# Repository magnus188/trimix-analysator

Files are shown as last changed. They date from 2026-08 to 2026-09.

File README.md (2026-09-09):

# Trimix Analyzer ESP32 Firmware

ESP32-P4/LVGL firmware for the Trimix Analyzer on the native-portrait Guition JC4880P443C_I_W (JC-ESP32P4-M3). It includes Wi-Fi, revision-specific HTTPS OTA, persistent settings/calibration, hardware sensor and power drivers, and a separate deterministic simulator. Physical firmware reports unavailable hardware instead of substituting simulated gas or battery readings.

**Prototype order status: HOLD.** Follow the [whole-system review](hardware/system-review/README.md) for current evidence and unresolved interfaces. No physical charging, thermal, sealing or reference-gas qualification has been completed. The accuracy targets of ±0.2 percentage points O2 and ±0.5 points He remain unproven. Charging is deliberately inhibited and J104 stays open until the cell, protection and temperature-sensing requirements are qualified.

## Project layout

The repository root is the main software workspace: firmware lives in `main/`,
with host tests in `tests/`, simulator support in `simulator/` and development
tools in `scripts/`. Mechanical and electronics files are grouped under the
[hardware overview](hardware/README.md): Fusion CAD is in `hardware/cad/`,
KiCad PCB projects are in `hardware/pcb/`, and Bambu Studio projects are in
`hardware/cad/rev04/3d-print/printing/bambu-studio/`.

## Quick Start with ESP-IDF

### Prerequisites
- [ESP-IDF v5.5.4](https://github.com/espressif/esp-idf/releases/tag/v5.5.4); `make setup-idf` installs the pinned environment
- Python 3.13
- Guition JC4880P443C_I_W: ESP32-P4 rev v1.3, 16 MB flash, 32 MB PSRAM, and ESP32-C6 coprocessor
- `g++`, CMake, pkg-config, and SDL2 development headers for full host validation

### Build and Upload
```bash
# See all common development commands
make help

# Run host-side validation
make test

# Install/check the exact ESP-IDF toolchain
make setup-idf
make doctor

# Identify whether the attached P4 is pre-v3 or v3+
make board-info PORT=/dev/cu.usbserial-110

# Build and flash; the port is required so the revision can be verified safely
make push PORT=/dev/cu.usbserial-110

# Build, flash, and monitor serial output
make push-monitor PORT=/dev/cu.usbserial-110

# Build and run the LVGL/SDL desktop simulator
make sim ZOOM=0.75
```

The first ESP32-P4 installation must be flashed over USB. An ESP32-S3 cannot
install this firmware through OTA because the chips and images are incompatible.

Run `make devices` to find likely serial ports. Firmware commands always source the pinned ESP-IDF v5.5.4 installation under `~/esp/v5.5.4/esp-idf`; an unrelated `idf.py` in `PATH` is never used. Override the installation location with `ESP_IDF_DIR=/path/to/esp-idf`.

The equivalent raw ESP-IDF commands remain available:

```bash
idf.py -B build/esp32p4-pre3 -D SDKCONFIG_DEFAULTS="sdkconfig.defaults;sdkconfig.defaults.esp32p4;sdkconfig.defaults.esp32p4.pre3" set-target esp32p4
idf.py -B build/esp32p4-pre3 build
idf.py -B build/esp32p4-pre3 -p /dev/cu.usbserial-110 flash monitor
```

## Browser Demo

The production LVGL interface can also run in a browser through WebAssembly. The browser build uses the same screens, calculator logic, and deterministic simulator services as the native SDL simulator; hardware sensors, WiFi, battery state, NVS, and OTA installation remain simulated.

### Build locally

Activate an [Emscripten SDK](https://emscripten.org/docs/getting_started/downloads.html), then run:

```bash
bash scripts/build_web_demo.sh
python3 -m http.server 8080 --directory web/build
```

Open `http://localhost:8080`. The generated site must be served over HTTP rather than opened directly from disk so the browser can load its WebAssembly module.

### Automatic GitHub Pages deployment

`.github/workflows/pages.yml` builds and deploys the demo after every push to `main`, and can also be run manually. Before the first deployment, select **GitHub Actions** under **Repository settings → Pages → Build and deployment → Source**. The project site will then be available at `https://magnus188.github.io/trimix-analysator/`.

### ESP-IDF Project Structure
```
├── CMakeLists.txt           # Main CMake configuration
├── sdkconfig.defaults       # ESP-IDF configuration defaults
├── main/                    # Main component source files
│   ├── main.cpp            # Application entry point and service startup
│   ├── services/           # WiFi, OTA, settings, battery, backlight
│   ├── sensors/            # Sensor abstraction and mock readings
│   ├── ui/                 # LVGL port, screens, styles, components
│   ├── idf_component.yml  # Component dependencies
│   └── CMakeLists.txt     # Component CMake file
├── tests/                  # Host-side C++ tests
├── scripts/                # Test and firmware size scripts
└── README.md               # This file
```

## Hardware Requirements

Use the [current electrical design](hardware/ANALYZER_DESIGN.md), [part qualification ledger](hardware/system-review/electrical/part-qualification.csv) and [main-board delivery index](hardware/system-review/electrical/main-final/README.md). These are prototype review files, not purchasing approval. Earlier enclosure/PCB snapshots preserve historical component choices.

### Controller and Display
- **ESP32-P4NRW32** application processor with 32 MB in-package PSRAM. Original pre-v3 boards are configured for their detected 16 MB flash; the v3 profile retains the 32 MB layout used by newer hardware.
- Onboard **ESP32-C6** WiFi 6/BLE coprocessor connected over SDIO.
- Native **480x800 MIPI-DSI IPS display** with ST7701 controller and GT911 capacitive touch.

### Power, Charging, and Battery
- **GCT USB4720-03-A** on a separate thin USB board, with TUSB320LAI CC detection and PI3USB9201 BC1.2 detection on the main board. USB-A-to-C and C-to-C behaviour remains subject to the documented source-current and startup tests.
- **BQ25895RTWR** 1S power-path charger, with TPS259470 overvoltage protection and TPS22950-Q1 input limiting. No USB-PD or high-voltage negotiation is provided; charging remains inhibited during commissioning.
- **Protected FMA FPML1S2P050C holder**, using its protected output. Holder/protection ratings, cell identity and NTC mounting require qualification.
- **TPS63020** configured for 5 V, with LM66100 host reverse isolation. Guition JP1 power entry remains a separate unresolved interface; do not power it through an unqualified harness.
- **TPS7A2030** regulated 3.0 V supply for the MD62.
- **LTC2954** hardware push-button shutdown plus firmware-managed normal shutdown.
- **MAX17048** 1S I2C fuel gauge.
- **2x 18650 cells in 1S2P**, owner-stated 3400 mAh each; no validated cell charge limits are inferred from capacity.
- **Normally-open momentary power button**; its final mechanical part and sealing remain unqualified.

### Sensors and Analog Front End
- Two **ADS122C04IPWR** 24-bit ADCs in TSSOP-16: U401 oxygen at 0x40 and U502 helium at 0x41. Initial profiles use 20 samples/s and the internal 2.048 V reference.
- Actual **BME280** breakout for humidity, temperature and pressure. A BMP280 cannot provide humidity.
- Retained **MD62 thermal-conductivity sensor** on regulated 3.0 V, with fixed matched bridge reference. Its helium response and compensation must be characterized with reference mixtures.
- **AO2 or R17JJ-CCR**, one installed oxygen sensor at a time. J401 and J402 have separate differential inputs; touchscreen selection and calibration identities persist independently.
- **ZE07-CO experimental module**, measuring CO rather than CO2. It is not a breathing-gas safety certification device. Its manufacturer excludes applications involving human safety; see the [CO review and manual](hardware/system-review/electrical/co-module-use-review.md). No undocumented recalibration commands are enabled. Fresh, valid chamber conditions and module warm-up are required before its reading is displayed.

### Wiring Notes
```
Signal/Rail       | Current hardware expectation
------------------|------------------------------------------------
External I2C      | GPIO28 SDA / GPIO29 SCL; managed 100 kHz sensor/power bus
Analog gas inputs | AO2/JJ differential paths and MD62 bridge into ADS122C04
HOST_3V3          | Supplied by Guition; external load margin remains unqualified
3.0 V rail        | MD62 through TPS7A2030; measure voltage at actual sensor leads
USB-C VBUS        | Protected/limited 5 V path to BQ25895
Display I2C       | GPIO7 SDA / GPIO8 SCL; separate touch/audio board bus
Onboard SD        | Slot 0: CLK43 CMD44 D0-3=39-42; LDO4 card supply
C6 SDIO           | Slot 1: CLK18 CMD19 D0-3=14-17; shared-controller arbitration
```

The [electrical/firmware/harness contract](hardware/system-review/electrical/interface-contract.md) defines logical contact mapping. The [owner photo and mechanical registration](hardware/system-review/integration-photo/README.md) place the Guition header and both USB sockets at the top and SD access on the left. Mated connector heights, cable routes and service access need their own clearance evidence. Display pins, timings and the ST7701S initialization table live in `main/board/`.

## Software Architecture

### Key Components

#### 1. Main Application (`main/main.cpp`)
- Persistent service startup
- Native display and screen initialization under the LVGL adapter lock
- Background service startup after the UI is ready

#### 2. LVGL Port (`main/ui/lvgl/lvgl_port.cpp`)
- Guition MIPI-DSI/ST7701S manual startup sequence
- Native GT911 touch registration
- Triple-buffered tear avoidance and LVGL adapter locking

#### 3. Sensor Interface (`main/sensors/sensor_interface.cpp/h`)
- Abstracted sensor reading functions
- Separate physical acquisition and deterministic simulator backends
- Persistent sensor selection and versioned calibration; stale, clipped and faulty samples are rejected

#### 4. Screen Management (`main/ui/screens/screen_manager.cpp/h`)
- LVGL-based UI screens
- Navigation between screens
- Settings, WiFi, update, and dive planner screens

#### 5. Services (`main/services/`)
- WiFi scanning/connection and saved credentials
- OTA update checks and firmware installation
- Settings, battery status, and backlight control
- Analysis history, persistent cylinder profiles, and export-ready gas label payloads

#### 6. Board Support
- In-tree Guition JC4880P443 display, backlight, and touch layer
- Separate pre-v3 and v3+ ESP32-P4 build profiles
- Native backlight, display, touch, and onboard ESP32-C6 integration

## Display Configuration

### ESP32-P4 Display
- **Panel**: 480x800 native portrait
- **Framework**: LVGL
- **Touch**: Capacitive (GT911)

### Screens

1. **Home Screen**
   - Main menu with navigation buttons
   - System status display
   - Version information

2. **Analyse Screen**
   - Gas analysis panel with physical and separately identified simulator sources
   - O2, He, experimental CO, environmental readings, stability, trend chart, planned depth, MOD, density, gas-use mode and averaged capture controls
   - Captures require stable samples and save an averaged analysis result to history
   - Stable averaged readings can update the selected cylinder profile and prepare an export-ready label payload

3. **Dive Planner Screen**
   - Gas planning calculator views
   - Partial-pressure top-up calculator for O2, helium, and air additions
   - Production calculator logic covered by host tests

4. **History Screen**
   - Captured analysis records with gas-use mode, mix fractions, CO, planned depth, MOD, density and advisory state; legacy CO2 fields remain distinct and are not relabelled as CO

5. **Cylinder Profiles Screen**
   - Persistent cylinder slots with selected cylinder, recheck state, stored mix, gas-use mode, planned depth, and label preview
   - Label text and CSV payloads are generated in firmware so later WiFi, QR, BLE, or phone handoff export can reuse the same data model

6. **Settings Screen**
   - Device settings navigation
   - Cylinder profiles, WiFi, software update, safety settings, calibration, and device information entrypoints

7. **WiFi Screen**
   - Network scanning, connection, password modal, and disconnect controls

8. **Software Update Screen**
   - GitHub release check and OTA install flow

9. **Calibrate Sensors Screen**
   - Guided known-gas oxygen and helium calibration with stability/fault checks and separate AO2/JJ/He records; failed saves retain the previous calibration

10. **Safety Settings Screen**
   - User-configured PPO2, density, and CO2 advisory limits used by Analyse

11. **Device Screen**
   - Device information and configuration controls

## Building and Flashing

### Prerequisites
- **ESP-IDF v5.5.4** installed with `make setup-idf`
- **ESP32-P4** toolchain and Python 3.13
- **Host validation tools**: `g++`, CMake, pkg-config, SDL2 development headers
- USB-C cable for programming

### Build Steps
```bash
# Inspect the attached chip and select the safe image family
make board-info PORT=/dev/cu.usbserial-110

# Run host tests
./scripts/run_tests.sh

# Build both incompatible P4 revision profiles
make build-all

# Validate firmware size against partitions.csv
make size-check P4_REV=pre3
make size-check P4_REV=v3

# Flash to device
make push PORT=/dev/cu.usbserial-110

# Monitor output
make monitor PORT=/dev/cu.usbserial-110
```

### Dependencies
The project uses ESP-IDF component manager for dependencies (defined in `main/idf_component.yml`):
- `lvgl/lvgl` 9.4.0 - Graphics library
- `espressif/esp_lcd_touch_gt911` 1.2.x - capacitive touch controller
- `espressif/esp_lvgl_adapter` 0.1.4 - task, input, and tear-safe display integration
- `espressif/esp_wifi_remote` 1.6.0 and `espressif/esp_hosted` 2.12.9 - onboard C6 networking

Dependencies are automatically downloaded during the build process.

## Sensor Hardware and Calibration Status

Physical firmware implements ADS122C04 acquisition, environmental and power monitoring, sensor selection and calibration persistence. Host tests exercise faults and state transitions; they do not establish actual sensor performance, wiring or charging behaviour. The simulator remains explicitly identified and does not substitute readings in physical firmware.

AO2, JJ-CCR and helium have separate records. Replacing a sensor requires calibration. Helium corrections must come from measured reference mixtures and held-out validation, including environmental and oxygen cross-effects. Historical/simulated CO2 fields remain distinct; this build has no installed CO2 measurement module. See the [software review](hardware/system-review/software/README.md).

## Performance Characteristics

### Display Pipeline
- **Panel**: native 480x800 RGB565 over two-lane MIPI-DSI
- **Tear avoidance**: three full panel framebuffers with partial LVGL rendering
- **LVGL refresh period**: 15 ms
- **Rotation**: none; pixels and touch coordinates stay in native portrait orientation

### Power Consumption
Whole-device active, idle, charging and hardware-off consumption remains unmeasured. Qualify backlight, radio, SD writes, heaters, converters and cable losses together; a display-only typical value is not a system budget. See the [bench equipment and test plan](hardware/system-review/lab-equipment.md).

## Differences from Original

### Enhanced Features
1. **480x800 portrait touch display**
2. **Capacitive touch**
3. **Tear-safe MIPI-DSI output** with no full-frame software rotation
4. **Software-defined sensor selection and calibration**
5. **Versioned OTA and persistent storage**; boot-time and power comparisons remain unmeasured

### Current Limitations
1. Physical fit, source protection, cell charging, thermal behaviour and gas accuracy remain unqualified; PCB order readiness is on hold.
2. Simulator streams support repeatable UI/logic tests; they are not physical measurement evidence.
3. Settings, calibration and recent history remain in NVS. [Optional onboard SD logging](hardware/system-review/software/sd-card/README.md) automatically records analysis/calibration sessions, raw samples and events. Device Settings provides status, safe eject and retry. Digital tests pass; actual card operation, power loss and simultaneous Wi-Fi use remain untested. Absent or faulty media leaves local analysis available.

## Development Notes

### Code Organization
- Sensor interface abstraction allows host tests and later hardware drivers.
- Modular screen design keeps LVGL screens separated by workflow.
- Services isolate WiFi, OTA, settings, battery, and backlight behavior.
- Board-level display and touch details are implemented in `main/board/guition_jc4880p443.c`.

### Testing Strategy
- `./scripts/run_tests.sh` runs static safety checks, production gas calculator tests, version consistency tests, and the host LVGL simulator smoke test when SDL2 is available.
- `./scripts/check_firmware_size.sh` validates the built app binary against the configured factory/OTA app partition.
- Hardware acceptance covers touch corners and drag axes, 100 navigation operations, a one-hour active UI/WiFi soak, an eight-hour idle soak, and two consecutive OTA upgrades.

## Troubleshooting

### Common Issues

1. **Display not working**
   - Verify the qualified 5 V power entry and source-current budget; follow the staged first-power procedure
   - Verify display cable connections
   - Confirm the PCB/module markings read `Guition JC4880P443` / `JC-ESP32P4-M3`
   - Confirm `make board-info` and the selected build profile agree

2. **Touch not responding**
   - Check the GT911 I2C bus on GPIO7 SDA / GPIO8 SCL
   - Confirm the board is physically mounted in native portrait orientation
   - Ensure proper grounding

3. **Sensors not reading**
   - Check I2C bus connections
   - Check device identities and bus errors in firmware diagnostics; use the documented I2C pin/address map
   - Check power supply to sensors

4. **Build errors**
   - Run `make doctor` and confirm ESP-IDF v5.5.4 with Python 3.13
   - Run `make clean`, then rebuild the correct P4 revision profile
   - Check that Git dependencies and `dependencies.lock` are available

### Debug Commands
```bash
# Read firmware diagnostics; no generic I2C-scan console is assumed
idf.py monitor

# Memory usage
idf.py size

# Real-time monitoring
idf.py monitor --decode-crashes
```

## Contributing

When adding new features:
1. Follow ESP-IDF coding standards
2. Keep display/touch changes inside the board-port boundary; do not add manual rotation
3. Add screen navigation in `main/ui/screens/screen_manager.cpp`
4. Test with both real and mock sensors
5. Update documentation

## License

Same as original Trimix Analyzer project.

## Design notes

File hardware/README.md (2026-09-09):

# Trimix hardware

The repository root is the ESP32 software project. Hardware work is grouped by
discipline here so the editable files, previews and print packages are easy to
find.

## Start here

| Area | Main entry point | Contents |
| --- | --- | --- |
| CAD | [cad/](cad/) | Fusion enclosure models, STEP exports, revision notes and image previews |
| 3D printing | [cad/rev04/3d-print/](cad/rev04/3d-print/) | A3 print release, STL files, checks and Bambu Studio projects |
| Bambu Studio | [cad/rev04/3d-print/printing/bambu-studio/](cad/rev04/3d-print/printing/bambu-studio/) | Ready-to-review PLA and PETG `.3mf` projects, grouped by part |
| PCB | [pcb/](pcb/) | Active KiCad projects, PCB integration assets, previews and verification |
| Main PCB | [pcb/analyzer/Trimix_Analyzer.kicad_pro](pcb/analyzer/Trimix_Analyzer.kicad_pro) | Current integrated analyzer schematic and board |
| USB PCB | [pcb/usb-input/Trimix_USB_Input.kicad_pro](pcb/usb-input/Trimix_USB_Input.kicad_pro) | USB input daughterboard |
| System review | [system-review/](system-review/) | Cross-discipline electrical, mechanical and firmware review evidence |

The preserved P1 power design is in
[`pcb/power/Trimix_Power.kicad_pro`](pcb/power/Trimix_Power.kicad_pro). The
obsolete EasyEDA-derived KiCad workspace is intentionally separated under
[`pcb/archive/deprecated-kicad-import/`](pcb/archive/deprecated-kicad-import/)
and should not be used as the current design.

## Supporting material

- [Analyzer design notes](ANALYZER_DESIGN.md)
- [Power design notes](POWER_DESIGN.md)
- [USB charging notes](USB_CHARGING.md)
- [Software calibration notes](SOFTWARE_CALIBRATION.md)
- [KiCad MCP setup](MCP_SETUP.md)

Generated verification records remain beside the work they describe. Preview
folders contain human-viewable images; source models and engineering evidence
stay in their project folders so they are not confused with presentation
exports.

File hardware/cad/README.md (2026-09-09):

# Trimix enclosure CAD

The latest enclosure source is [Revision 04](rev04/), with viewport images in
[`rev04/previews/`](rev04/previews/). The A3 printing package is kept with that
revision under [`rev04/3d-print/`](rev04/3d-print/). Open the prepared PLA or
PETG Bambu Studio projects from
[`rev04/3d-print/printing/bambu-studio/`](rev04/3d-print/printing/bambu-studio/).

The files in this directory below the overview are the earlier Revision 02
concept and remain available for design history.

## Revision 02 notes

**Status: Editable concept built in Fusion.** The official MCP connection was used with Fusion 2705.1.11. The current model has **19 component occurrences** (20 components including the root), **50 solid bodies** and **490 timeline items**. Its [Fusion model audit](verification/model-audit.json) reports healthy features, fully constrained sketches and **zero volumetric interferences** among the modelled component occurrences. Sampled removal checks pass with the sequence below. Physical fit, practical service access, gas sealing and flow performance remain to be validated.

The new Fusion design is saved as **`Trimix_Enclosure_A1 v2`**, in the **Trimix analyzer** Fusion folder. Cloud processing is complete and there are no unsaved changes, as recorded in [cloud-save.json](verification/cloud-save.json). The original `Casing v1` document remains unchanged. The model has millimetre user parameters and named components.

## Files

- [Native Fusion design](Trimix_Enclosure_A1.f3d): editable sketches, features, parameters and component assembly; archive integrity checked.
- [STEP assembly](Trimix_Enclosure_A1.step): neutral geometry with 50 exported solids; no parametric history.
- [Review drawings](Trimix_Enclosure_A1_Review.pdf): two A3 sheets containing actual Fusion front, rear, left, right, section and rear-open views. Both pages visually inspected; not to scale or manufacturing drawings.
- [Measurement checklist](MEASUREMENTS.md): published references and the measurements required for final mounts and seals.
- [View images](previews/): individual Fusion viewport exports. The rear-open view hides the outer cover and internal chamber lid; the centre section is at X = 0.

## Agreed arrangement

- The housing uses a provisional **180 mm height × 95 mm width × 60 mm depth**, with **3 mm walls**. Current side projections increase the complete model's bounding width to **107 mm**. Final dimensions depend on measured components and assembly clearance.
- Model coordinate convention: **X increases toward the viewer's left, Y points up, Z points rearward** when looking at the front. USB is on **+X** and the power button on **−X**. The front is **Z = 0**. The rear cover's nominal 3 mm allocation includes a **0.25 mm seating gap**; its current solid occupies **Z = 57.25–60 mm**, giving **2.75 mm** actual thickness.
- The front contains only the **4.3-inch portrait touchscreen** and its bezel. Use the agreed **69.41 × 117.01 mm** display envelope while confirming the hardware variant.
- The left side carries USB-C and the upper gas inlet. The right side carries the power button and upper gas exhaust. There is no external O₂ socket.
- One rear cover provides access to the battery, electronics and sensor assembly. **Six M3 screw and heat-set insert envelopes** are modelled; final boss bores, hardware selection and engagement lengths follow the chosen insert drawing and fit coupons.
- The upper sampling chamber is an independently enclosed, removable assembly, separated from the battery and electronics. Provide sealed wire feedthroughs and rear-accessible fasteners; final sealing details await component and material measurements.
- The model includes envelopes for the protected FMA two-cell holder and retained battery plug, an electronics carrier, cable-routing space and a supported, replaceable USB daughterboard mounting insert. The button centre is at **Y = 102 mm** to clear the adjacent boss; the USB daughterboard has a connector clearance slot.

## Assembly and service intent

The [service audit](verification/service-audit.json) checks temporary copies at discrete positions; it does not claim a continuous swept-volume or physical fit test. The tested sequence is:

1. Switch off and unplug USB. Remove the six rear screws and single cover, disconnect the RCY/BEC battery plug, release holder retention and withdraw the protected pack rearward.
2. For carrier/display service, disconnect side wiring and release the USB insert and button retainers. Move the USB assembly **3.1 mm inward**, then withdraw it through the rear. The panel button is removed **outward through the right side** after its internal nut and wiring are released; actual terminals must fit the measured hole.
3. Release the carrier screws and harnesses, then withdraw carrier and future PCB rearward. Remove the carrier before withdrawing the display. Keeping the button and USB assemblies installed obstructs these straight rearward paths in the present concept.
4. For chamber service, remove both external gas stubs, disconnect the sensor harness on the electronics side of the feedthrough and release the cartridge screws. The closed chamber, internal lid, seal and sensors then withdraw rearward together. Retained gas stubs obstruct that path.

All final paths were clear at the sampled positions after these prerequisites. A nominal **Ø4 × 50 mm** straight screwdriver shaft cleared the rear cover, carrier, cartridge and internal-lid screw access positions. The actual driver handle, connectors, retainers and cable bends still require physical checks. Wiring volumes reserve space; they do not model flexible harness behaviour.

The sampling path is a vented flow-through arrangement, entering at the upper left and exhausting at the upper right. The ZE07-CO clearance envelope starts at Z = 16 mm, leaving 1.5 mm beyond the top of the nominal 5 mm exhaust bore. A segmented air centreline around the AO2 neck was clear at points spaced no more than 1 mm apart. This does **not** prove a continuous 5 mm flow area, adequate mixing, response time or gas-tight seals. Keep a continuous open gas passage around the sensors and separate sample gas from the electrical compartment. Pressure-retaining tank or BCD adapters are outside this revision.

The external USB-C board supplies charging. Guition's own USB connector remains an internal service connection, accessed with the main power disconnected. The enclosure reserves a **64 × 108 mm** target for the future main PCB. The actual KiCad PCB has not been resized; its oversized placement preview is not the enclosure reference.

## Review before printing

The current solid model passes Fusion's geometry checks, including a static interference analysis with coincident faces excluded. The [parameter test](verification/parameter-regeneration.json) changed CaseWidth from 95 to 97 mm, confirmed healthy regeneration and restored 95 mm. These checks do not establish clearance for unmeasured real parts. Complete the [measurement checklist](MEASUREMENTS.md), then confirm practical rear removal, screwdriver reach, battery disconnection, cable bends and sample flow using the actual hardware.

The first planned print is a **PLA fit prototype for the Bambu H2D**, following review in Fusion. Final material, gas seals, thermal behaviour and weather sealing remain to be qualified. The connector's IP67 rating does not establish a rating for the complete enclosure.

## Editing and repeatable checks

Open the native file in Fusion and use **Modify → Change Parameters** for the provisional case dimensions, wall, display and port positions. Recheck component clearance after every dimensional change; changing the enclosure size does not automatically repack fixed internal envelopes. Named sketch and extrusion features remain available in the timeline. The retained `A-A centre section / X=0 / review only` analysis can be enabled in the browser.

The scripts use Autodesk's official local MCP endpoint at `http://127.0.0.1:27182/mcp`. `fusion_mcp.py` sends an explicitly chosen script into Fusion; it does not replace Fusion's geometry kernel. `fusion_audit.py`, `check_parameters.py` and `service_audit.py` record their results under `verification/`. The parameter check temporarily changes and restores width; the service check uses transient copies only.

`build_enclosure.py` is a staged construction record, not an automatic rebuild-on-open add-in. For a deliberately new design, its stages are `create_design`, `build_shell`, `build_chamber`, `build_hardware`, `refine_fit`, `finish_mechanics`, then `style_model`. Do not replay creation stages into the delivered document. The guarded `correct_front_reference` function records a one-time correction of the earlier build; current construction code already uses the corrected orientation.

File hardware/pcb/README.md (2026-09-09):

# Trimix PCB projects

Open the current designs from this directory:

- [Main analyzer project](analyzer/Trimix_Analyzer.kicad_pro)
- [USB input daughterboard](usb-input/Trimix_USB_Input.kicad_pro)
- [Preserved P1 power project](power/Trimix_Power.kicad_pro)

`integration/` contains the A3 placement, enclosure-fit exports, component
reference maps and their verification records. Project-specific preview source
files are under `analyzer/previews/` and `power/previews/`; rendered schematic
images and PDFs are under `verification/`.

The old EasyEDA migration is not an active design. It is retained only for
traceability in [archive/deprecated-kicad-import/](archive/deprecated-kicad-import/).

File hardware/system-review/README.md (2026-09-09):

# Trimix whole-system review

**Prototype order status: HOLD.** The main PCB is fully routed and its frozen native DRC reports zero violations, unconnected items and schematic-parity issues. This package records the corrections and reproducible digital evidence; it is not a fabrication release. Factory processes, power-entry and protection evidence, and actual component interfaces must close before ordering. Physical charging, temperature, sealing, module-fit and reference-gas tests have not been performed.

The approved A3 exterior and the original PCBFit baseline are preserved. Mechanical review copies are **Trimix_Enclosure_A3_SystemReview** and the newer **Trimix_Enclosure_A3_ConnectorReview**. Purchasing, showcase work and production printing remain paused.

**2026-09-08 integration update:** the owner supplied a rear photograph with device-up confirmed and measured **13.4 mm from front glass to bare header tips**. The photo locates the Guition header and both USB ports at the top and the onboard SD socket at the left. The [photo registration](integration-photo/README.md) and [saved/reopened ConnectorReview v3](mechanical/connector-review/README.md) supersede the old illustrative connector locations. Complete mate allocations expose interference with the housing, carrier and holder; several straight cable plugs also leave inadequate wire-bend space. Local correction candidates are unadopted, and card service remains unqualified. Earlier v11 clearances do not prove fit of these interfaces. [Optional SD logging](software/sd-card/README.md) is implemented and digitally verified, using the onboard socket. The [bench-equipment record](lab-equipment.md) includes the confirmed multimeter, scope, DC PSU, DL24/P, DLA and FNB58.

The current main board is the reviewed `0962ad86` revision. Its charger bootstrap/REGN and CO-converter feedback/output-capacitor paths were shortened, while all 29 previously checked power/monitor paths were preserved. The [scoped power-layout review](electrical/routing-candidate/sensitive-layout-refinement/root-final-review/README.md) and independent manufacturing checks pass. The former routed revision remains archived. Regulator stability, noise, startup and thermal performance still require physical evidence.

The preserved **SystemReview v11 baseline** is saved and its native archive reopens with the same geometry, parameters and assembly associations. It retains the approved 85 × 180 × 43 mm exterior and exact CNC Kitchen insert models. Two carrier through-openings clear the revised rear components with complete local 2 mm material borders. Its selected component, connector, service, gas and fastener allocations pass at 85 and 87 mm widths, with the intended 85 mm design restored. Both oxygen reference configurations pass their bounded checks. See the [v11 checkpoint](mechanical/final-local-checkpoint/final-handoff.json). The later ConnectorReview findings above take precedence for actual Guition mating and cable-space decisions.

Both P4 firmware builds pass, alongside **53 normal and 53 sanitized host tests**, 98 repository checks and 22 static-analysis units. The [current source-bound software receipt](software/sd-card/evidence/receipt.json) includes SD fault/race tests, shared card/C6 controller lifecycle checks and real LVGL navigation regressions. The current schematic/firmware contract passes 70 assertions. CO requires fresh chamber temperature/humidity within its documented range; invalid conditions clear its displayed value while oxygen and helium stay independent. The [CO verification](software/co-environment/README.md) records scoped tests and [manufacturer use restrictions](electrical/co-module-use-review.md). The CO module remains experimental and cannot certify breathing-gas safety.

Analysis and calibration record results, raw samples and events automatically. The result log identifies both applied O2 and He calibration revisions; concurrent saves cannot mislabel those converted values. Card faults remain separate from NVS settings/calibration. SD safe eject, failed unmounts, session transitions and shutdown preparation have digital coverage. Real card operation, simultaneous radio traffic, memory headroom, write-current peaks and abrupt-power-loss behavior remain physical checks.

The preserved v11 STEP is a reference export with a documented limitation (CAD09): body count, bounds and selected surface/section checks pass, but strict volume comparison and one underlying-plane correspondence do not establish full per-body equivalence. It also predates the photo-correct Guition details. Native Fusion checkpoints carry their own revision and source scope; the old STEP is not the new connector model.

Eight preserved v11 PLA/PETG diagnostic projects for four printed parts pass 50 slice checks. These are fit-study files, with support removal, printed dimensions, retention, sealing and temperature tests still pending. They do not qualify the later proposed carrier or harness changes. [The acceptance ledger](acceptance.csv) separates completed digital work from the **13 remaining order-blocking gates**; those gates are related and are not 13 demonstrated hardware failures.

## Read the package

| Area | Starting document / evidence |
|---|---|
| Check-by-check acceptance and unresolved gates | [Acceptance ledger](acceptance.csv) — scoped statuses and the remaining order gates |
| Electrical interface, pin audits and calculations | [Electrical review](electrical/README.md), [logical interface](electrical/interface-contract.md) |
| Exact purchasing and assembly populations | [Part qualification ledger](electrical/part-qualification.csv) — unresolved entries are not purchasing approval |
| USB source rules and legacy limitations | [Current USB-IF source review](electrical/usb-default-current-review/README.md), [limiter alternatives and rejected assumptions](electrical/usb-protection-research/transient-options/README.md) |
| Screen cable and power entry | [Matched harness review](electrical/host-harness-review/README.md), [Guition power and service isolation](electrical/host-power-review/README.md) |
| Fabrication and routing | [Manufacturing constraints](electrical/manufacturing-and-routing.md), [selected stackup](electrical/stackup-review.md), fresh ERC/DRC JSON files in `electrical/` |
| Current main-board files | [Routed main delivery index](electrical/main-final/README.md) — Gerbers, drills, factory/manual BOMs, factory-only stencil, marking guide and selected-hole process map; order HOLD |
| Independent manufacturing-file review | [Final CAM review](electrical/main-final-independent/final-0962ad86/README.md) — 44 geometry/connectivity, 20 assembly-ledger, 12 preservation and 50 process checks pass; supplier process approval remains pending |
| Frozen routed main PCB | [Independent final power and ground review](electrical/routing-candidate/sensitive-layout-refinement/root-final-review/README.md) — 29 prior power/monitor paths retained, 35 local routes connected, one connected In1 reference and no lost ground contacts; physical performance remains unqualified |
| Completed controls checkpoint | [Parent review of the controls and power paths](electrical/routing-candidate/complete-controls-root-review/README.md) — preserved intermediate source before final assembly cleanup |
| Earlier routing evidence | [USB voltage-monitor and input-trace review](electrical/routing-candidate/monitor-root-review/README.md), [charger interrupt and I²C pull-ups](electrical/routing-candidate/cap-signal-reconnect/pullup-swap/README.md) — preserved intermediate checkpoints |
| Latest protection-chip escape | [CC route, retained voltage-setting circuit and ground checks](electrical/routing-candidate/set-cc-root-proposal/vippo-cc/README.md), [independent mask/drill and rule controls](electrical/vippo-process-review/native-v3-independent/README.md) — scoped proof; combined routing and factory process acceptance remain open |
| Copper-path diagnostic | [Method and limits](electrical/current-path-review/README.md), [preserved prior-board native path inventory](electrical/routing-candidate/final-cleanup/root-review/current-paths/paths.csv) — geometry sensitivities, not equivalent resistance or current ratings |
| Supplier questions prepared for later use | [Unsent process-review request](electrical/supplier-review-request.md) — no supplier contacted or order placed |
| Mechanical model and measurements | [Current enclosure review](mechanical/README.md), [final saved assembly](mechanical/final-local-checkpoint/final-handoff.json), [measurement checklist](mechanical/MEASUREMENTS.md) — provisional models stay labelled |
| Oxygen setup and calibration | [Oxygen implementation and UI evidence](software/oxygen/README.md) |
| OTA, storage and maintenance | [OTA review](software/ota/README.md), [concurrent-save evidence](software/ota/storage-maintenance-race-verification.json) |
| Onboard SD recording and shared controller | [Use, implementation and limits](software/sd-card/README.md), [final source-bound receipt](software/sd-card/evidence/receipt.json), [independent receipt binding check](integration-photo/sd-software-binding-check.json) |
| Production sensor, power and environmental acquisition | [Firmware integration](software/README.md), [input isolation and charging standby](software/power/input-isolation/README.md), [legacy attachment endurance](software/power/input-isolation/legacy-endurance-review/README.md) |
| Combined tests and firmware builds | `verification/` — source hashes must match the reported build and check |
| Before wiring and first power | [Measurement and bring-up checklist](electrical/measurement-and-bringup.md), [available instruments](lab-equipment.md), [blank test record](test-record-template.csv) |
| Step-by-step bench sequence | [Draft first-power procedure](first-power.md) — all physical stages pending |
| Illustrated logical wiring and measurements | [Six-page interface packet](interface-packet.pdf) - reference only; actual mating views still need confirmation |
| Passive tolerance/noise and power-model limits | [Analogue study](electrical/analogue-simulation/README.md), [power-model probe](electrical/power-simulation/README.md) |

## Acceptance language

Every check uses one of these outcomes:

- **Passed digitally:** the identified calculation, source inspection, simulation, host test or native CAD/EDA check passed for its stated inputs and revision.
- **Correction required:** a demonstrated failure or unfinished implementation remains.
- **Missing evidence:** a needed dimension, rating, manufacturer datum or process qualification is not established.
- **Physical testing pending:** bench, fit, thermal, gas, electrical or sealing evidence is still required.

A host test can prove that a bus error is rejected; it cannot prove the physical bus signal integrity. An interference check can prove that the supplied solids do not overlap; it cannot prove that an unmeasured plug has the correct solid model. ERC and DRC alone do not establish charging safety or gas accuracy.

## Decisions retained

Only one oxygen sensor is installed. Both differential input paths remain, with the approved J401/J402 order. Touchscreen selection persists separately from calibration; GPIO52/J301.7 is unused. A new or replacement cell requires calibration. No analogue voltage is treated as a digital sensor identity and measurement never changes inputs automatically.

The MD62 remains on a regulated 3.0 V excitation supply. ADS122C04 measurement electronics replace the two older ADCs; the gas sensors are retained. The four-layer main board and separate thin GCT USB daughterboard remain the manufacturing targets. The humidity module must actually contain a BME280; a BMP280 cannot measure humidity. The installed ZE07 module measures CO, not CO₂.

Current firmware deliberately inhibits charging and leaves the hardware charge-arm connection J104 open. Exact cell charge limits, holder/plug ratings and the temperature-sensing arrangement must be qualified before a charging profile is enabled. This commissioning restriction is explicit; charging has not been certified by the software or schematic review.

The ±0.2 percentage-point oxygen and ±0.5-point helium values are **unproven targets**. Characterization must include independent reference mixtures, the reference instrument's uncertainty, oxygen cross-effects, environment, repeated measurements and battery versus USB operation. No correction coefficients or accuracy claims are copied from another analyzer.

## Attribution and scope

The project remains inspired by [captainigloo/Trimix-analyzer](https://github.com/captainigloo/Trimix-analyzer). Existing repository attribution and licensing are retained; this review makes no repository-wide licensing change. Bosch's BME280 driver is vendored with its BSD-3-Clause notice and pinned source manifest. Host parser tests use the same cJSON source as the local ESP-IDF dependency, retaining its licence; device firmware links ESP-IDF's JSON component.

Manufacturer documents, downloaded reference models and third-party CAD are evidence with their own terms, not newly relicensed project designs. Source links and hashes accompany the respective electrical, mechanical and software checks.

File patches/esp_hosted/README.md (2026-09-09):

# Guition shared SDMMC controller

This owned patch binds ESP-Hosted **2.12.9** (upstream commit
`09d9e983c9fc9d425d106177110165a89072533a`) to the board coordinator in
`main/board/guition_sdmmc.c`, for **ESP-IDF 5.5.4 / ESP32-P4**. Upgrading either
requires review. It adds no logger, format operation, automatic card-detect,
firmware flashing or electrical modification.

The four-file unified patch and `manifest.json` are the reviewed source. The
build includes `cmake/guition_hosted_sdmmc.cmake` after `project(...)`; that runs
`scripts/apply_hosted_sdmmc_patch.py`, verifies exact original hashes and hunk
contents, writes patched copies under the build directory, and replaces exactly
those four source entries in the Hosted target. All managed dependency files and
`dependencies.lock` remain unchanged. A changed upstream file, version, patch,
postimage or source inventory fails configuration. The build copy includes a
`patch-receipt.json` binding its inputs and outputs.

## Ownership and failure behavior

- Card slot 0 and C6 SDIO slot 1 share a single recursive FreeRTOS mutex. The
  complete FAT mount/unmount operation holds it because IDF's FAT helper invokes
  `sdmmc_host_init_slot()` directly, outside the configurable host callback table.
- Card transactions and configuration callbacks, all C6 SDIO port entry points,
  and C6 setup/teardown participate in the same arbitration. Ordinary card-side
  guard waits are limited to 250 ms; per-command card and C6 timeouts are 1000 ms.
  A full mount/probe or filesystem operation has no claimed wall-clock deadline.
  Calls belong on the storage worker, not the UI or acquisition task.
- C6 interrupt waiting polls the native semaphore without blocking while holding
  the board mutex, releases it, and sleeps one tick between unsuccessful polls.
  Transport teardown acquires the board mutex before cancelling workers. C6
  lifetime initialization and teardown wait for the current guarded operation;
  cancellation cannot strand a mutex owned by an in-flight port callback.
- Each successful slot initialization is released with `sdmmc_host_deinit_slot`.
  Forceful global deinit is permitted only for a failed initialization with zero
  registered slots and no other owner. Initializing a slot twice is rejected.
  IDF 5.5.4's deinit-slot call does not check whether that particular slot ever
  completed initialization, so the coordinator checks the actual slot count.
- An incomplete slot init while the other slot remains active is quarantined
  until the last active owner exits. Card absence after successful slot init
  releases only slot 0 and LDO4 and permits an ordinary retry while C6 stays alive.
- FATFS ignores the host-deinit callback's return and frees the card anyway.
  The coordinator separately records the consumed card pointer and any remaining
  controller/LDO ownership. A cleanup error is reported, the freed card is never
  presented as mounted, and uncertain residual hardware is quarantined until
  restart. A failed LDO release retains its handle, preventing double acquisition.
  `guition_sdmmc_is_mounted()` addresses pointer lifetime; it is not a successful
  eject signal. Only a successful unmount permits the service to report eject.
- C6 card-init retry frees the prior IDF DMA buffer; failed port allocation
  releases its acquired slot. SDIO function-probe errors propagate instead of
  aborting the P4. Failed bus setup cleans up its resources and propagates through
  `setup_transport` / `esp_hosted_init`. Unrelated upstream allocation assertions
  outside this lifecycle path are not claimed to have been removed.

API: `guition_sdmmc_mount(path, &config, &card)`,
`guition_sdmmc_unmount(path, card)`, and `guition_sdmmc_is_mounted(card)`.
The caller closes every file and stops filesystem users before unmount. Mount
rejects `format_if_mount_failed=true`. Slot 0 uses four data lines, a 20 MHz
maximum, 3.3 V default IO and no DDR/UHS request. Hosted runtime slot/pins/width
must match the board binding; Hosted must not acquire the card's LDO4.

## Board source and power review

The manufacturer [model-selection page](https://www.guition.com/model-selection)
links the [JC4880P443C_I_W development archive](https://pan.jczn1688.com/directlink/1/HMI%20display/JC4880P443C_I_W.zip).
The retained `hardware/system-review/integration-photo/guition-manufacturer/JC4880P443_V1.0.pdf`
has SHA256 `c7edaaff96dba106fc53f924db0c3054b0b2b81ec9807d59787778cc6fa48c05`.
Its single schematic sheet was visually checked at the U3 pin map and J1 TF-card
block. The adjacent source receipt records verified archive shards and ZIP CRC;
it does not claim a complete archive download.

| Item | Source-supported binding |
|---|---|
| Card CLK / CMD | U3 GPIO43 / GPIO44 |
| Card DATA0 / DATA1 / DATA2 / DATA3 | U3 GPIO39 / GPIO40 / GPIO41 / GPIO42 |
| Card supply | `ESP_LDO_VO4` through R4=0R and Q1 AO3401 to `TF_VCC` / J1 VDD |
| Q1 gate | R13=10k to GND; GPIO45 link R10 marked NC, as is parallel R7 |
| External pull-ups | R2 10k array: CMD, CLK, D2, D3; R11/R12 5.1k: D0/D1, to TF_VCC |
| Card detect / write protect | No connected controller signal shown; J1 K/pin9 unconnected |
| C6 SDIO | Existing resolved firmware: slot 1, CLK18/CMD19, D0-3=14-17, four-bit; checked at runtime |

The carrier schematic represents the P4/C6 assembly as U3 and does not expose
its internal C6 SDIO connections. Thus the retained running-target configuration
and Hosted P4 defaults support the C6 binding; this sheet alone does not prove
those internal connections. The display driver already owns **LDO3** for DSI;
the card owns **LDO4**, and Hosted LDO control is forbidden in this patch.
GPIO45 is not used as a power switch because its gate link is shown unfitted.
No weak internal pull-up is substituted for the schematic's external network.

Actual-unit PCB revision, resistor population, continuity, LDO4 voltage under
load, card behavior, concurrent radio traffic, removal and power-loss behavior
still require hardware testing. This source review is not a claim that hotplug,
abrupt removal or operation during brownout preserves files.

## Primary software sources and validation

The [IDF 5.5.4 SDMMC host documentation](https://docs.espressif.com/projects/esp-idf/en/v5.5.4/esp32p4/api-reference/peripherals/sdmmc_host.html)
documents that controller initialization/configuration is not thread-safe with
transactions, per-slot deinit preserves another active slot, and global deinit
immediately removes the whole controller. The exact installed source was also
read, including `esp_driver_sdmmc/src/sdmmc_host.c` and
`fatfs/vfs/vfs_fat_sdmmc.c`.

The bundled official `examples/host_sdcard_with_hosted` establishes the two-slot
arrangement. Its IDF6 dummy-init workaround is not used here: it does not provide
this project's full lifecycle/transaction arbitration or failed-mount ownership.

Run the focused suite with:

```sh
python3 tests/test_guition_sdmmc.py
```

It compiles the actual coordinator and the exact patched interrupt-wait function
against IDF-shaped fault fixtures with real pthread mutexes. The 23 tests cover
both owner orders, absent-card retries, partial slot init, rejected duplicates,
power failures, ignored callback errors with freed cards, concurrent transfers,
bounded contention, cancellable interrupt waiting, exact patch reproducibility
and fail-closed rejection. These are host tests; real ESP-IDF target builds and
hardware validation remain separately reported by the integration owner.

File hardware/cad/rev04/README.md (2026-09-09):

# Trimix enclosure A3 - Revision 04

The separate [PrintReview build package](3d-print/) contains the later PLA
fit/PETG enclosure refinements, print projects and community assembly
documentation. This page and the files beside it describe the preserved A3 v3
baseline. Use the PrintReview package's own verification record for its revised
geometry and exports.

**Status: editable engineering concept completed and reviewed; physical manufacture remains unqualified.** A3 has a **180 H x 85 W x 43 D mm body**, with measured display and occupied battery-holder envelopes retained. The complete modeled assembly is **180 H x 97 W x 43 D mm**, including the opposed gas-fitting references. Native Fusion and STEP are saved, and the STEP geometry-import verification passed. Revision 03/A2 remains a separate preserved design.

This trades depth for a taller, wider body. Against A2's 125 H x 75 W x 56 D mm body, A3 is **23.2% thinner** but has **25.3% more body bounding-box volume** (657.9 versus 525.0 cm³). These are exterior rectangular-envelope comparisons, not material or internal free-space volumes. The measured factory display casing occupies **52.9% of the 180 x 85 mm front rectangle**; that percentage is not the illuminated screen area.

The front contains the portrait 4.3-inch screen in its existing factory casing with the factory back removed. The owner measured 116.8 H x 69.3 W x 13.7 D mm. The protected FMA 1S2P holder with two 3400 mAh cells measures 80.4 H x 42 W x 20.35 D mm. Battery and future PCB sit side by side behind the display. The sample cartridge occupies the taller upper region; the power button is on the viewer-left side, USB-C is on the bottom, and opposed gas fittings connect at the upper sides. Coordinates remain +X viewer-left, +Y up, +Z rearward.

The PCB strip at the current supplied datums is **30 x 99 mm**, X 50.4..80.4, Y 21..120, Z 20.5..22.1, before an upper button notch and lower USB-service notch. It is a mechanical allocation, not a revised KiCad layout.

[USB provenance](components/GCT_USB4720_A3_PROVENANCE.md) and [sensor provenance](components/SENSOR_PROVENANCE.md) identify the manufacturer drawing references and unmeasured allowances. The GCT connector and sensor models are editable reconstructions, not authenticated manufacturer CAD.

## Delivered files and actual checks

- [Editable native Fusion archive](Trimix_Enclosure_A3.f3d), also saved as `Trimix_Enclosure_A3` in the Trimix analyzer cloud folder.
- [STEP assembly](Trimix_Enclosure_A3.step); geometry-import verification is discussed below.
- [Three-sheet A3 review PDF](Trimix_Enclosure_A3_Review.pdf), with front/rear/side views, rear-open view, two actual sections and an exploded assembly.
- [Parts list](PARTS.csv) and [assembly selection sets](verification/parts-and-assemblies.json). Generic hardware references are not supplier order codes.

| Check | Actual result and scope | Evidence |
| --- | --- | --- |
| Native model | 102 placed solid bodies, 66 occurrences, 44 component definitions and 1,006 timeline entries. All inspected entities healthy and all sketches fully constrained; zero positive-volume overlaps above 0.00001 mm³. | [Model audit](verification/model-audit.json) |
| Printed-part connectivity | Eight explicitly selected printed components each contain one solid. | [Model audit](verification/model-audit.json) |
| Individual hardware | 14 screw and 14 insert occurrences, with 28 parameter-driven mounting joints. | [Hardware and selected sections](verification/selected-wall-fastener-checks.json) |
| Selected wall sections | 20 deliberate material segments meet their selected nominal 2 mm gate, checked at intervals of at most 0.1 mm. This is not a global wall-thickness result. | [Selected checks](verification/selected-wall-fastener-checks.json) |
| Fastener engagement and approach | All 14 nominal screw/insert pairs pass the selected geometric checks; all 14 nominal driver shafts clear with the stated assembly-removal prerequisites. | [Fastener checks](verification/selected-wall-fastener-checks.json), [driver checks](verification/service-drivers.json) |
| Service motion | All eight specified service paths clear exact BRep tests at poses no more than 1 mm apart. Cables, hands and latch operation are unmodeled. | [Final eight-path report](verification/service-paths-cover-disconnect-battery-carrier-chamber-retainers-display-usb.json) |
| Gas passage | Continuous 5 mm cylinders and corner spheres clear all placed solids; the selected channel-dimension checks pass. This is geometric clearance, not a gas-flow or sensor-response result. | [Gas clearance](verification/gas-clearance-paths.json) |
| Parameter regeneration | Independent width 87 mm, height 182 mm and depth 45 mm trials pass health/static-clearance and fixed-part dimension checks. Original geometry restored. | [Regeneration](verification/parameter-regeneration.json) |
| Views and PDF | Nine actual Fusion view images approved; all three A3 PDF pages rendered and visually inspected without layout defects. | [View QA](verification/viewQA.json), [PDF QA](verification/PDFQA.json) |
| Saved exports | Native archive and STEP saved; native display units are mm. STEP import passes with 102 solids, 66 occurrences and exact overall bounds. Matching High-accuracy mass-property calculations differ by 0.007434 mm³ (about 0.024 ppm); the original 1 ppm acceptance tolerance is unchanged. Temporary import closed and native geometry, poses and timeline preserved. | [Export record](verification/final-delivery-export.json), [STEP import](verification/step-roundtrip.json) |

The independent reduction trials explain the retained size; they do not prove a globally smallest enclosure. At width 84 mm, the current 5 mm gas route fails despite no static part overlap. At depth 42 mm, the manifold intersects its lid and the rear gas return is truncated. At height 179 mm, the manifold intersects the housing and upper display retainer. All trial expressions and occurrence poses were restored. See [size-reduction diagnostics](verification/size-reduction-trials.json).

## Verified service sequence

The single rear cover gives access to the assembly. Remove its four screws, then withdraw it rearward (+Z) and unplug the battery mate rearward. The following paths were checked separately:

| Assembly | Prerequisites and tested motion |
| --- | --- |
| Protected battery pack | Cover off and battery unplugged; withdraw holder, cells and attached plug rearward. PCB and chamber stay installed. |
| PCB and carrier | Cover off, battery unplugged and wiring freed; remove the two shared screws and withdraw rearward. Battery stays installed. |
| Closed sample cartridge | Cover off, battery unplugged, chamber harness freed and both external gas fittings removed; withdraw rearward. Keep the lid, four lid screws and sensors attached. Housing rails and rear-cover capture replace separate chamber-mount screws. |
| Display retainers and display | Cover off and battery unplugged; remove two retainer screws and withdraw retainers rearward. Disconnect the display and remove the complete factory-cased module forward (-Z). Actual frame capture/contact remains unqualified. |
| USB cartridge | Cover/key off, battery removed and USB loom disconnected; translate inward +Y by 2.5 mm, then rearward +Z. Its two screws and inserts remain attached, while PCB and carrier stay installed. |

The four chamber-lid screws and two USB-cartridge screws have nominal driver access with their cartridges removed to the bench. Flexible wiring, latch release, hand clearance, real driver handles and safe grip still require physical confirmation. Exploded poses illustrate component ownership and are not removal trajectories.

## Offline PCB evidence

[pcb-strip-assessment.json](verification/pcb-strip-assessment.json) and [per-footprint clearances](verification/pcb-footprint-clearances.csv) read the existing KiCad preview without changing it. All 119 footprints have front courtyards; 115 are FIT. FIT courtyard area totals 1,469.64 mm², or 49.5% of the 30 x 99 mm gross strip. Conservative bounding rectangles total 1,573.98 mm².

An artificial same-side rectangle packing trial placed all 119 footprints, including DNP pads, with a 1 mm outer-edge allowance and an extra 0.5 mm gap between courtyard bounding rectangles. It also fit the current 21.4 x 17 mm upper notch, 5.8 x 4.2 mm lower USB notch, and two radius 3.6 mm mount reservations represented by conservative 7.2 mm squares. Each result includes explicit coordinates plus an independent overlap/boundary check. The 31 x 100 and 34 x 100 comparison trials are also recorded.

This is **conditional packaging evidence only**. The preview has no copper tracks or zones and no encoded mechanical keepouts. Ten footprints are placeholders: D101, J101, J102, J103, J301, J402, J801, J802, L101, SW101. J301's 34.12 x 6.18 mm courtyard rectangle must run along the strip rather than across its 30 mm width. Actual connector mating, wire bends, button/USB intrusion, switching-loop layout, thermal copper and routing/DRC remain open. DNP components still require their PCB pads unless the electrical design is deliberately changed.

## Native verification tools

Root-controlled Fusion execution uses these explicit entry points; importing them does not execute a check:

- [audit_a3.py](scripts/audit_a3.py): `audit()` defaults to 14 expected screws. It recomputes, checks feature/sketch health, records actual body instances/poses/bounds and hardware, and analyzes transient positive-volume interference. Hidden bodies and repeated definitions are included. No persistent geometry is created or moved.
- [verification_a3.py](scripts/verification_a3.py): `audit_paths()` checks eight candidate service routes using exact transformed BRep copies at intervals no greater than 1 mm; `audit_drivers()` checks actual fastener axes with nominal M2/M3 shafts. `regeneration_test()` explicitly varies dimensions independently by +2 mm and restores all original expressions in `finally`.
- [gas_checks_a3.py](scripts/gas_checks_a3.py): `audit()` checks continuous 5 mm cylinders and corner spheres against every placed solid, including fitting walls, alongside named source-expression channel checks. `size_reduction_trials()` independently diagnoses 84 mm width, 42 mm depth and 179 mm height, with native health, static intersections, gas clearance and fixed-part dimensions, then restores parameters and occurrence poses. These trials do not select a final size or qualify physical gas performance.
- [review_a3.py](scripts/review_a3.py): `style()`, `export_views()` and `exploded()` create actual Fusion view exports. AA cuts the battery/display stack; BB cuts the top manifold at GasY. Visibility, camera, temporary analyses and exploded poses are restored; pose recovery metadata is retained.
- [make_review_pdf.py](scripts/make_review_pdf.py): requires eight real view PNGs and reads only Revision 04 evidence. Creates three A3 landscape review sheets. Missing views are fatal. Final rendering and visual inspection are required before delivery.

The original candidate intent remains in [service-plan.json](verification/service-plan.json); the completed eight-path report linked above is authoritative. Earlier failed bridge-call files and intermediate checks are diagnostic history. A checkpoint or file emitted during a failed/rolled-back Fusion stage does not establish model completion.

## Boundaries before physical manufacture

The 14 independently positioned screws are four rear-cover, two carrier/PCB, two display-retainer, two USB board/adapter, and four independent chamber-lid screws. The closed chamber uses housing rails and rear-cover capture; it has no separate housing mounting screws. Its four lid screws remain with it during withdrawal. The USB cartridge retains its own board/adapter hardware during service.

The actual factory display capture lip/contact/preload, hardware choices, connector latches, flexible wiring, gas seals, representative sample renewal, pressure control, thermal response and final material remain unqualified. Selected wall-section checks must name their locations and assumptions; they are not a global minimum-thickness certificate. The AO2 M16 x 1 connection requires a measured seal that is gas-tight with hand tightening. Keep the atmospheric sampling requirement separate from the sensor's maximum pressure limits.

Native Fusion, STEP and review sheets are concept deliverables; print-ready release requires physical measurements and prototype testing. See [MEASUREMENTS.md](MEASUREMENTS.md).

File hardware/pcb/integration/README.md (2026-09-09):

# A3 PCB integration — work in progress

The USB daughterboard is routed and passes the saved-board KiCad checks. The main board is a **mechanical placement candidate, still unrouted**. The enclosure showcase, animation and presentation work are paused while PCB design and insertion take priority. These files are engineering drafts, not a fabrication release.

| Item | Current state |
|---|---|
| Main board | Four copper layers, 1.60 mm nominal thickness; 119 original electrical footprints, 12 test pads and two mounting holes. Components on F.Cu face the enclosure rear. No tracks or copper planes yet. |
| USB daughterboard | Two copper layers, 0.60 mm nominal thickness, 16 × 15.72 mm overall outline; four footprints, 15 track segments, four routing vias and two ground fills. |
| Test pads | Twelve bare Ø1 mm pads added to the main schematic; original pin/net assignments preserved and the test-point ERC report contains zero violations. |
| Manufacturing and physical fit | Pending actual parts, mating connectors, cables, solder protrusion, fabrication stack and prototype checks. |

The authoritative editable sources are [the main KiCad project](../analyzer/Trimix_Analyzer.kicad_pro) and [the USB KiCad project](../usb-input/Trimix_USB_Input.kicad_pro). The separate [USB board](../usb-input/Trimix_USB_Input.kicad_pcb) uses a GCT USB4720-03-A receptacle, independent 5.1 kΩ CC resistors and a two-wire power output. USB data pins are unused; this board does not negotiate USB Power Delivery.

## Software calibration electronics

U401 and U502 now use ADS122C04IPWR TSSOP-16 converters at 0x40 and 0x41. The fixed matched RN501 array removes the trimmer while retaining all three gas sensors and the approved connectors. Eleven nearby passives were rearranged to fit the larger ADCs and their local decoupling. The board outline, mounting holes, four layers and enclosure are unchanged. Read [the calibration guide](../../SOFTWARE_CALIBRATION.md) for touchscreen use and the still-pending gas characterization. Fusion PCBFit v6 has the current native PCB import. Showcase and print preparation remain paused.

## Board markings and component key

All **135 PCB references** now have visible silkscreen labels at 1.0 mm text height and 0.15 mm stroke. The main board has 31 references on the front and 100 on the reverse; the USB board has three on the front and one on the reverse. Back labels read normally when viewed from the back. Mounting-hole labels sit outside a conservative Ø5 mm screw-head reserve. Keep these clearances when routing or moving parts.

The [component key](reference/COMPONENT_REFERENCE.md) explains each marking, its value/type, circuit section, printed side and assembly status; the matching [CSV](reference/COMPONENT_REFERENCE.csv) includes exact source values and footprint assignments. For example, **R101 = resistor, 5.23 kΩ, 1%**. DNP means to leave the position empty. The [front assembly map](reference/main-assembly.svg) identifies all 131 main-board references from the component side; its digital labels are separate from manufacturing silkscreen. Actual silk plots: main [front](reference/main-front.svg) / [back](reference/main-back.svg), USB [front](reference/usb-front.svg) / [back](reference/usb-back.svg).

The [original marking-only verification](verification/markings/final-verification.json) is historical and predates the connector swap. The [software-calibration verification](verification/software-calibration/final-verification.json) binds the current ADC upgrade, board, maps, native Fusion model and STEP exports. U401/U502 are ADS122C04IPWR; RN501 replaces RV501/R502/R503. Other electrical connections and connector placements are preserved. STEP/Fusion contains the updated placements and carrier, but does not display silkscreen. Main DRC remains at 39 fabrication findings / 295 unconnected items / zero parity issues; USB is unchanged at zero / zero / zero. Main routing remains unfinished.

## Coax above AO2 — current placement

J402 is now above J401, matching the requested connector order. Their physical centres are respectively **(4.45, 16.60)** and **(4.90, 27.00) mm** in local KiCad coordinates; J401 pin 1 is at (4.90, 24.46). The narrow upper PCB section was widened from 8.60 to **8.90 mm**, retaining at least 0.50 mm copper-to-edge clearance. Four nearby passives were repositioned. The [independent board audit](verification/connector-swap/final-independent-audit.md) checks the exact six allowed placements, outline changes, all 365 pin/net assignments and all 133 values.

The enclosure exterior and both screw datums are preserved. The carrier has a [2 mm dropped floor and end walls](verification/connector-swap/carrier-applied.json) beneath the new coax opening. This maintains one connected carrier without obstructing the button or changing the removal prerequisites. Actual mated elbow and J401 plug geometry remains an open fit check; putting J402 above J401 is not itself a cable-clearance approval.

## Placement and enclosure evidence

The [current independent placement audit](verification/software-calibration/pcb-scope-audit.json) records zero native courtyard collisions, zero courtyards outside the outline, and zero copper-edge clearances below 0.50 mm. The [initial placement receipt](verification/main-final-verification.json) remains historical. Schematic parity and the latest full ERC are zero. Main DRC remains open: **295 unconnected items and 39 fabrication-rule findings**—15 package-pad gaps of 0.15 mm against the current 0.20 mm rule, and 24 thermal drills of 0.20 mm against the current 0.30 mm minimum. Rules have not been relaxed. The [main placement STEP](exports/Trimix_Analyzer_A3_Placement.step) is a mechanical preview, with provisional purchased-part models.

The USB footprint lands and 0.60 ± 0.10 mm board requirement follow the [GCT Rev B drawing](https://gct.co/files/drawings/usb4720.pdf). The implemented Edge.Cuts and registration are recorded in [usb-layout.json](verification/usb-layout.json). Its front clearance chamfer remains provisional. The initial layout receipt deliberately retains its earlier board hash and “pending DRC” status; [usb-final-verification.json](verification/usb-final-verification.json) binds the pre-marking board, sources and STEP hashes and records the later independent check: **zero DRC violations, zero unconnected items and zero schematic parity issues**, under the project’s recorded check configuration. The marking receipt above binds the current annotation revision.

The [USB STEP](exports/Trimix_USB_Input.step) includes the board, copper and resistor models. It has no exact connector or cable body. The current Fusion comparison reports no intersections with printed parts, housing or fasteners in its candidate set; 26 intersections remain against the earlier simplified connector shell/rear insulator. **Fit to the actual connector is unresolved.** This is not an overall Fusion fit pass.

The main outline and two Ø2.30 mm mounting holes come from the A3 carrier datums, including the button and USB-service notches. [Mechanical interface notes](verification/MECHANICAL_INTERFACE.md) provide the original coordinate transform and height limits. The earlier [11 lead-clearance windows](verification/carrier-relief-applied.json) and local 0.60 mm rim extension to X81.20 mm have been revised around J401/J402 as described above. The updated carrier remains one solid and its [current native static comparison](verification/software-calibration/carrier-static.json) reports zero intersections and zero calculation errors. The [current full main-board comparison](verification/software-calibration/pcb-static.json) also reports zero intersections and calculation errors. The earlier enclosure print-release meshes and slicer projects have not been regenerated for this changed carrier. Actual solder protrusion and stiffness remain separate checks; the earlier full main-board interference report predates this relief.

The [current native service check](verification/software-calibration/service-check.json) verifies a continuous 28 mm rearward extraction of the board and carrier, plus access for both Ø5 × 50 mm driver shafts. This requires the rear cover off, battery disconnected, all PCB harnesses detached and both carrier screws removed; the battery holder stays installed. The check covers rigid modeled parts, not real wire bends, solder, hands or fit tolerances. [Current revision checks](verification/software-calibration/final-verification.json) collect the evidence and remaining gates. [Earlier integration checks](verification/final-checks.json) retain their historical hashes and geometry. The [native Fusion archive](exports/Trimix_Enclosure_A3_PCBFit.f3d) and [STEP assembly](exports/Trimix_Enclosure_A3_PCBFit.step) are saved; their hashes and archive integrity were checked. The [delivery receipt](verification/fusion-delivery.json) records a successful native reopen with 834 solids and zero total-volume difference, plus review of the [actual rear assembly view](exports/PCB-in-enclosure-rear.png). These checks preserve the modeled-geometry limits above.

The [test-point receipt](verification/testpoints-verification.json) maps TP1001–TP1012 to ground, input/battery/system/host rails, enable, I²C and sensor measurement nodes. Probe access must be preserved during routing. The [footprint review](verification/footprint-review.md) and [TI DSJ receipt](verification/u201-ti-dsj-footprint.json) separate manufacturer dimensions from remaining package, stencil and assembly decisions.

Before fabrication, complete main routing and its power-loop, thermal and analogue review; confirm purchased inductors and mating connectors; reconcile trustworthy connector geometry; and check actual wires, solder tails, strain relief, service access and source/cable behavior on a prototype. Zero DRC does not establish charging performance or physical fit.

The JJ-CCR cable has a **90-degree plug at J402**. Preserve room to connect and remove the AO2 harness at J401 with that plug installed. Their native cached footprint courtyards are now 1.75 mm apart, and the existing scaled SMA display model does not represent the real SMB connector or either mated cable. This interface remains an open fit check: obtain the exact board connector and elbow dimensions, then model their installed volumes and insertion/removal paths before locking the placement. Rotating the symmetric vertical J402 footprint alone does not establish a safe cable exit direction. See the [J402 cable review](verification/j402-cable-review.md).

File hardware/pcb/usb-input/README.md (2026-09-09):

# USB input daughterboard — A3 USB6 + ESD

Open `Trimix_USB_Input.kicad_pro`. The board is electrically routed and its
schematic matches the PCB, but **it is not ready to order**. The unchanged
GCT recommended lands conflict with the general fabrication constraints:
0.10/0.15 mm copper-to-edge gaps and two 0.15 mm PTH annular rings.
No copper-edge exception hides these findings.

- J901: GCT USB4720-03-A; fixed mid-mount pose and original Rev B lands/cutout.
- U901: TPD4E05U06DQAR, four signal ESD clamps. Real PCB copper bridges
  1–10, 2–9, 4–7 and 5–6; the chip's NC lands contain no internal connection.
- D901: TPD1E10B06DYAR, VBUS ESD suppression. It is not a 5.5 V voltage clamp.
- J902: six soldered wires to main PCB J101, using identical pin numbers:
  **1 VBUS, 2 GND, 3 CC1, 4 CC2, 5 D+, 6 D−**.

R901/R902 are removed. The main-board TUSB320LAI provides the independent
CC pull-downs; a disconnected six-wire harness cannot provide attachment.
Data wiring is for BC1.2 source detection, not a high-speed USB data port.

The two-layer board is nominally 16 × 15.72 × 0.60 mm, with finished thickness
0.60 ±0.10 mm. Manufacturing needs a supplier/assembler-approved solution
for the original connector's land/cutout and tolerance requirements, and the
fine USON pads. Do not shrink purchased parts, erase the findings, or silently
relax the fabrication rules. Reflow assembly, connector support, harness fit,
source changes, hot plug, temperature and assembled-port ESD remain physical
checks. Sealing is not established by the connector's component rating.

See `../../system-review/electrical/usb-final/README.md` for sources, exact
routing/height contracts, integration instructions and diagnostic exports.
The local STEP models for U901/D901 are unchanged KiCad nominal package
illustrations, not exact manufacturer CAD; maximum purchased envelopes are
recorded separately. Existing model licenses and exceptions are retained.

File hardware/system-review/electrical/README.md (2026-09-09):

# Electrical review — prototype engineering record

The complete routed main board passes native KiCad with **zero violations, zero unconnected items and zero schematic mismatches**. The reviewed source has been promoted into the canonical project, preserving the previous draft. Its [final delivery index](main-final/README.md) and [frozen review bundle](routing-candidate/sensitive-layout-refinement/frozen-local-bundle/review/geometry-handoff-manifest.json) bind board SHA256 `0962ad86f9834ce71b6439d0f95db603753801153490e78f387a88521e582788`. Independent final CAM and source-bound enclosure disposition are recorded with the promotion receipt. **It is not ready to order.**

`hardware/pcb/analyzer/` is the promoted routed project. Root-level netlist, qualification, pinmap, height and native reports now match it. `main-final/` contains the final CAM, assembly lists, factory paste subset and selected-hole manufacturing plan. `hardware/pcb/usb-input/` is the separately frozen daughterboard and was not changed by promotion. Immutable baselines and rejected trials are retained.

## Corrections implemented

- U401/U502 remain ADS122C04IPWR; AO2, JJ-CCR and MD62 sensors are unchanged. Helium is physically **HE_REF minus HE_SENSE**. R506/R507 are680ohm0.1%; He acquisition profile2/O2profile1.
- U501/U702 now TPS7A2030PDBVR with correct pin4NC. C503/C706 are DNP. Selected effective capacitance exceeds the documented0.47uF output requirement under the stated engineering deratings.
- U302 LM66100 supplies HOST_5V and blocks reverse current toward our VOUT_5V converter. This does not establish every Guition USB/battery backfeed path.
- BQ D+/D- remain NC, preventing its autonomous HVDCP/MAXC voltage negotiation. TUSB320LAI detects USB-C advertisements; PI3USB9201 detects legacy BC1.2. Daughterboard harness is six conductors. The old discrete Rd R901/R902 have been removed because the sink controller supplies dead-battery Rd. The USB board has dedicated four-line signal ESD and VBUS ESD parts; their clamping does not establish survival of every downstream surge.
- The unsupported4.02k BQ ILIM extrapolation was rejected: BQ specifies no ILIM operation below500mA. U114 is the exact **TPS22950CQDDCRQ1** leaded Q1 variant, with sourced19.1k0.1% default resistor and qualified parallel1k branch. Its manufacturer34/50/66mA table applies at19.2k; the19.1k substitution has only a typical-formula estimate, with current corners and transient overshoot still unmeasured. BQ R103300ohm is a supported-range backup.
- U112 authorization latch plus two series FETs require a fresh host edge after VBUS/CC/fault reset. U113 senses the protected input independently of firmware. Q112 exposes actual latch reset through shared GPIO49/CHG_INT_N. GPIO52 stays unused.
- U115 TPS259470ARPWR adds sustained-input OVLO with fixed precision resistors. Its AUXOFF, not FLT, clears permission. Physical fast-surge/ESD/inrush qualification remains open; the6V-absolute downstream limiter is not proven to survive every pulse.
- Critical capacitor packages/banks and inductors were replaced with exact sourced parts and maximum-height envelopes. Optional SW101 was replaced by local QON service pad TP1014, referenced to TP1001 GND; the external power button is unchanged. J402 is the specified Amphenol142138 SMB jack with a manufacturer-drawing reconstruction; original connector poses remain fixed.

## Evidence and limits

The final source-validation audit has 217 passing pin-function/net assertions and bounded calculations. `main-drc.json` and the frozen bundle's `review/drc.json` identify the complete routing check. The revised-part audit adds 205 identity/conservation checks and rejects four metadata faults. The routing audit passes 13 checks, all 300 routed-via interfaces have explicit dispositions, and the final native graph has 195 physical pad-connectivity partitions. Independent CAM passed 126 checks (44 export/connectivity, 20 assembly-ledger, 12 refinement-preservation and 50 process checks), retaining one external supplier-qualification hold. Native and CAM checks do not establish physical qualification. The STEP and 153-row component-height table must be read together; generic or absent visual models are not purchased-part maximum envelopes.

The current raw ERC report contains one reviewed U302 ST-to-ground error. TI explicitly permits grounding the unused LM66100 status output. The [exact exception guard](erc-reviewed-exceptions/README.md) checks the specific pins, complete schematic wiring, native netlist, library identities and captured report without changing pin types or suppressing the error class. Its result means one reviewed raw error and no unexpected violations, not a clean raw report or a fabrication release. Refresh this guard alongside the final native ERC export.

Earlier placement snapshots are historical. The final bundle includes the inward keyed J301, rotated output-capacitor bank and CO inductor, true 0402 components, compact backside OVP cluster, local service pads and corrected C708 ground dogbone. The promotion manifest binds the final source-matched CAD disposition. In1 remains reserved for continuous ground; local In2 signal routing and anchored ground partitions have separate review evidence. The published JLC04161H-3313 stackup is bound in the native board; the actual fabrication quote remains pending.

The root `hardware/system-review/` report reconciles firmware and CAD checks. Analogue sweeps, capacitor curves, USB protection research, and failed/successful simulation receipts are separate evidence, not physical measurements. The TPS22950 PSpice experiment failed its light-load sanity check; it is **not** a device-performance pass.

## Before ordering

Confirm the fabricator stackup and factory assembly process for exact lands, three signal VIPPO sites and thermal vias; validate actual mechanical mates and harness envelopes; establish cell identity/current/temperature limits and real pack NTC; qualify unresolved protection/current/transient assumptions. Stock, price and assembly quotations are not confirmed. No physical test is marked performed. The bundle includes 169-reference assembly and marking maps, with exact purchasing, factory, manual, DNP and PCB-feature lists. The full-board paste export is diagnostic; the factory subset stencil still needs assembler approval.

The optional internal charger LED D101/R106 was removed to make room for C108, a supplementary 4.7 µF local SYS bypass. Both qualified C104/C105 bulk capacitors remain. TP1013 exposes charger STAT on the rear copper; remove the board for probing. TP1014 retains manual QON wake/reset access close to U101. The local service pads use the assembly reference drawing where dense silk would be unreadable. Probe fit and physical fault recovery remain pending. See `charger-bypass-change.json` and `qon-service-change.json`.

C101 now uses an actual KEMET C0603C105K4RACTU 1 µF, 16 V, X7R 0603 part. This retains the nominal 1 µF BQ input-bypass function while allowing a short front-copper connection beside U101. C102 remains the selected 22 µF 1210 PMID bulk capacitor. The local source change is recorded in `local-input-cap-change.json`; `routing-candidate/local-cap-loop-witnesses.json` records explicit copper paths, without claiming measured ripple, inductance or thermal performance. `standard-part-selections.json` is refreshed from the exported schematic by `refresh_selection_snapshot.py`, so removed LED/switch parts and the superseded Harwin host header do not remain in the active selection snapshot.

The final local refinement places real factory 0402 C103 (TDK C1005X7R1H473K050BE, 47 nF/50 V) close to BTST/SW, and factory 0805 C107 (TDK C2012X5R1A476M125AC, 47 µF/10 V) close to REGN. CO feedback and output-capacitor paths are shorter, with a direct front-copper output-capacitor return. The CO switch route and upper feedback leg grew modestly; the [source-bound comparison](routing-candidate/sensitive-layout-refinement/frozen-local-bundle/README.md) states these tradeoffs. Only the explicitly checked bootstrap branch uses rear switch-net copper; the BQ load-current SW path stays on F.Cu. R504 is a manual rear component, installed before the carrier. Factory/manual counts are 27/118; 141 printed references and 28 assembly-only locators cover all 169 features. Capacitor effective values are curve-based estimates, and startup, ripple, noise and thermal behavior remain unmeasured.

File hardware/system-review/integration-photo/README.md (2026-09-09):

# Guition photo registration and wiring review

The owner supplied [IMG_0571.png](IMG_0571.png) on 2026-09-08 and explicitly confirmed that **up in the image is the top of the assembled device**. This is a rear view. The image is archived byte-for-byte, with SHA-256 `867f6220b1a6c27a98dfface8bef685d9fbe23a2dc351ea9fc20ac13ca1dda81`. Its stored raster is 4032 × 3024 with EXIF orientation 6; the correctly oriented view is 3024 × 4032. Apply EXIF orientation before interpreting pixel positions.

The photograph establishes:

- The two-row expansion header runs horizontally near the top. The visible near-row end labels are 1 at the left and 25 at the right. Verify the actual mating-side contact map by continuity before wiring.
- Two USB-C receptacles are immediately below that header.
- The onboard card socket is on the left edge, above the large ESP32 module. Its access is sideways in the PCB plane, rather than directly rearward.
- The main display flex is near the bottom. Keep its fold and exposed contacts out of retention and cable-clamping zones.

The owner will fit a fresh card. No extra SD socket is required on the main PCB. Rear-cover access is preferred; the actual ejection stroke and hand clearance still need checking. If the side wall blocks withdrawal, use the approved display-release sequence before considering an extender or a new exterior opening. No card has been mounted, formatted or written by this review.

## Position estimates, not manufacturing measurements

[registration.json](registration.json) registers the four mounting-ear hole centres using the **60 × 108 mm** grid in Guition's [manufacturer drawing](guition-manufacturer/JC4880P443C_I_W_Y.pdf), centred on the owner's **69.3 × 116.8 mm** retained casing dimensions. The manufacturer's outer dimensions are 69.41 × 117.01 mm; the hole grid is retained without scaling. Local X points right and local Y points up. The current display datum adds X=7.85 and Y=5.2 mm in Fusion; Z increases rearward.

The independent first-to-last header cross-check maps to **30.572 mm**, versus twelve 2.54 mm intervals = **30.48 mm**, a **0.30% disagreement**. This improves the earlier casing-edge estimate, which disagreed by 5.6% and is retained in [the superseded initial record](registration-initial-edge-estimate.json). Raised header/USB surfaces are not in the mounting-hole plane, and hole-centre picking is approximate. Use actual 2.54 mm pitch, provisional centres with ±2 mm starting XY allowances, and separate height/plug allowances. The ±2 mm value is an engineering allowance, not a calibrated uncertainty bound. Do not scale purchased parts to make the photograph fit.

The owner subsequently measured **13.4 mm from the front glass surface to the tall header tips**. This anchors the bare header's rearward extent. It does not establish the plugged-in socket height, PCB Z or exposed post length individually; use the actual front-glass plane as the datum. USB mouth Z, plug seating, card mechanism, ejection travel and cable bend radii remain reference interfaces. A generic microSD body is 11 × 15 × 1 mm according to the [Kingston dimensional specification](https://www.kingston.com/datasheets/sdcit2_en.pdf); this establishes a card-format reference, not the socket geometry or a selected purchased card.

The [candidate IDSD socket review](../electrical/host-harness-review/README.md) gives a 9.144–9.525 mm body height and permitted insertion of 5.588–6.223 mm. Conditional on the Guition posts and seating being compatible, the socket cap therefore reaches **16.321–17.337 mm from the glass** (`13.4 + socket height − insertion`). The CAD check starts with a **17.8 mm engineering allowance**, before separate cable bend and withdrawal space. This does not establish an exact remote termination or a guaranteed maximum. The pin-7-blocked main-board connector must not be copied onto the Guition end, where pin 7 is physically present. The proposed single-ended cable still needs a qualified remote termination.

## Complete cable routes to check

The preserved v11 CAD has local connector and feedthrough allowances, but no complete verified loom. Its earlier clearance results do not qualify the newly located Guition connectors.

| Harness | Required path and service provision | Outstanding evidence |
|---|---|---|
| Chamber → J501/J601/J701 | Sealed chamber pigtail, dry-side disconnects, strain relief, continuous route clear of the heater and gas passages | Actual insulation/bundle diameter, potting or gland, seal compatibility, mated plugs and bends; MD62 four physical leads to three interface nets |
| Oxygen → J401 or J402 | Selected cell's dry-body cable outside the wet chamber; maintain approved J402-above-J401 arrangement | Actual straight AO2 plug and JJ elbow sweep, cable exit and disconnect travel |
| J301 → Guition JP1 | Complete ribbon/loom around a PCB edge to the now-confirmed top header, correct pin-one orientation, service slack and retained strain relief | Connector post/mate geometry, free cable length, bend/twist envelope and qualified host power entry |
| Onboard SD | Installed card plus sideways ejection and grip corridor | Socket stroke/type and clearance with housing, battery and display retainers |

The [chamber termination record](chamber-wiring.md) resolves the MD62 four-lead/three-wire mapping from its manufacturer manual. The existing main PCB edge-to-divider gap is only about 0.2 mm and is **not a wiring passage**. A top-edge cable detour must be modeled and checked; a straight forward drop through FR4/carrier is invalid. The nominal four-inch Samtec assembly length is not its free ribbon length. The common Guition 5 V power/backfeed hold remains unchanged by this mechanical photograph.

The [current J301 pose check](current-host-pose.json) reads the unchanged routed board directly: its 180° orientation makes the standard ribbon exit inward (−X), while all 26 logical nets retain the earlier pin contract. The older electrical audit's outward-exit pose and pad coordinates are historical. [Cable termination candidates](connector-candidates.md) document the actual JST mates and the tall Harwin J501 housing; their complete installed heights and wire exits must be included before claiming fit.

## Current CAD result

The separate **Trimix_Enclosure_A3_ConnectorReview** now contains the [photo-correct native model](../mechanical/connector-review/Trimix_Enclosure_A3_ConnectorReview_Photo.f3d). The observed header, two USB ports and SD socket replace the earlier illustrative connector arrangement. The bare tips are 13.4 mm from the front-glass datum; their world Z is 13.8 mm because the glass datum is Z0.4 mm. PCB thickness/height, small component details and actual plug identities remain labelled references.

The [initial full-interface checks](../mechanical/connector-review/interface-checks.json) find intersections between the conditional Guition socket allocation and the housing, carrier and battery holder. A local carrier brace with a 0.8 mm PCB offset clears the expanded socket allowance and retains the checked screw engagement, but that isolated result does not close the housing, other plugs or ribbon routing. It is **not adopted**. The proposed round-wire route with a 0.5 mm MD62 shift also conflicts with the lid and is rejected. Straight cable-space probes alone do not verify a physical bend.

The direct SD withdrawal allocation intersects the housing and the retained factory-frame reference. Releasing the display forward is a service option to investigate, but access through the actual retained frame and the card's eject/grip mechanism remain unmeasured. No external card opening or frame cutting is specified.

The intended wet-side wiring remains a sealed eleven-conductor chamber pigtail with dry-side disconnects. The closure shape, complete finite-radius route, insulation sizes, sensor-lead joints and seal process require further design and qualification. The [smaller-connector addendum](connector-candidates-j501-addendum.md) identifies a Samtec IDSS side-exit factory cable and compatible shorter-post header, recovering about 4.7 mm of nominal stack compared with the straight Harwin pair. This is an unadopted candidate requiring exact ordering, hole tolerances, length, current and full fit checks; the purchasing BOM and routed board are unchanged. The local clearance studies are evidence for the next correction, not a complete assembled-harness pass.

This is an engineering input and correction record. Physical fit, sealing, cable handling and powered SD tests remain pending. The immediate additional screen measurement is the exposed metal post length above its black plastic base; the existing glass-to-tip value cannot determine usable socket insertion.

## Primary manufacturer files

Guition's [model list](https://www.guition.com/model-selection) links its [development archive](https://pan.jczn1688.com/directlink/1/HMI%20display/JC4880P443C_I_W.zip). The [retrieval receipt](guition-manufacturer/source-receipt.json) records two checksum-verified archive shards and CRC-verified extraction of the schematic, dimensional drawing and specification. The remaining archive was not downloaded; no vendor program was executed. These manufacturer documents retain their original attribution and terms.

The primary schematic confirms card CLK43, CMD44, data0–3 on GPIO39–42 and LDO4 power through the fitted R4/Q1 path. It does not establish a fitted GPIO45 power-control link or card-detect signal. Actual unit revision/population and electrical measurements remain separate checks.

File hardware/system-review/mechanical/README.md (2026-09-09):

# SystemReview mechanical checkpoints

**Latest integration checkpoint: [ConnectorReview v3](connector-review/README.md), saved and reopened using the owner's rear photograph and 13.4 mm glass-to-bare-header-tip measurement.** The [current native model](connector-review/interface-checkpoint/Trimix_Enclosure_A3_ConnectorReview_Interfaces.f3d) places the Guition expansion header, USB ports and onboard SD socket at their observed locations. It preserves the approved exterior and the routed PCB. Complete mated cables expose new conflicts; [the interface checks](connector-review/interface-checks.json) are explicitly failures requiring correction. The smaller carrier, holder and wire-route alternatives remain unadopted studies. The [independent parent check](connector-review/interface-checkpoint/root-review.json) verifies the saved inputs, native reopen receipt, dimensions and inspected views; it does not close the fit failures.

The v11 evidence below remains a preserved baseline. Its local plug allocations and sampled service paths do **not** prove fit or card access for the newly located Guition interfaces. No current complete-harness fit or manufacturing release is claimed.

## Preserved v11 baseline

**SystemReview v11** contains the matched routed **0962** main PCB, the frozen USB board, exact supplier M2/M3 insert models and the corrected carrier. The native archive has been saved and reopened with exact geometry, poses, parameters, grounding, source metadata and visibility agreement. The approved enclosure remains **85 × 180 × 43 mm**. Earlier native versions and every unrelated FlowGrid document are preserved.

This is a completed **bounded digital mechanical review**, not a PCB order, production-print, charging or gas-analysis release. The remaining physical interfaces are collected in [MEASUREMENTS.md](MEASUREMENTS.md). Canonical electrical adoption and firmware evidence are tracked separately by the project-level review.

## Current files and evidence

- [Editable native Fusion archive](final-local-checkpoint/Trimix_Enclosure_A3_SystemReview_FinalLocal.f3d), [saved/reopened summary](final-local-checkpoint/summary.json) and [native reopen receipt](final-local-checkpoint/native-reopen.json).
- [STEP assembly](final-local-checkpoint/Trimix_Enclosure_A3_SystemReview_FinalLocal.step). All 2,543 physical solids and overall bounds match after unit-aware reimport. The unchanged strict 1 ppm summed-volume check fails at **1.434 ppm / 0.4408211 mm³**, and one manifold analytic-plane lookup remains unmatched. Five-definition checks produced 53,998 bidirectional samples (maximum 0.0039418 mm) and 27 selected sections (maximum bound difference 0.0006552 mm), below the existing 0.02 mm diagnostic. This is limited geometric evidence, **not strict per-body equivalence**. The [raw checks and final disposition](final-local-checkpoint/step-disposition.json) retain both exceptions; the native archive remains authoritative.
- [Immutable input map](final-local-checkpoint/bound-inputs-map.json): 353 source/evidence bindings, including frozen PCB/USB contracts, adopted insert sources, native checks, actual inspection images and diagnostic slices. Mutable inputs are snapshotted; declared large frozen dependencies retain their exact hashes.
- [W85 complete checks](verification/final-local-checks/width-tests/W85/trial-summary.json), [W87 actual regeneration/restoration](verification/final-local-checks/width-tests/W87/trial-summary.json), [JJ alternative](verification/final-local-checks/oxygen-variants/summary.json) and [PCB-thickness driver probes](verification/final-local-checks/thickness-drivers/board-thickness-drivers.json).
- Actual Fusion views: [assembled](verification/final-local-checks/views/assembled.png), [rear access](verification/final-local-checks/views/rear-access.png), [carrier apertures](verification/final-local-checks/views/carrier-apertures.png). No parts were moved for these views.

The full native design contains **2,546 placed solids**, including three hidden JJ configuration references, with **1,211 timeline entries**. The default AO2 physical assembly contains **2,543 solids**; the main PCB accounts for 2,347. STEP is intended to contain the default physical assembly; the editable F3D retains both oxygen configuration references.

## Board, height and registration contract

The integrated board SHA-256 is `0962ad86f9834ce71b6439d0f95db603753801153490e78f387a88521e582788`; its input STEP is `81eef0182d0d3bbaaf1a433cf43dce3e70f975c9ccd6d8d94bd196aa00c99014`. The [frozen handoff](../electrical/routing-candidate/sensitive-layout-refinement/frozen-local-bundle/review/geometry-handoff-manifest.json) binds matching native PCB, netlist, DRC, STEP and height contracts. The [active import contract](verification/incoming-boards.json) also identifies the unchanged final USB source.

All **169 references** are accounted for. There are **145 purchasable populated references**, six DNPs and 18 board features. The 153-row height contract contains **147 fitted maximum/allocation envelopes** plus six DNP rows: the extra two fitted allocations are J101/J102 wire and solder space, not purchased components. The remaining 16 references are 14 bare testpads and two mounting holes. There are 16 fitted B.Cu envelopes. U110, L201 and L701 have no populated STEP visual model; their complete source-bound maximum envelopes are included in the native fit checks. The contract distinguishes manufacturer maxima, conservative footprint-derived bounds and provisional cable/solder allocations.

The imported main assembly and all its descendants remain rigid. At 85 mm enclosure width, KiCad coordinates map to **Fusion X = 50.4 + x, Y = 120 − y**. The native joint follows `PcbX = CaseWidth − PcbWidth − 4.6 mm`, while purchased board dimensions and hole spacing remain fixed. Width changes move the board, mounts, carrier cuts, fastener axes and review allocations together. The USB stays centred on its own datum.

The detailed main layer sum is **1.5642 mm**, including the 1.4942 mm dielectric substrate. Finished-board allocation remains **1.60 mm**, with a fixed back seat at Z20.5. Centre registration gives ordinary copper faces Z20.5179/Z22.0821 and the exporter component references Z20.4679/Z22.1321. These are explicit exporter datums, not measured mask or solder thickness. No purchased geometry is scaled. The tests include finished thickness **1.44, 1.60 and 1.76 mm**, front-side maxima raised 0.16 mm, and four additional nominal Ø5 × 50 mm driver probes at the thickness extremes.

**The historical R301/J301 mating-box failure is closed on this matched source.** R301 is now at PCB (11.95, 71.15), and the full approved J301 mating box, inward ribbon allowance and at least 6.1 mm axial unmate allocation clear in the final native checks. J301 is rotated 180° with its pin assignment preserved, so its standard ribbon exit points inward. The 35 × 5.5 × 12.5 mm mating allocation and cable/turn band remain engineering allowances; actual socket, ribbon, strain relief and bend radius require measurement.

## Carrier and exact inserts

The existing lower carrier opening remains at PCB x−0.4–20.525/y83.7–99.7. Two source-bound **through-openings** accommodate the final rear components:

| Opening | PCB x, mm | PCB y, mm |
|---|---:|---:|
| Shared C103/C107 | 11.955–15.795 | 77.805–81.595 |
| R504 | 16.425–20.075 | 46.925–49.075 |

[Exact transient/native comparison](verification/final-local-carrier/native-applied.json) shows one connected carrier, unchanged outer bounds, complete 2 mm material rings, unchanged mounting support and a minimum 2.105 mm web to the old lower opening. The two cuts remove 44.8022 mm³; the resulting native volume is 4048.146574862508 mm³. All other 2,542 physical solids were compared by bilateral native Boolean difference and remained unchanged. No alternate rear resistor opening was cut.

The adopted common M2 insert is **CNC Kitchen TC-M2x3.0**, EAN4262391010013, ten pieces: 3 mm length, Ø3.6 crest, supplier Ø3.2 pilot guidance and selected 2 mm material beyond the crest. Seven pilots retain blind floors; the upper PCB and lower display supports are through-open. The lower PCB pilot is deliberately classified as **partly open and relieved**: at least 4.299 mm full-diameter depth precedes a tiny peripheral remainder of the front-opening wall. It satisfies the 4 mm depth guidance without cutting the exterior. The failed stricter full-exit control is retained in [its disposition](verification/short-m2-implementation/lower-pilot-exit-disposition.json).

The four rear inserts are **CNC Kitchen VORON M3×5×4**, EAN4262391010051: exact unscaled supplier geometry, Ø4.4 × 5 mm pilots and Ø9 mm bosses, preserving a complete selected 2 mm annulus beyond the crest. The M3 × 8 reference screws and existing tip relief remain unchanged; actual selected tip clearance is at least 0.3476 mm.

The audit explicitly classifies **14 intentional heat-set pilot interfaces** and four additional generic smooth M3 shaft/modelled female-thread representation pairs. Each classification is tied to exact occurrence, source, axial and radial bounds; unrelated interference remains a failure. The supplier M2 internal bore is visual/reference geometry. Neither that bore nor the smooth M3 shafts prove usable thread engagement, class, torque or retention. Both PCB screws have 3 mm nominal axial insert overlap throughout the tested finished-thickness range; the minimum measured screw-tip clearance is 0.835794 mm at W85 and 0.738157 mm at W87. Install and qualify inserts on coupons before a full enclosure, with the display removed.

## Service, gas and USB

Final native actual-body and maximum-allocation checks show **zero unrelated intersections**. Both endpoint suites pass all **eight sampled service paths**, 14 nominal drivers, selected material sections, aligned PCB/mount axes and the continuous Ø5 gas-probe route. JJ installed and cartridge-removal reference checks pass at both widths. W87 restores every parameter, pose, physical solid and protected-document state exactly. These are finite geometry checks, not global minimum-wall, continuous swept-volume, hand-access, wire-bend or physical-strength proofs.

The display is released from the rear and removed through the front. After rear-cover removal and battery disconnection, release the upper retainer, move it **+Z6 mm, −X1.5 mm, then rearward**, remove the lower retainer and lift the display in −Z. This staged route clears at both widths; the old straight W87 route remains a recorded failure. The pack, carrier, USB and closed sampling cartridge use their documented rear-service prerequisites. Gas fittings and required electrical connections must first be disconnected.

GCT USB4720-03-A follows the [manufacturer Rev B drawing](https://gct.co/files/drawings/usb4720.pdf): port centre Z26, nominal 0.60 mm board at Z24.9–25.5, nose Y0.61 and shell stakes Y3.56/7.56. The support ledge and capture pad were corrected to those datums; purchased pads and the exterior port were not moved to accommodate a placeholder. The native model is a drawing reconstruction, not manufacturer STEP. Internal plastic, bends, gasket section and actual seating remain limitations. P09/P10 are correctly named printed bezel/retaining bridge. The six-conductor harness, its solder height, strain relief and the 5.7 mm board-to-bridge gap need real measurements. The daughterboard's GCT fabrication/tolerance hold remains open; an uncompressed gasket establishes no enclosure IP rating.

The AO2 body is unchanged and unscaled. Hidden JJ references use the owner's relative −2 mm diameter/+2 mm length measurement, with the same-thread shoulder/nose and mated cable still provisional. Gas fittings, sensor support, feedthroughs, lid/return seals, actual flow distribution, leak rate and sensing response require physical qualification. J402 remains the fixed Amphenol142138 drawing-derived reconstruction; its actual mated elbow is not yet measured.

## Diagnostic printing and historical records

The final P01 housing, P03 carrier, P06 USB frame and P07 chamber passed **eight H2D PLA/PETG diagnostic projects and 50 checks**, with four closed connected meshes, open carrier apertures and no generated support in the protected gas passages. All layer sheets were inspected; [the receipt](verification/final-local-slices/verification-receipt.json) binds 120 files. P03's native 5.50 mm height quantizes to a 5.40 mm deposited top at 0.20 mm layers. Actual printing, support removal, finish and fit are still pending. No print job or new production release was sent. PLA is dry-fit only; PETG remains an unqualified material/process target. Material-family metadata is not a mass or FEA qualification.

Earlier evidence is preserved as history, not the current source: [placement v2](placement-checkpoint-v2/), [M2 v9](short-m2-checkpoint/), [exact-insert v10](exact-inserts-checkpoint/) and [the previous README](verification/final-local-checks/README-before-final.md). These include the old R301 allocation failure, unsynchronised width-datum clash, generic insert geometry and obsolete overlap/tip figures. Use the final v11 evidence above for current dimensions and geometry.

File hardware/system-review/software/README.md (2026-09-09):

# Integrated firmware review

This review replaces physical-build placeholder acquisition with real, managed device drivers. A physical build reports unavailable readings when devices are absent or faulty. Demonstration readings remain confined to simulator builds.

## Acquisition and configuration

`main/hardware_contract.h` supplies the actual GPIO and I²C assignments used by the drivers. `scripts/verify_system_contract.py` reconciles it with the current KiCad netlist and Guition logical pin map. The connector pitch, mating view and harness geometry still need physical confirmation.

A single mutex-managed 100 kHz I²C bus on GPIO28/29 serves the MAX17048, BQ25895, both ADS122C04s, BME280, TUSB320LAI and PI3USB9201. It is separate from the display's touch-controller bus. Transactions have timeouts; repeated failures request a controller reset and remain failures. A physical short is not cleared by declaring the bus healthy.

The production acquisition state machine is also compiled into host tests. It owns measurement sequencing, per-input timestamps, settling, warm-up, selection-generation changes and heater control. Separate oxygen and helium ADC faults remain distinguishable. Invalid excitation latches heating off until restart; oxygen can continue only when its independently checked bias is valid. Stopping acquisition prevents later worker activity from re-enabling heating or CO translation.

Both ADCs use their approved **20 SPS internal conversion setting**, the internal 2.048 V reference and disabled IDACs. This is not a promise of 20 delivered samples per channel per second: sequential channel diagnostics and the conservative 100 ms settling interval reduce delivered rate. Oxygen uses gain8 with the PGA; helium gain1 with bypass. Diagnostics have separate configurations. Register readback, stale-data clearing, bounded conversion waits and clipping rejection operate on the actual driver path.

The current oxygen profile is revision1. Helium profile revision2 accounts for its reviewed analogue-path changes. Calibration is isolated by AO2/JJ-CCR/helium identity and profile revision. Intact older records remain inactive when the transfer function changes; a fresh save advances the existing record revision. The finite journal retains current/previous records, not an unlimited calibration archive. Export characterization logs and reference information for longer-term history.

The known-air screen displays both raw inputs and currently requires manual confirmation: qualified response bounds for connector advice are missing. It does not claim automatic cell identification. The runtime warm-up and electrical stability thresholds are provisional and must be characterized on the installed modules.

## Real power and environmental data

The MAX17048 driver validates its device family, word order, fractional SOC, signed rate and plausible voltage. No fabricated percentage replaces a failed read. Charger status distinguishes current faults from latched history, and configuration is read back after writes and reset evidence. OTA installation requires fresh battery/charger evidence with reserve; USB cable presence alone does not establish enough input power.

The BQ25895 commissioning profile inhibits charge/OTG and autonomous input negotiation and starts with a 100 mA software input ceiling. A separate source policy may raise that register ceiling to 1400 mA only after consistent Type-C 1.5/3 A advertisement or a fresh BC1.2 CDP/DCP result. SDP, proprietary and unknown sources keep the default ceiling; no USB enumeration is provided. These register values do not guarantee delivered current: the independent upstream limiter and BQ hardware ILIM can impose lower limits. This policy does not enable cell charging. J104 remains open pending exact cell, holder and NTC qualification.

GPIO50/J301.11 commands the hardware current-permission gate; the gauge alert is now polled instead of using that GPIO. The policy forces LOW before controller changes, acknowledges the CC event, waits 40 ms for the supervisor, rechecks the source, programs/readbacks the charger limit, then refreshes power, BC and CC evidence before a HIGH edge. A source change, stale classification, fault, failed control or maintenance request removes permission. An epoch tracks forced LOW events even when a complete maintenance request occurs between worker polls. GPIO49/J301.13 reads the shared charger IRQ and inverted latch feedback. A sustained LOW invalidates cached permission and requires a complete fresh qualification sequence; a brief charger IRQ gets a settling interval. The post-HIGH check also verifies feedback and the maintenance epoch. Command and confirmed permission remain separate. The RTOS adapter rounds up waits and adds a phase tick, so a requested 2 ms settling interval lasts approximately 10–20 ms at the configured 100 Hz. See the [targeted fault tests](power/usb-latch-feedback-review.md).

The BQ25895 ILIM pin does **not** support a guaranteed sub-500 mA limit; the earlier high-value ILIM-resistor approach was rejected during independent review. The revised electrical design uses a separate TPS22950-family low-current stage before the charger (the electrical review selects the accessible TPS22950CQDDCRQ1 package; the industrial C part is not an interchangeable substitute). Its exact implementation, startup/inrush, sustained fault response and depleted-pack recovery must be verified against the final electrical evidence and bench measurements. Default USB power cannot operate the complete screen/heater load. Future charging with the device off must be qualified separately; firmware cannot bootstrap a depleted pack merely by requesting more current. [BQ25895 datasheet](https://www.ti.com/lit/ds/symlink/bq25895.pdf), [TPS22950 datasheet](https://www.ti.com/lit/ds/symlink/tps22950.pdf).

The BME280 driver uses the official Bosch factory-trim compensator, forced T/P/H measurements and configuration readback. It rejects the common BMP280 substitution, erased/missing trim, skipped/reset samples, invalid uniform bursts, ignored configuration/trigger writes, busy conversions and failed reads. Legitimate zero humidity is not rejected merely because it is an endpoint. The sensor's calibration and physical chamber environment remain unverified.

The [qualified-profile standby implementation](power/off-charge-review/standby-implementation.md) can keep the source/charger worker active with zero backlight, stopped acquisition and heater control, after startup acceptance. Its enabled profile is currently a test fixture only; production remains charge inhibited. Profile writes, readback, final enable, maintenance, wake and failed/service-powered KILL returns have host fault tests. Standby requires adequate battery reserve and does not establish cold/depleted-pack recovery or positive net charging current.

The LTC2954 button interrupt is latched by an ISR because its pulse can be shorter than a polling cycle. GPIO33 releases the open-drain KILL output during startup and asserts it only after maintenance preparation. The hardware held-button shutdown remains independent of firmware. GPIO34 heater and GPIO51 translator enables retain hardware-off defaults. Real GPIO timing, rail sequencing and forced shutdown still require bench tests.

## Raw characterization capture

Capture the serial output with an ordinary serial monitor, then run:

```sh
python3 scripts/extract_characterization.py serial.log measurements.csv
```

The extractor opens no serial port and performs no flashing. Each `CSV1` row retains the raw channel's own timestamp, cell-selection identity, sequence/generation, ADC code, volts, gain, excitation, bias, environment, faults, warm-up and acquisition profile. `calibration_revision` means the last saved record's revision; that record may be inactive and is not proof that valid calibration was applied. Raw volts are not validated gas percentages. The32-bit millisecond timer wraps; the extractor deliberately preserves its raw values instead of inventing wall-clock time.

Record board/firmware hashes, sensor and reference-gas identities, reference uncertainty, environmental conditions, flow arrangement and charging state alongside each capture. Keep calibration mixtures separate from withheld validation mixtures. Determine the helium correction curve from those measurements.

## Reproduction and limits

```sh
cmake -S simulator -B simulator/build
cmake --build simulator/build -j6
ctest --test-dir simulator/build --output-on-failure
bash scripts/run_tests.sh
make build P4_REV=pre3
make build P4_REV=v3
python3 scripts/verify_system_contract.py
```

Build commands compile only. Host fakes inject faults into production logic; they do not exercise the ESP peripheral drivers, flash timing, network radio, actual sensor physics or thermals. Sanitizer and concurrency receipts are under the relevant subsystem directories. Firmware binaries, source manifests and integrated logs are in the parent verification package. No device was flashed or updated during this review.

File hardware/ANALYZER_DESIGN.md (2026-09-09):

# Trimix analyser — whole-system review

**Order status: HOLD.** Open `pcb/analyzer/Trimix_Analyzer.kicad_pro` for the
current main design and `pcb/usb-input/Trimix_USB_Input.kicad_pro` for the
thin USB daughterboard. The [system-review package](system-review/README.md)
contains current electrical, software and mechanical evidence. Earlier designs
are preserved, including this document's
[previous version](system-review/baseline-docs/ANALYZER_DESIGN.md).

The approved A3 exterior remains 85 × 180 × 43 mm. The separate Fusion design
is `Trimix_Enclosure_A3_SystemReview`; earlier PCBFit geometry is a preserved
baseline. A clear placement or CAD check is not a routed fabrication release.

## Installed modules and supply domains

| Assembly | Current basis |
|---|---|
| Host | Guition JC4880P443C_I_W, 4.3-inch portrait ESP32-P4 display |
| Pack | Two owner-confirmed 3400 mAh 18650 cells, 1S2P, 6800 mAh nominal; exact cell ratings remain unverified |
| Holder | Protected FMA FPML1S2P050C; retain its actual protected plug, identify mate and polarity before wiring |
| USB | GCT USB4720-03-A, 0.60 mm daughterboard, six-wire connection to main board |
| Oxygen | One installed AO₂ or R17JJ-CCR; separate J401/J402 differential input paths |
| Other sensors | MD62, actual BME280 humidity module, ZE07-CO |
| User button | Owned illuminated momentary 1NO button; hardware long-press shutdown retained |

All ground returns use protected holder P−, never raw cell negative. BQ25895,
MAX17048 and LTC2954 remain in the always-connected domain. LTC2954 controls
the TPS63020 switched 5 V supply. LM66100 provides reverse blocking on the host
5 V output, but the Guition's own USB/IP5306 power arrangement still needs
qualification before simultaneous external supplies are connected.
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

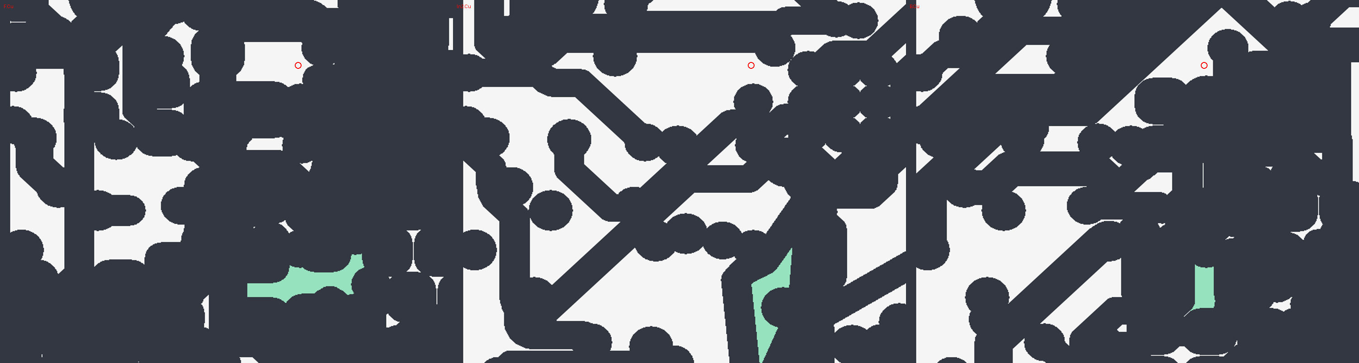
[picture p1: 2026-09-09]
hardware/system-review/electrical/routing-candidate/charger-current-repacked.png

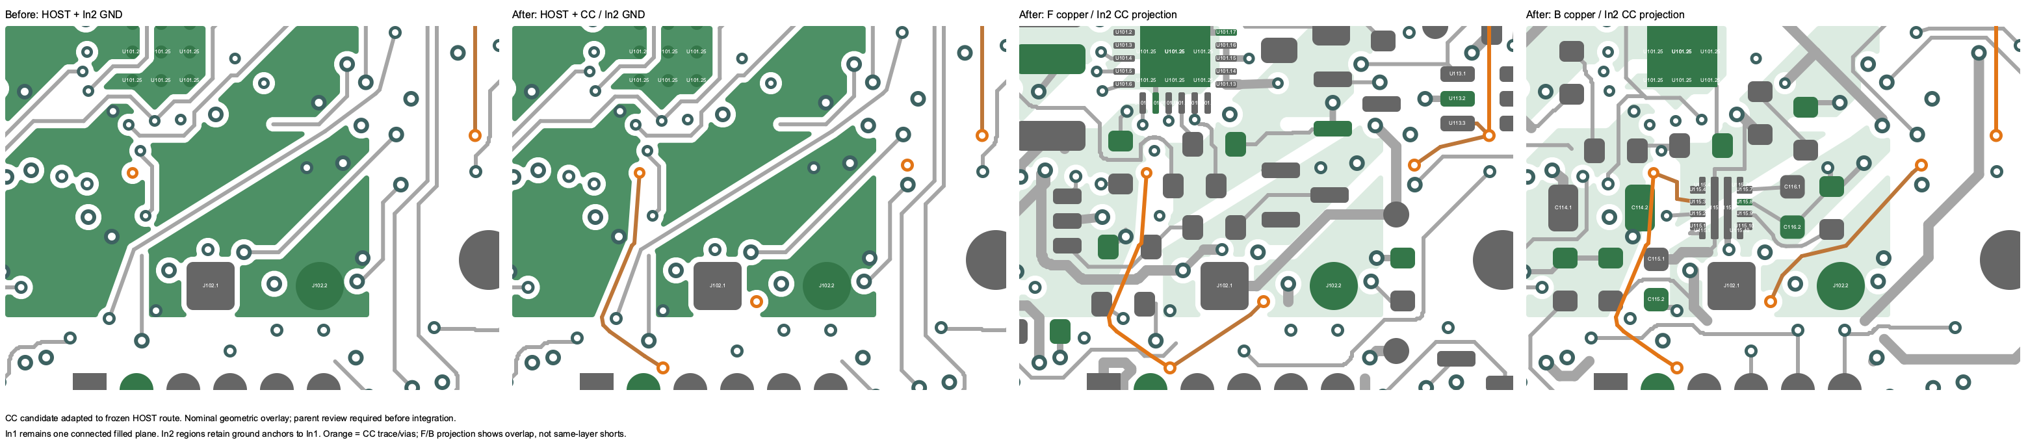
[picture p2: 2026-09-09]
hardware/system-review/electrical/routing-candidate/remote-cc-route-proposal/with-host/final-plane-views.png

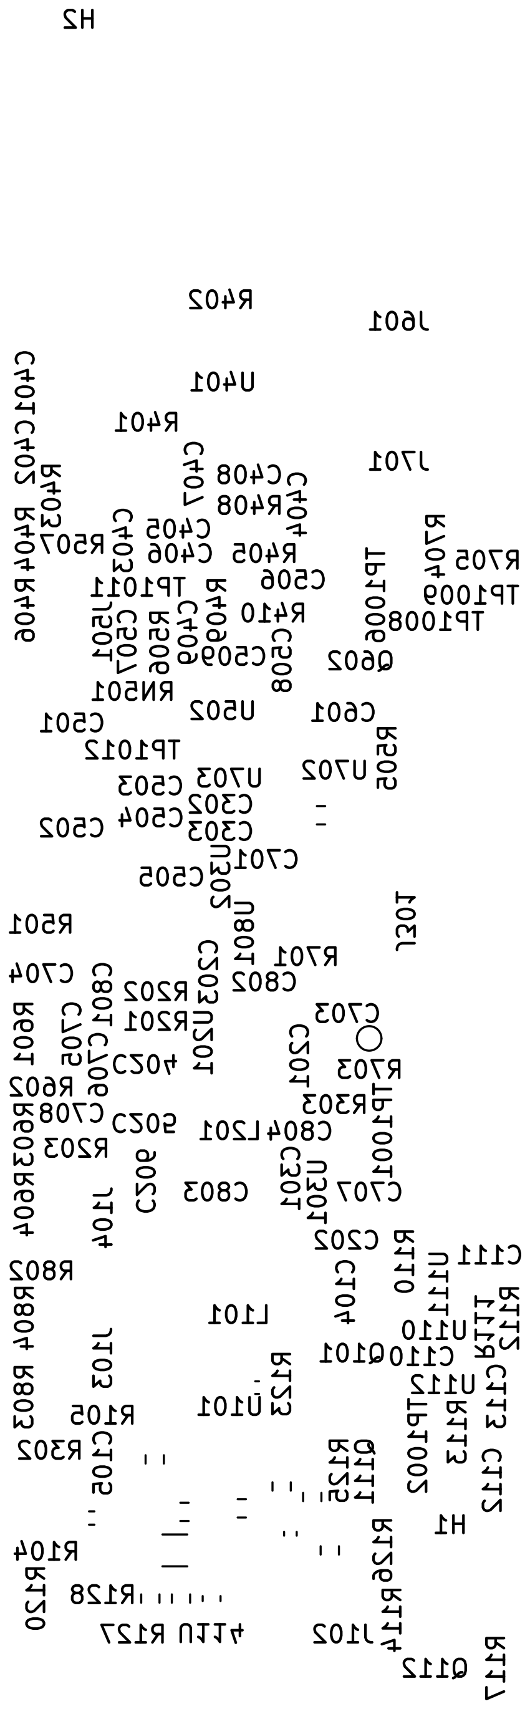
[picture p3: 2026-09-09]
hardware/system-review/electrical/main-final-independent/final-0962ad86/B-SilkS.png

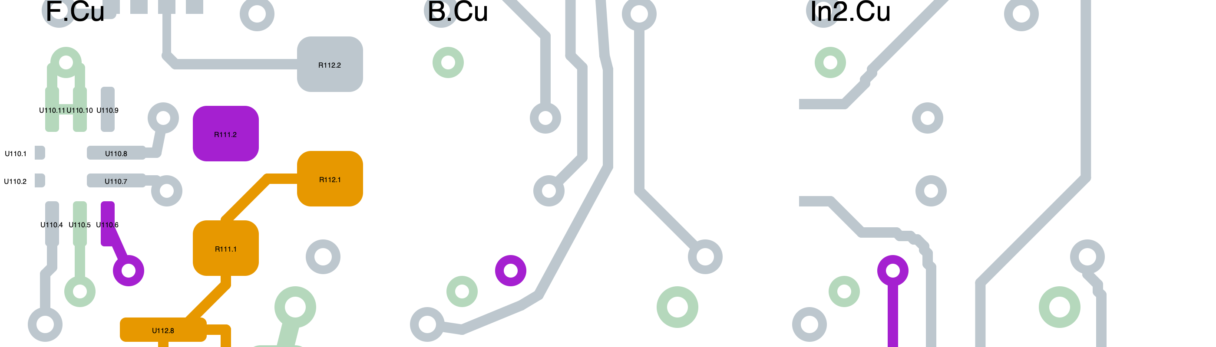
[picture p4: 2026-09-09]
hardware/system-review/electrical/routing-candidate/cc-int-proposal/local.png

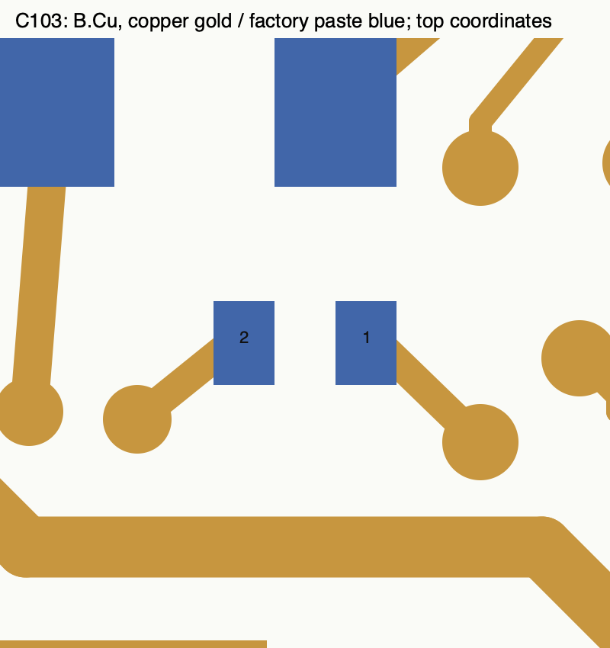
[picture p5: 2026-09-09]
hardware/system-review/electrical/main-final-independent/final-0962ad86/C103-factory-paste.png

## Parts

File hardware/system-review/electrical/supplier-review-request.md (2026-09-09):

# Unsent fabrication and assembly review request

This is a draft for a later supplier enquiry. It has **not been sent**, and it is not authorization to fabricate, assemble, substitute parts or purchase anything. Attach only the final source-matched engineering exports after routing and inspection finish.

## Proposed message

Please review these two engineering prototype boards and provide written process feedback before any order is placed. We need a fabrication/assembly solution for the critical interfaces below. Please identify any required drawing or footprint change explicitly; a generic DFM pass will not establish connector fit.

### Main PCB

- Four layers, nominal 1.6 mm, JLC04161H-3313, 1 oz outer and 0.5 oz inner copper, ENIG. Please confirm the finished stackup and thickness tolerance for this job.
- Factory assembly of the exposed-pad/fine-pitch devices and the agreed factory BOM population. The manual-assembly population and DNP rows must remain unpopulated unless separately approved.
- Confirm epoxy resin fill, planarization and copper cap on both faces for the **27 selected holes** in `main-final/fill-cap-process/required-fill-cap-holes.csv`: 9 U101 and 15 U201 package thermal bores, plus 3 signal VIPPO. Some thermal holes are encoded as plated footprint pads, so a routed-via option alone does not specify them. Soldermask plugging is not the specified substitute. Do not fill component lead holes.
- Review paste and stencil apertures for BQ25895, TPS63020, TPS259470 RPW0010A, the ADCs and the matched resistor network. RPW0010A has asymmetric power lands; do not replace them with a generic center-ground QFN footprint.
- Review the source-matched factory-only paste in `main-final/factory-stencil/cam/`, containing only the 24 factory parts. Manual/DNP apertures, including C706, are omitted. Confirm stencil thickness, cap flatness, solder volume, thermal-pad coverage/void criteria and inspection. The full-board paste in the general CAM folder is retained only for design/export comparison.
- Confirm double-sided assembly feasibility, tooling/panel requirements, inspection coverage and the exact manufacturer part numbers. TPS22950CQDDCRQ1 must not be replaced by the similarly named industrial C variant.
- Review the final inner-layer drill-to-copper clearances and confirm that all quoted fabrication tolerances are reflected in the supplied process.

### USB daughterboard — unresolved process conflicts

- Two layers, nominal **0.60 mm**, matching the GCT USB4720-03-A drawing's **0.50–0.70 mm** range. Review the small board's panel and connector-support fixture requirements.
- The current footprint preserves the GCT recommended lands and cutout. Its nominal copper-to-cutout gaps include approximately **0.10 mm and 0.15 mm**, below JLCPCB's published 0.20 mm routed-edge clearance.
- Two ground tags use **0.80 mm lands with 0.50 mm holes**, giving **0.15 mm nominal annular rings**. This is below JLCPCB's published **0.18 mm absolute minimum for two-layer, 1 oz PTH pads**.
- The connector drawing's cutout tolerance is tighter than the published routing tolerance. Please confirm a specific achievable process or provide a manufacturer/assembler-approved alternative land and cutout drawing. Merely accepting a DRC waiver is insufficient.
- Review **TPD4E05U06DQAR** 0.20 mm-wide lands, paste/bridge control and optical inspection. Its internally unconnected opposite pads are deliberately connected by external copper for TI's supported straight-through routing; those are real PCB connections.
- Review the soldered six-wire interface, plated slots and connector retention. Do not increase board thickness, relocate the connector, enlarge the notch or change its lands without a revised drawing and fit review.

Please state which items your process can meet, which require changes, what inspection you provide, and any minimum panel/order constraints. Do not begin production or make substitutions based on this enquiry.

## Source references for the enquiry

- [GCT USB4720 product](https://gct.co/connector/usb4720)
- [GCT product drawing](https://www.mouser.com/pdfDocs/USB4720-ProductDrawing.pdf)
- [JLCPCB capabilities](https://jlcpcb.com/capabilities/pcb-capabilities)
- [JLCPCB stackup table](https://jlcpcb.com/impedance)
- [TI TPD4E05U06 datasheet](https://www.ti.com/lit/ds/symlink/tpd4e05u06.pdf)

The electrical review and all physical validation requirements remain separate from supplier acceptance.

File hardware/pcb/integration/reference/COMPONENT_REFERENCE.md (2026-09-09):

# PCB component reference

Read the printed reference (for example **R101**) and find it below. The letters identify the component type; the number is its unique identifier, not its resistance or rating.

**173 PCB references:** 169 on the main board and 4 on the USB board. The main count includes twelve test pads and two mounting holes. These are the current design values, not a confirmed shopping list or fabrication release. Main routing is unfinished.

Values below expand the schematic unit notation into plain English. The [CSV](COMPONENT_REFERENCE.csv) also preserves every exact schematic value, footprint, source field, assembly note and source location. Ratings and part numbers are shown only where the source supplies them. A blank manufacturer/MPN field means none is explicitly assigned there.

**DNP** means “do not populate”: leave that component position empty. **Fit in current draft** describes the current assembly choice, not stock or package qualification. **PROVISIONAL** and **validation required** remain open gates. Test pads and mounting holes are not purchased electronic components. J104 uses a header, but its charging-arm shunt must remain off before commissioning.

**Silkscreen side** tells you where the reference is printed; it is independent of the component mounting side in the CSV. Both faces now carry components. Back labels are mirrored in KiCad so they read normally when you turn the bare board over. Dense areas use reverse labels, which may be covered after assembly. Nine references are explicitly **Assembly map only** because no readable nearby silkscreen position was available: main C106, R102, R115, R116, R119, R124, U115; USB J901 and J902. U901 and D901 use independent board-text labels. Use the assembly maps to locate unprinted references.

Companion maps: main [front silkscreen](main-front.svg), [back silkscreen](main-back.svg) and [front assembly map](main-assembly.svg), [back assembly map](main-back-assembly.svg); USB [front silkscreen](usb-front.svg) and [back silkscreen](usb-back.svg).

## Prefix legend

| Prefix | Meaning | How to read it |
|---|---|---|
| R | Resistor | Sets resistance; a zero-ohm part is an electrical link. |
| RN | Resistor network | Matched resistors in one package; their ratio provides a stable reference. |
| C | Capacitor | Stores charge; often used for filtering or supply decoupling. |
| U | Integrated circuit | A chip or, in the schematic, an explicitly identified remote module. |
| J | Connector | A cable connection, socket or jumper/header position. |
| L | Inductor | Stores energy magnetically, for example in a switching supply. |
| Q | Transistor | An electronic switching or signal-control device. |
| D | Diode | Includes light-emitting diodes (LEDs). |
| RV | Adjustable resistor | A potentiometer or trimming resistor. |
| SW | Switch | A physical contact switch. |
| TP | Test pad | Bare PCB copper for a measurement probe; no fitted component. |
| H | Mounting hole | A mechanical PCB hole; no electronic component. |

## Main board

### 01  CHARGING + BATTERY

| Marking | Silkscreen side | Component type | Value or type | Fit status | Function stated in source |
|---|---|---|---|---|---|
| [C101](../../analyzer/Charging.kicad_sch#L5144) | Back | Capacitor | 1 microfarad / 25 volts X7R / 10% | Fit in current draft | — |
| [C102](../../analyzer/Charging.kicad_sch#L4598) | Back | Capacitor | 22 microfarads / 16 volts X7R / 20% | Fit in current draft | — |
| [C103](../../analyzer/Charging.kicad_sch#L5750) | Back | Capacitor | 47 nanofarads / 50 volts X7R / 10% | Fit in current draft | — |
| [C104](../../analyzer/Charging.kicad_sch#L4384) | Back | Capacitor | 22 microfarads / 16 volts X7R / 20% | Fit in current draft | — |
| [C105](../../analyzer/Charging.kicad_sch#L7161) | Back | Capacitor | 22 microfarads / 16 volts X7R / 20% | Fit in current draft | — |
| [C106](../../analyzer/Charging.kicad_sch#L5252) | Assembly map only | Capacitor | 22 microfarads / 25 volts X5R / 20% | Fit in current draft | — |
| [C107](../../analyzer/Charging.kicad_sch#L6006) | Back | Capacitor | 22 microfarads / 25 volts X5R / 20% | Fit in current draft | — |
| [D101](../../analyzer/Charging.kicad_sch#L6446) | Back | Light-emitting diode (LED) | CHARGE (red) | Fit in current draft; PROVISIONAL footprint | — |
| [J101](../../analyzer/Charging.kicad_sch#L6808) | Front | Connector | USB HARNESS: 5V/GND/CC1/CC2/D+/D- | Fit in current draft; PROVISIONAL footprint | — |
| [J102](../../analyzer/Charging.kicad_sch#L6271) | Back | Connector | PACK PIGTAIL | Fit in current draft; PROVISIONAL footprint | PCB pigtail to RCY/BEC mate; verify red/black polarity; PCB land pending |
| [J103](../../analyzer/Charging.kicad_sch#L5634) | Back | Connector | PACK NTC: 103AT-2 | Fit in current draft; PROVISIONAL footprint | — |
| [J104](../../analyzer/Charging.kicad_sch#L7278) | Back | Jumper header | ARM: OPEN | Fit in current draft | Enables autonomous charging even when host power is off |
| [L101](../../analyzer/Charging.kicad_sch#L4715) | Back | Inductor | 1 microhenry / 74437349010 | Fit in current draft; PROVISIONAL footprint | — |
| [Q101](../../analyzer/Charging.kicad_sch#L6908) | Back | N-channel MOSFET transistor | 2N7002 | Fit in current draft | — |
| [R101](../../analyzer/Charging.kicad_sch#L7411) | Back | Resistor | 5.23 kilohms 1% | Fit in current draft | — |
| [R102](../../analyzer/Charging.kicad_sch#L5369) | Assembly map only | Resistor | 30.1 kilohms 1% | Fit in current draft | — |
| [R103](../../analyzer/Charging.kicad_sch#L4946) | Back | Resistor | 300 ohms / 1% / supported ILIM range | Fit in current draft | — |
| [R104](../../analyzer/Charging.kicad_sch#L4137) | Back | Resistor | 100 kilohms | Fit in current draft | — |
| [R105](../../analyzer/Charging.kicad_sch#L6561) | Back | Resistor | 100 kilohms | Fit in current draft | — |
| [R106](../../analyzer/Charging.kicad_sch#L4501) | Back | Resistor | 2.2 kilohms | Fit in current draft | — |
| [R107](../../analyzer/Charging.kicad_sch#L5045) | Back | Resistor | 10 kilohms | Fit in current draft | — |
| [SW101](../../analyzer/Charging.kicad_sch#L4821) | Back | Switch | BQ service wake / B3U-1000P | Fit in current draft; PROVISIONAL footprint | — |
| [U101](../../analyzer/Charging.kicad_sch#L5468) | Back | Integrated circuit | BQ25895RTWR | Fit in current draft | Single-cell battery charger controlled over I2C. |

### 02  SWITCHED 5 V

| Marking | Silkscreen side | Component type | Value or type | Fit status | Function stated in source |
|---|---|---|---|---|---|
| [C201](../../analyzer/Supply_5V.kicad_sch#L2395) | Back | Capacitor | 22 microfarads / 25 volts X5R / 20% | Fit in current draft | — |
| [C202](../../analyzer/Supply_5V.kicad_sch#L3352) | Back | Capacitor | 22 microfarads / 25 volts X5R / 20% | Fit in current draft | — |
| [C203](../../analyzer/Supply_5V.kicad_sch#L1991) | Back | Capacitor | 100 nanofarads / 50 volts X7R / 10% | Fit in current draft | — |
| [C204](../../analyzer/Supply_5V.kicad_sch#L2512) | Back | Capacitor | 22 microfarads / 16 volts X7R / 20% | Fit in current draft | — |
| [C205](../../analyzer/Supply_5V.kicad_sch#L2963) | Back | Capacitor | 22 microfarads / 16 volts X7R / 20% | Fit in current draft | — |
| [C206](../../analyzer/Supply_5V.kicad_sch#L3617) | Back | Capacitor | 22 microfarads / 16 volts X7R / 20% | Fit in current draft | — |
| [L201](../../analyzer/Supply_5V.kicad_sch#L2728) | Back | Inductor | 1.5 microhenries / XGL4030-152MEC | Fit in current draft | — |
| [R201](../../analyzer/Supply_5V.kicad_sch#L3253) | Back | Resistor | 1.62 megaohms 1% | Fit in current draft | — |
| [R202](../../analyzer/Supply_5V.kicad_sch#L3080) | Back | Resistor | 180 kilohms 1% | Fit in current draft | — |
| [R203](../../analyzer/Supply_5V.kicad_sch#L2629) | Back | Resistor | 100 kilohms | Fit in current draft | — |
| [U201](../../analyzer/Supply_5V.kicad_sch#L2825) | Back | Integrated circuit | TPS63020DSJR | Fit in current draft | Adjustable buck-boost voltage converter. |

### 03  GUITION + FUEL GAUGE

| Marking | Silkscreen side | Component type | Value or type | Fit status | Function stated in source |
|---|---|---|---|---|---|
| [C301](../../analyzer/Gauge_Interface.kicad_sch#L4468) | Back | Capacitor | 100 nanofarads / 50 volts X7R / 10% | Fit in current draft | — |
| [C302](../../analyzer/Gauge_Interface.kicad_sch#L5355) | Back | Capacitor | 4.7 microfarads / 16 volts X5R / 10% | Fit in current draft | — |
| [C303](../../analyzer/Gauge_Interface.kicad_sch#L5524) | Back | Capacitor | 4.7 microfarads / 16 volts X5R / 10% | Fit in current draft | — |
| [J301](../../analyzer/Gauge_Interface.kicad_sch#L4576) | Back | Connector | GUITION JP1 / 2x13 | Fit in current draft; PROVISIONAL footprint | Pin-for-pin cable to Guition JC4880P443C_I_W JP1 |
| [R301](../../analyzer/Gauge_Interface.kicad_sch#L4143) | Back | Resistor | 10 kilohms | Fit in current draft | — |
| [R302](../../analyzer/Gauge_Interface.kicad_sch#L3970) | Back | Resistor | 4.7 kilohms / FIT | Fit in current draft | — |
| [R303](../../analyzer/Gauge_Interface.kicad_sch#L3871) | Back | Resistor | 4.7 kilohms / FIT | Fit in current draft | — |
| [U301](../../analyzer/Gauge_Interface.kicad_sch#L4879) | Back | Integrated circuit | MAX17048G+ | Fit in current draft | Single-cell battery fuel gauge. |
| [U302](../../analyzer/Gauge_Interface.kicad_sch#L5077) | Back | Integrated circuit | LM66100DCKR | Fit in current draft | Blocks Guition USB-powered 5V rail from feeding our buck-boost output |

### 04  TWO OXYGEN INPUTS

| Marking | Silkscreen side | Component type | Value or type | Fit status | Function stated in source |
|---|---|---|---|---|---|
| [C401](../../analyzer/Oxygen.kicad_sch#L2838) | Back | Capacitor | 1 microfarad / 16 volts X7R / 10% | Fit in current draft | — |
| [C402](../../analyzer/Oxygen.kicad_sch#L4587) | Back | Capacitor | 10 nanofarads / 50 volts X7R / 10% | Fit in current draft | — |
| [C403](../../analyzer/Oxygen.kicad_sch#L2625) | Back | Capacitor | 10 nanofarads / 50 volts X7R / 10% | Fit in current draft | — |
| [C404](../../analyzer/Oxygen.kicad_sch#L4698) | Back | Capacitor | 1 microfarad / 16 volts X7R / 10% | Fit in current draft | — |
| [C405](../../analyzer/Oxygen.kicad_sch#L2949) | Back | Capacitor | 10 nanofarads / 50 volts X7R / 10% | Fit in current draft | — |
| [C406](../../analyzer/Oxygen.kicad_sch#L3783) | Back | Capacitor | 10 nanofarads / 50 volts X7R / 10% | Fit in current draft | — |
| [C407](../../analyzer/Oxygen.kicad_sch#L3570) | Back | Capacitor | 100 nanofarads / 50 volts X7R / 10% | Fit in current draft | — |
| [C408](../../analyzer/Oxygen.kicad_sch#L2514) | Back | Capacitor | 1 microfarad / 16 volts X7R / 10% | Fit in current draft | — |
| [C409](../../analyzer/Oxygen.kicad_sch#L4098) | Back | Capacitor | 1 microfarad / 16 volts X7R / 10% | Fit in current draft | — |
| [J401](../../analyzer/Oxygen.kicad_sch#L4462) | Front | Connector | AO2 / 3-pin cable | Fit in current draft; PROVISIONAL footprint | — |
| [J402](../../analyzer/Oxygen.kicad_sch#L4209) | Front | Connector | SMB male-centre / Amphenol142138 | Fit in current draft; PROVISIONAL footprint | — |
| [R401](../../analyzer/Oxygen.kicad_sch#L3681) | Back | Resistor | 100 ohms / 0.1% | Fit in current draft | — |
| [R402](../../analyzer/Oxygen.kicad_sch#L3996) | Back | Resistor | 100 ohms / 0.1% | Fit in current draft | — |
| [R403](../../analyzer/Oxygen.kicad_sch#L3264) | Back | Resistor | 1 megaohm / 1% | Fit in current draft | — |
| [R404](../../analyzer/Oxygen.kicad_sch#L3468) | Back | Resistor | 1 megaohm / 1% | Fit in current draft | — |
| [R405](../../analyzer/Oxygen.kicad_sch#L3162) | Back | Resistor | 100 ohms / 0.1% | Fit in current draft | — |
| [R406](../../analyzer/Oxygen.kicad_sch#L4360) | Back | Resistor | 100 ohms / 0.1% | Fit in current draft | — |
| [R407](../../analyzer/Oxygen.kicad_sch#L3366) | Front | Resistor | 1 megaohm / 1% | Fit in current draft | — |
| [R408](../../analyzer/Oxygen.kicad_sch#L2736) | Back | Resistor | 1 megaohm / 1% | Fit in current draft | — |
| [R409](../../analyzer/Oxygen.kicad_sch#L3060) | Back | Resistor | 10 kilohms / 0.1% | Fit in current draft | — |
| [R410](../../analyzer/Oxygen.kicad_sch#L3894) | Back | Resistor | 10 kilohms / 0.1% | Fit in current draft | — |
| [U401](../../analyzer/Oxygen.kicad_sch#L4806) | Back | Integrated circuit | ADS122C04IPWR | Fit in current draft | — |

### 05  HELIUM BRIDGE

| Marking | Silkscreen side | Component type | Value or type | Fit status | Function stated in source |
|---|---|---|---|---|---|
| [C501](../../analyzer/Helium.kicad_sch#L2961) | Back | Capacitor | 4.7 microfarads / 16 volts X5R / 10% | Fit in current draft | — |
| [C502](../../analyzer/Helium.kicad_sch#L3933) | Back | Capacitor | 4.7 microfarads / 16 volts X5R / 10% | Fit in current draft | — |
| [C503](../../analyzer/Helium.kicad_sch#L3285) | Back | Capacitor | 10 nanofarads / 50 volts X7R / 10% / DNP | DNP — do not fit | — |
| [C504](../../analyzer/Helium.kicad_sch#L3822) | Back | Capacitor | 100 nanofarads / 50 volts X7R / 10% | Fit in current draft | — |
| [C505](../../analyzer/Helium.kicad_sch#L2617) | Back | Capacitor | 1 microfarad / 16 volts X7R / 10% | Fit in current draft | — |
| [C506](../../analyzer/Helium.kicad_sch#L3396) | Back | Capacitor | 10 nanofarads / 50 volts X7R / 10% | Fit in current draft | — |
| [C507](../../analyzer/Helium.kicad_sch#L2850) | Back | Capacitor | 10 nanofarads / 50 volts X7R / 10% | Fit in current draft | — |
| [C508](../../analyzer/Helium.kicad_sch#L3609) | Back | Capacitor | 100 nanofarads / 50 volts X7R / 10% | Fit in current draft | — |
| [C509](../../analyzer/Helium.kicad_sch#L4053) | Back | Capacitor | 1 microfarad / 16 volts X7R / 10% | Fit in current draft | — |
| [J501](../../analyzer/Helium.kicad_sch#L4266) | Back | Connector | MD62 cable / <=30 cm | Fit in current draft; PROVISIONAL footprint | — |
| [R501](../../analyzer/Helium.kicad_sch#L3507) | Back | Resistor | 100 kilohms | Fit in current draft | — |
| [R504](../../analyzer/Helium.kicad_sch#L3183) | Back | Resistor | 10 kilohms / 0.1% | Fit in current draft | — |
| [R505](../../analyzer/Helium.kicad_sch#L3720) | Back | Resistor | 10 kilohms / 0.1% | Fit in current draft | — |
| [R506](../../analyzer/Helium.kicad_sch#L4164) | Back | Resistor | 680 ohms / 0.1% | Fit in current draft | — |
| [R507](../../analyzer/Helium.kicad_sch#L3081) | Back | Resistor | 680 ohms / 0.1% | Fit in current draft | — |
| [RN501](../../analyzer/Helium.kicad_sch#L4399) | Back | Resistor network | Two matched 2 kilohm resistors; 1:1 divider | Fit in current draft | Fixed 1.5 V nominal MD62 bridge reference; software stores signed zero/span |
| [U501](../../analyzer/Helium.kicad_sch#L2728) | Front | Integrated circuit | TPS7A2030PDBVR | Fit in current draft | — |
| [U502](../../analyzer/Helium.kicad_sch#L4714) | Back | Integrated circuit | ADS122C04IPWR | Fit in current draft | — |

### 06  GAS-CHAMBER CLIMATE

| Marking | Silkscreen side | Component type | Value or type | Fit status | Function stated in source |
|---|---|---|---|---|---|
| [C601](../../analyzer/Environment.kicad_sch#L2145) | Back | Capacitor | 1 microfarad / 25 volts X7R / 10% | Fit in current draft | — |
| [J601](../../analyzer/Environment.kicad_sch#L2463) | Back | Connector | BME280 harness | Fit in current draft | — |
| [Q601](../../analyzer/Environment.kicad_sch#L2358) | Front | N-channel MOSFET transistor | BSS138 | Fit in current draft | — |
| [Q602](../../analyzer/Environment.kicad_sch#L2040) | Back | N-channel MOSFET transistor | BSS138 | Fit in current draft | — |
| [R601](../../analyzer/Environment.kicad_sch#L2816) | Back | Resistor | 0 ohms / fit: 3.3 volts | Fit in current draft | — |
| [R602](../../analyzer/Environment.kicad_sch#L1938) | Back | Resistor | 0 ohms / DNP: 5 volts option | DNP — do not fit | — |
| [R603](../../analyzer/Environment.kicad_sch#L2256) | Back | Resistor | 4.7 kilohms / DNP | DNP — do not fit | — |
| [R604](../../analyzer/Environment.kicad_sch#L2580) | Back | Resistor | 4.7 kilohms / DNP | DNP — do not fit | — |

### 07  EXPERIMENTAL CO

| Marking | Silkscreen side | Component type | Value or type | Fit status | Function stated in source |
|---|---|---|---|---|---|
| [C701](../../analyzer/Carbon_Monoxide.kicad_sch#L3541) | Back | Capacitor | 22 microfarads / 25 volts X5R / 20% | Fit in current draft | — |
| [C702](../../analyzer/Carbon_Monoxide.kicad_sch#L4114) | Back | Capacitor | 22 microfarads / 16 volts X5R / 20% | Fit in current draft | — |
| [C703](../../analyzer/Carbon_Monoxide.kicad_sch#L3781) | Back | Capacitor | 22 microfarads / 16 volts X5R / 20% | Fit in current draft | — |
| [C704](../../analyzer/Carbon_Monoxide.kicad_sch#L4461) | Back | Capacitor | 1 microfarad / 25 volts X7R / 10% | Fit in current draft | — |
| [C705](../../analyzer/Carbon_Monoxide.kicad_sch#L3661) | Back | Capacitor | 1 microfarad / 25 volts X7R / 10% | Fit in current draft | — |
| [C706](../../analyzer/Carbon_Monoxide.kicad_sch#L5144) | Back | Capacitor | 10 nanofarads / 50 volts X7R / 10% / DNP | DNP — do not fit | — |
| [C707](../../analyzer/Carbon_Monoxide.kicad_sch#L4003) | Back | Capacitor | 100 nanofarads / 50 volts X7R / 10% | Fit in current draft | — |
| [C708](../../analyzer/Carbon_Monoxide.kicad_sch#L4698) | Back | Capacitor | 100 nanofarads / 50 volts X7R / 10% | Fit in current draft | — |
| [J701](../../analyzer/Carbon_Monoxide.kicad_sch#L4581) | Back | Connector | ZE07-CO harness | Fit in current draft | — |
| [L701](../../analyzer/Carbon_Monoxide.kicad_sch#L5644) | Front | Inductor | 1 microhenry / XGL4020-102MEC | Fit in current draft; validation required | — |
| [R701](../../analyzer/Carbon_Monoxide.kicad_sch#L5255) | Back | Resistor | 787 kilohms / 0.1% | Fit in current draft | — |
| [R702](../../analyzer/Carbon_Monoxide.kicad_sch#L5042) | Back | Resistor | 100 kilohms / 0.1% | Fit in current draft | — |
| [R703](../../analyzer/Carbon_Monoxide.kicad_sch#L4940) | Back | Resistor | 100 kilohms | Fit in current draft | — |
| [R704](../../analyzer/Carbon_Monoxide.kicad_sch#L3901) | Back | Resistor | 100 ohms | Fit in current draft | — |
| [R705](../../analyzer/Carbon_Monoxide.kicad_sch#L4359) | Back | Resistor | 100 ohms | Fit in current draft | — |
| [U701](../../analyzer/Carbon_Monoxide.kicad_sch#L4234) | Front | Integrated circuit | TPS61023DRLR | Fit in current draft | — |
| [U702](../../analyzer/Carbon_Monoxide.kicad_sch#L4809) | Back | Integrated circuit | TPS7A2030PDBVR | Fit in current draft | — |
| [U703](../../analyzer/Carbon_Monoxide.kicad_sch#L5357) | Back | Integrated circuit | TXU0202DCUR | Fit in current draft | — |

### 08  PUSH-BUTTON ON / OFF

| Marking | Silkscreen side | Component type | Value or type | Fit status | Function stated in source |
|---|---|---|---|---|---|
| [C801](../../analyzer/Power_Control.kicad_sch#L1728) | Back | Capacitor | 100 nanofarads / 50 volts X7R / 10% | Fit in current draft | — |
| [C802](../../analyzer/Power_Control.kicad_sch#L2070) | Back | Capacitor | 100 nanofarads / 50 volts X7R / 10% | Fit in current draft | — |
| [C803](../../analyzer/Power_Control.kicad_sch#L2423) | Back | Capacitor | 33 nanofarads / 50 volts X7R / 10% | Fit in current draft | — |
| [C804](../../analyzer/Power_Control.kicad_sch#L2312) | Back | Capacitor | 1 microfarad / 16 volts X7R / 10% | Fit in current draft | — |
| [J801](../../analyzer/Power_Control.kicad_sch#L1839) | Front | Connector | POWER BUTTON / 1NO | Fit in current draft; PROVISIONAL footprint | Panel momentary normally-open contact; no load current |
| [J802](../../analyzer/Power_Control.kicad_sch#L2181) | Front | Connector | BUTTON LED +/- | Fit in current draft; PROVISIONAL footprint | — |
| [R801](../../analyzer/Power_Control.kicad_sch#L2738) | Front | Resistor | 5.1 kilohms | Fit in current draft | — |
| [R802](../../analyzer/Power_Control.kicad_sch#L2534) | Back | Resistor | 10 kilohms | Fit in current draft | — |
| [R803](../../analyzer/Power_Control.kicad_sch#L1968) | Back | Resistor | 100 kilohms | Fit in current draft | — |
| [R804](../../analyzer/Power_Control.kicad_sch#L2636) | Back | Resistor | 1 kilohm / DNP | DNP — do not fit | — |
| [U801](../../analyzer/Power_Control.kicad_sch#L2840) | Back | Integrated circuit | LTC2954CTS8-1 | Fit in current draft | Push-button controller. |

### 10  TEST PADS + BRING-UP

| Marking | Silkscreen side | Component type | Value or type | Fit status | Function stated in source |
|---|---|---|---|---|---|
| [TP1001](../../analyzer/Testpoints.kicad_sch#L134) | Back | Test pad | GND | Bare test pad; no fitted component | — |
| [TP1002](../../analyzer/Testpoints.kicad_sch#L147) | Back | Test pad | USB_5V | Bare test pad; no fitted component | — |
| [TP1003](../../analyzer/Testpoints.kicad_sch#L160) | Front | Test pad | PACK_P | Bare test pad; no fitted component | — |
| [TP1004](../../analyzer/Testpoints.kicad_sch#L173) | Front | Test pad | VSYS | Bare test pad; no fitted component | — |
| [TP1005](../../analyzer/Testpoints.kicad_sch#L188) | Front | Test pad | VOUT_5V | Bare test pad; no fitted component | — |
| [TP1006](../../analyzer/Testpoints.kicad_sch#L201) | Back | Test pad | HOST_3V3 | Bare test pad; no fitted component | — |
| [TP1007](../../analyzer/Testpoints.kicad_sch#L214) | Back | Test pad | POWER_EN | Bare test pad; no fitted component | — |
| [TP1008](../../analyzer/Testpoints.kicad_sch#L227) | Back | Test pad | I2C_SCL | Bare test pad; no fitted component | — |
| [TP1009](../../analyzer/Testpoints.kicad_sch#L242) | Back | Test pad | I2C_SDA | Bare test pad; no fitted component | — |
| [TP1010](../../analyzer/Testpoints.kicad_sch#L255) | Front | Test pad | HE_3V0 | Bare test pad; no fitted component | — |
| [TP1011](../../analyzer/Testpoints.kicad_sch#L268) | Back | Test pad | HE_SENSE | Bare test pad; no fitted component | — |
| [TP1012](../../analyzer/Testpoints.kicad_sch#L281) | Back | Test pad | O2_VMID | Bare test pad; no fitted component | — |

### 11  USB SOURCE QUALIFICATION

| Marking | Silkscreen side | Component type | Value or type | Fit status | Function stated in source |
|---|---|---|---|---|---|
| [C110](../../analyzer/USB_Source_Control.kicad_sch#L2418) | Back | Capacitor | 100 nanofarads / 50 volts X7R / 10% | Fit in current draft | — |
| [C111](../../analyzer/USB_Source_Control.kicad_sch#L3030) | Back | Capacitor | 100 nanofarads / 50 volts X7R / 10% | Fit in current draft | — |
| [C112](../../analyzer/USB_Source_Control.kicad_sch#L4096) | Back | Capacitor | 100 nanofarads / 50 volts X7R / 10% | Fit in current draft | — |
| [C113](../../analyzer/USB_Source_Control.kicad_sch#L4622) | Back | Capacitor | 100 nanofarads / 50 volts X7R / 10% | Fit in current draft | — |
| [Q110](../../analyzer/USB_Source_Control.kicad_sch#L4933) | Back | Transistor | DMN2056U-7 | Fit in current draft | — |
| [Q111](../../analyzer/USB_Source_Control.kicad_sch#L5118) | Back | Transistor | DMN2056U-7 | Fit in current draft | — |
| [R110](../../analyzer/USB_Source_Control.kicad_sch#L2116) | Back | Resistor | 887 kilohms / 1% | Fit in current draft | — |
| [R111](../../analyzer/USB_Source_Control.kicad_sch#L2267) | Back | Resistor | 33 kilohms / 1% | Fit in current draft | — |
| [R112](../../analyzer/USB_Source_Control.kicad_sch#L3190) | Back | Resistor | 10 kilohms / 1% | Fit in current draft | — |
| [R113](../../analyzer/USB_Source_Control.kicad_sch#L3643) | Back | Resistor | 97.6 kilohms / 0.1% | Fit in current draft | — |
| [R114](../../analyzer/USB_Source_Control.kicad_sch#L3794) | Back | Resistor | 10 kilohms / 0.1% | Fit in current draft | — |
| [R115](../../analyzer/USB_Source_Control.kicad_sch#L3945) | Assembly map only | Resistor | 10 kilohms / 1% | Fit in current draft | — |
| [R116](../../analyzer/USB_Source_Control.kicad_sch#L4782) | Assembly map only | Resistor | 1 kilohm / 0.1% | Fit in current draft | — |
| [R117](../../analyzer/USB_Source_Control.kicad_sch#L5303) | Back | Resistor | 100 kilohms / 1% | Fit in current draft | — |
| [R118](../../analyzer/USB_Source_Control.kicad_sch#L5454) | Back | Resistor | 100 kilohms / 1% | Fit in current draft | — |
| [U110](../../analyzer/USB_Source_Control.kicad_sch#L1643) | Back | Integrated circuit | TUSB320LAIRWBR | Fit in current draft | — |
| [U111](../../analyzer/USB_Source_Control.kicad_sch#L2611) | Back | Integrated circuit | PI3USB9201ZTAEX | Fit in current draft | — |
| [U112](../../analyzer/USB_Source_Control.kicad_sch#L4289) | Back | Integrated circuit | SN74AUP1G74DCUR | Fit in current draft | — |
| [U113](../../analyzer/USB_Source_Control.kicad_sch#L3374) | Front | Integrated circuit | TPS3808G01DBVR | Fit in current draft | — |

### 12  USB INPUT LIMITER

| Marking | Silkscreen side | Component type | Value or type | Fit status | Function stated in source |
|---|---|---|---|---|---|
| [C114](../../analyzer/USB_Input_Limiter.kicad_sch#L1176) | Back | Capacitor | 4.7 microfarads / 25 volts X7R / 10% | Fit in current draft | — |
| [R119](../../analyzer/USB_Input_Limiter.kicad_sch#L1025) | Assembly map only | Resistor | 19.2 kilohms / 0.1% | Fit in current draft | — |
| [R120](../../analyzer/USB_Input_Limiter.kicad_sch#L1345) | Back | Resistor | 10 kilohms / 1% | Fit in current draft | — |
| [U114](../../analyzer/USB_Input_Limiter.kicad_sch#L711) | Back | Integrated circuit | TPS22950CQDDCRQ1 | Fit in current draft | — |

### 13  USB OVERVOLTAGE PROTECTION

| Marking | Silkscreen side | Component type | Value or type | Fit status | Function stated in source |
|---|---|---|---|---|---|
| [C115](../../analyzer/USB_Overvoltage.kicad_sch#L1340) | Back | Capacitor | 100 nanofarads / 50 volts X7R | Fit in current draft | — |
| [C116](../../analyzer/USB_Overvoltage.kicad_sch#L1500) | Back | Capacitor | 3.3 nanofarads / 50 volts C0G / 5% | Fit in current draft | — |
| [Q112](../../analyzer/USB_Overvoltage.kicad_sch#L2846) | Back | Transistor | DMN2056U-7 | Fit in current draft | — |
| [R121](../../analyzer/USB_Overvoltage.kicad_sch#L1843) | Back | Resistor | 34 kilohms / 0.1% / 10ppm | Fit in current draft | — |
| [R122](../../analyzer/USB_Overvoltage.kicad_sch#L2003) | Back | Resistor | 649 ohms / 0.1% / 10ppm | Fit in current draft | — |
| [R123](../../analyzer/USB_Overvoltage.kicad_sch#L2163) | Back | Resistor | 10 kilohms / 0.1% / 10ppm | Fit in current draft | — |
| [R124](../../analyzer/USB_Overvoltage.kicad_sch#L2323) | Assembly map only | Resistor | 21.5 kilohms / 0.1% / 25ppm | Fit in current draft | — |
| [R125](../../analyzer/USB_Overvoltage.kicad_sch#L2483) | Back | Resistor | 10 kilohms / 0.1% / 25ppm | Fit in current draft | — |
| [R126](../../analyzer/USB_Overvoltage.kicad_sch#L1660) | Back | Resistor | 1.65 kilohms / 0.1% | Fit in current draft | — |
| [R127](../../analyzer/USB_Overvoltage.kicad_sch#L2643) | Back | Resistor | 10 kilohms / 1% | Fit in current draft | — |
| [R128](../../analyzer/USB_Overvoltage.kicad_sch#L3049) | Back | Resistor | 100 kilohms / 1% | Fit in current draft | — |
| [U115](../../analyzer/USB_Overvoltage.kicad_sch#L944) | Assembly map only | Integrated circuit | TPS259470ARPWR | Fit in current draft | — |

### Mechanical mounting

| Marking | Silkscreen side | Component type | Value or type | Fit status | Function stated in source |
|---|---|---|---|---|---|
| [H1](../../analyzer/Trimix_Analyzer.kicad_pcb#L29073) | Back | Mounting hole | 2.30 mm non-plated hole for M2 mounting | Mounting hole; no fitted component | — |
| [H2](../../analyzer/Trimix_Analyzer.kicad_pcb#L6742) | Back | Mounting hole | 2.30 mm non-plated hole for M2 mounting | Mounting hole; no fitted component | — |

## USB board

### 09  USB-A + USB-C INPUT

| Marking | Silkscreen side | Component type | Value or type | Fit status | Function stated in source |
|---|---|---|---|---|---|
| [D901](../../usb-input/Trimix_USB_Input.kicad_sch#L2455) | Front | Diode | TPD1E10B06DYAR | Fit in current draft | — |
| [J901](../../usb-input/Trimix_USB_Input.kicad_sch#L1380) | Assembly map only | Connector | USB4720-03-A | Fit in current draft | — |
| [J902](../../usb-input/Trimix_USB_Input.kicad_sch#L2624) | Assembly map only | Connector | TO MAIN J101 \| SAME PIN NUMBERS | Fit in current draft | — |
| [U901](../../usb-input/Trimix_USB_Input.kicad_sch#L2014) | Front | Integrated circuit | TPD4E05U06DQAR | Fit in current draft | — |

## Remote modules are separate

These two schematic references are off-board modules, so they are excluded from the 173-row PCB list:

- **U601 — GYBMEP / BME280-5V**: Off-board purchased module; verify actual chip ID and pull-up rail
- **U704 — ZE07-CO / off-board**: Experimental CO measurement; manufacturer excludes human safety use

The main schematic also shows J901/J902/U901/D901 for context; those four parts are counted once, on the separate USB board.
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

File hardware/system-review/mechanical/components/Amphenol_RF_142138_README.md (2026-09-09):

# Amphenol RF 142138 — J402 mounting reference

This model replaces the previous scaled SMA visual model. It is a **drawing-derived reconstruction**, not the manufacturer's CAD or a validated model of the owner's cable. The original J402 footprint position and electrical connections are unchanged.

Use `Amphenol_RF_142138_Drawing_Reconstruction.step` in KiCad with **scale 1, rotation 0°, offset 0 mm**. The origin is the centre signal pin at the connector's PCB seating plane. The body extends in +Z and the five solder tails extend in −Z. A separate `Amphenol_RF_142138_Nominal_Upper_Envelope.step` contains the full **7 × 7 × 7.6 mm nominal space above the PCB**, for a conservative check within the drawing's base footprint. Do not populate both alternatives as physical parts.

| Feature | Nominal dimensions | Evidence |
|---|---:|---|
| Base footprint | 7.00 × 7.00 mm | Rev B drawing |
| Nose-to-tail overall length | 11.50 mm | Rev B drawing |
| Solder-tail projection | 3.90 mm below seating plane | Rev B drawing |
| Barrel length above front base face | 5.80 mm | Rev B drawing |
| Base thickness | 1.80 mm | Derived: 11.50 − 3.90 − 5.80 |
| Above-PCB height | 7.60 mm | Derived: 11.50 − 3.90 |
| Four shell legs | 1.02 mm square, centres at (±2.54, ±2.54) mm | Rev B drawing |
| Centre solder tail | Ø0.96 mm | Rev B drawing |
| Recommended board holes | Ø1.20 centre; four Ø1.70 on a 5.08 mm square | Rev B drawing |

The product drawing does not dimension the complete barrel profile, snap groove, mating-pin projection, underside recess or internal insulator. The simplified visual barrel uses a generic SMB interface diameter reference; this is **not evidence that the complete RF142138 barrel has that diameter or axial profile**. Internal bore, pin and PTFE extents are explicitly marked reference parameters. The undimensioned underside recess and lead chamfers are omitted. Neither the reconstruction nor nominal envelope includes a mated plug, elbow, cable bend, solder fillet or tolerance margin.

The drawing's general metric tolerances are ±0.20 mm for 0.5–8 mm dimensions and ±0.40 mm for 8–30 mm dimensions. The derived 7.60 and 1.80 mm values are nominal differences, not independent tolerance specifications. Measure the received connector and cable before accepting a tight fit.

**Electrical isolation matters:** the J402 metal shell is connected to `O2_B_RAW_N`; it is not assigned to chassis or ground. The actual cable's SMB identity, mating force, occupied elbow volume and lead polarity remain to be checked.

The drawing specifies gold-finished brass shell/contact and natural PTFE. CAD colours represent those descriptions. The reconstruction's internal volume and default material properties must not be used for mass, plating, structural or thermal calculations.

Source: [Amphenol RF 142138 product page](https://www.amphenolrf.com/en-us/part/142138/883/), manufacturer Rev B drawing dated 21 November 2011, obtained unchanged through the [TestEquity drawing mirror](https://assets.testequity.com/te1/Documents/pdf/amphenol/amphenol_142138-connector_customer-drawing.pdf). The [official STEP download](https://www.amphenolrf.com/en-us/assets/file/4066922863/) was publicly listed but returned HTTP 403. Generic mating references are from the [Amphenol SMB interface sheet](https://www.amphenolrf.com/en-us/assets/file/4067456646/); they do not replace the undimensioned product profile.

The adjacent JSON contains hashes, exact CAD parameters, native bounds and unit-aware STEP reimport results. The editable F3D also retains a hidden nominal upper-envelope component. All modelling occurs in an isolated temporary Fusion document; the enclosure and unrelated open documents are preserved.

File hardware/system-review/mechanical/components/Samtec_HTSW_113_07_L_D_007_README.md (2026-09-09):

# Samtec HTSW keyed header reference

`Samtec_HTSW_113_07_L_D_007_Drawing_Reconstruction.step` is a **nominal drawing-derived model**, not manufacturer-authored CAD. It represents the proposed factory-omitted contact 7 variant of HTSW-113-07-L-D. Exact configured-part orderability remains a purchasing gate; this model does not approve manually removing a contact.

Use **scale 1**, **offset (0, 0, 0)** and **model rotation (0°, 0°, 0°)** in the KiCad footprint. Footprint rotation then moves the whole model and its numbered contacts together.

| Datum or dimension | Model definition, mm |
|---|---|
| Pin 1 centre | X0, Y0 |
| Even row | X2.54 |
| Successive contact pairs | Y decreases by 2.54 |
| PCB seating face | Z0 |
| Insulator bounds | X−1.2446…3.7846; Y−31.75…1.27; Z0…2.54 |
| Square contacts | 0.64 × 0.64 |
| Contact bounds along Z | −2.54…8.382 |
| Omitted contact | 7, at X0/Y−7.62 |
| Solid count | 26: one insulator and 25 contacts |

The body, tail and stand-off include nominal/reference dimensions. Mold details, tip chamfers, plating thickness and complete dimensional tolerances are omitted. Contact-shaped openings in the insulator prevent overlapping internal solids; they are visual interfaces rather than manufacturing tooling geometry. The actual socket, cable, key and cable bend are separate interfaces.

A unit-aware Fusion STEP reimport preserves all 26 solids, total bounds and total volume to numerical precision. The [verification receipt](../verification/htsw-keyed-model.json) records all numbered contact centres, source hashes and preservation of the original Fusion documents. The STEP SHA-256 is `708f3b6e37f9967bfc62d485ede709656be0cf84bfa94b4b9ee2bf02c35c88cc`.

The source is the locally archived Samtec HTSW series drawing, SHA-256 `1b67562fde61dc2488bd76240e48c70399c0cffd9a1a62866d89535f186e49b4`, with the [host harness contract](../../electrical/host-harness-review/contract.json) retaining the nominal/max/reference distinctions and proposed mating cable. The CAD authoring script is [htsw_header_model.py](../scripts/htsw_header_model.py).

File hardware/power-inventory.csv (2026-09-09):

item | quantity_or_order_variant | evidence | status_for_design | url
FMA FPML1S2P050C protected 1S2P holder | 1 | Completed order 2025-07-17; user approved protected leads | Use; seller 5 A discharge claim and thresholds need verification | https://www.aliexpress.com/item/1005008645295074.html
USB-C panel jack | 5pcs black2 2P Female Insert | Completed order 2025-07-17 | Not selected in A2.2; superseded by documented GCT USB daughterboard; old socket CC internals unverified | https://www.aliexpress.com/item/1005007613975409.html
MAX17048G bare TDFN8 | 5PCS lot x1 | Completed order 2026-02-20 | Use U301; confirm physical marking | https://www.aliexpress.com/item/1005009796395441.html
TPS63020DSJR or DSJT bare VSON14 | 5PCS lot x1 | Completed order 2026-02-20 | Use U201 adjustable IC | https://www.aliexpress.com/item/1005008807916943.html
TPS63020 module | 3.3V x2 | Completed order 2026-02-20 | Not substituted for the custom 5 V circuit | https://www.aliexpress.com/item/1005007967030664.html
BQ25895RTWR | Owner requested; quantity unknown | Exact-name AliExpress order search returned no result | Use U101; stock not independently confirmed
Integrated power inductor | 10PCS 0650 7x7x5mm 1UH | Completed order 2026-02-20 | Owned generic part remains unqualified; current L101 selects Wurth 74437349010 from the system-review BOM | https://www.aliexpress.com/item/1005001648530241.html
SMD resistor assortment | 0603-720pcs 36 values | Completed order 2026-02-20 | Check exact values and tolerances against BOM | https://www.aliexpress.com/item/1005010426363196.html
Through-hole resistor assortment | 300PCS with box 1/4W 30 values | Completed order 2025-06-17 | Bench prototyping; not the assigned 0603 footprints | https://www.aliexpress.com/item/1005009197685412.html
Ceramic through-hole capacitor | 100nF 50V 100pcs | Completed order 2025-06-17 | Not a substitute for power IC SMD bypassing | https://www.aliexpress.com/item/1005007175123984.html
Electrolytic assortment | 120 pcs 10 values | Completed order 2025-06-17 | Does not establish suitable power-stage ceramic capacitors | https://www.aliexpress.com/item/1005005626707702.html
18650 cells | 2 x 3400 mAh; 6800 mAh nominal 1S2P | Owner explicitly confirmed 3400 mAh per cell on 2026-09-05; overrides 2200 mAh listing image and earlier 3700 mAh estimate | Confirm matching physical cells chemistry and charge rating before charge | https://www.aliexpress.com/item/1005006117273720.html
1S 4A double-MOS PCM board | 1 lot | Completed order 2025-07-17 | Not used; protected FMA holder selected | https://www.aliexpress.com/item/1005005780163351.html
TP4056 Type-C modules | 10PCS | Completed order 2025-06-17 | Not used; BQ25895 selected | https://www.aliexpress.com/item/1005008337271054.html
Semitec 103AT-2 characteristic 10k NTC | 1 external pack sensor required | No order matched NTC search | Must source or confirm; J103 is its PCB connection
Coilcraft XFL4020-152ME 1.5uH | 1 required | TI datasheet recommended component; no stock evidence | Historical candidate superseded by L201 XGL4030-152MEC; use final system-review BOM
Power-stage X5R or X7R ceramic capacitors | See PCB BOM | Orders found did not establish suitable SMD parts | Select exact MPNs and DC-bias curves
2N7002 and LED and switches and PCB connectors | See PCB BOM | Not independently confirmed | Stock or sourcing and connector mechanical choices pending
ATORCH cell fixture; LiitoKala Lii-500S | Orders from 2026-08-30 | Shown awaiting delivery | Arrival of these two items not confirmed; DL24/P separately confirmed in current lab record
GCT USB4720-03-A | 1 required | User authorized replacement on 2026-09-06; manufacturer drawing reviewed | Selected; dedicated 0.60 mm six-wire USB PCB; TUSB320LAI supplies CC terminations on main PCB; stock and manufacturing/mechanical qualification pending | https://gct.co/connector/usb4720
DL24/P electronic load | Exact model/version to record | Owner confirms available 2026-09-08 | Available for qualified discharge/load tests; see system-review/lab-equipment.md; no test results yet

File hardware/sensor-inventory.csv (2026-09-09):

item | quantity_or_variant | evidence | design_use | qualification_or_sourcing | url
AO2 oxygen cell | 1 | Order 2025-06-17 and owner confirms three-pin cable | Oxygen channel A | Cable polarity and board-side mating connector must be verified | https://www.aliexpress.com/item/1005009147959378.html
R17JJ-CCR oxygen cell | 1 | Owner confirmed model and standalone analyser connection | Oxygen channel B | Verify cell polarity and insulated SMB mating fit
SMB male PCB connector | 10 pcs | Order 2026-02-20 | Separate oxygen coax input | Exact mounting pattern and shell isolation pending | https://www.aliexpress.com/item/1005007851936695.html
MD62 thermal conductivity sensor | 1 | Order 2025-06-17 | Experimental helium bridge | Match actual black detector mark to manual; do not use old imported pin numbering | https://www.aliexpress.com/item/32725880118.html
GYBMEP BME280-5V module | 1 | Order 2025-06-17 and supplied four-pin product image | Wired chamber humidity temperature pressure | Verify ID0x60 and regulator/pull-up topology; VIN GND SCL SDA | https://www.aliexpress.com/item/1005007524214715.html
ZE07-CO module | Order quantity1; listing bundle size not confirmed | Order 2025-06-30 and owner approved use | Experimental carbon-monoxide channel | Not CO2; manufacturer excludes human-safety use; validate humidity and supply | https://www.aliexpress.com/item/1005005816661786.html
12 mm illuminated momentary button | Green LED 3-6V 1NO self-reset | Order 2025-06-17 | Panel power button | Confirm separate contact and LED pins and LED current limiting | https://www.aliexpress.com/item/1005007168217107.html
ADS1115 breakout | 1 | Order 2025-06-17 | Bench prototyping | Owned breakout retained for bench use; final U401/U502 use ADS122C04IPWR, not this module | https://www.aliexpress.com/item/1005005973975124.html
ADS1115IDGS bare IC | Not required by current review | A2 design selection | Superseded A2 selection | U401/U502 upgraded to ADS122C04IPWR; retain this row as historical inventory context | https://www.ti.com/product/ADS1115
LTC2954CTS8-1 | 1 required | Old BOM candidate and A2 design selection | Push-button power controller | Stock not confirmed; exact suffix and TSOT-23 footprint to verify | https://www.analog.com/en/products/ltc2954.html
SPX3819M5-L-3-0 | Not required by current review | A2 design selection | Superseded A2 regulator candidate | Current U501/U702 select TPS7A2030PDBVR; use the system-review BOM | https://www.maxlinear.com/product/power-management/linear-regulators-ldos/ldos-and-regulators/ldos/spx3819
TXU0202DCUR | 1 required | A2 design selection | CO UART voltage translation | Stock not confirmed | https://www.ti.com/product/TXU0202
TPS61023DRLR | 1 required | A2 design selection | Dedicated CO supply with voltage margin | Stock not confirmed; qualify inductor and capacitors | https://www.ti.com/product/TPS61023
Precision bridge and CO feedback resistors | See A2 BOM | A2 design requirements | MD62 reference and CO voltage setting | Assortment kits do not prove 0.1 percent or low temperature coefficient availability
ADS122C04IPWR | 2 required; TSSOP-16 | User-approved measurement-electronics upgrade | U401 oxygen ADC and U502 helium ADC; original gas sensors retained | Stock not confirmed; factory/manual assembly population is in the current system-review BOM | https://www.ti.com/product/ADS122C04
TPS7A2030PDBVR | 2 required | System-review regulator selection | U501 MD62 excitation and U702 CO UART logic supply | Stock not confirmed; do not substitute historical SPX3819 footprint/pin mapping | https://www.ti.com/product/TPS7A20

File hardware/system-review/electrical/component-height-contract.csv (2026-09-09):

reference | side | MPN | DNP | PCB_x_mm | PCB_y_mm | rotation_deg | x_min_mm | y_min_mm | x_max_mm | y_max_mm | max_body_height_mm | assembly_allowance_mm | clearance_height_above_FCu_mm | Fusion_z_bottom_mm | Fusion_z_top_mm | Fusion_x_min_mm | Fusion_x_max_mm | Fusion_y_min_mm | Fusion_y_max_mm | basis | XY_basis | source | model_status
C101 | F.Cu | C0603C105K4RACTU | False | 8.3 | 82.3 | 180.0 | 7.3 | 81.69999999999999 | 9.3 | 82.9 | 0.9 | 0.15 | 1.05 | 22.1 | 23.15 | 57.699999999999996 | 59.7 | 37.099999999999994 | 38.30000000000001 | manufacturer package/part dimension; conservative package maxima where listed; extra0.15mm per-side XY allowance around F.Fab | manufacturer max where explicitly listed; otherwise current F.Fab bounding envelope | https://search.kemet.com/component-documentation/download/specsheet/C0603C105K4RACTU | check this envelope independently of generic STEP model; no scaling of purchased CAD
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

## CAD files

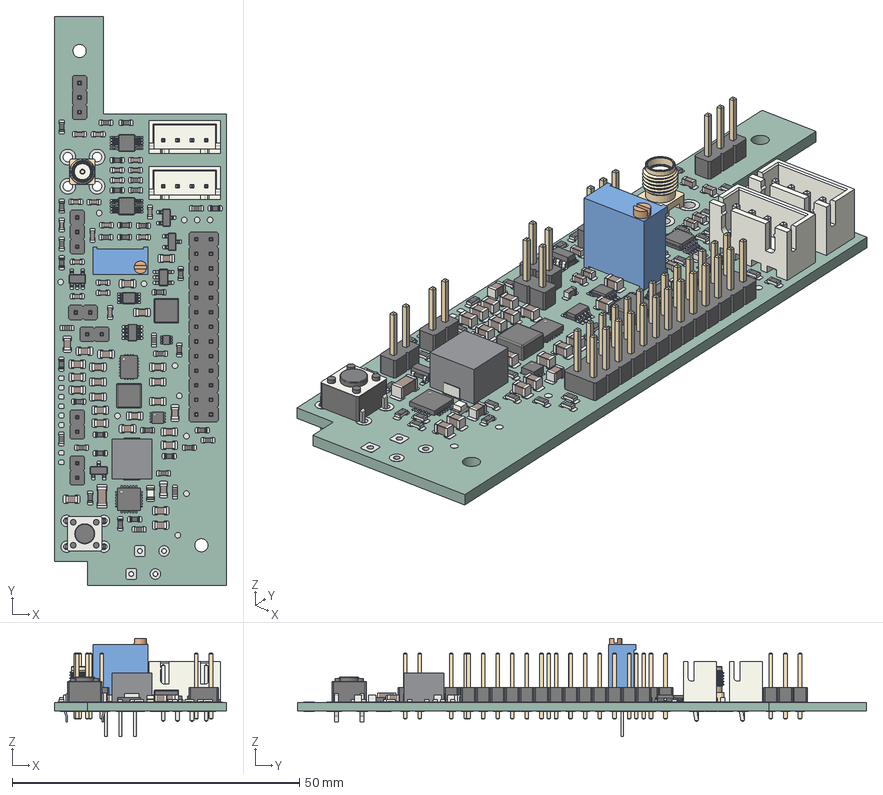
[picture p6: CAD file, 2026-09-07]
hardware/pcb/integration/verification/main-final-placement.step
30.0 x 99.0 x 17.1 mm
C_0603_1608Metric x 18
C_0805_2012Metric x 26
R_0603_1608Metric x 39
PinHeader_1x03_P254mm_Vertical x 2
JST_B4B_XH_A x 2
SW_PUSH_6mm
SOT-23 x 3
SOT-23-5 x 2
L_Wuerth_HCM-7050
LED_0805_2012Metric
PinHeader_1x02_P254mm_Vertical x 4
SMA_Amphenol_132134-10_Vertical
SOT_563
L_Coilcraft_XAL4020-XXX x 2
VSSOP-8_2.3x2mm_P0.5mm
TSOT-23-8
Potentiometer_Bourns_3296W_Vertical
C_1206_3216Metric
PinHeader_2x13_P254mm_Vertical
DFN_8_1EP_2x2mm_P05mm_EP07x13mm
DFN-14-1EP_3x4mm_Pitch0.5mm
TSSOP-10_3x3mm_P0.5mm x 2
Texas_RTW_WQFN-24-1EP_4x4mm_P0.5mm_EP2.7x2.7mm
Trimix_Analyzer_pad
Trimix_Analyzer_PCB

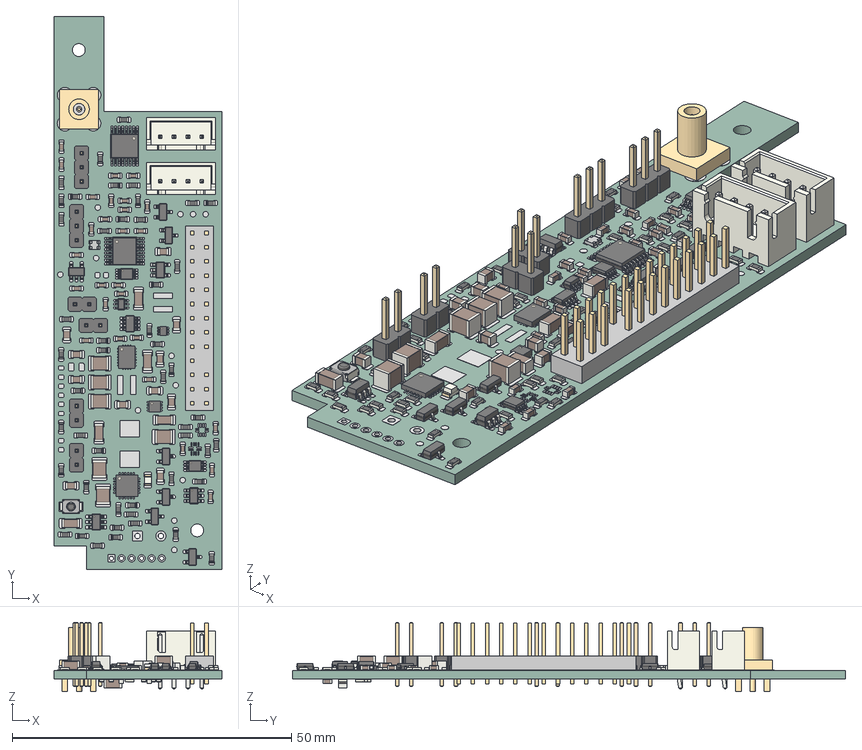
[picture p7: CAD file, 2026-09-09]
hardware/system-review/electrical/placement-checkpoint-v2/Trimix_Main_PCB_Placement_Checkpoint.step
30.0 x 99.0 x 12.4 mm
C_0603_1608Metric x 29
C_1206_3216Metric x 6
R_0603_1608Metric x 56
C_1210_3225Metric x 6
C_0805_2012Metric x 11
SOT-23 x 6
PinHeader_1x03_P254mm_Vertical x 2
JST_B4B_XH_A x 2
SW_SPST_B3U-1000P
SOT-23-5 x 2
LED_0805_2012Metric
PinHeader_1x02_P254mm_Vertical x 4
Amphenol RF 142138 - drawing reconstruction; mating details reference
(Unsaved)
SOT_563
SOT-23-6 x 2
VSSOP-8_2.3x2mm_P0.5mm x 2
TSOT-23-8
Samtec HTSW-113-07-L-D-007 nominal drawing reconstruction
DFN_8_1EP_2x2mm_P05mm_EP07x13mm
DFN-14-1EP_3x4mm_Pitch0.5mm
TSSOP-16_4.4x5mm_P0.65mm x 2
Texas_RTW_WQFN-24-1EP_4x4mm_P0.5mm_EP2.7x2.7mm
SOT-363_SC-70-6
Trimix_Analyzer_Placement_Checkpoint_pad
Trimix_Analyzer_Placement_Checkpoint_PCB

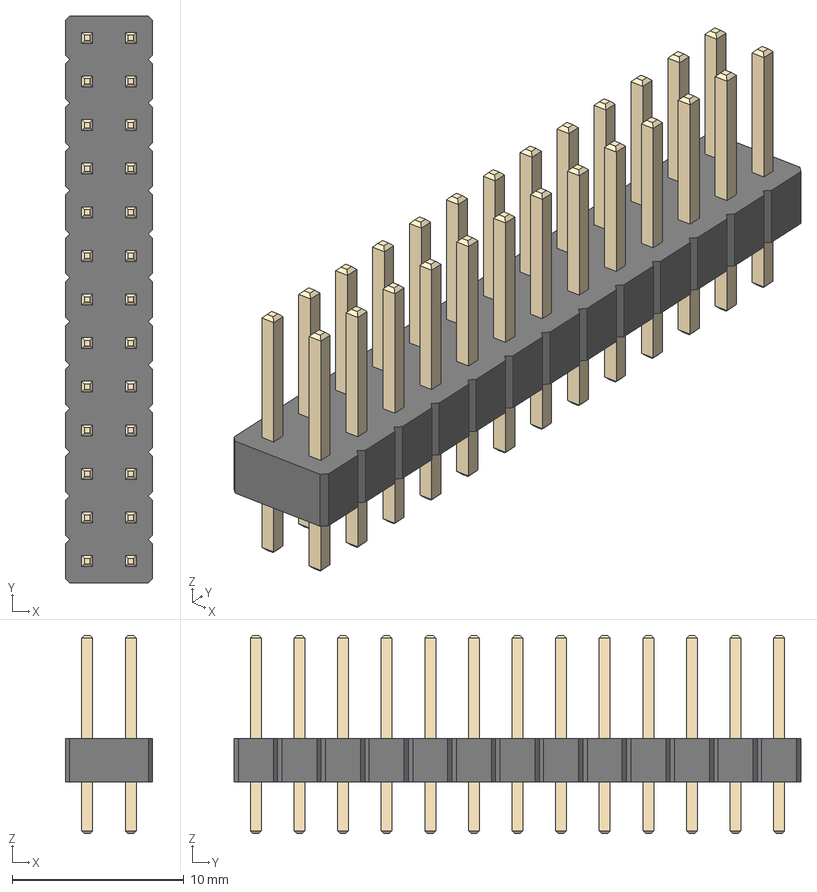
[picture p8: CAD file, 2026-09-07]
hardware/pcb/integration/verification/main-component-frame.step
5.08 x 33.0 x 11.5 mm

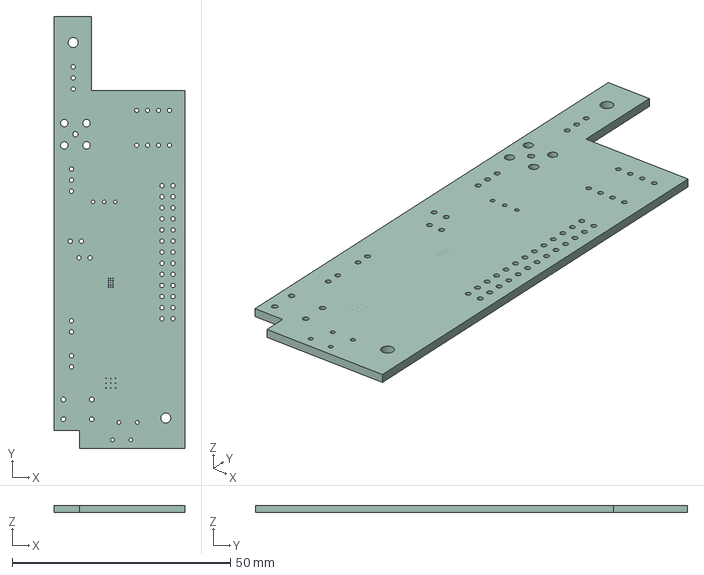
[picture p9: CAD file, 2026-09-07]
hardware/pcb/integration/verification/main-board-only-frame.step
30.0 x 99.0 x 1.51 mm

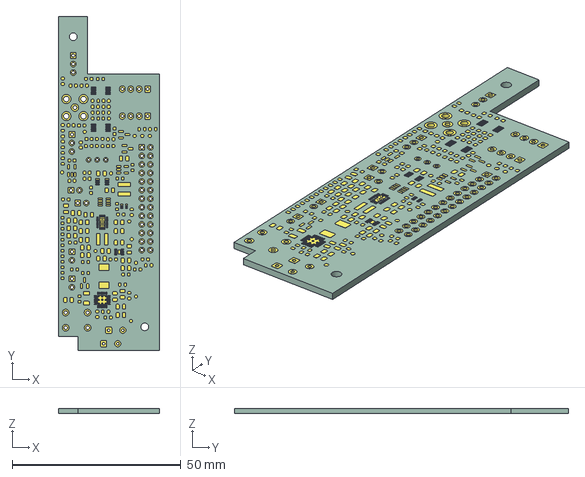
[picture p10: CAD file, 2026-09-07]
hardware/pcb/integration/verification/main-copper-frame.step
30.0 x 99.0 x 1.58 mm
Trimix_Analyzer_pad
Trimix_Analyzer_PCB

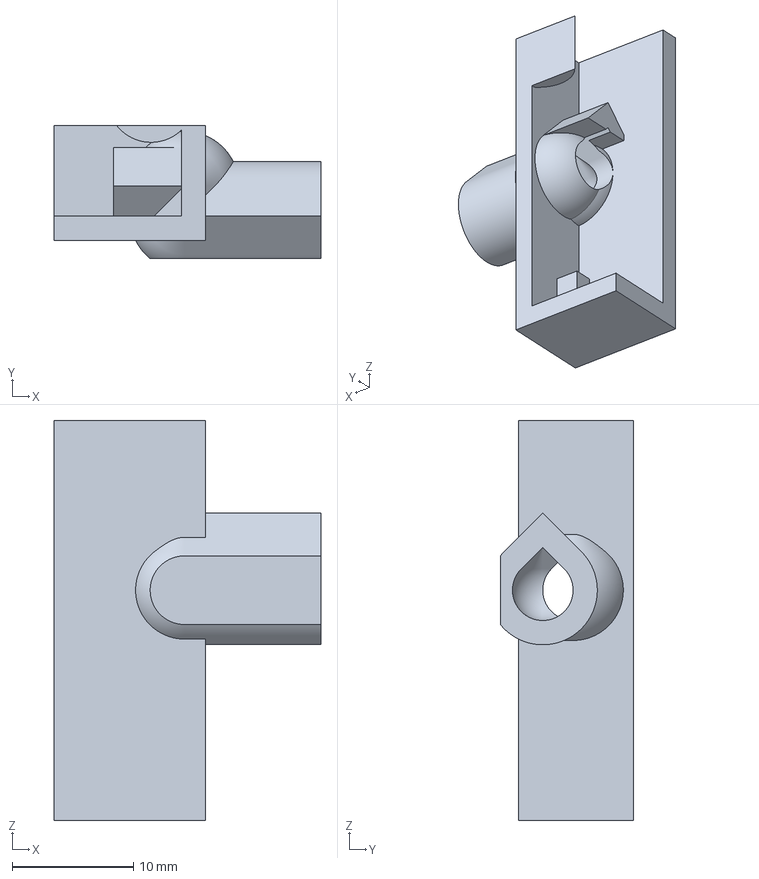
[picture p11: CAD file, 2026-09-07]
hardware/cad/rev04/3d-print/printing/bambu-studio/petg/C01_gas_inlet/C01_gas_inlet_petg.3mf
22.0 x 11.0 x 33.0 mm

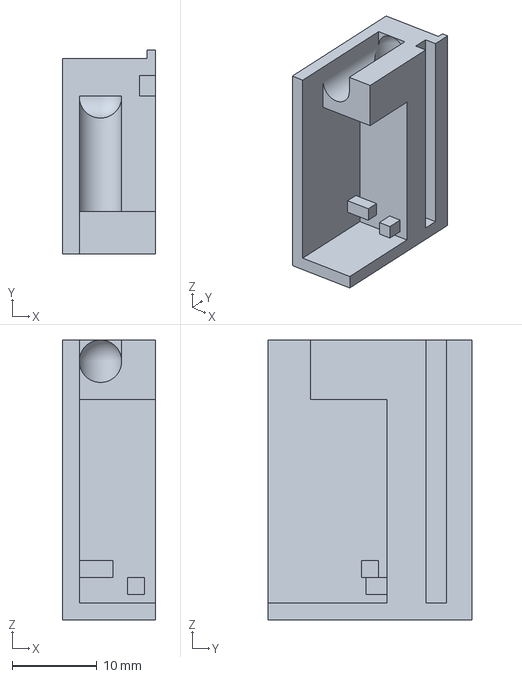
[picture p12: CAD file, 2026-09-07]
hardware/cad/rev04/3d-print/printing/bambu-studio/petg/C02_gas_return/C02_gas_return_petg.3mf
11.0 x 24.0 x 33.0 mm

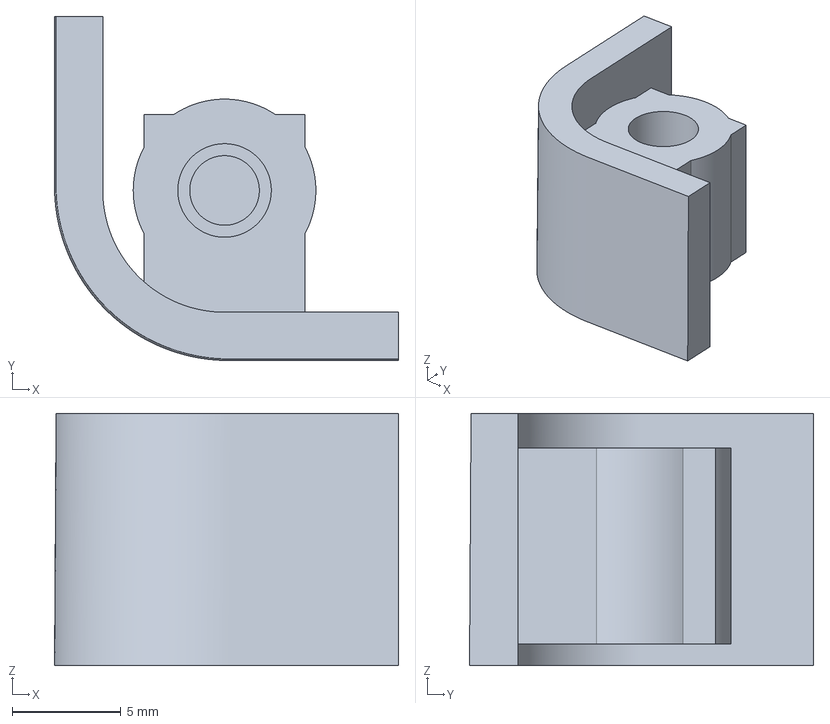
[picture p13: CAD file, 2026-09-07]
hardware/cad/rev04/3d-print/printing/bambu-studio/petg/C03_m3_boss/C03_m3_boss_petg.3mf
15.8 x 15.8 x 11.6 mm

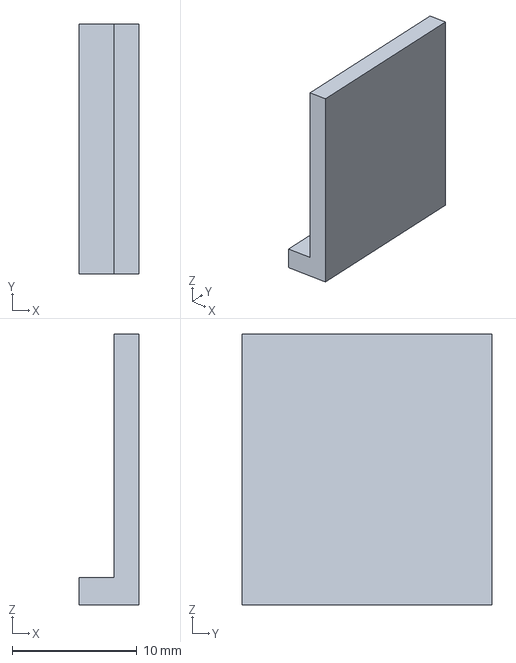
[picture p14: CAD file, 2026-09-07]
hardware/cad/rev04/3d-print/printing/bambu-studio/petg/C04_holder_rail/C04_holder_rail_petg.3mf
4.80 x 20.0 x 21.7 mm

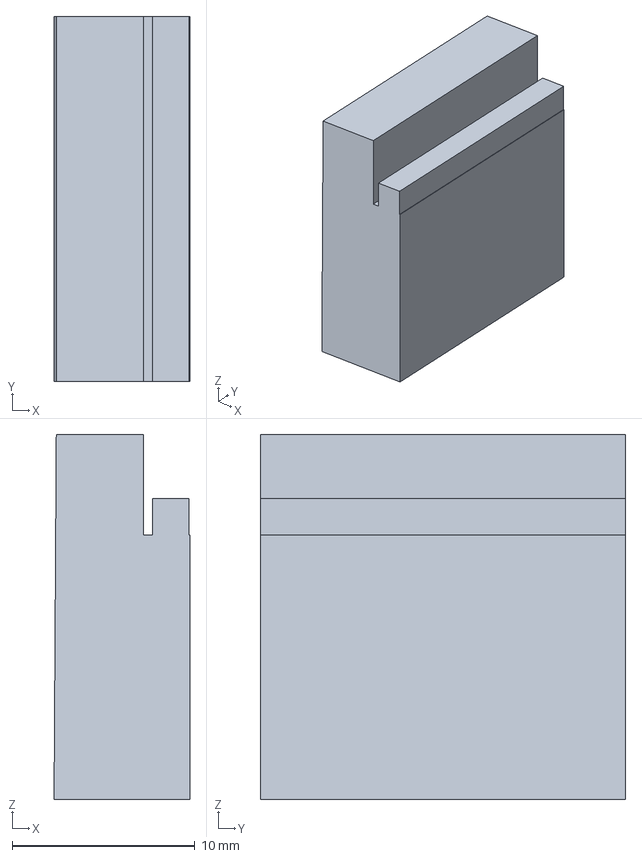
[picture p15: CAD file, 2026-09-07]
hardware/cad/rev04/3d-print/printing/bambu-studio/petg/C05_display_lip/C05_display_lip_petg.3mf
7.45 x 20.0 x 20.0 mm

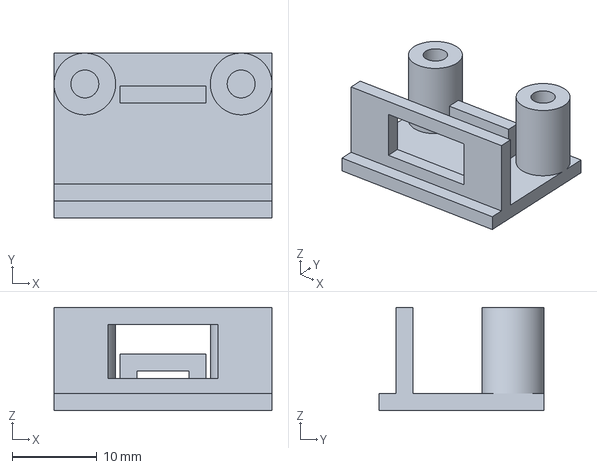
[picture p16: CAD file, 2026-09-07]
hardware/cad/rev04/3d-print/printing/bambu-studio/petg/C06_usb_m2_frame/C06_usb_m2_frame_petg.3mf
25.8 x 19.5 x 12.2 mm

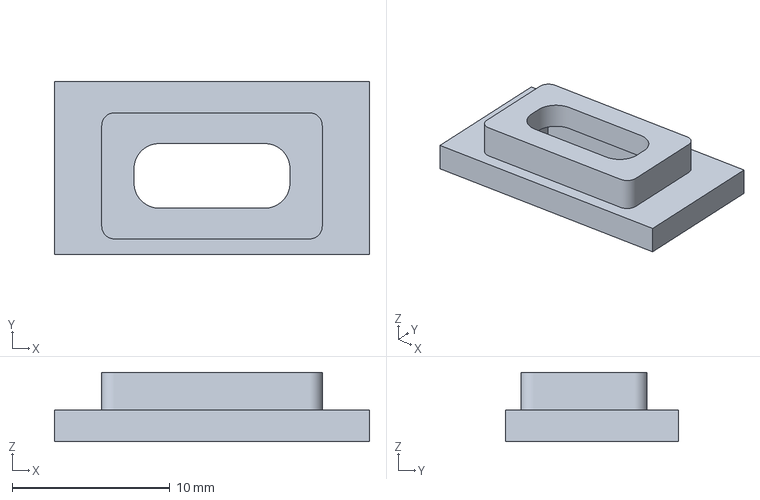
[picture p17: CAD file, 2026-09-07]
hardware/cad/rev04/3d-print/printing/bambu-studio/petg/C07_usb_bezel/C07_usb_bezel_petg.3mf
20.0 x 11.0 x 4.40 mm

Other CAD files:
hardware/system-review/electrical/routing-candidate/final-cleanup/before-final-promotion/electrical-exports/Trimix_Main_PCB_Reviewed_Placement.step
hardware/system-review/mechanical/inputs/frozen-placement-20260907/Trimix_Main_PCB_Reviewed_Placement.step
hardware/system-review/mechanical/inputs/main-placement-first-pass/Trimix_Main_PCB_Reviewed_Placement.step
hardware/cad/Trimix_Enclosure_A1.f3d
hardware/cad/Trimix_Enclosure_A1.step
hardware/cad/rev03/Trimix_Enclosure_A2.f3d
hardware/cad/rev03/Trimix_Enclosure_A2.step
hardware/cad/rev04/3d-print/Trimix_Enclosure_A3_PrintReview.f3d
hardware/cad/rev04/3d-print/Trimix_Enclosure_A3_PrintReview.step
hardware/cad/rev04/3d-print/printing/bambu-studio/petg/C08_ao2_thread/C08_ao2_thread_petg.3mf
hardware/cad/rev04/3d-print/printing/bambu-studio/petg/TMX-A3-P01/TMX-A3-P01_petg.3mf
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

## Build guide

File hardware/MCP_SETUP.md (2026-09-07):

# KiCad MCP connection

Installed on this Mac on 2026-09-05 from
[mixelpixx/KiCAD-MCP-Server](https://github.com/mixelpixx/KiCAD-MCP-Server),
commit `aa53d52c2e37a13cb3574a6e0acf2c728b4d6bfb` (server version 2.7.0).

The installation is at `~/.codex/mcp-servers/kicad`. The `kicad` STDIO server
is enabled in `~/.codex/config.toml`. It uses the installed Node 25.5.0 and
an isolated environment built with KiCad 10.0.6's bundled Python 3.9. It
does not require an API key. Existing Codex settings were preserved; a
private config backup is stored inside the installation directory.

Compatible Node dependency updates were applied, the server was built, and
development dependencies were pruned. The resulting runtime audit reported
zero known vulnerabilities at installation. The source lockfile records
those changes; `requirements-codex.lock.txt` records additional Python
package versions. No KiCad application files were modified.

## Enable in the desktop session

In Codex, open **Settings → MCP servers** and restart the **kicad** server.
If it does not appear yet, reopen Codex to load the updated configuration.
The current conversation's tool inventory may need to refresh after restart.
Computer-use tools cannot operate Codex's own settings window.

## How schematic editing works

This server edits `.kicad_sch` files. The tested backend reports `swig`,
with live GUI synchronization disabled. Save any work in the KiCad editor
before asking for external edits, and reopen the schematic afterward to
see changes. This setup has not established live PCB IPC synchronization.

## Verified operations

- MCP initialization and discovery: server 2.7.0, 229 tools.
- Read the imported schematic: 29 physical components plus 22 power symbols
  and one drawing-frame symbol.
- Add and remove a temporary property on a disposable copy: final file
  byte-for-byte identical to the original; KiCad netlist export passed.
- Edit passive pin types in the project library and refresh the schematic
  cache through MCP. KiCad ERC and netlist export passed, with the remaining
  circuit findings documented in `README.md`.

For sessions whose native MCP inventory has not refreshed yet, the local
installation includes `mcp-local-client.mjs`, a small STDIO SDK client used
for these checks. It accepts newline-delimited tool calls on standard input.
Its logs and discovery inventory are written under `/tmp`.

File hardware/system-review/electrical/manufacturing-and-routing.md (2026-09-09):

# Manufacturing and routing contract — NOT RELEASED

Target process: JLCPCB four-layer1.6mm main PCB, nominal1oz outer copper, ENIG; separate two-layer0.60mm GCT daughterboard. The native main board binds the published JLC04161H-3313 stackup:35µm outer copper,15.2µm inner copper,0.0994mm prepreg each side and1.265mm core. Published layer thicknesses sum to1.5642mm; nominal finished board thickness remains1.6mm, with the supplier's finished-thickness tolerance kept separate. See [stackup source and native binding](stackup-review.md). Vendor confirmation in the actual quote, board tolerances, panel/support carrier and assembly process remain pending. No fabrication files should be purchased from this draft.

Layer intent: F.Cu components/short sensitive traces and power loops; In1.Cu continuous ground return; In2.Cu allocated power/distribution and carefully reviewed remaining signals, with individually anchored ground regions beneath the backside OVP cluster, tied by vias to continuous In1; B.Cu additional routing and any explicitly CAD-qualified low-profile parts. Do not split analogue return paths or let switch-node copper pass beneath high-impedance sensor signals. Power, heater and digital return currents must return through broad ground to the source without sharing long sensor-return traces.

Keep AO2/JJ-CCR raw differential inputs short, shielded by continuous ground and away from switching nodes. Preserve SMB shell as differential negative. Keep each ADC input filter local and symmetric. Review ADC reference/supply decoupling and I2C settling against the actual harness. No arbitrary global autorouter output qualifies noise or thermal performance.

Power placement/routing requirements: BQ PMID cap/ground, SW/inductor/VSYS cap, BAT cap andREGN/BTST must form short loops. TPS63020 input/output banks and both inductor pins require broad paths with short pad necks. Follow L101's central trace/via keepout; copper pour is allowed only as its manufacturer drawing states. TPS61023 switch path must be compact. Input source-limiter and OVP divider/slew capacitor must stay local. A placement that fits courtyards but scatters these passives into the analogue area is rejected.

Main default routed copper clearance remains0.20mm and board-edge clearance0.50mm. Only same-package manufacturer pad-to-pad gaps at U701/U703/U801/U111/U112 have explicit0.15mm exceptions. Those do not authorize arbitrary traces at smaller clearance. Fine package escape and thermal pad processes must be reviewed individually. U101/U201 thermal0.20mm drill features need factory fill/cap acceptance if retained; do not use open vias in paste and assume hand soldering is safe. JLC published capability is evidence of a process option, not a production quote.

Ordinary signals use 0.15 mm traces and 0.50/0.25 mm through vias. Explicit short U111 pin escapes use 0.125 mm traces, and the listed dense U101/U110/U115 escape points use 0.45/0.20 mm through vias. Both routed via sizes retain 0.125 mm nominal annulus; power distribution uses separately reviewed larger vias. The native rules retain 0.20 mm electrical clearance. `audit_routing_geometry.py` checks every sub-0.15 mm track against the U111 rectangle and every sub-0.25 mm routed drill against the explicit coordinate list, preventing the net-scoped KiCad exceptions from silently becoming broad permissions. All thermal drilling and fabrication acceptance remain separate.

Exact RPW0010A U115 land is asymmetric, with two central IN/OUT lands and no center-ground pad. Its stencil/paste and same-number compound lands require CAM/assembly inspection. U114 uses exact leaded DDC6 Q1 lands; the older WCSP part and industrial C substitutes are superseded. Do not replace its part with a similarly named500mA-minimum switch.

Use native DRC, schematic parity, net counts, copper connectivity, visual layer checks and current/thermal calculations after every geometry/routing change. Unconnected items remain failures to complete routing even when geometric violations are zero. Board STEP exports only establish nominal geometry; use the maximum-height contract and actual harness models too.

Hybrid assembly: factory reflow for QFN/HotRod/exposed-pad parts, matched network and fine-pitch ADCs; larger SMT/THT may be populated by the user with microscope, iron and hot air after inspection. Produce exact grouped BOM/CPL and agree populated/DNP lists with the factory. BOM standard candidates are sourced but stock and substitutions are not approved by this review. Print a1:1 pad/part fit sheet before release.

The frozen main candidate is now fully connected with zero native DRC findings and zero schematic mismatches; see `routing-candidate/sensitive-layout-refinement/frozen-local-bundle/review/geometry-handoff-manifest.json`. It has 2247 track segments and 300 routed vias. The exact U115.3 CC escape at (13.6,89.775) uses a 0.40/0.20 mm filled/capped via with 0.10 mm nominal annulus and a coordinate/pin-scoped 0.12 mm B-copper exception. Actual neighbour gap is 0.125 mm. Only this reviewed site has that annulus/clearance exception; original SMT mask/paste aperture is retained, extension masked, front tented. U115.1 at (13.6,91) and R125.1 at (17.95,87.925) use separately declared 0.50/0.25 mm VIPPO. All three require resin fill, copper cap on both faces, flatness and assembler approval. Ordinary open vias are not substitutes. The manufacturer-capability review is in `vippo-process-review/`; the exact quote remains a release hold.

Final digital receipts include 126 independent CAM checks, 29 preserved power/monitor witnesses, 35 connected local witnesses, continuous In1 with 107 ground anchors, and 11 anchored In2 regions with 21 anchors. The source-matched CAD disposition is bound in the promotion manifest; actual cable/part fit remains a physical qualification. Dynamic current/thermal/ripple/EMI testing remains separate from digital routing completion. The raw ERC report retains one precisely guarded TI-permitted LM66100 ST-to-ground exception. Gerber and assembly uploads are not authorized purchase actions in this review.

The frozen assembly ledgers separate 27 factory components, 118 manual components, 6 DNPs and 18 PCB/harness features. All 169 references have a value/MPN/coordinate map; 141 have visible reference silk. The factory list includes ICs, RN501, actual 0402 parts and Q110's manufacturer-land implementation. The native full-board paste output includes manual/DNP apertures for export-equivalence review and **must not be used as an approved factory stencil**. The exact 27-part factory-only aperture subset passed independent geometry comparison; obtain assembler approval before ordering.

The BQ load-current switch path stays on F.Cu. A single coordinate-scoped 0.20 mm B.Cu C103 bootstrap branch runs from (15.08,80.7) to the ordinary 0.50/0.25 mm via at (15.75,81.35); it is the only permitted rear BQ_SW branch. Three negative controls confirm that the routing validator rejects an altered endpoint, altered width or move onto the inner reference layer. No general switch-net exception is granted.

C103 and R702 are true 0402 factory parts; C107 is the actual 47 µF/10 V TDK 0805 part with manufacturer-derived reflow lands and belongs in factory assembly. R504 remains the same 0603 manual part, now on the rear, and must be installed before the carrier. Use the current [reference and assembly lists](main-final/README.md) and [marked-inductor orientation supplement](main-final/assembly-notes.md). All 24 package thermal bores plus the three signal VIPPO sites require resin fill and copper cap on both faces. Their exact 27-hole list and factory-only paste subset still need supplier flatness, process, stencil and two-sided reflow approval; published capability alone does not qualify them.

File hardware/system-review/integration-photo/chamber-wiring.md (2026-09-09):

# Chamber cable and dry-side termination

The intended arrangement is one sealed pigtail attached to the removable chamber. Connectors on the main board remain on the dry side. Disconnect the battery, then the chamber harness before withdrawing the chamber. Strain relief must carry cable loads without pulling on sensor leads, solder joints or the seal.

| Main-board contact | Remote termination | Conductors through chamber closure |
|---|---|---:|
| J501.1 HE_3V0 | MD62 outer compensator lead | 1 |
| J501.2 HE_SENSE | MD62 two middle leads joined locally and insulated | 1 |
| J501.3 GND | MD62 outer detector lead; detector body carries the square marking | 1 |
| J601.1 BME_VIN, .2 GND, .3 BME_SCL, .4 BME_SDA | Corresponding identified BME280 breakout terminals | 4 |
| J701.1 CO_5V28, .2 GND, .3 CO_TX_CABLE, .4 CO_RX_CABLE | Corresponding verified ZE07-CO supply/ground/UART terminals; TX/RX naming must be checked from the actual module's perspective | 4 |

This is **11 insulated conductors**, assuming the MD62 midpoint joint is made near the sensor. The four physical MD62 leads do not require four separate PCB contacts. This follows the [Winsen MD62 V1.3 manual, connection caution 1.6](https://www.winsen-sensor.com/d/files/thermal/md62.pdf): the two central leads form the output node, with detector and compensator outer leads connected to opposite supply ends. The CAD rods are illustrative and do not assign physical pin numbers. Verify the actual detector marking, lead order and unpowered element continuity before soldering. Do not treat wire colours as a pinout.

The selected oxygen sensor's electrical end remains in the dry enclosure. Its cable runs directly to J401 or J402 and does not add conductors to the wet-chamber feedthrough. Preserve the approved J402-above-J401 arrangement and clearance for the JJ right-angle plug.

## Closure and routing constraints

The earlier CAD bore is Ø4.4 mm with a Ø8.4 mm collar. It is an unqualified sealing provision. Eleven contact positions do not prove that eleven actual wires fit: insulation outside diameter, shared jacket, joints, potting gap, bend radius and strain relief must be specified. For example, eleven round 1.2 mm insulated wires occupy 12.44 mm² before packing gaps, compared with 15.21 mm² bore area; area alone does not establish a packable or sealable bundle. Do not force a bundle through or enlarge the bore without rechecking the collar's structural material and removal path.

Keep the wet-side conductors supported away from the active sensor faces, hot MD62 surfaces and the nominal 5 mm gas route. The seal material and cure products must be compatible with all sensors and the sample path; a generic silicone or epoxy is not automatically qualified. Keep connector bodies and disconnectable joints out of the wet path unless separately qualified.

Dry-side routing needs a complete model from the closure to each mated PCB plug, including bends and a service loop. A clear line or a short local connector envelope is insufficient. Record actual wire identity/OD, cut length, bend limit, end pin mapping, joint insulation, strain relief, seal process and continuity/leak results. All physical wiring, sealing, thermal and gas-response tests remain pending.

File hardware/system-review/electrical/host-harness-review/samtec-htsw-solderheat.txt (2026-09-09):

Project Number: Lead Free                          Tracking Code: TC0310-Lead Free-0120
Requested by: John Schmelz                      Date: 3/4/2003          Product Rev: AU
Part #: HTSW-150-07-L-D                                     Lot #: NA            Tech: J.S.           Eng: J.S.
Part description: HTSW                                                                        Qty to test: 10
Test Start: 3/4/2003         Test Completed: 3/6/2003

               Perform Solder Heat Resistance using three temperature profiles: 230°C, 260°C and 280°C.
                                                   Summary Report

                                                   PART DESCRIPTION

                                                        HTSW-150-07-L-D

            Tracking Code: TC0310-Lead Free-0120                                         Part #: HTSW-150-07-L-D
                                                        Part description: HTSW

                                                        CERTIFICATION

All instruments and measuring equipment were calibrated to National Institute for Standards and Technology (NIST)
traceable standards according to IS0 10012-l and ANSI/NCSL 2540-1, as applicable.

All contents contained herein are the property of Samtec. No portion of this report, in part or in full shall be
reproduced without prior written approval of Samtec.

SCOPE
              Perform Solder Heat Resistance using three temperature profiles: 230° C, 260° C and 280° C.

APPLICABLE DOCUMENTS
         Standards: EIA Publication 364

TEST SAMPLES AND PREPARATION.
    1) Parts are visually inspected for cleanliness.

FLOWCHART

                                  TEST            260 °C               280 °C        230 °C
                                  STEP                                GROUP D       GROUP E
                                                                                     Control
                                    01            1 Pass                1 Pass        1 Pass
                                                Solder Heat   Group   Solder Heat   Solder Heat
                                    02          Resistance    A       Resistance    Resistance
                                    03           2nd Pass
                                                Solder Heat   Group
                                    04          Resistance    B
                                    05           3rd Pass
                                                Solder Heat   Group
                                    06          Resistance    C

                              Solder Heat Resistance (Visual): Blistering, Distortion
                              (Bowed or Twisted), Discoloration

File: J:\QA LAB\Test Programs\TC0106-0334\tc0106—0334.doc               Form 01 Rev 00                             Page 2 of 8

      Tracking Code: TC0310-Lead Free-0120                              Part #: HTSW-150-07-L-D
                                             Part description: HTSW

OVEN THERMAL PROFILE (Control):
     1) The Following Thermal Profiles were used to stress the parts.

      Tracking Code: TC0310-Lead Free-0120                            Part #: HTSW-150-07-L-D
                                             Part description: HTSW

OVEN THERMAL PROFILE, SUPPLEMENTAL TEST:
Solder Heat Resistance (Visual) at 230 °C

      Tracking Code: TC0310-Lead Free-0120                            Part #: HTSW-150-07-L-D
                                             Part description: HTSW

OVEN THERMAL PROFILE, SUPPLEMENTAL TEST Continued:
Solder Heat Resistance (Visual) at 280 °C

      Tracking Code: TC0310-Lead Free-0120                            Part #: HTSW-150-07-L-D
                                             Part description: HTSW

                                    ATTRIBUTE DEFINITION

SOLDER HEAT RESISTANCE (Visual):
     1) Blistering
        a) Pass/Fail
     2) Distortion
        a) Bowed or Twisted
     3) Discoloration
        a) Pass/Fail

          Tracking Code: TC0310-Lead Free-0120                             Part #: HTSW-150-07-L-D
                                                  Part description: HTSW

                                                       RESULTS

Solder Heat Resistance, 260 °C Thermal Stressing
    • Blistering
            o One Thermal Stress--------------------------------Pass
            o Two Thermal Stresses-----------------------------Pass
            o Three Thermal Stresses ---------------------------Pass
    • Distortion
            o One Thermal Stress--------------------------------Pass
            o Two Thermal Stresses-----------------------------Pass
            o Three Thermal Stresses ---------------------------Pass
    • Discoloration
            o One Thermal Stress--------------------------------Pass
            o Two Thermal Stresses-----------------------------Pass
            o Three Thermal Stresses ---------------------------Pass

Supplemental Tests

Solder Heat Resistance, 230°C Thermal Stressing
    • Blistering
            o One Thermal Stress--------------------------------Pass
    • Distortion
            o One Thermal Stress--------------------------------Pass
    • Discoloration
            o One Thermal Stress--------------------------------Pass

Solder Heat Resistance, 280 °C Thermal Stressing
    • Blistering
            o One Thermal Stress--------------------------------Pass
    • Distortion
            o One Thermal Stress--------------------------------Pass
    • Discoloration
            o One Thermal Stress--------------------------------Pass

        Tracking Code: TC0310-Lead Free-0120                            Part #: HTSW-150-07-L-D
                                               Part description: HTSW

                         EQUIPMENT AND CALIBRATION SCHEDULES

Equipment #: THL-01
Description: Temperature/Humidity Chart Recorder
Manufacturer: Dickson
Model: THDX
Serial #: 9316255
Accuracy: Temp: +/- 1C; Humidity: +/-2% RH (0 - 60%) +/- 3% RH (61 - 95%).
… Last Cal: 7/15/02, Next Cal: 7/15/03

Equipment #: OV-5
Description: Nitrongen Purge IR Reflow
Manufacturer: Vitronics Soltec
Model: XPM-730
Serial #: XN 70328
Accuracy: + / - 5° C

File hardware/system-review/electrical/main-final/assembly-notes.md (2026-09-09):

# Assembly orientation supplement — source 0962ad86

Use this supplement with the exact BOM, placement file and native Fab view. It does not change any placement or approve an assembly order.

The Coilcraft inductors are electrically nonpolar, but their winding orientation matters for switching noise. Fit the terminal on the manufacturer's **C-mark / short-lead side to native pad 2**, which is identified by the extra line on the custom Fab drawing. Do not infer that orientation from a generic STEP model or from an unmarked square body.

| Reference | Purchased series | Native centre / rotation | C-mark terminal must face |
|---|---|---|---|
| L701 | XGL4020-102MEC | (19.5,50.65), −90° | Pad 2 at (19.5,51.835), CO_SW; toward increasing PCB Y, toward U701 |
| L201 | XGL4030-152MEC | (13,66), 180° | Pad 2 at (11.815,66), TPS63020 L2 switch net; toward decreasing PCB X |

Coordinates are top-view PCB millimetres. The manufacturer describes the marked short lead and preferred switching-node connection in the [XGL4020 drawing](https://www.coilcraft.com/pdfs/xgl4020.pdf) and [XGL4030 drawing](https://www.coilcraft.com/pdfs/xgl4030.pdf). Inspect the real markings before soldering; both inductor switch pads and the selected winding orientation still require waveform/noise qualification in the prototype.

Fit manual rear R504 before installing the PCB in its carrier. C103 and C107 are factory rear-side components. Confirm that the approved carrier opening corresponds to this exact board and maximum-height contract; do not force the board down against a component. Rear test pads require board removal for access.

Leave J104's charging-arm shunt open. The matched Samtec header/socket key configuration and remote Guition power entry remain unresolved supplier/interface gates. The factory-only paste subset, 27-hole fill/cap list, side/rotation convention and two-sided reflow/inspection must be accepted by the assembler before ordering.

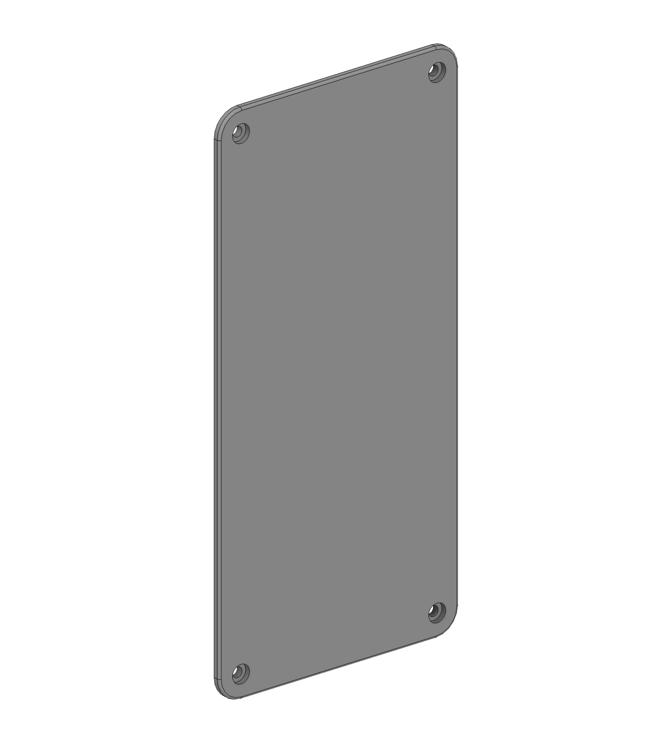
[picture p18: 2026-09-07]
hardware/cad/rev04/3d-print/previews/TMX-A3-P02.png

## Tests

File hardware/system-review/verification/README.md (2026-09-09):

# Combined digital verification

## Current SD integration checkpoint — 2026-09-08

Use the [SD integration review](../software/sd-card/README.md) and its
[source-bound receipt](../software/sd-card/evidence/receipt.json) for the current
firmware. The final source-bound runs report **53/53 CTest targets normally and with
ASan/UBSan, 98 repository checks, and 22 portable Clang units**, plus scoped
ThreadSanitizer checks of the logger and actual storage/maintenance coordinator.
Both P4 images compile without warnings and fit their unchanged OTA partitions.
These counts overlap; they are not a sum of independent test cases.

The pre-v3 application is 2,051,056 bytes in a 4,194,304-byte slot; the v3
application is 2,056,432 bytes in a 6,291,456-byte slot. Linker section sizes do
not establish live free heap during simultaneous display, radio and card use.
The final receipt binds the actual sources, binaries, tests and patched Hosted
inputs. Physical card operation, shared-controller timing, peak power and
power-loss behavior remain pending.

Independent review corrected three reachable failures before this final run:
combined file-close/unmount failure, calibration values labelled with a different
revision, and analysis/calibration screen-event ordering. Negative controls fail
against the old behavior. The final log records both applied O2 and He revisions
atomically with their conversions; no persistent NVS layout changed.

The photograph and 13.4 mm front-glass-to-header-tip measurement require a new
mechanical checkpoint. Earlier v11 connector clearance and aggregate evidence
receipts do not qualify the corrected connector positions or complete looms.
See [the registration and routing review](../integration-photo/README.md).

## Preserved pre-SD verification

The following describes the archived baseline at
[before-sd-storage/](before-sd-storage/), not the current firmware sources.
Its old build counts and hashes remain point-in-time evidence. The original
verification README is retained inside that snapshot.

`software-final.json` binds the final software checks, application binaries,
source files and logs by SHA-256. All 144 recorded firmware inputs remained
unchanged during the two final builds. This is software evidence, not an order
release or a substitute for the final electrical/mechanical checks.

| Check | Result |
|---|---|
| P4 pre-v3 and P4-v3 applications | Passed digitally; both compile and fit their existing OTA slots |
| Routine CTest suite | 50/50 passed digitally |
| Same suite with AddressSanitizer/UndefinedBehaviorSanitizer | 50/50 passed digitally |
| Repository verification script | 95/95 passed digitally |
| Firmware-to-schematic logical contract | 70 assertions passed digitally, plus eight deliberately corrupted header cases and five disconnected-feedback cases |
| Clang static analyzer | 18 portable production units, no diagnostics |
| Actual ESP storage initialization branch with injected low-level NVS | 35 assertions; five isolated startup states, included in CTest |
| Storage/maintenance races | Separate ASan/UBSan and ThreadSanitizer receipts under `software/ota/` |
| Startup acceptance versus timeout | 1,000 contested rounds in each sanitizer configuration; one winner only |
| USB permission policy | 23 named assertions under ASan/UBSan, hardware-only latch clearing, short charger IRQ, failed rearming, maintenance and stable polling |
| Input isolation and charging standby | 460 scoped ASan/UBSan assertions; four worker maintenance races plus concurrent backlight TSan workload; actual worker with documented hardware boundaries |
| Attachment-event races | Three actual-worker swap boundaries plus two archived failing controls; initial CC event clears before detection and legacy post-result checks are read-only |
| Legacy charging-port endurance | Six virtual hours each DCP/CDP without repeated detection or charge-enable; missed health interval, detach, sticky replug and detector reset revoke permission |
| Selected-sensor publication | Seven regressions prevent old conversions/resets from replacing new setup history |
| CO operating-condition gate | 44 focused assertions in normal and ASan/UBSan runs; includes the actual acquisition adapter, stale/range rejection, invalid-value clearing and optional-sensor startup health |
| UI review | 11 simulator framebuffer captures inspected, including unavailable battery/storage and faulted air-check inputs |

The repository count includes the CTest invocation; these numbers are not a
sum of independent test cases. Repeated runs are not additional fault coverage.
Specific assertion counts and exact scope are recorded in each subsystem's
receipt. Older receipts remain point-in-time evidence and can have superseded
source hashes.

Both current incremental ESP-IDF builds completed without compiler warnings. An earlier compilation of the vendor TE-disabled display macro emitted seven missing-member-initializer warnings: `gpio_num = -1` is explicit and other aggregate members are zero initialized. No warning suppression or vendor modification was made. Current logs and per-build counts are in the receipt. Before-standby, before-input-isolation, before-legacy-endurance-fix and before-co-environment artifacts preserve the relevant earlier checkpoints.

The input-isolation correction keeps unqualified SDP, unknown and proprietary sources in verified BQ HIZ. Recognized sources reconnect only through fresh CC/BC health, bounded power-good checks and hardware authorization. Stable legacy classifications belong to one continuously verified attachment: their original observation time is preserved and a missed three-second control-health interval revokes them. A longer actual-worker test caught and corrected the earlier 30-second redetection policy causing a stable charger to shut down. See [input isolation](../software/power/input-isolation/README.md) and [the endurance correction](../software/power/input-isolation/legacy-endurance-review/README.md).

Standby keeps the source worker running with a dark screen only when a future qualified profile and fresh source/battery evidence permit it. Production still uses `CommissioningInhibited`, and J104 stays OPEN. Cold/depleted-pack recovery remains a separate order hold; software tests do not prove that a powered-off host can bootstrap from the default USB current limit.

The physical peripheral adapters are compiled by ESP-IDF. Host tests inject
transport, storage, timing and startup failures into production logic. They do
not execute a real radio, ESP flash power loss, bootloader rollback, analogue
sensor, electrical bus, charging cycle, heater temperature or enclosure seal.
Actual shared-bus scheduling and aggregate SDK call duration remain unmeasured.

Ordinary application updates remain separate from bootloader/partition/C6
recovery operations. No device was flashed, no update installed and no release
published by this review. The two application-only binaries in
`../software/firmware/` target this reviewed hardware contract; they are build
artifacts, not permission to bypass unfinished hardware release gates.

The current firmware/schematic association was rerun after the reviewed `0962`
board and `b04e` netlist became canonical. `before-refined-hardware-contract/`
preserves the preceding verified software receipt and logical report; only the
hardware-associated logical receipt was refreshed. The build binaries and their
source inputs were not changed or rebuilt for that association.

`verify_review_evidence.py` checks current source/output hashes across the
firmware, canonical PCB, independent CAM, native Fusion reopen, bounded fit
checks, diagnostic slices and six-page interface packet. Its generated
`evidence-integrity.json` keeps engineering acceptance and physical/order holds
separate. A matching hash is evidence of byte identity, not proof of a part's
rating or a physical result. The final STEP numerical disposition is recorded
in the mechanical checkpoint alongside the exact native archive.

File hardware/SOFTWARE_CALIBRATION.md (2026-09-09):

# Software calibration — existing sensors, upgraded electronics

This revision keeps AO₂, R17JJ-CCR and MD62. It replaces the two ADC chips and the helium trimmer, and adds real acquisition, individual calibration records and a touchscreen workflow. **The accuracy targets remain unproven: ±0.2 percentage points O₂ and ±0.5 points He over the conditions actually tested.** No physical gas measurements were performed during this implementation.

The board remains under active electrical, routing and fit review. Use the [current system-review package](system-review/README.md) for order status and source-bound checks. Showcase, production printing and purchasing remain paused. The [previous version of this document](system-review/baseline-docs/SOFTWARE_CALIBRATION.md) is preserved.

## What changed on the board

| Marking | Part / purpose |
|---|---|
| U401 | ADS122C04IPWR, TSSOP-16; reads the selected oxygen input, with both inputs available during an explicit known-air check; address **0x40** |
| U502 | ADS122C04IPWR, TSSOP-16; reads MD62 and voltage diagnostics; address **0x41** |
| RN501 | Vishay **ACASN2001U2001P1AT**, two matched 2 kΩ resistors making a fixed half-excitation reference |
| RV501, R502, R503 | Removed; the matched array replaces this adjustable branch |
| J401 / J402 | Existing AO₂ / JJ-CCR connectors in the approved positions; no sensor replacement |
| J501 | MD62 connection; regulated **3.0 V** excitation retained through TPS7A2030PDBVR |
| R506 / R507 | 680 Ω helium input resistors; acquisition profile revision 2 |

RN501 is a selected manufacturer order code; distributor stock and lead time still need checking. Its custom lands follow Vishay's IEC recommendation. Its nominal 3D body is drawing-derived, not exact manufacturer CAD. Use the [current part ledger](system-review/electrical/part-qualification.csv), native board markings and [passive analogue analysis](system-review/electrical/analogue-simulation/README.md). Earlier placement maps are historical checkpoints, not the current purchasing list.

The ADC samples a voltage. Software subtracts the measured zero offset and applies a measured sensitivity. A fixed reference is sufficient because software can correct the offset **provided the original voltage is inside the ADC's usable range**. It cannot recover a clipped signal, identify an unknown gas, or correct an unmeasured environmental dependency.

## Acquisition settings

Both converters use the internal 2.048 V reference, normal **20 samples/s conversion rate**, single-shot operation, and no IDAC or burnout excitation currents. AO₂ and JJ-CCR use gain 8 with the PGA enabled (±256 mV). MD62 uses gain 1 with PGA bypass (±2.048 V). Voltage diagnostics use gain 1 with PGA bypass.

The driver resets and checks registers, writes and reads back each configuration, allows 100 ms for analog settling, clears old conversion data, starts a new conversion and polls for fresh readiness with a timeout. A nominal conversion takes about 50 ms. The 100 ms filter delay is conditional on source impedance: the digital tolerance sweep cannot qualify it for an unmeasured sensor. Validate settling at the actual sensor, cable and configured channel before relying on that delay. **20 samples/s is the ADC setting, not the delivered rate for each gas:** sequential channels, voltage diagnostics, settling and bus/task delays make the published rate lower. No helium constants from the inspiration repository are used. [TI ADS122C04 datasheet](https://www.ti.com/lit/ds/symlink/ads122c04.pdf)

The dedicated external I²C bus uses GPIO28/29 and addresses 0x40/0x41. The touchscreen bus on GPIO7/8 remains separate. The acquisition task enables the MD62 after ADC startup checks and disables its heater on acquisition/excitation faults. An excitation fault is latched until restart. It monitors the board's 3.0 V excitation and the O₂ bias, but cannot measure voltage drop in the remote sensor cable.

The initial 180-second MD62 warm-up lockout and 10-second electrical-stability window are **provisional settings**, not evidence that the sensor has reached thermal equilibrium. O₂ has a provisional 10-second startup delay. The stability gates start at 10 µV peak-to-peak for O₂ and 30 µV for MD62, with a tighter early/late-window drift check; characterize these with the assembled system.

## Touchscreen procedure

1. From **Analyse → O2 setup**, confirm the one installed oxygen type. Mark **New / replacement cell** when replacing a cell, even with the same type. This stops acquisition, resets accumulated samples, settles the selected input and requires fresh calibration. The explicit known-air check displays both raw inputs; connector advice remains manual/inconclusive until qualified response bounds exist. Then open **Settings → Calibration** for the installed oxygen channel or **Helium (MD62)**. Each identity has independent draft points and saved corrections.
2. Apply the first known reference gas at the intended controlled flow and near-atmospheric chamber pressure. Enter its known O₂ and He percentages, reference/cylinder ID and, if available, the reference uncertainty in percentage points. The first point is a baseline; it is not automatically assumed to be zero.
3. Wait for warm-up, fault-free readings and a stable window. Capture the baseline. A true zero correction requires a suitable known zero gas; a baseline above zero makes the zero an extrapolation.
4. Apply a second known mixture with enough concentration and voltage separation, enter its composition/ID/uncertainty, wait again and capture the span. The draft needs at least 5 percentage points of concentration separation and a signal span comfortably greater than measured noise.
5. Review both points and select **Save channel calibration**. A rejected capture, unstable/stale/faulty reading, insufficient span or storage failure leaves the previous valid calibration in use. **Discard** clears only the draft.
6. Calibrate helium separately and calibrate another oxygen cell only when that cell is actually installed and selected. Verify persistence by restarting and rechecking a known gas. Simulator practice records are separate from hardware records.

The current correction is `percent = (voltage − zero_voltage) × sensitivity`. Hardware records are stored in NVS with per-channel identity, ADC acquisition configuration/gain, version/revision and CRC. A changed measurement transfer profile makes incompatible corrections inactive while retaining intact records. Compatible OTA updates preserve the installed type and calibration; unknown future formats fail closed. Historical retention is finite, so export reference information for a longer archive. An inactive record is written and verified before switching the active record. Two-point calibration remains a **bench correction**, particularly for MD62. It does not qualify the device's accuracy. Unknown reference uncertainty is allowed for exploration and remains explicitly unqualified; the record notes whether the entered uncertainty meets a provisional quarter-target allocation (0.05 points O₂ / 0.125 points He). This is only one contribution to the full uncertainty budget.

The physical live screen labels results as calibration/bench status and withholds derived gas claims while helium characterization is unvalidated. Normal measurement uses only the explicitly selected oxygen input; the other input is probed only for the requested known-air aid. A failed AO₂ reading is never replaced by JJ-CCR. Selection generations prevent an old completed conversion or reset from overwriting the newly selected channel history. A disconnected passive oxygen cell can resemble a true zero signal with this circuit, so electrical fault flags cannot detect every disconnected or failed cell. Known-gas functional checks remain necessary.

## MD62 characterization and validation checklist

All boxes below are **pending physical work**. Do not mark a box complete from CAD or software tests.

- [ ] Record actual sensor identifiers, installation orientation, cell age, reference analyzer model/serial/calibration status, certificate uncertainty, gas composition and cylinder/reference IDs.
- [ ] Condition the MD62 according to the applicable Winsen manual and storage history. The reviewed guidance calls for at least 8 hours after short storage and longer recovery after extended storage; check the exact storage-duration table rather than using the daily startup timer. [Winsen MD62 manual](https://www.winsen-sensor.com/d/files/thermal/md62.pdf)
- [ ] Verify connector polarity, 3.0 ±0.1 V at the MD62 **under load**, ADC supplies, bias and all ADC input voltages during power-on, power-off and sensor disconnection. Check input leakage/back-powering and analog settling after MUX/gain changes.
- [ ] Measure shorted-input noise and sensor-connected noise. Record raw codes and volts, clipping, supply ripple, repeated cold starts, warm-up trajectories and restart persistence. Keep analog input filters and local supply-capacitor return paths short during routing.
- [ ] Determine thermal warm-up from repeated cold starts and actual drift, including the final enclosure. Adjust the provisional timer/stability thresholds only from the measurements.
- [ ] Obtain dive-shop reference mixtures spanning the intended He range and **several O₂ fractions**, including zero-He mixtures. Repeat each measurement and change the measurement order; avoid fitting a curve to one sequence of warming/drift.
- [ ] Reserve entire mixtures and separate measurement runs as validation data **before fitting**. Use them only to test the proposed correction, not to tune it. Include independent days/restarts where practical.
- [ ] Record chamber temperature, humidity, pressure and flow, ambient conditions, elapsed heater-on time and battery voltage. Repeat on battery, USB-A→USB-C charging and USB-C→USB-C charging. Charge-system commissioning requirements still apply.
- [ ] Compare a simple linear helium correction with composition/environment-dependent candidates using the measured data. Select additional terms only if they improve held-out results and remain physically plausible. The firmware contains no fitted nonlinear MD62 helium curve yet because no measured dataset exists.
- [ ] Report bias, repeatability, worst observed error, environmental/gas range, number of independent runs and reference-analyzer uncertainty. Include reference uncertainty, repeatability, resolution, drift and environmental sensitivity in an uncertainty budget. A low ADC noise figure does not establish gas accuracy.
- [ ] Check oxygen-cell open/short/reversed and low-output behavior; compare both channels against known gas. Check MD62 heater/cable faults, stale ADC/CO data and fault recovery. Confirm safe shutdown and charging behavior separately.
- [ ] Validate actual elbows, mating plugs, solder, cable bends and battery disconnection in the enclosure before final placement/routing lock.

The firmware now emits raw `CSV1` characterization rows with individual sample timestamps, sensor identity, configuration, calibration revision, environment and faults. Convert a captured serial log using `python3 scripts/extract_characterization.py serial.log measurements.csv`; the extractor opens no device and performs no flashing. The physical BME280 driver is implemented; absent or faulted environment remains unavailable. Use the [manual bench-log template](pcb/integration/verification/software-calibration/characterization-log.csv) for reference-gas and instrument information alongside raw captures. No measured dataset exists yet. Calendar-age reminders and automatic aging-based recalibration prompts are not implemented.

## CO remains CO

The ZE07-CO UART decoder receives documented 9600-baud frames, checks framing/checksum, observes warm-up and rejects stale data. It sends **no recalibration commands**. Current CO readings are separate from CO₂, and legacy CO₂ history stays identified as CO₂ when records are migrated. No CO₂ concentration is inferred from MD62 helium mode. The ZE07's humidity range and manufacturer restrictions still apply. [Winsen ZE07-CO manual](https://www.winsen-sensor.com/d/files/manual/ze07-co.pdf)

## Digital verification and remaining scope

The current [verification package](system-review/verification/README.md) binds
both firmware builds, host/sanitizer tests, logical pin checks and UI captures
to source hashes. Earlier `pcb/integration/verification/software-calibration/` evidence
remains a historical checkpoint; its footprint counts and DRC totals do not
describe the current board.

Real gauge, charger, BME280 and hardware shutdown integration is implemented
and build-tested. Software fault injection covers selection, stale frames,
calibration isolation, storage failure, maintenance and OTA behaviour. No
physical firmware was flashed or exercised on the new PCB. Final routed PCB
and updated Fusion imports must pass their own checks before an order release.

Neither O₂ nor He target accuracy is demonstrated. Power sequencing, source
impedance, actual filter settling, off-state input leakage, thermal drift,
reference-gas response and enclosure sealing remain physical work. Keep the
MD62 unless measured results demonstrate a limitation that better electronics
and evidence-based correction cannot resolve.

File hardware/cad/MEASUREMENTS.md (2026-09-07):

# Enclosure measurement checklist — Revision 02

**Status: Editable concept built; physical measurements pending.** The [current Fusion audit](verification/model-audit.json) reports healthy features, fully constrained sketches and zero volumetric interferences for the modelled components. Published dimensions below are source-backed nominal references, not measurements of the purchased parts. Unconfirmed mounting, sealing and connector features remain clearance envelopes in CAD.

The housing is **180 H × 95 W × 60 D mm**, with **3 mm** general walls; side projections give a current overall model width of **107 mm**. Coordinates are **+X toward the viewer's left, +Y up and +Z rearward**, with front **Z = 0**. The rear cover's nominal 3 mm allocation includes a **0.25 mm seating gap**: its solid occupies **Z = 57.25–60 mm** and is **2.75 mm** thick. The future PCB target is **64 × 108 mm**; the actual KiCad PCB has not been resized.

## Published references

| Component | Verified published dimensions | What remains provisional |
| --- | --- | --- |
| Guition JC4880P443C_I_W/Y display | Active area **56.16 × 93.60 mm** in portrait. The specification lists a **69.41 × 117.01 mm** module envelope. | The document covers bare and shell variants. Page 6 shows **66.80 × 114.40 mm** front glass; page 7 shows the larger assembly, **13.8 mm** depth and **4 × Ø2 mm** holes on **60 × 102.6 mm** pitch. Confirm which drawing matches the actual unit before using depth or holes. |
| Honeywell AO2, AA428-210 | **Ø29.3 mm** body; **31.75 mm** below the upper body datum and a **6.5 mm M16 × 1** threaded projection: **38.25 mm** overall by addition, before the cable mating space. Drawing tolerance **±0.15 mm** unless stated. | Confirm the purchased cell matches this body and connector. Allow additional connector, removal and cable bend clearance. Defer mating thread, seal seat and retention details. |
| Winsen MD62 | Body **19 × 9.5 × 14 mm**; untrimmed leads **26 ±1 mm**. | Include the chosen lead length and harness or small board in the mounted envelope. Confirm detector marking, orientation and strain relief. |
| Winsen ZE07-CO | Board **25.4 × 22.4 × 1.6 mm**; sensor **Ø20 × 16.7 mm** above the PCB; pins **3.45 mm** below it. Total stack is **21.75 mm** by addition. | Verify actual module revision and connection hardware. Do not direct the inlet jet at the sensor; the manual excludes strong air convection. |
| GCT USB4720-03-A | Mid-mount PCB thickness **0.60 ±0.10 mm**. Manufacturer panel example has **1.80 mm** reference thickness and stepped openings including **8.44 × 2.66**, **9.14 × 3.35**, and **9.64 × 3.86 mm**, with **±0.03 mm** specified dimensions. | These are different sections of a shaped sealing aperture, not interchangeable rectangular cutouts. Defer final taper, radii, gasket compression and plug clearance until drawing and actual connector are checked together. Support the daughterboard for the specified mating/unmating forces, which reach **20 N**. |

Primary sources: [Guition specification, pages 4, 6–7](https://www.guition.com/icms/upload/fb081940d6fc11f09850077a33e1404f/FTPData/UEditor/file/2026121/1768961095795/JC4880P443C_I_W%20Specifications-EN-V1.0.pdf), [Honeywell AO2 drawing](https://prod-edam.honeywell.com/content/dam/honeywell-edam/sps/siot/en-us/products/sensors/gas-sensors/automotive-and-emissions/documents/hon-ia-hss-automotive-ao2-o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), [Winsen MD62 manual](https://www.winsen-sensor.com/d/files/PDF/Thermal%20Conductor%20Gas%20Sensor/MD62%20Manual%20V1.3.pdf), [Winsen ZE07-CO manual](https://www.winsen-sensor.com/d/files/manual/ze07-co.pdf), [GCT manufacturer drawing, sheets 1–2](https://www.mouser.com/pdfDocs/USB4720-ProductDrawing.pdf).

## Measure before fixing mounts and seals

- [ ] **Display:** identify bare/shell variant; measure glass and PCB outline, complete depth including connectors, active-area offsets, hole coordinates and connector insertion/removal space.
- [ ] **FMA FPML1S2P050C protected holder:** measure full occupied outline, cell height, protection-board protrusions, attachment features and cable exit. Include the retained red RCY/BEC-style plug and enough room to disconnect it. Capacity is owner-confirmed **2 × 3400 mAh**, electrically **1S2P**; it does not determine the mechanical envelope.
- [ ] **AO2:** measure body, threaded nose, existing seal and mated cable. Confirm access for removal without loading its connector.
- [ ] **MD62 and ZE07-CO:** measure the installed sensor, support and harness as an assembly. Confirm which surfaces must remain exposed to sample gas.
- [ ] **GYBMEP/BME280 board:** measure board outline, mounting hole, header height and wire exit. Keep it away from the MD62 and regulator's local heat. Confirm the physical sensor and board variant.
- [ ] **Right-side button:** verify the nominal **12 mm** panel size against the actual barrel, flange, nut, allowable panel thickness and complete terminal depth. Include nut-tool and wire-bend access.
- [ ] **USB assembly:** measure the connector and chosen daughterboard, plug overmould clearance, board support and wire exit. Test the replaceable side insert before finalising its seal geometry; a 3 mm general wall is not the manufacturer's local panel example.
- [ ] **Gas connections:** verify the owned **8 mm OD / 5 mm ID** tube, actual fittings, retaining method, insertion length and bend space. Confirm the exhaust remains open and that the chamber can be removed through the rear after releasing the fittings.
- [ ] **M3 inserts and screws:** record the exact insert OD, length, recommended pilot bore and boss diameter, plus screw-head and tool envelopes. Print a fit coupon before fixing production dimensions.
- [ ] **Chamber sealing:** select and measure seal stock, feedthroughs and compression limits before cutting final grooves. Check the removable chamber and rear cover as separate sealing interfaces.

## Model checks to record

- [x] Current Fusion model: healthy features, fully constrained sketches and zero volumetric interferences; **19 component occurrences, 50 solid bodies, 490 timeline items**. This static check excludes coincident faces and does not validate unmeasured physical parts or removal paths.
- [x] Width parameter regenerated **95 → 97 → 95 mm**, with healthy geometry and the original value restored.
- [x] Sampled extraction paths passed with the prerequisites in [README.md](README.md#assembly-and-service-intent). Carrier/display require removal of the USB assembly and button; the chamber requires removal of both gas stubs. This is not a continuous sweep or physical assembly test.
- [x] Nominal **Ø4 × 50 mm** rear-facing screwdriver shafts clear all four screw groups in the model. Actual driver handle and screw/insert selection remain unverified.
- [x] A gas centreline around the AO2 neck is clear at sampled points no more than **1 mm** apart. The ZE07-CO envelope starts at **Z = 16 mm** to clear the exhaust bore. Full flow area, sensor exposure, response, mixing and seals remain unverified.
- [ ] Confirm component and cable envelopes fit without interference; do not treat placeholder volumes as verified parts.
- [ ] Confirm every internal assembly has a feasible rearward removal sequence and reachable fasteners.
- [ ] Confirm the battery can be disconnected before carrier removal and that screws cannot contact cells or wiring.
- [ ] Confirm continuous inlet-to-exhaust flow space with no direct inlet jet on the CO module and no unintended path into the battery/electronics compartment.
- [ ] Confirm display, button and USB reach and plug clearance in front, rear, side and section views.
- [ ] Record the final measured dimensions and the reviewed Fusion version before releasing PLA fit-print files.

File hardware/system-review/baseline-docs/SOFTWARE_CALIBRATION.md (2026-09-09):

# Software calibration — existing sensors, upgraded electronics

This revision keeps AO₂, R17JJ-CCR and MD62. It replaces the two ADC chips and the helium trimmer, and adds real acquisition, individual calibration records and a touchscreen workflow. **The accuracy targets remain unproven: ±0.2 percentage points O₂ and ±0.5 points He over the conditions actually tested.** No physical gas measurements were performed during this implementation.

The main PCB is still an unrouted placement. Finish routing and the electrical/thermal review before manufacture. Showcase, enclosure printing and community release preparation remain paused.

## What changed on the board

| Marking | Part / purpose |
|---|---|
| U401 | ADS122C04IPWR, TSSOP-16; reads AO₂ and JJ-CCR sequentially; address **0x40** |
| U502 | ADS122C04IPWR, TSSOP-16; reads MD62 and voltage diagnostics; address **0x41** |
| RN501 | Vishay **ACASN2001U2001P1AT**, two matched 2 kΩ resistors making a fixed half-excitation reference |
| RV501, R502, R503 | Removed; the matched array replaces this adjustable branch |
| J401 / J402 | Existing AO₂ / JJ-CCR connectors in the approved positions; no sensor replacement |
| J501 | Existing MD62 connection; regulated **3.0 V** excitation retained |

RN501 is a selected manufacturer order code; distributor stock and lead time still need checking. Its custom lands follow Vishay's IEC recommendation. Its nominal 3D body is drawing-derived, not exact manufacturer CAD. See the [component key](pcb/integration/reference/COMPONENT_REFERENCE.md), [CSV BOM/reference list](pcb/integration/reference/COMPONENT_REFERENCE.csv), [assembly map](pcb/integration/reference/main-assembly.svg) and [analog review](pcb/integration/verification/software-calibration/analog-check-notes.md).

The ADC samples a voltage. Software subtracts the measured zero offset and applies a measured sensitivity. A fixed reference is sufficient because software can correct the offset **provided the original voltage is inside the ADC's usable range**. It cannot recover a clipped signal, identify an unknown gas, or correct an unmeasured environmental dependency.

## Acquisition settings

Both converters use the internal 2.048 V reference, normal **20 samples/s conversion rate**, single-shot operation, and no IDAC or burnout excitation currents. AO₂ and JJ-CCR use gain 8 with the PGA enabled (±256 mV). MD62 uses gain 1 with PGA bypass (±2.048 V). Voltage diagnostics use gain 1 with PGA bypass.

The driver resets and checks registers, writes and reads back each configuration, allows 100 ms for analog settling, clears old conversion data, starts a new conversion and polls for fresh readiness with a timeout. A nominal conversion takes about 50 ms. **20 samples/s is the ADC setting, not the delivered rate for each gas:** sequential channels, voltage diagnostics, settling and bus/task delays make the published rate lower. No helium constants from the inspiration repository are used. [TI ADS122C04 datasheet](https://www.ti.com/lit/ds/symlink/ads122c04.pdf)

The dedicated external I²C bus uses GPIO28/29 and addresses 0x40/0x41. The touchscreen bus on GPIO7/8 remains separate. The acquisition task enables the MD62 after ADC startup checks and disables its heater on acquisition/excitation faults. An excitation fault is latched until restart. It monitors the board's 3.0 V excitation and the O₂ bias, but cannot measure voltage drop in the remote sensor cable.

The initial 180-second MD62 warm-up lockout and 10-second electrical-stability window are **provisional settings**, not evidence that the sensor has reached thermal equilibrium. O₂ has a provisional 10-second startup delay. The stability gates start at 10 µV peak-to-peak for O₂ and 30 µV for MD62, with a tighter early/late-window drift check; characterize these with the assembled system.

## Touchscreen procedure

1. Open **Settings → Calibration** and select **AO₂ oxygen**, **JJ-CCR oxygen** or **Helium (MD62)**. Each channel has independent readings, draft points and saved corrections.
2. Apply the first known reference gas at the intended controlled flow and near-atmospheric chamber pressure. Enter its known O₂ and He percentages, reference/cylinder ID and, if available, the reference uncertainty in percentage points. The first point is a baseline; it is not automatically assumed to be zero.
3. Wait for warm-up, fault-free readings and a stable window. Capture the baseline. A true zero correction requires a suitable known zero gas; a baseline above zero makes the zero an extrapolation.
4. Apply a second known mixture with enough concentration and voltage separation, enter its composition/ID/uncertainty, wait again and capture the span. The draft needs at least 5 percentage points of concentration separation and a signal span comfortably greater than measured noise.
5. Review both points and select **Save channel calibration**. A rejected capture, unstable/stale/faulty reading, insufficient span or storage failure leaves the previous valid calibration in use. **Discard** clears only the draft.
6. Repeat for the other channels. Verify each saved record by restarting the device and rechecking a known gas. Simulator practice records are isolated from hardware records and last only for that simulator process.

The current correction is `percent = (voltage − zero_voltage) × sensitivity`. Hardware records are stored in NVS with per-channel identity, ADC acquisition configuration/gain, version/revision and CRC. A changed gain or acquisition revision invalidates incompatible saved corrections. An inactive record is written and verified before switching the active record. Two-point calibration remains a **bench correction**, particularly for MD62. It does not qualify the device's accuracy. Unknown reference uncertainty is allowed for exploration and remains explicitly unqualified; the record notes whether the entered uncertainty meets a provisional quarter-target allocation (0.05 points O₂ / 0.125 points He). This is only one contribution to the full uncertainty budget.

The physical live screen labels results as calibration/bench status and withholds derived gas claims while helium characterization is unvalidated. Both oxygen channels remain visible independently; a failed AO₂ reading is not silently replaced by JJ-CCR. A disconnected passive oxygen cell can resemble a true zero signal with this circuit, so electrical fault flags cannot detect every disconnected or failed cell. Known-gas functional checks remain necessary.

## MD62 characterization and validation checklist

All boxes below are **pending physical work**. Do not mark a box complete from CAD or software tests.

- [ ] Record actual sensor identifiers, installation orientation, cell age, reference analyzer model/serial/calibration status, certificate uncertainty, gas composition and cylinder/reference IDs.
- [ ] Condition the MD62 according to the applicable Winsen manual and storage history. The reviewed guidance calls for at least 8 hours after short storage and longer recovery after extended storage; check the exact storage-duration table rather than using the daily startup timer. [Winsen MD62 manual](https://www.winsen-sensor.com/d/files/thermal/md62.pdf)
- [ ] Verify connector polarity, 3.0 ±0.1 V at the MD62 **under load**, ADC supplies, bias and all ADC input voltages during power-on, power-off and sensor disconnection. Check input leakage/back-powering and analog settling after MUX/gain changes.
- [ ] Measure shorted-input noise and sensor-connected noise. Record raw codes and volts, clipping, supply ripple, repeated cold starts, warm-up trajectories and restart persistence. Keep analog input filters and local supply-capacitor return paths short during routing.
- [ ] Determine thermal warm-up from repeated cold starts and actual drift, including the final enclosure. Adjust the provisional timer/stability thresholds only from the measurements.
- [ ] Obtain dive-shop reference mixtures spanning the intended He range and **several O₂ fractions**, including zero-He mixtures. Repeat each measurement and change the measurement order; avoid fitting a curve to one sequence of warming/drift.
- [ ] Reserve entire mixtures and separate measurement runs as validation data **before fitting**. Use them only to test the proposed correction, not to tune it. Include independent days/restarts where practical.
- [ ] Record chamber temperature, humidity, pressure and flow, ambient conditions, elapsed heater-on time and battery voltage. Repeat on battery, USB-A→USB-C charging and USB-C→USB-C charging. Charge-system commissioning requirements still apply.
- [ ] Compare a simple linear helium correction with composition/environment-dependent candidates using the measured data. Select additional terms only if they improve held-out results and remain physically plausible. The firmware contains no fitted nonlinear MD62 helium curve yet because no measured dataset exists.
- [ ] Report bias, repeatability, worst observed error, environmental/gas range, number of independent runs and reference-analyzer uncertainty. Include reference uncertainty, repeatability, resolution, drift and environmental sensitivity in an uncertainty budget. A low ADC noise figure does not establish gas accuracy.
- [ ] Check oxygen-cell open/short/reversed and low-output behavior; compare both channels against known gas. Check MD62 heater/cable faults, stale ADC/CO data and fault recovery. Confirm safe shutdown and charging behavior separately.
- [ ] Validate actual elbows, mating plugs, solder, cable bends and battery disconnection in the enclosure before final placement/routing lock.

Use [characterization-log.csv](pcb/integration/verification/software-calibration/characterization-log.csv) as a manual bench log. It is a blank template, not an implemented logger or measured dataset. The current firmware records environment as unavailable until a physical environmental-sensor driver is implemented; use independent instruments and write readings in the log. Calendar-age reminders and automatic aging-based recalibration prompts are not implemented.

## CO remains CO

The ZE07-CO UART decoder receives documented 9600-baud frames, checks framing/checksum, observes warm-up and rejects stale data. It sends **no recalibration commands**. Current CO readings are separate from CO₂, and legacy CO₂ history stays identified as CO₂ when records are migrated. No CO₂ concentration is inferred from MD62 helium mode. The ZE07's humidity range and manufacturer restrictions still apply. [Winsen ZE07-CO manual](https://www.winsen-sensor.com/d/files/manual/ze07-co.pdf)
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

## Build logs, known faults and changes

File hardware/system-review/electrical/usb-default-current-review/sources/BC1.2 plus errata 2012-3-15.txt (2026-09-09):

Battery Charging Specification
          (Including errata and ECNs through March 15, 2012)

                                          Revision 1.2
                                      March 15, 2012

                 Copyright © 2012, USB Implementers Forum, Inc.
                               All rights reserved.

A LICENSE IS HEREBY GRANTED TO REPRODUCE THIS SPECIFICATION FOR
INTERNAL USE ONLY. NO OTHER LICENSE, EXPRESS OR IMPLIED, BY ESTOPPEL OR
OTHERWISE, IS GRANTED OR INTENDED HEREBY.

USB-IF AND THE AUTHORS OF THIS SPECIFICATION EXPRESSLY DISCLAIM ALL
LIABILITY FOR INFRINGEMENT OF INTELLECTUAL PROPERTY RIGHTS, RELATING
TO IMPLEMENTATION OF INFORMATION IN THIS SPECIFICATION. USB-IF AND THE
AUTHORS OF THIS SPECIFICATION ALSO DO NOT WARRANT OR REPRESENT THAT
SUCH IMPLEMENTATION(S) WILL NOT INFRINGE THE INTELLECTUAL PROPERTY
RIGHTS OF OTHERS.

THIS SPECIFICATION IS PROVIDED "AS IS” AND WITH NO WARRANTIES, EXPRESS OR
IMPLIED, STATUTORY OR OTHERWISE. ALL WARRANTIES ARE EXPRESSLY
DISCLAIMED. NO WARRANTY OF MERCHANTABILITY, NO WARRANTY OF NON-
INFRINGEMENT, NO WARRANTY OF FITNESS FOR ANY PARTICULAR PURPOSE, AND
NO WARRANTY ARISING OUT OF ANY PROPOSAL, SPECIFICATION, OR SAMPLE.

IN NO EVENT WILL USB-IF OR USB-IF MEMBERS BE LIABLE TO ANOTHER FOR THE
COST OF PROCURING SUBSTITUTE GOODS OR SERVICES, LOST PROFITS, LOSS OF
USE, LOSS OF DATA OR ANY INCIDENTAL, CONSEQUENTIAL, INDIRECT, OR SPECIAL
DAMAGES, WHETHER UNDER CONTRACT, TORT, WARRANTY, OR OTHERWISE,
ARISING IN ANY WAY OUT OF THE USE OF THIS SPECIFICATION, WHETHER OR NOT
SUCH PARTY HAD ADVANCE NOTICE OF THE POSSIBILITY OF SUCH DAMAGES.

ii

   Battery Charging Specification, Revision 1.2                            March 15, 2012

Contributors
Mark Lai                       Allion Test Labs
Sammy Mbanta                   Astec Power
Abel Astley                    Broadcom
Kenneth Ma                     Broadcom
Shimon Elkayam                 Broadcom
Gaurav Singh                   Cypress
Dan Ellis                      DisplayLink
Graham Connolly                Fairchild
Oscar Freitas                  Fairchild
Joel Silverman                 Kawasaki
Pat Crowe                      MQP Electronics
Juha Heikkila                  Nokia
Richard Petrie                 Nokia
Sten Carlsen                   Nokia
Jeroen Kleinpenning            NXP Semiconductors
Terry Remple, Chair            Qualcomm
Dave Haglan                    SMSC
Mark Bohm                      SMSC
Morgan Monks                   SMSC
Tim Knowlton                   SMSC
Morten Christiansen            ST Ericsson
Nicolas Florenchie             ST Ericsson
Shaun Reemeyer                 ST Ericsson
George Paparrizos              Summit Microelectronics
Adam Burns                     Synopsys
Wei Ming                       Telecommunication Metrology Center of MII
Jean Picard                    Texas Instruments
Ivo Huber                      Texas Instruments
Pasi Palojarvi                 Texas Instruments
Steven Tom                     Texas Instruments
Ed Beeman                      USB-IF
Mark Paxson                    USB-IF

                                                                                       iii

     Battery Charging Specification, Revision 1.2                                              March 15, 2012

Revision History
Revision        Date             Author             Description
BC1.0           Mar 8, 2007      Terry Remple       First release

BC1.1           April 15, 2009   Terry Remple       Major updates to all sections. Added Data Contact
                                                    Detect protocol, and Accessory Charger Adapter.

BC1.2           Oct 5, 2010      Terry Remple       Following items indicate changes from BC1.1 to
                                 Adam Burns         BC1.2. References below to Section, Figures and
                                                    Tables refer to BC1.2, unless BC1.1 is specifically
                                                    indicated.

                                                    1. Allow DCPs to output more than 1.5A. Allows
                                                    Portable Devices (PDs) with switch mode chargers to
                                                    draw more power. Section 4.4.1.

                                                    2. Increase minimum CDP current to 1.5A. Without
                                                    change, PDs had to draw less than 500mA, to avoid
                                                    CDP shutdown. Table 5-2.

                                                    3. Indicate that ICDP max and IDCP max limits of 5A
                                                    come from USB 2.0, and are safety limits. Table 5-2
                                                    note 1.

                                                    4. Allow PDs to draw up to 1.5A during HS chirp and
                                                    traffic. Remove previous limits of 560mA and 900mA
                                                    which was based on HS common mode ranges.
                                                    Section 3.5.

                                                    5. Require CDPs to support 1.5A during HS chirp and
                                                    traffic. Affects CDP common mode range.
                                                    Section 3.5.

                                                    6. Reduce maximum PD current from 1.8A to 1.5A, to
                                                    avoid shutdown when attached to CDP. Table 5-2.

                                                    7. Rename Docking Station to ACA-Dock, to avoid
                                                    confusion with other types of Docking Stations.

                                                    8. Require ACA-Dock to differentiate itself from an
                                                    ACA, by enabling VDM_SRC during no activity.
                                                    Section 3.2.4.4.

                                                    9. Allow CDP to leave VDM_SRC enabled while
                                                    peripheral not connected. Section 3.2.4.2.

                                                    10. Remove ICHG_SHTDWN. This was a recommended
                                                    max output current for Charging Ports with VBUS
                                                    grounded. BC1.1 Section 4.1.

                                                    11. Require VDP_SRC to not pull D+ below 2.2V when
                                                    D+ is being pulled to VDP_UP through RDP_UP.
                                                    Require VDM_SRC to not pull D- below 2.2V when D- is
                                                    being pulled high. Required for ACA-Dock support.
                                                    Table 5-1 notes 1 and 2.

iv

Battery Charging Specification, Revision 1.2                                              March 15, 2012

                                               12. Make DCD current source optional for PDs.
                                               Section 3.2.3.

                                               13. Make DCD timeout required for PDs. Section
                                               3.2.3.

                                               14. Make Secondary Detection optional for PDs.
                                               Section 4.6.2.

                                               15. Make Good Battery Algorithm required behavior
                                               for PDs. Section 3.2.4.

                                               16. Remove resistive detection. BC1.1 Section 3.9.

                                               17. Change PD Required Operating Range to include
                                               4.5V at 500mA. Figure 4-3.

                                               18. Allow any downstream port to act as a DCP.
                                               Section 4.1.3.

                                               19. Require PDs to enable VDP_SRC or RDP_PU when
                                               charging from a DCP. Section 3.3.2.

                                               20. Allow chargers to renegotiate current with PD by
                                               dropping and reasserting VBUS. Section 4.1.3.

                                               21. Require PDs to discharge their own VBUS input
                                               after VBUS drops to support charger port
                                               renegotiation request. Section 4.6.3.

                                               22. Allow PDs to disconnect and repeat Charger
                                               Detection multiple times while attached, with specified
                                               timing. Section 4.6.3.

                                               23. Reduce DCP input impedance between D+, D- to
                                               VBUS and ground from 1MΩ to 300kΩ. Section 4.4.3.

                                               24. Require CDPs to recover after over-current
                                               condition. Section 4.2.2.

                                               25. Allow greater DCP undershoot for large load
                                               current steps, to enable low quiescent current
                                               chargers required by Europe. Section 4.4.2.

                                               26. Define ACAs and ACA-Docks as types of
                                               Charging Ports. Section 1.4.5.

                                               27. Use session valid voltage range defined in EH
                                               and OTG Supplement rev 2.0. Section 3.2.2.

                                               28. Only devices that can operate stand-alone from
                                               internal battery power are allowed to use the Dead
                                               Battery Provision. Section 2.2.

                                               29. Allow compound PDs to draw ISUSP plus an

                                                                                                         v

     Battery Charging Specification, Revision 1.2                                                March 15, 2012

                                                    additional ISUSP for each downstream port.
                                                    Section 2.1.

                                                    30. Remove requirement for vendors to provide
                                                    typical and maximum connect time for products
                                                    having a Dead or Weak Battery for compliance
                                                    testing. Section 2.

                                                    31. Remove references to no battery from Dead
                                                    Battery Provision. Section 2.

                                                    32. Require PD using Dead Battery Provision to
                                                    enable VDP_SRC from TDBP_ATT_VDPSRC after attach to
                                                    TDBP_VDPSRC_CON before connect. Section 2.2.

                                                    33. Added DBP – Configured Clause, which allows
                                                    PD with Dead Battery to draw ICFG_MAX for
                                                    TDBP_FUL_FNCTN without having to pass USBCV.
                                                    Section 2.3.

                                                    34. Note constraints when trying to charge from an
                                                    OTG A-device. Section 1.6.

                                                    35. Change IDP_SINK and IDM_SINK range from
                                                    50-150uA to 25-175uA to ease PHY design. Table 5-2
                                                    note 1.

                                                    36. Allow USB 3.0 devices to implement BC charger
                                                    detection protocols, and to use USB 3.0 ranges for
                                                    IUNIT and ICFG_MAX. Section 1.7.

                                                    37. Rename previous ACA to Micro ACA, and define
                                                    the Standard ACA. Section 6.

                                                    38. Add caps to OTG and Accessory Ports on ACA to
                                                    support Attach Detection Protocol (ADP). Figure 6-3.

                                                    39. Change ACA ID resistance tolerances from 5% to
                                                    1% to ease PHY design. Table 5-3.

                                                    40. Remove requirements on ACA switching
                                                    time(TACA_ID_VBUS) to ease ACA design. BC1.1
                                                    Section 6.5.

                                                    41. Add state diagram for PDs attached to ACA.
                                                    Section 6.2.7.

                                                    42. Require PDs to limit current from ACA such that
                                                    VBUS remains above VACA_OPR. Section 6.2.2.

                                                    43. Change minimum ACA operating voltage
                                                    (VACA_OPR) from 3.0V to 4.1V. Table 5-1.

                                                    44. Remove requirement that ACA VBUS resistances
                                                    (RACA_CHG_DIS) be greater than 10k when
                                                    VBUS_CHG is greater than 6.5V. PDs are

vi

   Battery Charging Specification, Revision 1.2                                                March 15, 2012

                                                  responsible for protecting themselves against higher
                                                  voltages on VBUS. BC1.1 Section 6.7.

                                                  45. Require ACAs to continue providing power to OTG
                                                  device from Charging Port, even if ground offsets or
                                                  USB reset cause D- to go below VDAT_REF.
                                                  Section 6.2.6.

                                                  46. Change charger shutdown recovery time
                                                  (TSHTDWN_REC) from 2 seconds to 2 minutes. Table
                                                  5-5.

                                                  47. Indicate that ACA-Dock is required to pull D+ to
                                                  VDP_UP with RDP_UP when VBUS is asserted.
                                                  Section 3.2.4.4.

                                                  48. Remove statements regarding devices with
                                                  multiple receptacles. Covered in Multiple Receptacle
                                                  white paper at http://www.usb.org/developers/docs/.

                                                  49. Improve readability by adding and updating
                                                  drawings, re-structuring sections, and clarifying text.

BC1.2          Oct 12, 2011    Pat Crowe          Includes errata changes from Oct 12, 2011
plus errata
BC1.2          Mar 15, 2012    Pat Crowe          Includes errata changes from Mar 15, 2012:
plus further                                          1. Corrections to Micro ACA specification.
errata

                                                                                                            vii

             Battery Charging Specification, Revision 1.2                                                                                       March 15, 2012

Table of Contents
1. Introduction ...................................................................................................................................................... 1
       1.1 Scope ................................................................................................................................................. 1
       1.2 Background ........................................................................................................................................ 1
       1.3 Reference Documents ........................................................................................................................ 1
       1.4 Definitions of Terms............................................................................................................................ 2
             1.4.1 Accessory Charger Adaptor.................................................................................................. 2
             1.4.2 ACA-Dock ............................................................................................................................. 2
             1.4.3 Attach versus Connect.......................................................................................................... 2
             1.4.4 Charging Downstream Port .................................................................................................. 2
             1.4.5 Charging Port ........................................................................................................................ 2
             1.4.6 Dead Battery Threshold ........................................................................................................ 2
             1.4.7 Dedicated Charging Port ...................................................................................................... 3
             1.4.8 Downstream Port .................................................................................................................. 3
             1.4.9 Micro ACA ............................................................................................................................. 3
             1.4.10 Portable Device..................................................................................................................... 3
             1.4.11 Rated Current ....................................................................................................................... 3
             1.4.12 Standard ACA ....................................................................................................................... 3
             1.4.13 Standard Downstream Port .................................................................................................. 3
             1.4.14 USB Charger......................................................................................................................... 3
             1.4.15 Weak Battery Threshold ....................................................................................................... 3
       1.5 Parameter Values ............................................................................................................................... 4
       1.6 OTG Considerations ........................................................................................................................... 4
       1.7 Super Speed Considerations ............................................................................................................. 4
2. Dead Battery Provision.................................................................................................................................... 4
       2.1 Background ........................................................................................................................................ 4
       2.2 DBP – Unconfigured Clause .............................................................................................................. 4
       2.3 DBP – Configured Clause .................................................................................................................. 5
3. Charging Port Detection .................................................................................................................................. 6
       3.1 Overview ............................................................................................................................................. 6
       3.2 Charger Detection Hardware .............................................................................................................. 7
             3.2.1 Overview ............................................................................................................................... 8
             3.2.2 VBUS Detect ......................................................................................................................... 8
             3.2.3 Data Contact Detect ............................................................................................................. 9
             3.2.4 Primary Detection ............................................................................................................... 14
             3.2.5 Secondary Detection .......................................................................................................... 22
             3.2.6 ACA Detection .................................................................................................................... 25
       3.3 Charger Detection Algorithms .......................................................................................................... 28
             3.3.1 Weak Battery Algorithm ...................................................................................................... 28
             3.3.2 Good Battery Algorithm ...................................................................................................... 30
       3.4 Charger Detection Timing................................................................................................................. 32
             3.4.1 Data Contact Detect Timing................................................................................................ 32
             3.4.2 Detection Timing, CDP ....................................................................................................... 35
       3.5 Ground Current and Noise Margins ................................................................................................. 36
4. Charging Port and Portable Device Requirements .................................................................................... 37
       4.1 Charging Port Requirements ............................................................................................................ 37
             4.1.1 Overshoot ........................................................................................................................... 37
             4.1.2 Maximum Current ............................................................................................................... 37
             4.1.3 Detection Renegotiation ..................................................................................................... 37
             4.1.4 Shutdown Operation ........................................................................................................... 37
             4.1.5 Failure Voltage .................................................................................................................... 37
             4.1.6 Multiple Ports ...................................................................................................................... 37

      viii

           Battery Charging Specification, Revision 1.2                                                                                    March 15, 2012

           4.2
           Charging Downstream Port .............................................................................................................. 38
           4.2.1 Required Operating Range ................................................................................................. 38
           4.2.2 Shutdown Operation ........................................................................................................... 38
           4.2.3 Undershoot ......................................................................................................................... 39
           4.2.4 Detection Signaling ............................................................................................................. 39
           4.2.5 Connector ........................................................................................................................... 39
      4.3 ACA-Dock ......................................................................................................................................... 39
           4.3.1 Required Operating Range ................................................................................................. 39
           4.3.2 Undershoot ......................................................................................................................... 39
           4.3.3 Detection Signaling ............................................................................................................. 39
           4.3.4 Connector ........................................................................................................................... 39
      4.4 Dedicated Charging Port .................................................................................................................. 40
           4.4.1 Required Operating Range ................................................................................................. 40
           4.4.2 Undershoot ......................................................................................................................... 41
           4.4.3 Detection Signaling ............................................................................................................. 41
           4.4.4 Connector ........................................................................................................................... 41
      4.5 Accessory Charger Adapter ............................................................................................................. 41
           4.5.1 Required Operating Range ................................................................................................. 41
           4.5.2 Undershoot ......................................................................................................................... 41
           4.5.3 Detection Signaling ............................................................................................................. 41
           4.5.4 Connector ........................................................................................................................... 42
      4.6 Portable Device ................................................................................................................................ 42
           4.6.1 Allowed Operating Range ................................................................................................... 42
           4.6.2 Detection Signaling ............................................................................................................. 42
           4.6.3 Detection Renegotiation ..................................................................................................... 43
           4.6.4 Connector ........................................................................................................................... 43
5. Parameter Values ........................................................................................................................................... 44
6. Accessory Charger Adapter ......................................................................................................................... 49
      6.1 Introduction ....................................................................................................................................... 49
      6.2 Micro ACA ........................................................................................................................................ 50
           6.2.1 Micro ACA Ports ................................................................................................................. 50
           6.2.2 Micro ACA Connectivity Options......................................................................................... 51
           6.2.3 Micro ACA Architecture ...................................................................................................... 52
           6.2.4 Micro ACA Modes of Operation .......................................................................................... 53
           6.2.5 Implications of not Supporting Micro ACA Detection .......................................................... 54
           6.2.6 Micro ACA Requirements ................................................................................................... 54
           6.2.7 Portable Device State Diagram .......................................................................................... 56
      6.3 Standard ACA................................................................................................................................... 58
           6.3.1 Standard ACA Ports ........................................................................................................... 58
           6.3.2 Standard ACA Architecture................................................................................................. 59
           6.3.3 Standard ACA Modes of Operation .................................................................................... 60
           6.3.4 Implications of not Supporting Standard ACA Detection .................................................... 61
           6.3.5 Standard ACA Requirements ............................................................................................. 61

                                                                                                                                                               ix

     Battery Charging Specification, Revision 1.2                                                                                        March 15, 2012

                                                                        Figures
Figure 3-1 System Overview ............................................................................................................................. 6
Figure 3-2 Charger Detection Hardware ........................................................................................................... 8
Figure 3-3 Data Pin Offset .............................................................................................................................. 10
Figure 3-4 Data Contact Detect, Not Attached ............................................................................................... 11
Figure 3-5 Data Contact Detect, Standard Downstream Port......................................................................... 13
Figure 3-6 Primary Detection, DCP ................................................................................................................ 14
Figure 3-7 Primary Detection, CDP ................................................................................................................ 16
Figure 3-8 Primary Detection, SDP ................................................................................................................. 18
Figure 3-9 Primary Detection, ACA-Dock ....................................................................................................... 19
Figure 3-10 Primary Detection, ACA ............................................................................................................... 21
Figure 3-11 Secondary Detection, DCP.......................................................................................................... 23
Figure 3-12 Secondary Detection, CDP.......................................................................................................... 24
Figure 3-13 ACA Detection ............................................................................................................................. 26
Figure 3-14 Weak Battery Algorithm ............................................................................................................... 28
Figure 3-15 Good Battery Algorithm ............................................................................................................... 30
Figure 3-16 DCD Timing, Contact After Start ................................................................................................. 32
Figure 3-17 DCD Timing, Contact Before Start .............................................................................................. 33
Figure 3-18 DCD Timing, No Contact ............................................................................................................. 34
Figure 3-19 Detection Timing, CDP ................................................................................................................ 35
Figure 4-1 CDP Required Operating Range ................................................................................................... 38
Figure 4-2 DCP Required Operating Range ................................................................................................... 40
Figure 4-3 Portable Device Allowed Operating Range ................................................................................... 42
Figure 6-1 Accessory Charger Adapter .......................................................................................................... 49
Figure 6-2 Micro ACA Ports ............................................................................................................................ 50
Figure 6-3 Micro ACA Architecture ................................................................................................................. 52
Figure 6-4 Portable Device State Diagram ..................................................................................................... 56
Figure 6-5 Standard ACA Ports ...................................................................................................................... 58
Figure 6-6 Standard ACA Architecture ........................................................................................................... 59

                                                                         Tables
Table 5-1 Voltages .......................................................................................................................................... 44
Table 5-2 Currents .......................................................................................................................................... 45
Table 5-3 Resistances .................................................................................................................................... 46
Table 5-4 Capacitances .................................................................................................................................. 47
Table 5-5 Times .............................................................................................................................................. 48
Table 6-1 Micro ACA Connectivity Options..................................................................................................... 51
Table 6-2 Micro ACA Modes of Operation ...................................................................................................... 53
Table 6-3 Standard ACA Connectivity Options ............................................................................................... 59
Table 6-4 Standard ACA Modes of Operation ................................................................................................ 60

x

  Battery Charging Specification, Revision 1.2          March 15, 2012

                                            Acronyms
ACA       Accessory Charger Adapter
CDP       Charging Downstream Port
DBP       Dead Battery Provision
DCD       Data Contact Detect
DCP       Dedicated Charging Port
FS        Full Speed
HS        High-Speed
LS        Low-Speed
OTG       On-The-Go
PC        Personal Computer
PD        Portable Device
PHY       Physical Layer Interface for High-Speed USB
PS2       Personal System 2
SDP       Standard Downstream Port
SRP       Session Request Protocol
TPL       Targeted Peripheral List
USB       Universal Serial Bus
USBCV     USB Command Verifier
USB-IF    USB Implementers Forum
VBUS      Voltage line of the USB interface

                                                                    xi

    Battery Charging Specification, Revision 1.2                                               March 15, 2012

1. Introduction

1.1       Scope
The Battery Charging Working Group is chartered with creating specifications that define limits as well as
detection, control and reporting mechanisms to permit devices to draw current in excess of the USB 2.0
specification for charging and/or powering up from dedicated chargers, hosts, hubs and charging
downstream ports. These mechanisms are backward compatible with USB 2.0 compliant hosts and
peripherals.

1.2       Background
The USB ports on personal computers are convenient places for Portable Devices (PDs) to draw current for
charging their batteries. This convenience has led to the creation of USB Chargers that simply expose a
USB standard-A receptacle. This allows PDs to use the same USB cable to charge from either a PC or from
a USB Charger.

If a PD is attached to a USB host or hub, then the USB 2.0 specification requires that after connecting, a PD
must draw less than:
     • 2.5 mA average if the bus is suspended
     • 100 mA if bus is not suspended and not configured
     • 500 mA if bus is not suspended and configured for 500 mA

If a PD is attached to a Charging Port, (i.e. CDP, DCP, ACA-Dock or ACA), then it is allowed to draw
IDEV_CHG without having to be configured or follow the rules of suspend.

In order for a PD to determine how much current it is allowed to draw from an upstream USB port, there
need to be mechanisms that allow the PD to distinguish between a Standard Downstream Port and a
Charging Port. This specification defines just such mechanisms.

Since PDs can be attached to USB chargers from various manufacturers, it is important that all provide an
acceptable user experience. This specification defines the requirements for a compliant USB charger, which
is referred to in this spec as a USB Charger.

If a PD has a Dead or Weak Battery, then the Connect Timing Engineering Change Notice (ECN) issued by
the USB-IF on the USB 2.0 spec allows that device to draw up to IUNIT while attached but not connected.
The conditions associated with this ECN are contained in Section 2 of this specification, and are referred to
as the Dead Battery Provision (DBP).

1.3       Reference Documents
The following specifications contain information relevant to the Battery Charging Specification.

      •    OTG and Embedded Host Supplement, Revision 2.0
      •    USB 2.0 Specification
      •    USB 3.0 Specification

1

   Battery Charging Specification, Revision 1.2                                                March 15, 2012

1.4       Definitions of Terms
This section contains definitions for some of the terms used in this specification.

1.4.1      Accessory Charger Adaptor
An Accessory Charger Adaptor (ACA) is an adaptor which allows a single USB port to be attached to both a
charger and another device at the same time.

The following terminology is used when referring to an ACA:

      •    ACA-A      An ACA with ID resistance of RID_A
      •    ACA-B      An ACA with ID resistance of RID_B
      •    ACA-C      An ACA with ID resistance of RID_C

See Section 6 for details on an ACA.

1.4.2      ACA-Dock
An ACA-Dock is a docking station that has one upstream port, and zero or more downstream ports. The
upstream port can be attached to a PD, and is capable of sourcing ICDP to the PD. An ACA-Dock signals it
is an ACA-Dock to the PD by enabling VDM_SRC during USB idle, and by pulling ID to ground through a
resistance of RID_A. See Section 3.2.4.4 for more details.

1.4.3      Attach versus Connect
This specification makes a distinction between the words “attach” and “connect”. A downstream device is
considered to be attached to an upstream port when there is a physical cable between the two.

A downstream device is considered to be connected to an upstream port when it is attached to the upstream
port, and when the downstream device has pulled either the D+ or D- data line high through a 1.5 kΩ
resistor, in order to enter Low-Speed, Full-Speed or High-Speed signaling.

1.4.4      Charging Downstream Port
A Charging Downstream Port (CDP) is a downstream port on a device that complies with the USB 2.0
definition of a host or a hub, except that it shall support the Charging Downstream Port features specified
herein.

A CDP shall output a voltage of VDM_SRC on its D- line when it senses a voltage greater than VDAT_REF but
less than VLGC on its D+ line when not connected to a peripheral. A CDP shall not output a voltage of
VDM_SRC on its D- line from the time that the peripheral is connected, to the time that the peripheral is
disconnected.

1.4.5      Charging Port
A Charging Port is a DCP, CDP, ACA-Dock or ACA.

1.4.6      Dead Battery Threshold
The Dead Battery Threshold is defined as the maximum charge level of a battery such that below this
threshold, a device is assured of not being able to power up successfully.

A Dead Battery is defined as one that is below the Dead Battery Threshold.

                                                                                                              2

    Battery Charging Specification, Revision 1.2                                               March 15, 2012

1.4.7   Dedicated Charging Port
A Dedicated Charging Port (DCP) is a downstream port on a device that outputs power through a USB
connector, but is not capable of enumerating a downstream device. A DCP shall source IDCP at an average
voltage of VCHG.

A DCP shall short the D+ line to the D- line.

1.4.8   Downstream Port
In this specification, a Downstream Port refers to either a Standard Downstream Port or a Charging
Downstream Port.

1.4.9   Micro ACA
A Micro ACA is an ACA with a Micro-AB receptacle on the Accessory Port.

1.4.10 Portable Device
A PD as used in this specification is a device which is compliant with this specification and the USB 2.0
specification, and can draw charging current from USB.

1.4.11 Rated Current
The Rated Current of a Charging Port is the amount of current that a Charging Port can output and still
maintain a VBUS voltage of VCHG. The Rated Current of a DCP is required to be within IDCP, and the rated
current of a CDP or ACA-Dock is required to be within ICDP.

1.4.12 Standard ACA
A Standard ACA is an ACA with a Standard-A receptacle on the Accessory Port.

1.4.13 Standard Downstream Port
In this specification, a Standard Downstream Port (SDP) refers to a downstream port on a device that
complies with the USB 2.0 definition of a host or hub. An SDP expects a downstream device with a good
battery to draw less than 2.5 mA average when unconnected or suspended, up to 100 mA maximum when
connected and not configured and not suspended, and up to 500 mA maximum if so configured and not
suspended. A downstream device can be enumerated when it is connected to an SDP.

An SDP pulls the D+ and D- lines to ground through two 15 kΩ (typical) resistors.

An SDP may have the ability to sense when a PD is driving the D+ line to VDP_SRC, and then manage its
power states accordingly. PDs are required to drive D+ to VDP_SRC whenever they draw more than ISUSP
while attached but not connected, as described in the Dead Battery Provision.

1.4.14 USB Charger
A USB Charger is a device with a DCP, such as a wall adapter or car power adapter.

1.4.15 Weak Battery Threshold
The Weak Battery Threshold is defined as the minimum charge level of a battery such that above this
threshold, a device is assured of being able to power up successfully.

3

   Battery Charging Specification, Revision 1.2                                             March 15, 2012

A Weak Battery is defined as one that is above the Dead Battery Threshold and below the Weak Battery
Threshold. A device with a Weak Battery may or may not be able to power up a device successfully.
A Good Battery is defined as one that is above the Weak Battery Threshold.

1.5       Parameter Values
Parameter names are used throughout this specification instead of parameter values. All parameter values
are found in Section 5.

1.6       OTG Considerations
A PD with a Dead Battery cannot differentiate between a PC and an OTG A-device. Thus, a PD will treat
both the same.

If an OTG A-device is connected to a PD with a dead battery, then the OTG A-device is under no obligation
to provide any more current than it normally would to any device on its Targeted Peripheral List (TPL).

An OTG A-device is allowed to stop driving VBUS after a time of TA_WAIT_BCON (See OTG 2.0 Supplement
for value) while waiting for the B-device to connect. Thus, a PD with a Dead Battery may not have time for
significant charging when attached to an OTG A-device, if it does not connect.

1.7       Super Speed Considerations
SuperSpeed ports defined in USB 3.0 are allowed to implement the charger detection mechanisms defined
in this spec. When a PD detects it is attached to a SuperSpeed port, then ICFG_MAX changes to 900mA, and
IUNIT changes to 150mA.

2. Dead Battery Provision
2.1       Background
The USB 2.0 specification allows a downstream device to draw a suspend current of up to ISUSP from a SDP
when the device is not connected or when the bus is suspended. If the bus is not suspended and the device
is configured, then USB 2.0 allows a device to draw up to ICFG_MAX, depending on the configuration the host
enables.

This limit of only ISUSP when not connected can be problematic for PDs with a Dead Battery or a Weak
Battery. Some PDs require more than IUNIT for several seconds just to power up. Thus, PDs with Dead
Batteries or Weak Batteries may not be able to power up when attached to an SDP if they can only draw
ISUSP when not connected.

USB 2.0 allows a PD that is a compound device to draw ISUSP for each downstream port while attached but
not connected or during suspend.

2.2       DBP – Unconfigured Clause
A PD with a Dead or Weak Battery is allowed to draw IUNIT from a Downstream Port using the DBP while not
configured, providing it behaves as follows:

      •    Reduces current to ISUSP after timeout
              o If PD is not ready to connect and be enumerated within TSVLD_CON_WKB after attach, then it
                 shall reduce its current to ISUSP

                                                                                                             4

    Battery Charging Specification, Revision 1.2                                              March 15, 2012

      •    Enables VDP_SRC when attached but not connected
              o PD shall enable VDP_SRC within TDBP_ATT_VDPSRC of attach
              o PD shall connect within TDBP_VDPSRC_CON of disabling VDP_SRC

      •    Uses current to power up and enumerate, or reach Weak Battery Threshold and enumerate, as soon
           as possible
               o PD shall not use the DBP current to perform unrelated tasks, such as:
                        Charging beyond the Weak Battery Threshold
                        Making a phone call
                        Playing a song, video or game
                        Establishing a wireless connection
               o Only devices that can operate stand-alone from internal battery power are allowed to use the
                   DBP.

      •    Passes inrush test
              o PD with Dead or Weak Battery shall pass USB-IF compliance inrush test

The unconfigured state includes the time that the PD is attached and not connected, and the time that the
PD is connected and not configured. A PD enters the configured state by receiving a
SET_CONFIGURATION command from the host.

2.3       DBP – Configured Clause
A PD with a Dead or Weak Battery is allowed to draw its configured current, (which can be up to ICFG_MAX),
from a Standard Downstream Port using the Dead Battery Provision (DBP) while configured, and not have to
pass USBCV tests, providing it behaves as follows:

      •    Responds to received tokens
              o PD shall respond to any tokens addressed to it, with either a NAK or any other valid USB
                 response

      •    Responds to USB reset
              o Upon receipt of USB reset, a PD shall reduce its current to IUNIT. PD is allowed to
                 disconnect upon receiving a reset. While disconnected, PD is allowed to use the DBP –
                  Unconfigured Clause.

      •    Responds to USB suspend
              o Upon receipt of USB suspend, PD shall either remain connected, and reduce its current to
                 ISUSP, or it shall disconnect. While disconnected, the PD is allowed to use the DBP –
                 Unconfigured Clause.

      •    Provides full USB functionality after timeout, or disconnects
              o After a time of TDBP_FUL_FNCTN from attach, a PD shall either remain connected and be able
                  to pass USBCV, or it shall disconnect. While disconnected, the PD is allowed to use the
                  DBP – Unconfigured Clause.

      •    Uses current to reach Weak Battery Threshold and provide full USB functionality as soon as
           possible
              o PD shall not use the DBP current to perform unrelated tasks, such as:
                       Charging beyond the Weak Battery Threshold
                       Making a phone call
                       Playing a song, video or game
                       Establishing a wireless connection

5

   Battery Charging Specification, Revision 1.2                                                  March 15, 2012

      •    Provides full USB functionality upon reaching Weak Battery Threshold
              o PD shall provide full USB functionality upon reaching Weak Battery Threshold if this occurs
                  before TDBP_FUL_FNCTN after attach.

      •    PD informs user within TDBP_INFORM of attach that it is charging and not available for other functions

3. Charging Port Detection
3.1       Overview
Figure 3-1 shows several examples of a PD attached to an SDP or Charging Port.

                                     Portable               VBUS           SDP, CDP
                                      Device                 D-             or DCP
                                                             D+
                                         µ-B or             GND
                                                µ-B                   Std-A Std-A
                                         µ-AB
                                         Recep  Plug     Detachable   Plug Recep
                                                           Cable

                                     Portable                                 DCP
                                      Device
                                                            VBUS
                                         µ-B or             GND
                                                µ-B
                                         µ-AB
                                         Recep Plug         Captive
                                                             Cable

                                                                   DCP
                                                                    or
                                                  VBUS             CDP
                              Portable             D-
                               Device              D+
                                                   ID
                                   µ-AB µ-A       GND
                                   Recep Plug                     ACA          Accessory
                                                  Captive
                                                   Cable

                                                       Portable
                                                        Device

                                                                               Peripheral
                                                        µ-AB
                              Prop                      Recep
                              Chgr                       µ-A
                                                         Plug
                                                                               Peripheral
                                                   ACA-Dock

                                           Figure 3-1 System Overview

                                                                                                                6

    Battery Charging Specification, Revision 1.2                                              March 15, 2012

In the first example, a Std-A to Micro-B cable is used to attach a PD to an SDP, CDP or DCP. In the second
example, a DCP has a captive cable. This cable does not have wires for D+ or D-, but instead shorts the D+
and D- pins at the Micro-B plug.

In the third example, an ACA is required to have a captive cable that attaches to the Portable Device, and
this cable is required to have wires for D+, D- and ID. The ACA is also required to have a port that can be
attached to a DCP or CDP. The cabling for this port is described in Section 6.2.1.

In the fourth example, an ACA-Dock does not have a cable at all, but instead has a captive Micro-A plug. An
ACA-Dock receives power from a Proprietary Charger, that is attached to the ACA-Dock through a
proprietary cable.

3.2   Charger Detection Hardware
This section briefly describes the hardware used to do charger detection. The following sections provide
more details of its operation.

7

   Battery Charging Specification, Revision 1.2                                            March 15, 2012

3.2.1     Overview
Figure 3-2 shows the charger detection hardware for a PD.

                   Portable Device
                                                               VBUS    VBUS Detect
                                               VOTG_SESS_VLD
                                                                       Detect when VBUS is asserted
        RDAT_LKG                                               D+

                                 VDP_SRC

        VDAT_LKG                                                       Data Contact Detect
                                 VLGC_HI
                                             IDP_SRC                   Detect when data pins have made
                   DCHG_DET
                                                                       contact
                                                  VDAT_REF

                                       IDP_SINK
                                                                       Primary Detection

                                                                       Detects between SDP and DCP/
         PHY                                                           CDP, or between ACA-Dock and
                    CHG_DET
                                                                       ACA_A
                                                  VDAT_REF

                                      IDM_SINK

                                VDM_SRC                                Secondary Detection
        RDAT_LKG                                               D-      Detects between DCP and CDP

                                         RDM_DWN
        VDAT_LKG

                                                                       ACA Detection
                              ID Comparators          ID
                                       REF          Pull-up            Detects between:
                                                               ID            DCP/CDP/SDP
                                                                             ACA-Dock/ACA_A
                                                               GND           ACA_B
                                                                             ACA_C

                                      Figure 3-2 Charger Detection Hardware
3.2.2     VBUS Detect
Each PD shall have a session valid comparator that detects when VBUS is greater than its internal session
valid threshold. Its internal session valid threshold shall be within VOTG_SESS_VLD.

                                                                                                            8

    Battery Charging Specification, Revision 1.2                                           March 15, 2012

3.2.3     Data Contact Detect
3.2.3.1    Overview
Data Contact Detect (DCD) uses a current source, IDP_SRC, to detect when the data pins have made contact
during an attach event. A PD is not required to implement DCD. If a PD does not implement DCD, then it
shall wait a time of TDCD_TIMEOUT min after the attach event before starting Primary Detection.

DCD is able to detect data pin contact whenever a PD is attached to an SDP or CDP. The primary benefit of
DCD is that it allows a PD to start Primary Detection as soon as the data pins have made contact, and then
connect, without having to wait for a timer to expire. As per the USB Connect Timing ECN, a powered up
USB device is required to connect to a USB host within TSVLD_CON_PWD of the attach event.

DCD is also able to detect data pin contact for most cases of a PD attached to a DCP or ACA. Cases where
DCD may not work include:

    •     DCP with too much leakage current
    •     ACA with charger and FS or HS B-device on Accessory Port
    •     ACA-Dock
    •     PS2 port that pulls D+ high
    •     Proprietary chargers that pull D+ high

Since DCD does not work in all cases, a PD is required to proceed to Primary Detection within
TDCD_TIMEOUT max after the attach event if pin contact has not been detected on the D+ or ID pins. See
Section 3.3.2.

9

   Battery Charging Specification, Revision 1.2                                              March 15, 2012

3.2.3.2   Problem Description
USB plugs and receptacles are designed such that when the plug is inserted into the receptacle, the power
pins make contact before the data pins make contact. This is illustrated in Figure 3-3.

                                      Plug            Receptacle
                       VBUS                                                    VBUS
                           D-                                                  D-
                          D+                                                   D+
                        GND                                                    GND

                                        Figure 3-3 Data Pin Offset

As a result, when a PD is attached to an upstream port, the PD will detect VBUS before the data pins have
made contact. The time between power pins and data pins making contact depends on how fast the plug is
inserted into the receptacle. Delays of more than two hundred milliseconds have been observed.

The way that a PD distinguishes between a Charging Port and an SDP is to look at the data lines. If the PD
does Primary Detection before the data pins have made contact, then the Primary Detection protocol is such
that the PD will determine that it is attached to an SDP.

If a PD is attached to a DCP, and incorrectly determines that it is attached to an SDP, then the PD would
draw ISUSP while waiting to be enumerated. Since a DCP will not enumerate the PD, the PD will not be
able to charge.

                                                                                                            10

     Battery Charging Specification, Revision 1.2                                               March 15, 2012

3.2.3.3    Data Contact Detect, Not Attached
Figure 3-4 shows the case where the PD is not attached to a remote device.

                                        Portable Device
                                                                                      VBUS

                                                                     VOTG_SESS_VLD

                             RDAT_LKG                                                     D+

                                                       VDP_SRC

                             VDAT_LKG
                                                       VLGC_HI
                                                                   IDP_SRC

                                         DCP_DET

                                                                        VDAT_REF

                                                             IDP_SINK

                              PHY        CHG_DET

                                                                        VDAT_REF

                                                            IDM_SINK

                                                      VDM_SRC

                             RDAT_LKG                                                     D-

                                                               RDM_DWN
                             VDAT_LKG

                                                    ID Comparators          ID
                                                             REF          Pull-up
                                                                                     ID

                                                                                          GND

                               Figure 3-4 Data Contact Detect, Not Attached
The protocol for Data Contact Detect is as follows:

     •    PD detects VBUS asserted
     •    PD turns on IDP_SRC and the D- pull-down resistor
     •    PD waits for D+ line to be low for a time of TDCD_DBNC
     •    PD turns off IDP_SRC and D- pull-down resistor

11

   Battery Charging Specification, Revision 1.2                                              March 15, 2012

When nothing is attached to the PD, the D+ line stays high. The minimum value of IDP_SRC is such that it is
able to hold D+ at VLGC_HI for worst case leakages in the PD due to RDAT_LKG and VDAT_LKG.

                                                                                                          12

     Battery Charging Specification, Revision 1.2                                        March 15, 2012

3.2.3.4   Data Contact Detect, Standard Downstream Port
Figure 3-5 shows the case where the PD is attached to an SDP.

                Portable Device                                         Standard Downstream Port
                                                              VBUS

                                             VOTG_SESS_VLD

     RDAT_LKG                                                     D+                        RDAT_LKG

                               VDP_SRC                                       RDP_DWN

     VDAT_LKG                                                                               VDAT_LKG
                               VLGC_HI
                                           IDP_SRC

                 DCP_DET

                                                VDAT_REF

                                     IDP_SINK

       PHY       CHG_DET
                                                                                             PHY
                                                VDAT_REF

                                    IDM_SINK

                              VDM_SRC

     RDAT_LKG                                                     D-                        RDAT_LKG

                                                                             RDM_DWN
                                       RDM_DWN
     VDAT_LKG                                                                               VDAT_LKG

                            ID Comparators          ID
                                     REF          Pull-up
                                                             ID

                                                                  GND

                           Figure 3-5 Data Contact Detect, Standard Downstream Port

When the PD is attached to an SDP, the D+ line is pulled low by RDP_DWN in the SDP. The maximum value
of IDP_SRC is such that RDP_DWN pulls D+ to VLGC_LOW for worst values of RDAT_LKG, VDAT_LKG and
RDP_DWN.

13

   Battery Charging Specification, Revision 1.2                                            March 15, 2012

3.2.4     Primary Detection
Primary Detection is used to distinguish between an SDP and different types of Charging Ports. A PD is
required to implement Primary Detection.

3.2.4.1     Primary Detection, DCP
Figure 3-6 shows how Primary Detection works when a PD is attached to a DCP.

                   Portable Device                                        Dedicated Charging Port
                                                                VBUS

                                               VOTG_SESS_VLD

        RDAT_LKG                                                    D+                      RDAT_LKG

                                 VDP_SRC

        VDAT_LKG                                                                            VDAT_LKG
                                 VLGC_HI
                                             IDP_SRC

                    DCP_DET

                                                  VDAT_REF

                                       IDP_SINK
                                                                                        RDCP_DAT

         PHY        CHG_DET

                                                  VDAT_REF

                                      IDM_SINK

                                VDM_SRC

        RDAT_LKG                                                    D-                        RDAT_LKG

                                         RDM_DWN
        VDAT_LKG                                                                              VDAT_LKG

                              ID Comparators          ID
                                       REF          Pull-up
                                                               ID

                                                                    GND

                                          Figure 3-6 Primary Detection, DCP

                                                                                                         14

     Battery Charging Specification, Revision 1.2                                           March 15, 2012

During Primary Detection the PD shall turn on VDP_SRC and IDM_SINK. Since a DCP is required to short D+
to D- through a resistance of RDCP_DAT, the PD will detect a voltage on D- that is close to VDP_SRC.

A PD shall compare the voltage on D- with VDAT_REF. If D- is greater than VDAT_REF, then the PD is allowed
to detect that it is attached to either a DCP or CDP. A PD is optionally allowed to compare D- with VLGC as
well, and only determine that it is attached to a DCP or CDP if D- is greater than VDAT_REF, but less than
VLGC. The reason for this option is as follows.

PS2 ports pull D+/- high. If a PD is attached to a PS2 port, and the PD only checks for D- greater than
VDAT_REF, then a PD attached to a PS2 port would determine that it is attached to a DCP or CDP and
proceed to draw IDEV_CHG. This much current could potentially damage a PS2 port. By only determining it is
attached to DCP or CDP if D- is less than VLGC, the PD can avoid causing damage to a PS2 port.

On the other hand, some proprietary chargers also pull D+/- high. If a PD is attached to one of these
chargers, and it determined it was not attached to a charger because D- was greater than VLGC, then the PD
would determine that it was attached to an SDP, and only be able to draw ISUSP.

The choice of whether or not to compare D- to VLGC depends on whether the PD is more likely to be
attached to a PS2 port, or to a proprietary charger.

15

   Battery Charging Specification, Revision 1.2                                                   March 15, 2012

3.2.4.2   Primary Detection, CDP
Figure 3-7 shows how Primary Detection works when a PD is attached to a CDP.

               Portable Device                                        Charging Downstream Port
                                                            VBUS

                                           VOTG_SESS_VLD

    RDAT_LKG                                                    D+                                      RDAT_LKG

                             VDP_SRC                                             RDP_DWN

    VDAT_LKG                                                                                            VDAT_LKG
                             VLGC_HI
                                         IDP_SRC

                DCP_DET                                                                     PRTBL_DET

                                              VDAT_REF                VDAT_REF

                                   IDP_SINK                                      IDP_SINK

      PHY       CHG_DET
                                                                                                         PHY
                                              VDAT_REF

                                  IDM_SINK

                                                                                 VDM_SRC
                            VDM_SRC

    RDAT_LKG                                                    D-                                      RDAT_LKG

                                                                                 RDM_DWN
                                     RDM_DWN
    VDAT_LKG                                                                                            VDAT_LKG

                          ID Comparators          ID
                                   REF          Pull-up
                                                           ID

                                                                GND

                                           Figure 3-7 Primary Detection, CDP
A CDP is required to behave in either one of two ways when a remote device is not connected to it. The first
way that a CDP is allowed to behave is to enable VDM_SRC within TCP_VDM_EN of a disconnect, and then
disable VDM_SRC within TCP_VDM_DIS of a connect. When using this option, a CDP is not required to enable
IDP_SINK, or to compare D+ to VDAT_REF.

The second way a CDP is allowed to behave is to compare D+ with VDAT_REF and VLGC. When D+ is
greater than VDAT_REF and less than VLGC, the CDP shall enable VDM_SRC. When D+ is less than VDAT_REF

                                                                                                                   16

     Battery Charging Specification, Revision 1.2                                          March 15, 2012

or greater than VLGC, the CDP shall disable VDM_SRC. Note that a CDP is required to compare D+ to VLGC,
in order to disable VDM_SRC when the PD connects. See Section 3.4.2 for timing.

During Primary Detection the PD shall turn on VDP_SRC and IDM_SINK. A PD shall compare the voltage on D-
with VDAT_REF. If D- is greater than VDAT_REF, then the PD is allowed to determine that it is attached to
either a DCP or CDP. A PD is optionally allowed to compare D- with VLGC as well, and only determine that it
is attached to a DCP or CDP if D- is greater than VDAT_REF, but less than VLGC. See Section 3.2.4.1 for
more details.

17

   Battery Charging Specification, Revision 1.2                                            March 15, 2012

3.2.4.3   Primary Detection, SDP
Figure 3-8 shows how Primary Detection works when a PD is attached to an SDP.

               Portable Device                                        Standard Downstream Port
                                                            VBUS

                                           VOTG_SESS_VLD

    RDAT_LKG                                                    D+                             RDAT_LKG

                             VDP_SRC                                           RDP_DWN

    VDAT_LKG                                                                                   VDAT_LKG
                             VLGC_HI
                                         IDP_SRC

                DCP_DET

                                              VDAT_REF

                                   IDP_SINK

      PHY       CHG_DET
                                                                                                PHY
                                              VDAT_REF

                                  IDM_SINK

                            VDM_SRC

    RDAT_LKG                                                    D-                             RDAT_LKG

                                                                               RDM_DWN
                                     RDM_DWN
    VDAT_LKG                                                                                   VDAT_LKG

                          ID Comparators          ID
                                   REF          Pull-up
                                                           ID

                                                                GND

                                           Figure 3-8 Primary Detection, SDP

During Primary Detection the PD shall turn on VDP_SRC and IDM_SINK. When a voltage of VDP_SRC is applied
to D+, an SDP will continue pulling D- low through RDM_DWN.

A PD shall compare the voltage on D- with VDAT_REF. If D- is less than VDAT_REF, then the PD is allowed to
determine that it is attached to an SDP. A PD is optionally allowed to compare D- with VLGC as well, and
determine that it is attached to an SDP if D- is greater than VLGC. See Section 3.2.4.1 for more details.

                                                                                                          18

     Battery Charging Specification, Revision 1.2                                                    March 15, 2012

3.2.4.4   Primary Detection, ACA-Dock
Figure 3-9 shows how Primary Detection works when a PD that supports ACA Detection is attached to an
ACA-Dock.

                Portable Device                                         ACA-Dock
                                                            VBUS

                                            VOTG_SESS_VLD

     RDAT_LKG                                                    D+

                             VDP_SRC                                                                       Power
                                                                                 Power Mgr
                                                                                                           Supply
     VDAT_LKG
                              VLGC_HI
                                        IDP_SRC

                 DCP_DET                                                              Hub
                                               VDAT_REF
                                                                             Upstrm
                                                                              Port          Port 1         Periph
                                                                      VBUS
                                    IDP_SINK

                                                                             VDP_UP

       PHY       CHG_DET                                                D+
                                                                                            Port 2         Periph
                                               VDAT_REF                      RDP_UP

                                   IDM_SINK
                                                                        D-

                             VDM_SRC

     RDAT_LKG                                                    D-                         Port N         Periph

                                      RDM_DWN
     VDAT_LKG
                                                                                 VDM_SRC

                           ID Comparators          ID
                                    REF          Pull-up
                                                            ID                   RID_A

                                                            GND

                                      Figure 3-9 Primary Detection, ACA-Dock

An ACA-Dock is a docking station that has one upstream port, and zero or more downstream ports. The
upstream port can be attached to a PD, and is capable of sourcing ICDP to the PD.

19

   Battery Charging Specification, Revision 1.2                                               March 15, 2012

When an ACA-Dock is powered, but nothing is attached to its upstream port, it is required to bias the pins on
its upstream port as follows:

    •   VBUS        VCHG
    •   D+          VDP_UP
    •   D-          VDM_SRC
    •   ID          RID_A
    •   GND         GND

The VBUS pin is at VCHG because the ACA-Dock is ready to provide power to a PD. The ACA-Dock is
required to pull D+ to VDP_UP through RDP_UP because the VBUS pin is greater than VOTG_SESS_VLD.

An ACA-Dock is required to enable VDM_SRC whenever D+/- have been inactive (at idle J state) for a time of
TCP_VDM_EN. An ACA-Dock is required to disable VDM_SRC within TCP_VDM_DIS of any activity on D+/-.

An ACA-Dock is required to present an impedance to ground on ID of RID_A whenever it is powered. It is
required to present an impedance to ground on ID of RID_FLOAT when it is not powered.

When a PD that supports ACA detects the following conditions, it shall determine that it is attached to an
ACA-Dock:

    •   VBUS > VOTG_SESS_VLD
    •   D+ at VLGC_HI
    •   VDAT_REF < D- < VLGC
    •   ID at RID_A

Note that a PD attached to an ACA-Dock is required to compare D- with VLGC. If a PD were attached to an
ACA that had a LS peripheral on its Accessory Port, then the ID pin of the PD would be pulled to ground
through RID_A, and the D- pin would be at VLGC_HI instead of VDM_SRC. In order to distinguish between an
ACA with a LS device and an ACA-Dock, the PD is required to detect if D- is above or below VLGC.

The VDP_SRC in the PD shall be such that D+ remains at a logic high while the ACA-Dock is pulling D+ to
VDP_UP through RDP_UP. The reason for this is so that the ACA-Dock does not detect activity on D+, which
could cause it to turn off its VDM_SRC before the PD completes its Primary Detection.

                                                                                                             20

     Battery Charging Specification, Revision 1.2                                                          March 15, 2012

3.2.4.5    Primary Detection, Micro ACA
Figure 3-10 shows how Primary Detection works when a PD that supports ACA Detection is attached to a
Micro ACA.

                Portable Device
                                                            VBUS

                                            VOTG_SESS_VLD

     RDAT_LKG                                               D+

                              VDP_SRC

     VDAT_LKG
                              VLGC_HI
                                          IDP_SRC

                 DCP_DET

                                               VDAT_REF

                                    IDP_SINK

                                                                                      Micro ACA
      PHY        CHG_DET

                                               VDAT_REF                  VBUS             Accessory            VBUS_ACC
                                                                                           Switch

                                   IDM_SINK                               D+                                   DP_ACC

                             VDM_SRC

     RDAT_LKG                                                      D-                                          DN_ACC
                                                                                                               ID_ACC

                                      RDM_DWN
     VDAT_LKG                                                                   Charger                        VBUS_CHG
                                                                                Switch
                           ID Comparators          ID
                                    REF          Pull-up
                                                                                               Adapter         DP_CHG
                                                                   ID
                                                                                              Controller       DN_CHG
                                                                   GND

                                               Figure 3-10 Primary Detection, ACA

A PD that supports ACA Detection is required to monitor the resistance on the ID pin whenever VBUS is
greater than VOTG_SESS_VLD. If the ID resistance is RID_B or RID_C, then the PD knows that it is attached to
an ACA. If the ID resistance is RID_A, then the PD could be attached to either an ACA with a B-device on its
Accessory Port, or to an ACA-Dock.

21

   Battery Charging Specification, Revision 1.2                                               March 15, 2012

In order to distinguish between an ACA with an B-device, and an ACA-Dock, the PD shall compare the
voltage on D- with VDAT_REF and VLGC to detect what it is attached to as follows:

    •   D- < VDAT_REF                ACA with FS B-device on Accessory Port
    •   VDAT_REF < D- < VLGC         ACA-Dock
    •   VLGC < D-                    ACA with LS B-device on Accessory Port

The PD shall do the above detection on D- after attach, and before connect, as shown in the Good Battery
Algorithm.

After doing Primary Detection, a PD that supports ACA Detection shall continue to monitor the ID line. If this
resistance changes, the PD shall respond according to the state machine defined in Section 6.2.7.

An ACA is required to do a form of Primary Detection over the DP_CHG and DN_CHG lines to detect if a
Charging Port is attached to the ACA Charger Port. This detection is done with the lines highlighted in
yellow, and is described in Section 6.2.6.

3.2.5   Secondary Detection
Secondary Detection can be used to distinguish between a DCP and a CDP. PDs that are not ready to be
enumerated within TSVLD_CON_PWD of detecting VBUS are required to implement Secondary Detection. PDs
that are ready to be enumerated are allowed to bypass Secondary Detection. See Section 3.3.2 on Good
Battery Algorithm.

                                                                                                            22

     Battery Charging Specification, Revision 1.2                                        March 15, 2012

3.2.5.1   Secondary Detection, DCP
Figure 3-11 shows how Secondary Detection works when a PD is attached to a DCP.

                 Portable Device                                        Dedicated Charging Port
                                                              VBUS

                                             VOTG_SESS_VLD

      RDAT_LKG                                                    D+                        RDAT_LKG

                               VDP_SRC

      VDAT_LKG                                                                              VDAT_LKG
                               VLGC_HI
                                           IDP_SRC

                  DCP_DET

                                                VDAT_REF

                                     IDP_SINK
                                                                                      RDCP_DAT

       PHY        CHG_DET

                                                VDAT_REF

                                    IDM_SINK

                              VDM_SRC

      RDAT_LKG                                                    D-                        RDAT_LKG

                                       RDM_DWN
      VDAT_LKG                                                                              VDAT_LKG

                            ID Comparators          ID
                                     REF          Pull-up
                                                             ID

                                                                  GND

                                     Figure 3-11 Secondary Detection, DCP
During Secondary Detection, a PD shall output VDM_SRC on D-, turn on IDP_SINK, and compare the voltage
on D+ to VDAT_REF. Since a DCP is required to short D+ to D- through a resistance of RDCP_DAT, the
voltage on D+ will be close to VDM_SRC, which is above VDAT_REF.

23

   Battery Charging Specification, Revision 1.2                                                   March 15, 2012

If a PD detects that D+ is greater than VDAT_REF, it knows that it is attached to a DCP. It is then required to
enable VDP_SRC or pull D+ to VDP_UP through RDP_UP, as defined in the Good Battery Algorithm in
Section 3.3.2.

A PD is not required to compare D+ to VLGC during Secondary Detection.

3.2.5.2   Secondary Detection, CDP
Figure 3-12 shows how Secondary Detection works when a PD is attached to a CDP.

               Portable Device                                        Charging Downstream Port
                                                            VBUS

                                           VOTG_SESS_VLD

    RDAT_LKG                                                    D+                                      RDAT_LKG

                             VDP_SRC                                             RDP_DWN

    VDAT_LKG                                                                                            VDAT_LKG
                             VLGC_HI
                                         IDP_SRC

                DCP_DET                                                                     PRTBL_DET

                                              VDAT_REF                VDAT_REF

                                   IDP_SINK                                      IDP_SINK

      PHY       CHG_DET
                                                                                                         PHY
                                              VDAT_REF

                                  IDM_SINK

                                                                                 VDM_SRC
                            VDM_SRC

    RDAT_LKG                                                    D-                                      RDAT_LKG

                                                                                 RDM_DWN
                                     RDM_DWN
    VDAT_LKG                                                                                            VDAT_LKG

                          ID Comparators          ID
                                   REF          Pull-up
                                                           ID

                                                                GND

                                       Figure 3-12 Secondary Detection, CDP

                                                                                                                   24

     Battery Charging Specification, Revision 1.2                                                March 15, 2012

During Secondary Detection, a PD shall output VDM_SRC on D-, turn on IDP_SINK, and compare the voltage
on D+ to VDAT_REF. Since a CDP does not short D+ to D-, the voltage on D+ will be close to ground, which
is below VDAT_REF.

If a PD detects that D+ is less than VDAT_REF, it knows that it is attached to a CDP. It is then required to turn
off VDP_SRC and VDM_SRC, as shown in the Good Battery Algorithm in Section 3.3.2, and is allowed to draw
IDEV_CHG.

A PD is not required to compare D+ to VLGC during Secondary Detection.

3.2.6    ACA Detection
ACA Detection allows a PD to detect when it is attached to an ACA, and to detect what type of device is
attached to the ACA Accessory Port. See Section 6 for a description of the ACA.

A PD is not required to support ACA Detection. Only PDs that have a Micro-AB receptacle can support ACA
Detection, since the ACA OTG Port has a captive cable terminating in a Micro-A plug.

PDs that support ACA Detection are required to implement the Good Battery Algorithm defined in
Section 3.3.2.

25

   Battery Charging Specification, Revision 1.2                                                          March 15, 2012

Figure 3-13 shows how ACA Detection works when a PD is attached to a Micro ACA.

               Portable Device
                                                           VBUS

                                           VOTG_SESS_VLD

    RDAT_LKG                                               D+

                             VDP_SRC

    VDAT_LKG
                             VLGC_HI
                                         IDP_SRC

                DCP_DET

                                              VDAT_REF

                                   IDP_SINK

                                                                                    Micro ACA
        PHY     CHG_DET

                                              VDAT_REF                 VBUS             Accessory            VBUS_ACC
                                                                                         Switch

                                  IDM_SINK                               D+                                  DP_ACC

                            VDM_SRC

    RDAT_LKG                                                      D-                                         DN_ACC
                                                                                                             ID_ACC

                                     RDM_DWN
    VDAT_LKG                                                                  Charger                        VBUS_CHG
                                                                              Switch
                          ID Comparators          ID
                                   REF          Pull-up
                                                                                             Adapter         DP_CHG
                                                                  ID
                                                                                            Controller       DN_CHG
                                                                  GND

                                                    Figure 3-13 ACA Detection

A PD detects the presence of an ACA by sensing the resistance on the ID pin. There are five different
resistance values that shall be detected during ACA Detection, namely: RID_GND, RID_C, RID_B, RID_A and
RID_FLOAT. PDs that support ACA Detection shall monitor the ID resistance during the entire time that VBUS
is asserted, and respond according to the PD State Machine in Section 6.2.7.

Note: It is important that designers take into account the following factors when designing circuitry to
distinguish these ID pin resistance values:

    •    The resistance has to be correctly detected in the presence of a voltage drop in the ACA cable
         ground resulting from IDEV_CHG flowing through ROTG_ACA_GND, causing the ACA ground to be
         lower than the OTG ground.

                                                                                                                      26

     Battery Charging Specification, Revision 1.2                                            March 15, 2012

     •   The resistance has to be correctly detected in the presence of a voltage drop in the ACA cable
         ground resulting from ICFG_MAX flowing through ROTG_ACA_GND causing the ACA ground to be
         higher than the OTG ground.
     •   Leakage currents (Table 5-3, Note 2) should be considered and their effects also taken into account.

27

   Battery Charging Specification, Revision 1.2                                                       March 15, 2012

3.3     Charger Detection Algorithms
3.3.1    Weak Battery Algorithm
Figure 3-14 shows an example charger detection algorithm for a PD with a Weak Battery. Other algorithms
are allowed, providing they comply with the DBP.

                                              Check
                                              VBUS                           Weak Battery
                               Else                                          Algorithm is
                                                                               Optional

                                      VBUS > V OTG_SESS_VLD                  Recommended

                                               SDP                                Optional
                                               IUNIT
                                                                            Optional for ACA
                                                                               Detection
                                          D+ = V DP_SRC
                                           Start Timer

                                                   Timer < TSVLD_CON _WKB
                               Else

                                          Not ready to                Ready to          Timer > =
                                            connect .                 connect .      TSVLD _CON_WKB

                Prevents charging                   D - > V DAT_REF
                from PS 2 ports and                        &
                 some proprietary                      D- < V LGC
                     chargers                               +
                                                    ID != RID_FLOAT
                                          Charging Port
                                              I DCP

                               Else

                                       Ready to
                                       connect .

                                       Go to Good Battery                                     SDP
                                            Algorithm                                        ISUSP

                                      Figure 3-14 Weak Battery Algorithm

                                                                                                                 28

     Battery Charging Specification, Revision 1.2                                            March 15, 2012

A PD is required to have internal voltage thresholds that lie within VOTG_SESS_VLD, VDAT_REF and VLGC. In
the above algorithm, a PD compares VBUS, D+ and D- with its internal thresholds. It does not compare
VBUS, D+ and D- with the min or max value of VOTG_SESS_VLD, VDAT_REF or VLGC.

In the above example, a PD with a Weak Battery detects VBUS greater than VOTG_SESS_VLD, and applies a
voltage of VDP_SRC on the D+ pin. If the voltage on D- is greater than its VDAT_REF, or if the ID pin is not
floating, the PD is allowed to draw IDEV_CHG. Else the PD is allowed to draw IUNIT.

The VLGC term shown in magenta could be added to prevent a PD from charging from PS2 ports and some
proprietary chargers.

29

   Battery Charging Specification, Revision 1.2                                                                          March 15, 2012

3.3.2   Good Battery Algorithm
Figure 3-15 shows the charger detection algorithm that a PD with a Good Battery is required to implement. It
may also be used by a PD with a Weak Battery, subject to meeting the requirements of the Dead Battery
Provision.

Thus a PD, having reached the bottom of the flow chart may in all cases, with the exception of the DCP/CDP
exit, delay for up to TSVLD_CON_WKB before connecting or applying a bus reset as appropriate.

                                                                Check
                                                                VBUS                   Good Battery              ACA Detection
                                                    Else                               Algorithm is               is Optional
                                                                                        Required
                                                                                                                  Required for
                                                        VBUS > VOTG_SESS_VLD              Required               ACA Detection

                                                              Start Tmr                   Optional                Optional for
                                                             Enable DCD                                          ACA Detection

                                                    Else

                                                             TDCD_TIMEOUT
                                                                  +
                                                       D+ < VLGC for TDCD_DBNC
                                                                  +
                                                    ID != RID_FLOAT for TDCD_DBNC              ID != RID_FLOAT for TDCD_DBNC

                                                           Primary Detection
                                                             D+ = VDP_SRC

                                                                                    ID != RID_FLOAT
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

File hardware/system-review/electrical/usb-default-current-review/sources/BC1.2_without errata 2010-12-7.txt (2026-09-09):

Battery Charging Specification
                       Revision 1.2
                   December 7, 2010

                 Copyright © 2010, USB Implementers Forum, Inc.
                               All rights reserved.

A LICENSE IS HEREBY GRANTED TO REPRODUCE THIS SPECIFICATION FOR
INTERNAL USE ONLY. NO OTHER LICENSE, EXPRESS OR IMPLIED, BY ESTOPPEL OR
OTHERWISE, IS GRANTED OR INTENDED HEREBY.

USB-IF AND THE AUTHORS OF THIS SPECIFICATION EXPRESSLY DISCLAIM ALL
LIABILITY FOR INFRINGEMENT OF INTELLECTUAL PROPERTY RIGHTS, RELATING
TO IMPLEMENTATION OF INFORMATION IN THIS SPECIFICATION. USB-IF AND THE
AUTHORS OF THIS SPECIFICATION ALSO DO NOT WARRANT OR REPRESENT THAT
SUCH IMPLEMENTATION(S) WILL NOT INFRINGE THE INTELLECTUAL PROPERTY
RIGHTS OF OTHERS.

THIS SPECIFICATION IS PROVIDED "AS IS” AND WITH NO WARRANTIES, EXPRESS OR
IMPLIED, STATUTORY OR OTHERWISE. ALL WARRANTIES ARE EXPRESSLY
DISCLAIMED. NO WARRANTY OF MERCHANTABILITY, NO WARRANTY OF NON-
INFRINGEMENT, NO WARRANTY OF FITNESS FOR ANY PARTICULAR PURPOSE, AND
NO WARRANTY ARISING OUT OF ANY PROPOSAL, SPECIFICATION, OR SAMPLE.

IN NO EVENT WILL USB-IF OR USB-IF MEMBERS BE LIABLE TO ANOTHER FOR THE
COST OF PROCURING SUBSTITUTE GOODS OR SERVICES, LOST PROFITS, LOSS OF
USE, LOSS OF DATA OR ANY INCIDENTAL, CONSEQUENTIAL, INDIRECT, OR SPECIAL
DAMAGES, WHETHER UNDER CONTRACT, TORT, WARRANTY, OR OTHERWISE,
ARISING IN ANY WAY OUT OF THE USE OF THIS SPECIFICATION, WHETHER OR NOT
SUCH PARTY HAD ADVANCE NOTICE OF THE POSSIBILITY OF SUCH DAMAGES.

ii

   Battery Charging Specification, Revision 1.2                            December 7, 2010

Contributors
Mark Lai                       Allion Test Labs
Sammy Mbanta                   Astec Power
Abel Astley                    Broadcom
Kenneth Ma                     Broadcom
Shimon Elkayam                 Broadcom
Gaurav Singh                   Cypress
Dan Ellis                      DisplayLink
Graham Connolly                Fairchild
Oscar Freitas                  Fairchild
Joel Silverman                 Kawasaki
Pat Crowe                      MQP Electronics
Juha Heikkila                  Nokia
Richard Petrie                 Nokia
Sten Carlsen                   Nokia
Jeroen Kleinpenning            NXP Semiconductors
Terry Remple, Chair            Qualcomm
Dave Haglan                    SMSC
Mark Bohm                      SMSC
Morgan Monks                   SMSC
Tim Knowlton                   SMSC
Morten Christiansen            ST Ericsson
Nicolas Florenchie             ST Ericsson
Shaun Reemeyer                 ST Ericsson
George Paparrizos              Summit Microelectronics
Adam Burns                     Synopsys
Wei Ming                       Telecommunication Metrology Center of MII
Jean Picard                    Texas Instruments
Ivo Huber                      Texas Instruments
Pasi Palojarvi                 Texas Instruments
Steven Tom                     Texas Instruments
Ed Beeman                      USB-IF
Mark Paxson                    USB-IF

                                                                                         iii

     Battery Charging Specification, Revision 1.2                                           December 7, 2010

Revision History
Revision        Date             Author             Description
BC1.0           Mar 8, 2007      Terry Remple       First release

BC1.1           April 15, 2009   Terry Remple       Major updates to all sections. Added Data Contact
                                                    Detect protocol, and Accessory Charger Adapter.

BC1.2           Oct 5, 2010      Terry Remple       Following items indicate changes from BC1.1 to
                                 Adam Burns         BC1.2. References below to Section, Figures and
                                                    Tables refer to BC1.2, unless BC1.1 is specifically
                                                    indicated.

                                                    1. Allow DCPs to output more than 1.5A. Allows
                                                    Portable Devices (PDs) with switch mode chargers to
                                                    draw more power. Section 4.4.1.

                                                    2. Increase minimum CDP current to 1.5A. Without
                                                    change, PDs had to draw less than 500mA, to avoid
                                                    CDP shutdown. Table 5-2.

                                                    3. Indicate that ICDP max and IDCP max limits of 5A
                                                    come from USB 2.0, and are safety limits. Table 5-2
                                                    note 1.

                                                    4. Allow PDs to draw up to 1.5A during HS chirp and
                                                    traffic. Remove previous limits of 560mA and 900mA
                                                    which was based on HS common mode ranges.
                                                    Section 3.5.

                                                    5. Require CDPs to support 1.5A during HS chirp and
                                                    traffic. Affects CDP common mode range.
                                                    Section 3.5.

                                                    6. Reduce maximum PD current from 1.8A to 1.5A, to
                                                    avoid shutdown when attached to CDP. Table 5-2.

                                                    7. Rename Docking Station to ACA-Dock, to avoid
                                                    confusion with other types of Docking Stations.

                                                    8. Require ACA-Dock to differentiate itself from an
                                                    ACA, by enabling VDM_SRC during no activity.
                                                    Section 3.2.4.4.

                                                    9. Allow CDP to leave VDM_SRC enabled while
                                                    peripheral not connected. Section 3.2.4.2.

                                                    10. Remove ICHG_SHTDWN. This was a recommended
                                                    max output current for Charging Ports with VBUS
                                                    grounded. BC1.1 Section 4.1.

                                                    11. Require VDP_SRC to not pull D+ below 2.2V when
                                                    D+ is being pulled to VDP_UP through RDP_UP.
                                                    Require VDM_SRC to not pull D- below 2.2V when D- is
                                                    being pulled high. Required for ACA-Dock support.
                                                    Table 5-1 notes 1 and 2.

iv

Battery Charging Specification, Revision 1.2                                            December 7, 2010

                                               12. Make DCD current source optional for PDs.
                                               Section 3.2.3.

                                               13. Make DCD timeout required for PDs. Section
                                               3.2.3.

                                               14. Make Secondary Detection optional for PDs.
                                               Section 4.6.2.

                                               15. Make Good Battery Algorithm required behavior
                                               for PDs. Section 3.2.4.

                                               16. Remove resistive detection. BC1.1 Section 3.9.

                                               17. Change PD Required Operating Range to include
                                               4.5V at 500mA. Figure 4-3.

                                               18. Allow any downstream port to act as a DCP.
                                               Section 4.1.3.

                                               19. Require PDs to enable VDP_SRC or RDP_PU when
                                               charging from a DCP. Section 3.3.2.

                                               20. Allow chargers to renegotiate current with PD by
                                               dropping and reasserting VBUS. Section 4.1.3.

                                               21. Require PDs to discharge their own VBUS input
                                               after VBUS drops to support charger port
                                               renegotiation request. Section 4.6.3.

                                               22. Allow PDs to disconnect and repeat Charger
                                               Detection multiple times while attached, with specified
                                               timing. Section 4.6.3.

                                               23. Reduce DCP input impedance between D+, D- to
                                               VBUS and ground from 1MΩ to 300kΩ. Section 4.4.3.

                                               24. Require CDPs to recover after over-current
                                               condition. Section 4.2.2.

                                               25. Allow greater DCP undershoot for large load
                                               current steps, to enable low quiescent current
                                               chargers required by Europe. Section 4.4.2.

                                               26. Define ACAs and ACA-Docks as types of
                                               Charging Ports. Section 1.4.5.

                                               27. Use session valid voltage range defined in EH
                                               and OTG Supplement rev 2.0. Section 3.2.2.

                                               28. Only devices that can operate stand-alone from
                                               internal battery power are allowed to use the Dead
                                               Battery Provision. Section 2.2.

                                               29. Allow compound PDs to draw ISUSP plus an

                                                                                                         v

     Battery Charging Specification, Revision 1.2                                          December 7, 2010

                                                    additional ISUSP for each downstream port.
                                                    Section 2.1.

                                                    30. Remove requirement for vendors to provide
                                                    typical and maximum connect time for products
                                                    having a Dead or Weak Battery for compliance
                                                    testing. Section 2.

                                                    31. Remove references to no battery from Dead
                                                    Battery Provision. Section 2.

                                                    32. Require PD using Dead Battery Provision to
                                                    enable VDP_SRC from TDBP_ATT_VDPSRC after attach to
                                                    TDBP_VDPSRC_CON before connect. Section 2.2.

                                                    33. Added DBP – Configured Clause, which allows
                                                    PD with Dead Battery to draw ICFG_MAX for
                                                    TDBP_FUL_FNCTN without having to pass USBCV.
                                                    Section 2.3.

                                                    34. Note constraints when trying to charge from an
                                                    OTG A-device. Section 1.6.

                                                    35. Change IDP_SINK and IDM_SINK range from
                                                    50-150uA to 25-175uA to ease PHY design. Table 5-2
                                                    note 1.

                                                    36. Allow USB 3.0 devices to implement BC charger
                                                    detection protocols, and to use USB 3.0 ranges for
                                                    IUNIT and ICFG_MAX. Section 1.7.

                                                    37. Rename previous ACA to Micro ACA, and define
                                                    the Standard ACA. Section 6.

                                                    38. Add caps to OTG and Accessory Ports on ACA to
                                                    support Attach Detection Protocol (ADP). Figure 6-3.

                                                    39. Change ACA ID resistance tolerances from 5% to
                                                    1% to ease PHY design. Table 5-3.

                                                    40. Remove requirements on ACA switching
                                                    time(TACA_ID_VBUS) to ease ACA design. BC1.1
                                                    Section 6.5.

                                                    41. Add state diagram for PDs attached to ACA.
                                                    Section 6.2.7.

                                                    42. Require PDs to limit current from ACA such that
                                                    VBUS remains above VACA_OPR. Section 6.2.2.

                                                    43. Change minimum ACA operating voltage
                                                    (VACA_OPR) from 3.0V to 4.1V. Table 5-1.

                                                    44. Remove requirement that ACA VBUS resistances
                                                    (RACA_CHG_DIS) be greater than 10k when
                                                    VBUS_CHG is greater than 6.5V. PDs are

vi

Battery Charging Specification, Revision 1.2                                             December 7, 2010

                                               responsible for protecting themselves against higher
                                               voltages on VBUS. BC1.1 Section 6.7.

                                               45. Require ACAs to continue providing power to OTG
                                               device from Charging Port, even if ground offsets or
                                               USB reset cause D- to go below VDAT_REF.
                                               Section 6.2.6.

                                               46. Change charger shutdown recovery time
                                               (TSHTDWN_REC) from 2 seconds to 2 minutes. Table
                                               5-5.

                                               47. Indicate that ACA-Dock is required to pull D+ to
                                               VDP_UP with RDP_UP when VBUS is asserted.
                                               Section 3.2.4.4.

                                               48. Remove statements regarding devices with
                                               multiple receptacles. Covered in Multiple Receptacle
                                               white paper at http://www.usb.org/developers/docs/.

                                               49. Improve readability by adding and updating
                                               drawings, re-structuring sections, and clarifying text.

                                                                                                         vii

             Battery Charging Specification, Revision 1.2                                                                                   December 7, 2010

Table of Contents
1. Introduction ...................................................................................................................................................... 1
       1.1 Scope ................................................................................................................................................. 1
       1.2 Background ........................................................................................................................................ 1
       1.3 Reference Documents ........................................................................................................................ 1
       1.4 Definitions of Terms............................................................................................................................ 2
             1.4.1 Accessory Charger Adaptor.................................................................................................. 2
             1.4.2 ACA-Dock ............................................................................................................................. 2
             1.4.3 Attach versus Connect.......................................................................................................... 2
             1.4.4 Charging Downstream Port .................................................................................................. 2
             1.4.5 Charging Port ........................................................................................................................ 2
             1.4.6 Dead Battery Threshold ........................................................................................................ 2
             1.4.7 Dedicated Charging Port ...................................................................................................... 3
             1.4.8 Downstream Port .................................................................................................................. 3
             1.4.9 Micro ACA ............................................................................................................................. 3
             1.4.10 Portable Device..................................................................................................................... 3
             1.4.11 Rated Current ....................................................................................................................... 3
             1.4.12 Standard ACA ....................................................................................................................... 3
             1.4.13 Standard Downstream Port .................................................................................................. 3
             1.4.14 USB Charger......................................................................................................................... 3
             1.4.15 Weak Battery Threshold ....................................................................................................... 3
       1.5 Parameter Values ............................................................................................................................... 4
       1.6 OTG Considerations ........................................................................................................................... 4
       1.7 Super Speed Considerations ............................................................................................................. 4
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

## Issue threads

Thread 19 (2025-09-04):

Convert to ESP32 capacative touch screen.

magnus188, 2025-09-04:
Use the template from: https://github.com/limpens/esp32-8048S043-lvgl9

Convert my current screens and sensor reading to esp32 after cloning the template repo and removing template screens

Closed 2025-09-04.

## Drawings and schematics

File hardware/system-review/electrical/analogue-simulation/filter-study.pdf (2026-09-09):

−4

−3

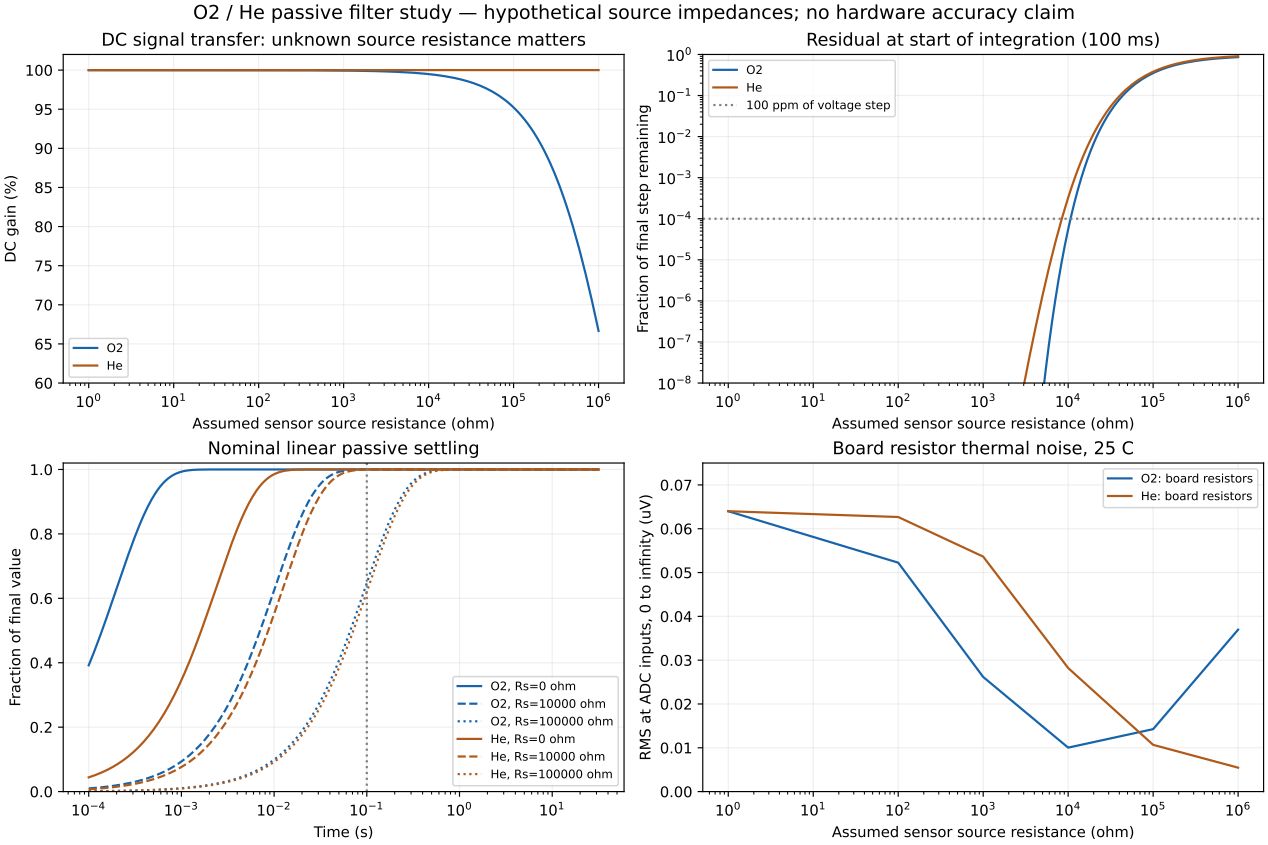
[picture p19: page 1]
DC gain (%); Fraction of; Time (s); final value; finity (uV)

O2 / He passive filter study — hypothetical source impedances; no hardware accuracy claim

DC signal transfer: unknown source resistance matters

Residual at start of integration (100 ms)

final step remaining

100 ppm of | voltage step

Assumed sensor source resistance (ohm)
Nominal linear passive settling

Board resistor thermal noise, 25 C

O2: board resistors
He: board resistors

RMS at ADC inputs, 0 to in

O2, Rs=0 ohm O2, Rs=10000 ohm O2, Rs=100000 ohm

He, Rs=0 ohm He, Rs=10000 ohm He, Rs=100000 ohm

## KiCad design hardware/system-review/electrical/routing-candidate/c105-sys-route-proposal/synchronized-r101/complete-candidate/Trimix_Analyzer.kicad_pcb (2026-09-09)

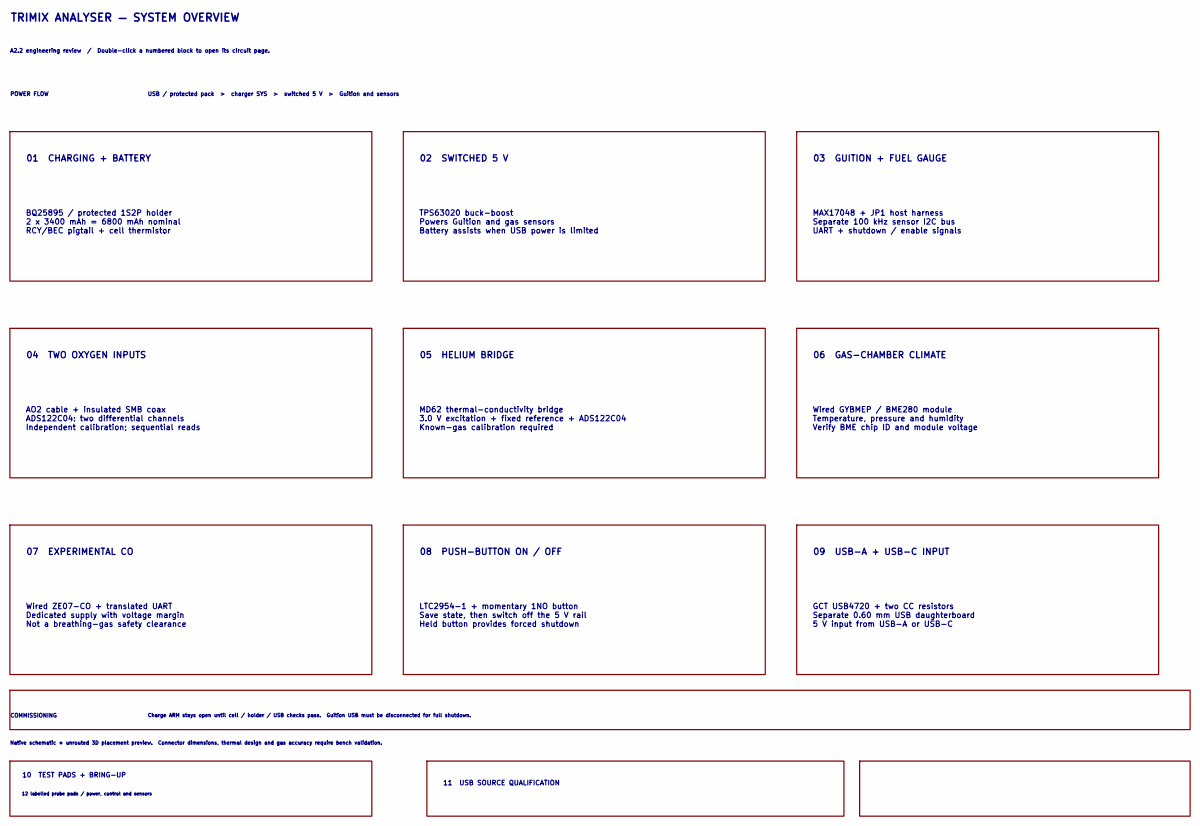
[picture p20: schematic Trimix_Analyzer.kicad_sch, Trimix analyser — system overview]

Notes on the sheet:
AO2 cable + insulated SMB coax ADS122C04: two differential channels Independent calibration; sequential reads
Charge ARM stays open until cell / holder / USB checks pass. Guition USB must be disconnected for full shutdown.
BQ25895 / protected 1S2P holder 2 x 3400 mAh = 6800 mAh nominal RCY/BEC pigtail + cell thermistor
TPS63020 buck-boost Powers Guition and gas sensors Battery assists when USB power is limited
MAX17048 + JP1 host harness Separate 100 kHz sensor I2C bus UART + shutdown / enable signals
05 HELIUM BRIDGE
COMMISSIONING
Wired ZE07-CO + translated UART Dedicated supply with voltage margin Not a breathing-gas safety clearance
Wired GYBMEP / BME280 module Temperature, pressure and humidity Verify BME chip ID and module voltage
LTC2954-1 + momentary 1NO button Save state, then switch off the 5 V rail Held button provides forced shutdown
02 SWITCHED 5 V
Native schematic + unrouted 3D placement preview. Connector dimensions, thermal design and gas accuracy require bench validation.
07 EXPERIMENTAL CO
06 GAS-CHAMBER CLIMATE
01 CHARGING + BATTERY
08 PUSH-BUTTON ON / OFF
MD62 thermal-conductivity bridge 3.0 V excitation + fixed reference + ADS122C04 Known-gas calibration required
POWER FLOW
TRIMIX ANALYSER — SYSTEM OVERVIEW
04 TWO OXYGEN INPUTS
03 GUITION + FUEL GAUGE
A2.2 engineering review / Double-click a numbered block to open its circuit page.
USB / protected pack > charger SYS > switched 5 V > Guition and sensors
09 USB-A + USB-C INPUT
GCT USB4720 + two CC resistors Separate 0.60 mm USB daughterboard 5 V input from USB-A or USB-C
10 TEST PADS + BRING-UP
12 labelled probe pads / power, control and sensors
11 USB SOURCE QUALIFICATION

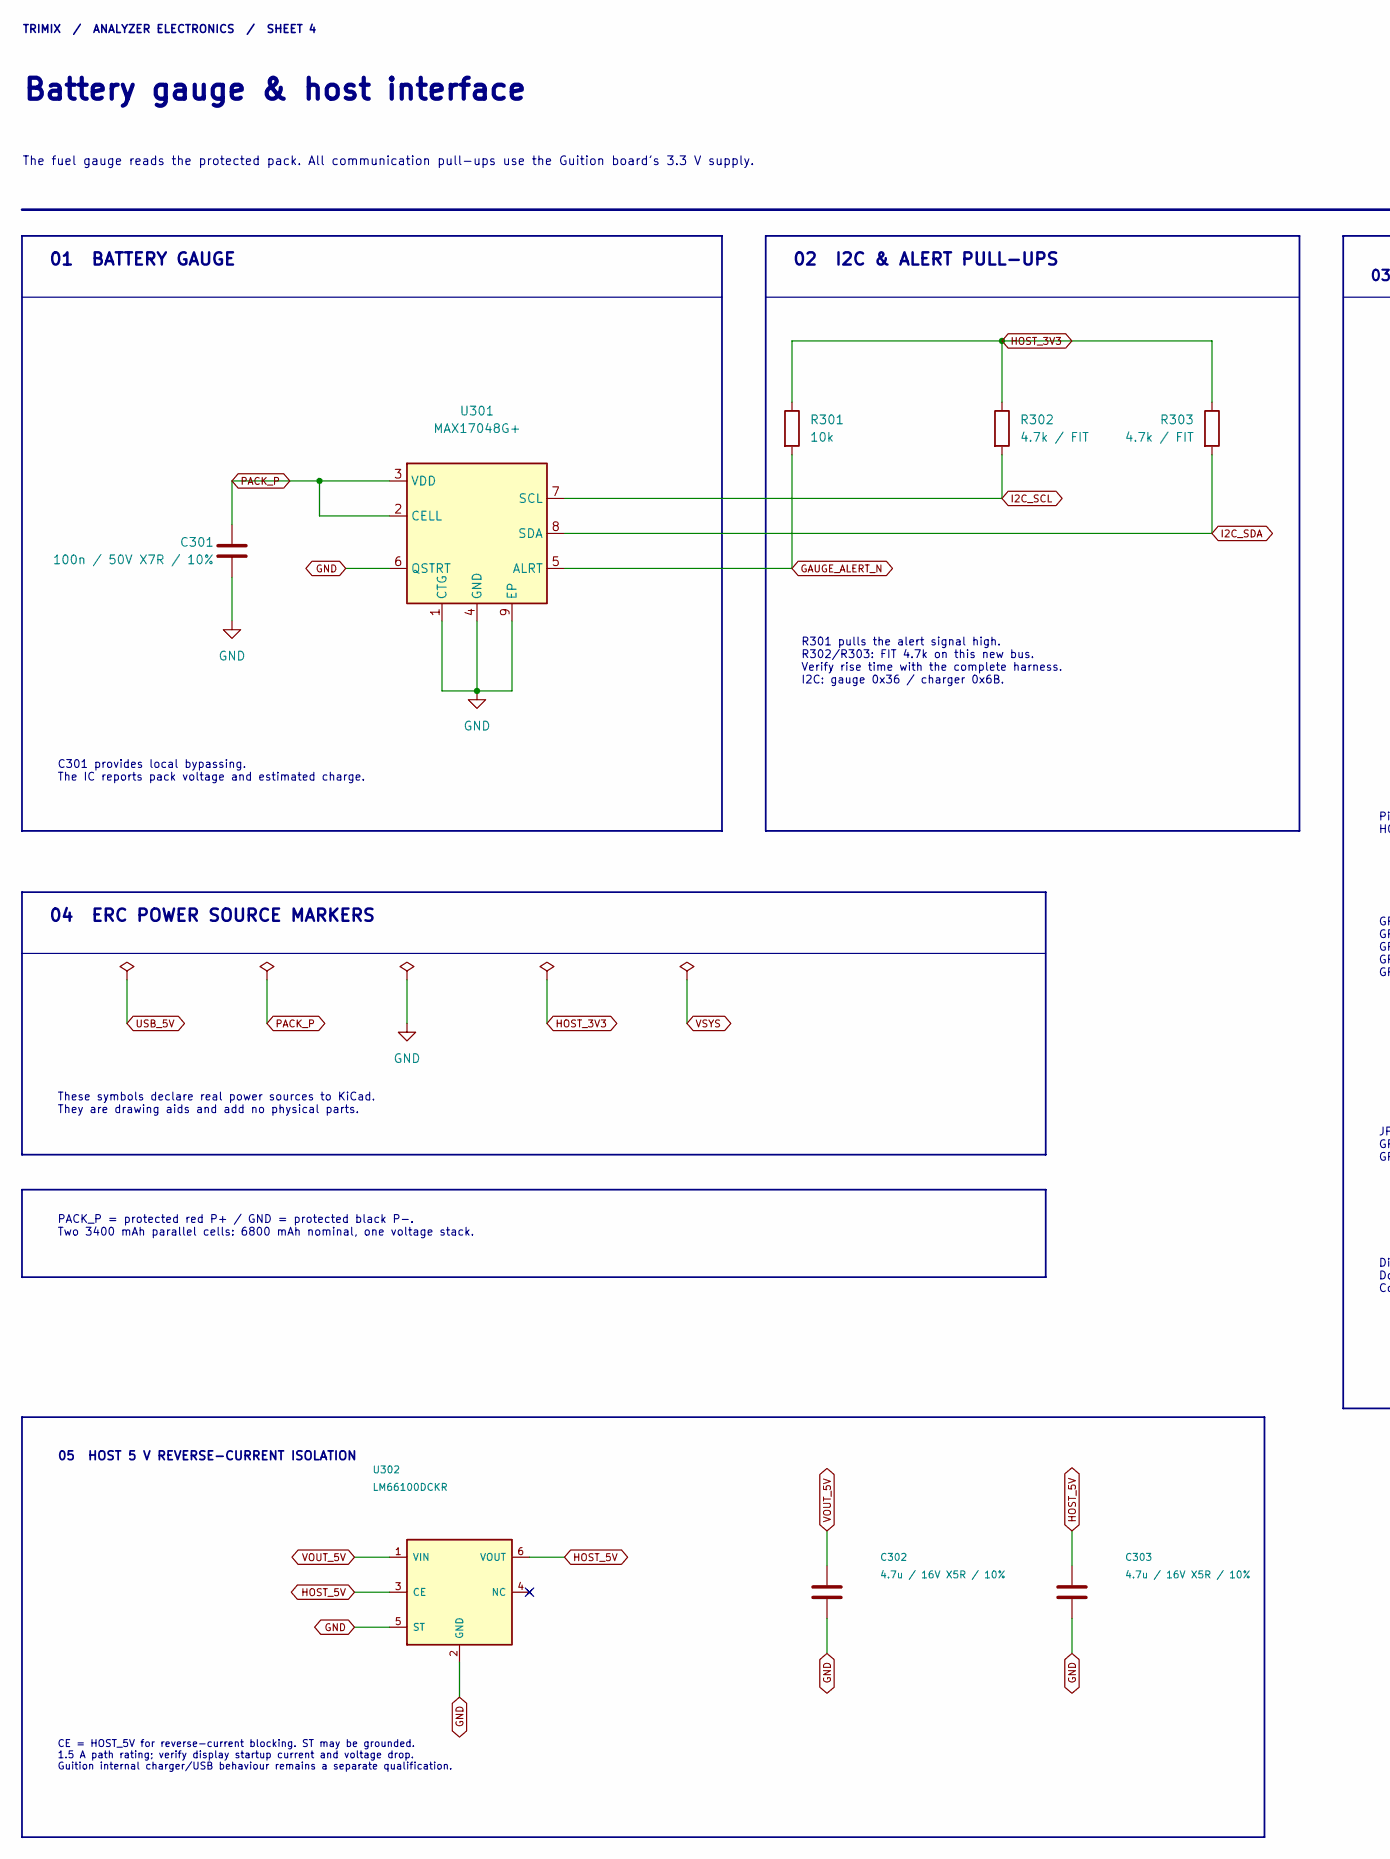
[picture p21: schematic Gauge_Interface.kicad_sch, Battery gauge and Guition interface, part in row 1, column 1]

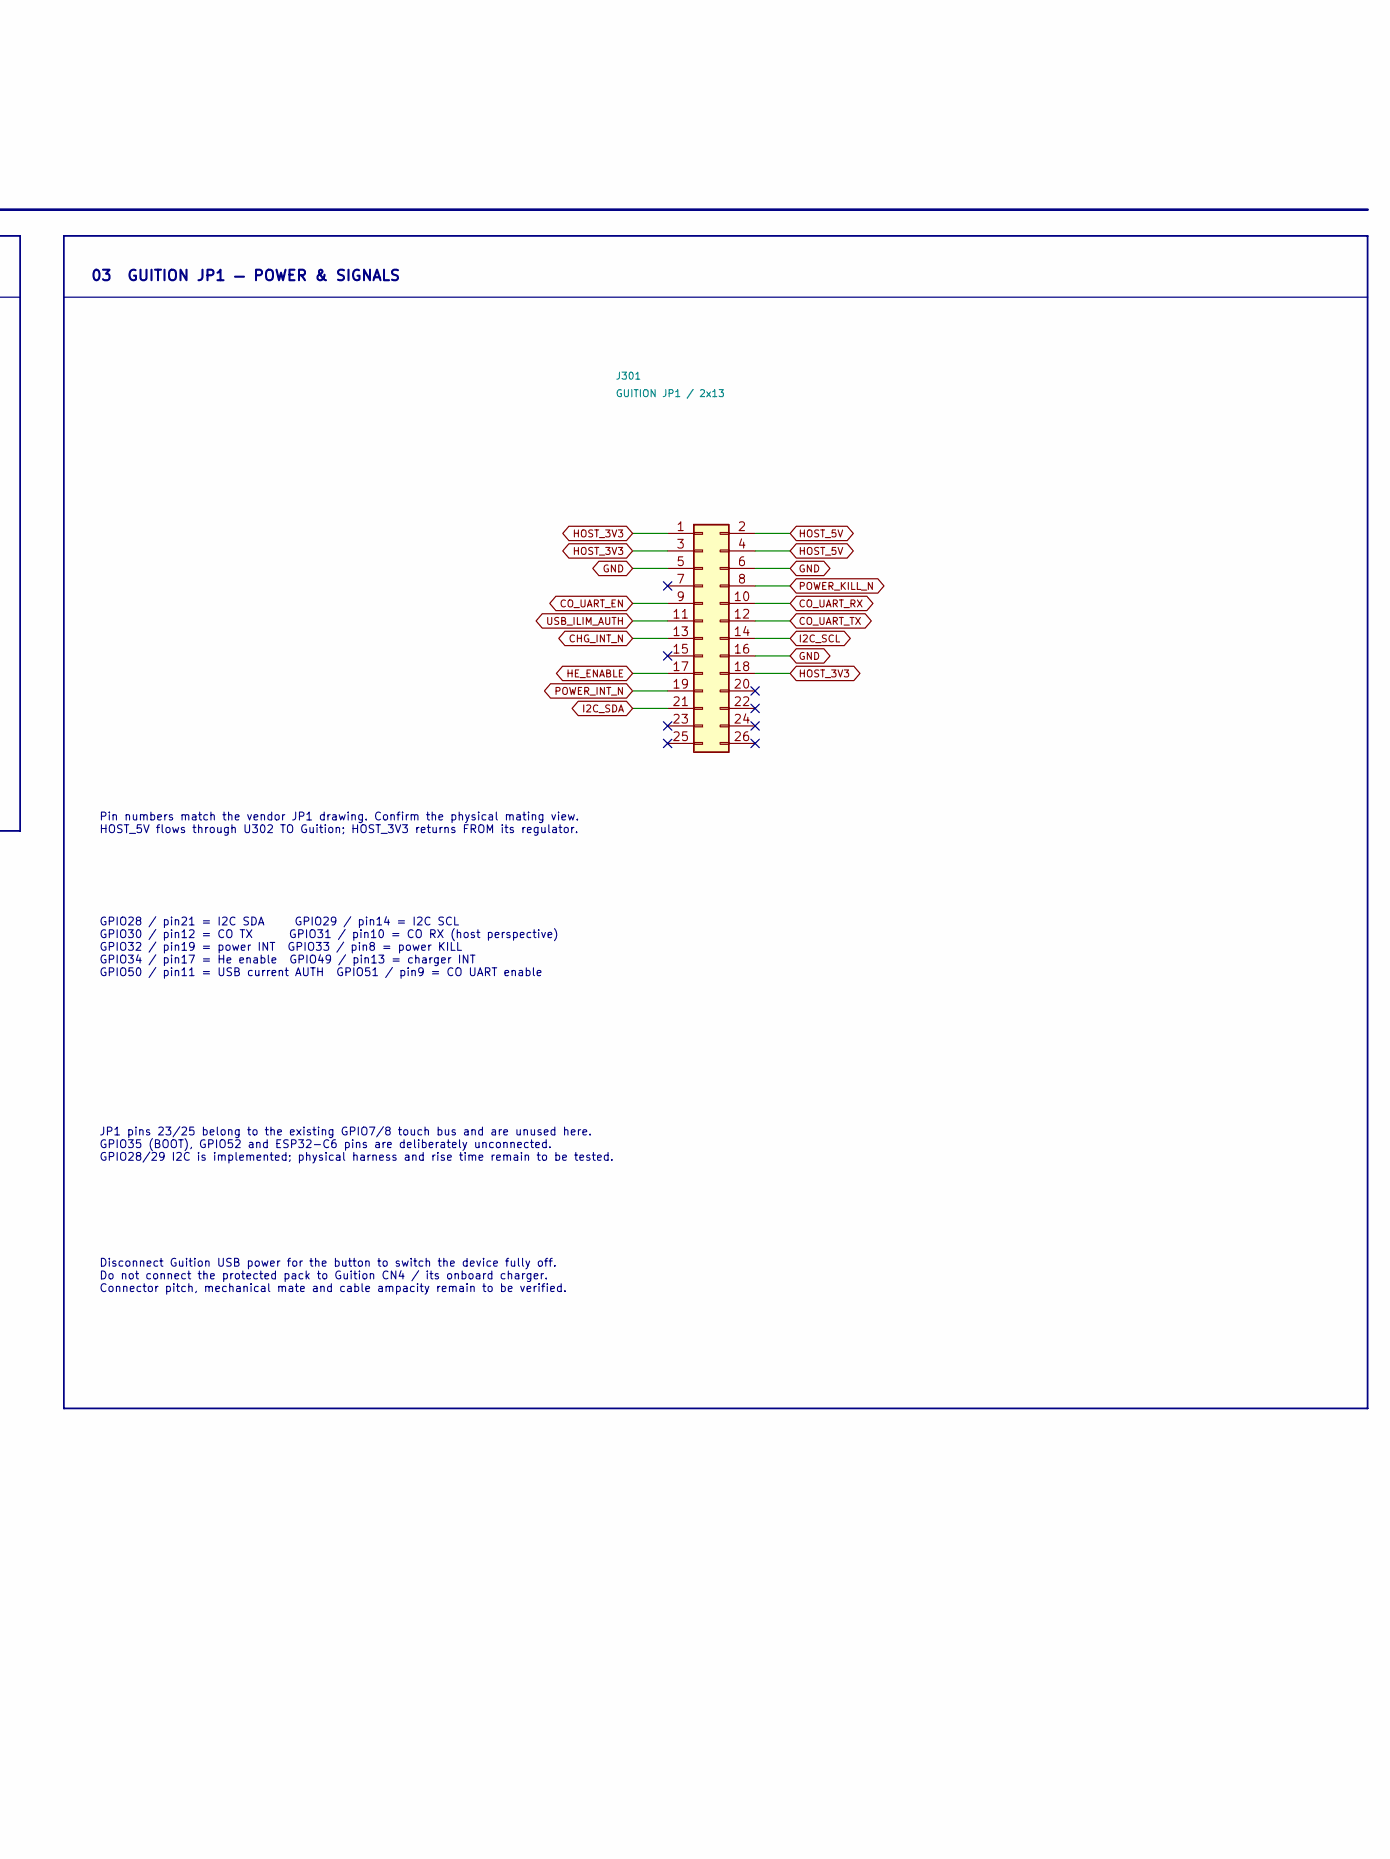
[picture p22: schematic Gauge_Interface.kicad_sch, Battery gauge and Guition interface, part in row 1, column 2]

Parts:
C301: 100n / 50V X7R / 10%; C_0805_2012Metric; MPN C0805C104K5RACTU
C302, C303: 4.7u / 16V X5R / 10%; C_0603_1608Metric; MPN C1608X5R1C475K080AC
J301: GUITION JP1 / 2x13; Samtec_HTSW-113-07-L-D-007_P2.54mm_Key7; MPN HTSW-113-07-L-D-007
R301: 10k; R_0603_1608Metric; MPN RC0603FR-0710KL
R302, R303: 4.7k / FIT; R_0603_1608Metric; MPN RC0603FR-074K7L
U301: MAX17048G+; TDFN-8-1EP_2x2mm_P0.5mm_EP0.8x1.2mm; MPN MAX17048G+T10
U302: LM66100DCKR; SOT-363_SC-70-6; MPN LM66100DCKR

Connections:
CHG_INT_N: J301.13; also elsewhere on the board
CO_UART_EN: J301.9; also elsewhere on the board
CO_UART_RX: J301.10; also elsewhere on the board
CO_UART_TX: J301.12; also elsewhere on the board
GAUGE_ALERT_N: R301.2, U301.5 (ALRT)
GND: C301.2, C302.2, C303.2, J301.5, J301.6, J301.16, U301.1 (CTG), U301.4 (GND), U301.6 (QSTRT), U301.9 (EP), U302.2 (GND), U302.5 (ST); also elsewhere on the board
HE_ENABLE: J301.17; also elsewhere on the board
HOST_3V3: J301.1, J301.3, J301.18, R301.1, R302.1, R303.1; also elsewhere on the board
HOST_5V: C303.1, J301.2, J301.4, U302.3 (CE), U302.6 (VOUT)
I2C_SCL: J301.14, R302.2, U301.7 (SCL); also elsewhere on the board
I2C_SDA: J301.21, R303.2, U301.8 (SDA); also elsewhere on the board
PACK_P: C301.1, U301.2 (CELL), U301.3 (VDD); also elsewhere on the board
POWER_INT_N: J301.19; also elsewhere on the board
POWER_KILL_N: J301.8; also elsewhere on the board
USB_ILIM_AUTH: J301.11; also elsewhere on the board
VOUT_5V: C302.1, U302.1 (VIN); also elsewhere on the board

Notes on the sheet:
Pin numbers match the vendor JP1 drawing. Confirm the physical mating view. HOST_5V flows through U302 TO Guition; HOST_3V3 returns FROM its regulator.
C301 provides local bypassing. The IC reports pack voltage and estimated charge.
TRIMIX / ANALYZER ELECTRONICS / SHEET 4
The fuel gauge reads the protected pack. All communication pull-ups use the Guition board's 3.3 V supply.
04 ERC POWER SOURCE MARKERS
03 GUITION JP1 — POWER & SIGNALS
Battery gauge & host interface
These symbols declare real power sources to KiCad. They are drawing aids and add no physical parts.
GPIO28 / pin21 = I2C SDA GPIO29 / pin14 = I2C SCL GPIO30 / pin12 = CO TX GPIO31 / pin10 = CO RX (host perspective) GPIO32 / pin19 = power INT GPIO33 / pin8 = power KILL GPIO34 / pin17 = He enable GPIO49 / pin13 = charger INT GPIO50 / pin11 = USB current AUTH GPIO51 / pin9 = CO UART enable
01 BATTERY GAUGE
R301 pulls the alert signal high. R302/R303: FIT 4.7k on this new bus. Verify rise time with the complete harness. I2C: gauge 0x36 / charger 0x6B.
02 I2C & ALERT PULL-UPS
JP1 pins 23/25 belong to the existing GPIO7/8 touch bus and are unused here. GPIO35 (BOOT), GPIO52 and ESP32-C6 pins are deliberately unconnected. GPIO28/29 I2C is implemented; physical harness and rise time remain to be tested.
PACK_P = protected red P+ / GND = protected black P-. Two 3400 mAh parallel cells: 6800 mAh nominal, one voltage stack.
Disconnect Guition USB power for the button to switch the device fully off. Do not connect the protected pack to Guition CN4 / its onboard charger. Connector pitch, mechanical mate and cable ampacity remain to be verified.
05 HOST 5 V REVERSE-CURRENT ISOLATION
CE = HOST_5V for reverse-current blocking. ST may be grounded. 1.5 A path rating; verify display startup current and voltage drop. Guition internal charger/USB behaviour remains a separate qualification.

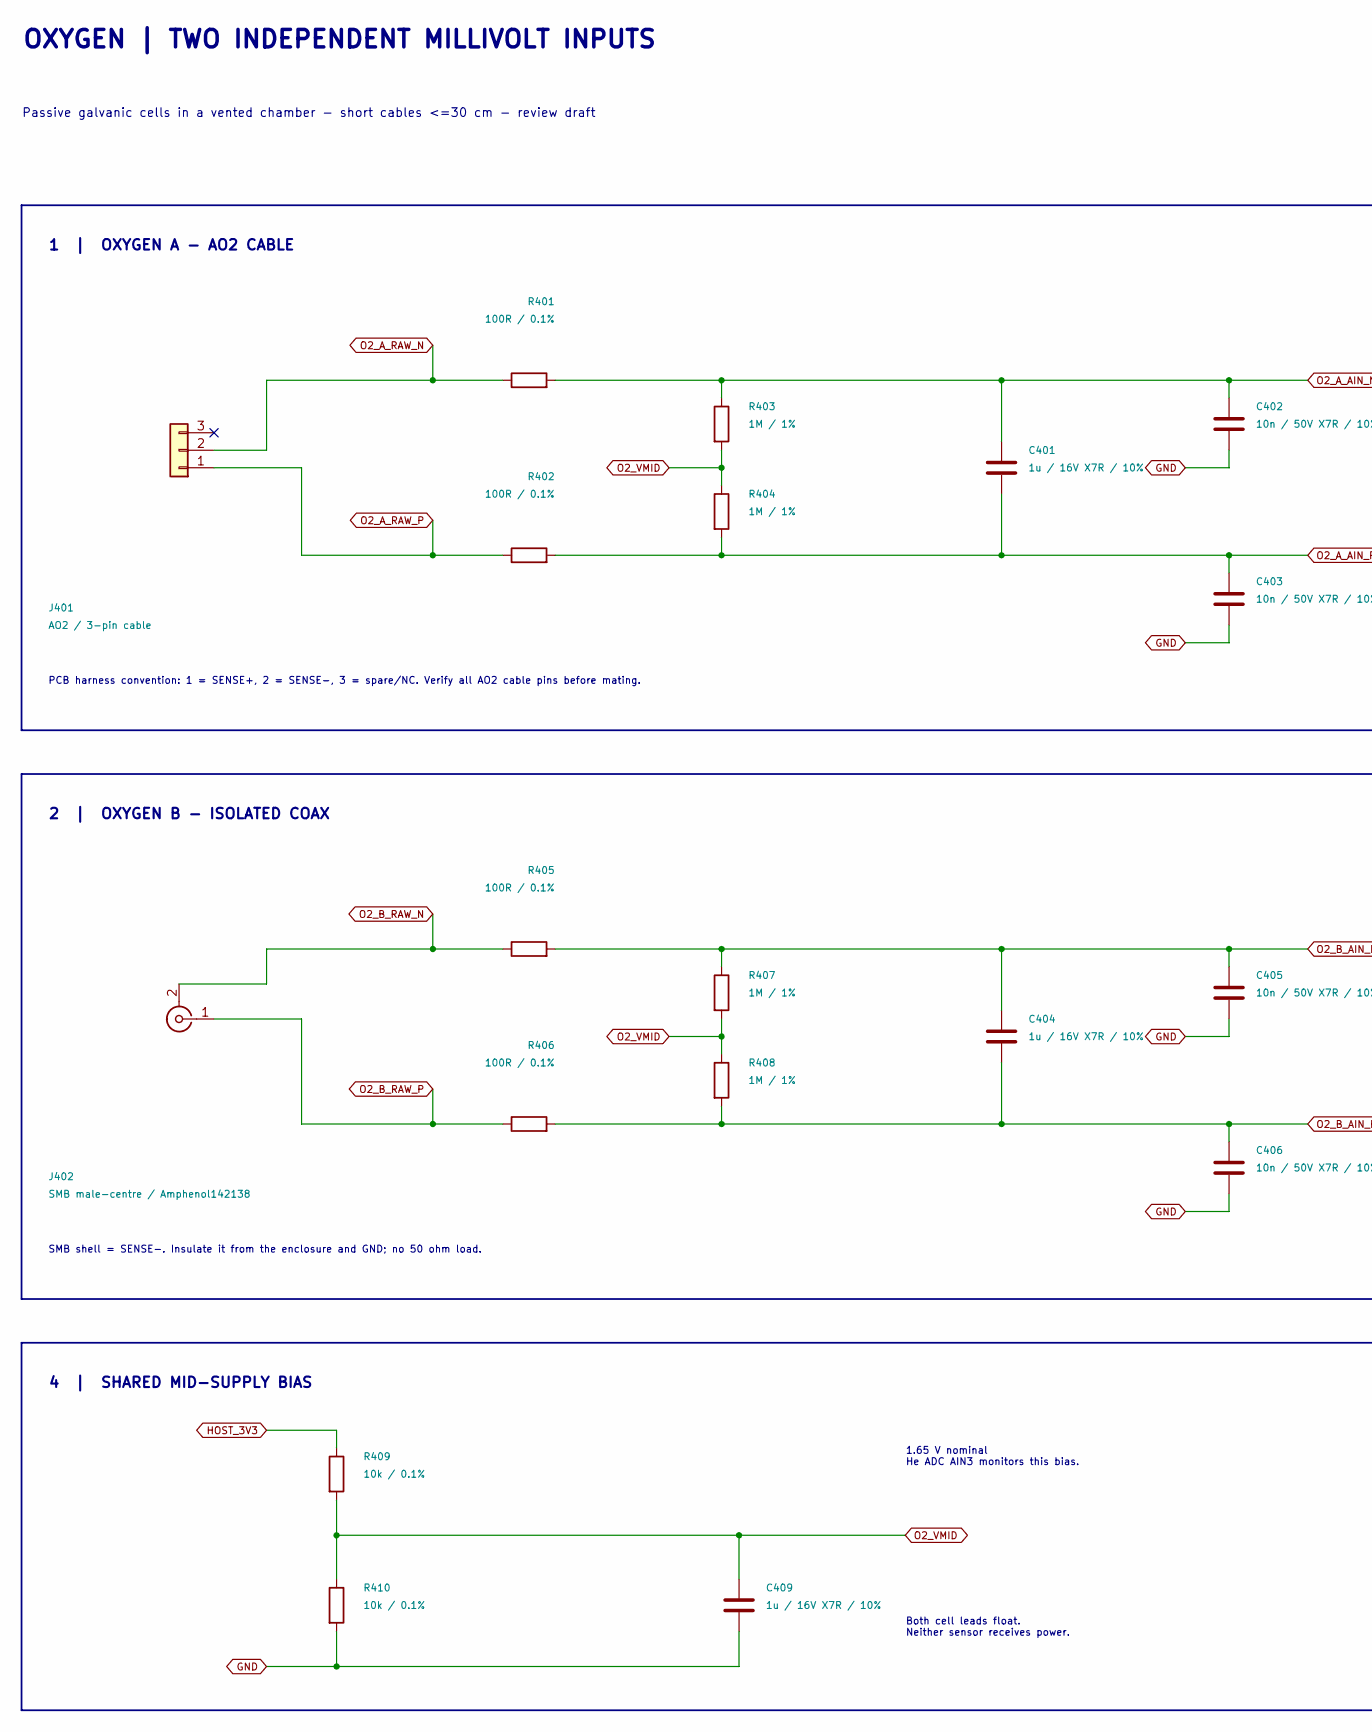
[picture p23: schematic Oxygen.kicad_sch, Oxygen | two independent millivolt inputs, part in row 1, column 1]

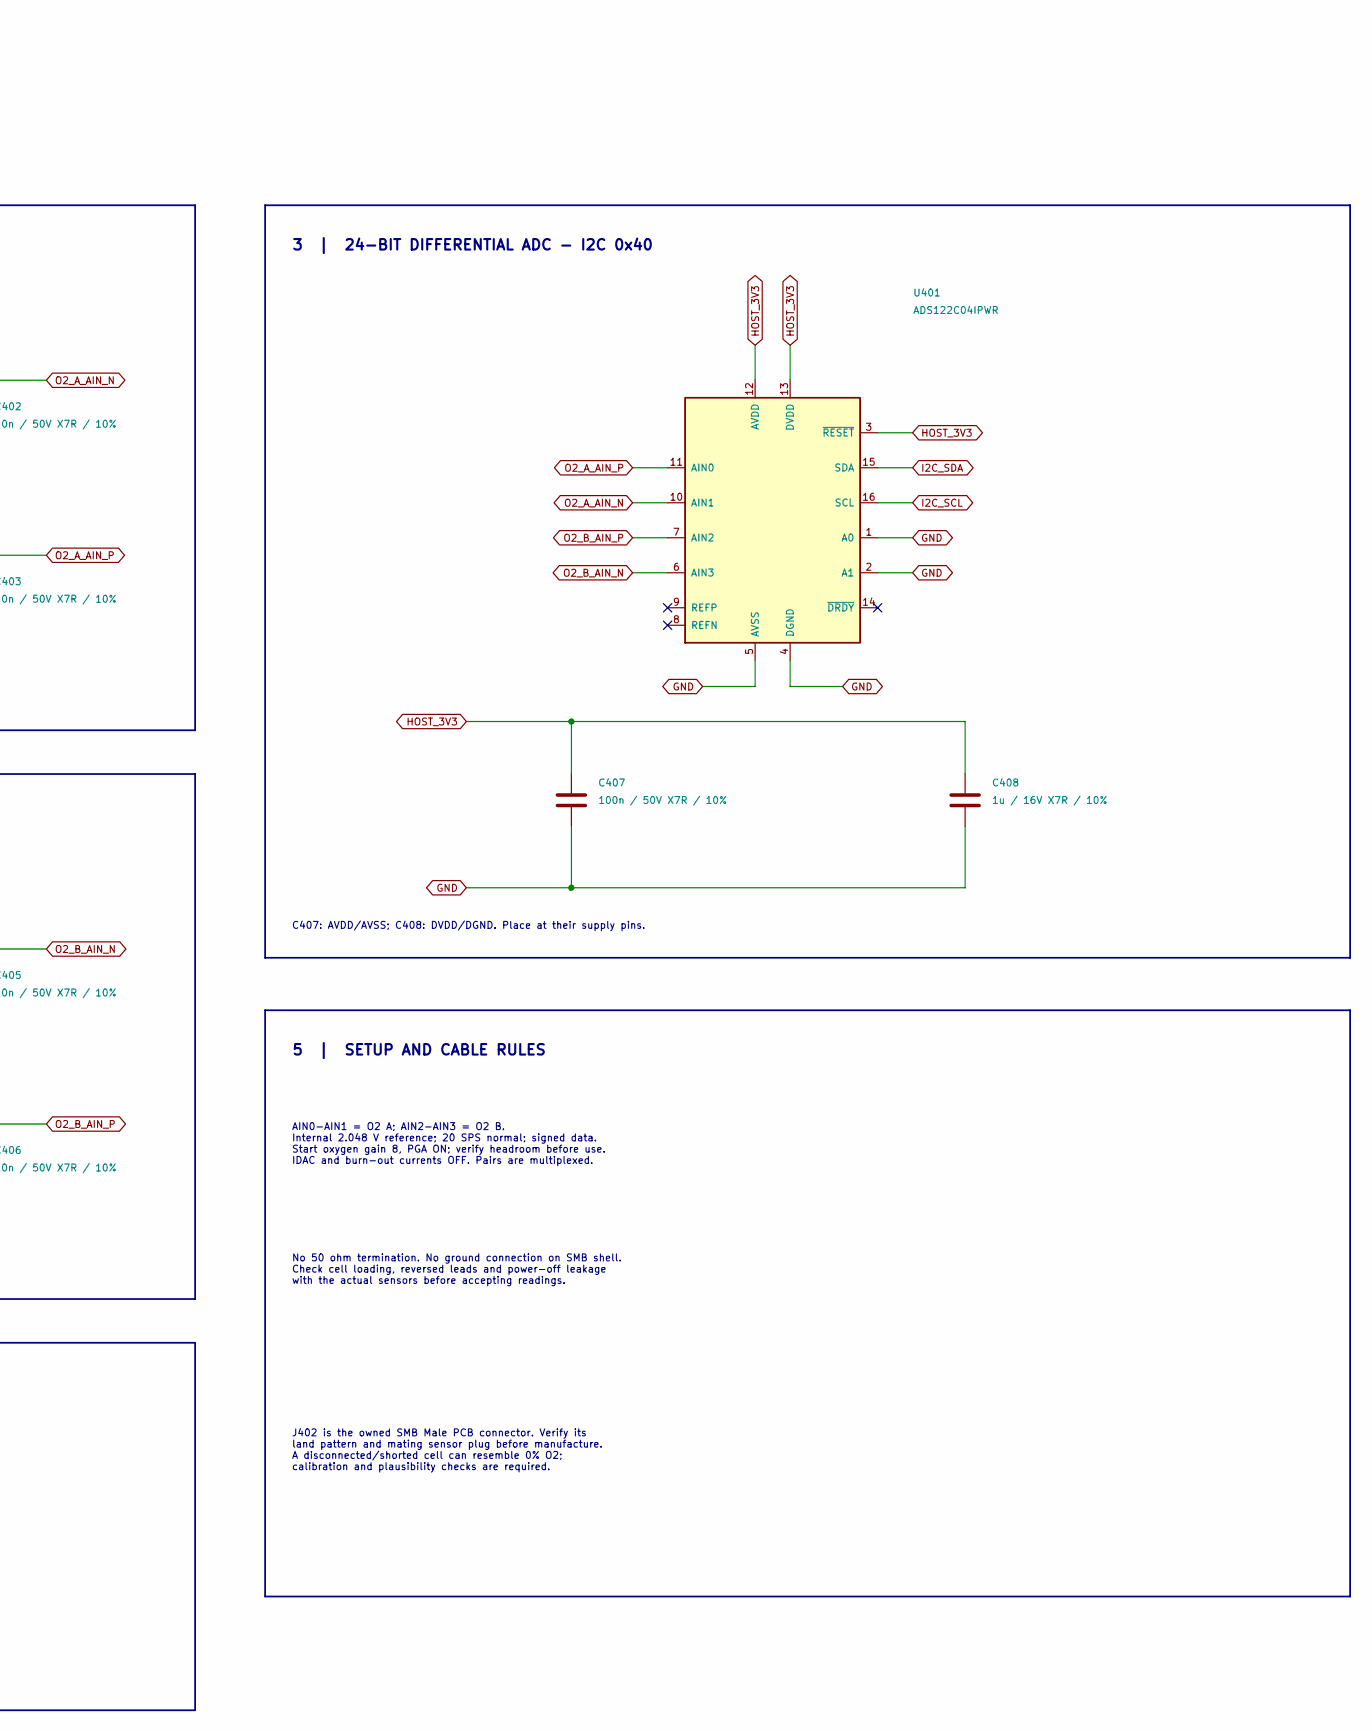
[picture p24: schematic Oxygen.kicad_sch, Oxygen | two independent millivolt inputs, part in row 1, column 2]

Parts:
C401, C404, C408, C409: 1u / 16V X7R / 10%; C_0603_1608Metric; MPN C0603C105K4RACTU
C402, C403, C405, C406: 10n / 50V X7R / 10%; C_0603_1608Metric; MPN C1608X7R1H103K080AA
C407: 100n / 50V X7R / 10%; C_0603_1608Metric; MPN C1608X7R1H104K080AA
J401: AO2 / 3-pin cable; PinHeader_1x03_P2.54mm_Vertical; MPN M20-9990346
J402: SMB male-centre / Amphenol142138; SMB_Amphenol_142138; MPN 142138
R401, R402, R405, R406: 100R / 0.1%; R_0603_1608Metric; MPN RT0603BRD07100RL
R403, R404, R407, R408: 1M / 1%; R_0603_1608Metric; MPN RC0603FR-071ML
R409, R410: 10k / 0.1%; R_0603_1608Metric; MPN RT0603BRD0710KL
U401: ADS122C04IPWR; TSSOP-16_4.4x5mm_P0.65mm; MPN ADS122C04IPWR

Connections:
GND: C402.2, C403.2, C405.2, C406.2, C407.2, C408.2, C409.2, R410.2, U401.1 (A0), U401.2 (A1), U401.4 (DGND), U401.5 (AVSS); also elsewhere on the board
HOST_3V3: C407.1, C408.1, R409.1, U401.3 (~RESET), U401.12 (AVDD), U401.13 (DVDD); also elsewhere on the board
I2C_SCL: U401.16 (SCL); also elsewhere on the board
I2C_SDA: U401.15 (SDA); also elsewhere on the board
O2_A_AIN_N: C401.1, C402.1, R401.2, R403.1, U401.10 (AIN1)
O2_A_AIN_P: C401.2, C403.1, R402.2, R404.2, U401.11 (AIN0)
O2_A_RAW_N: J401.2, R401.1
O2_A_RAW_P: J401.1, R402.1
O2_B_AIN_N: C404.1, C405.1, R405.2, R407.1, U401.6 (AIN3)
O2_B_AIN_P: C404.2, C406.1, R406.2, R408.2, U401.7 (AIN2)
O2_B_RAW_N: J402.2 (Ext), R405.1
O2_B_RAW_P: J402.1 (In), R406.1
O2_VMID: C409.1, R403.2, R404.1, R407.2, R408.1, R409.2, R410.1; also elsewhere on the board

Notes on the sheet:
PCB harness convention: 1 = SENSE+, 2 = SENSE-, 3 = spare/NC. Verify all AO2 cable pins before mating.
SMB shell = SENSE-. Insulate it from the enclosure and GND; no 50 ohm load.
2 | OXYGEN B - ISOLATED COAX
No 50 ohm termination. No ground connection on SMB shell. Check cell loading, reversed leads and power-off leakage with the actual sensors before accepting readings.
4 | SHARED MID-SUPPLY BIAS
Both cell leads float. Neither sensor receives power.
1 | OXYGEN A - AO2 CABLE
AIN0-AIN1 = O2 A; AIN2-AIN3 = O2 B. Internal 2.048 V reference; 20 SPS normal; signed data. Start oxygen gain 8, PGA ON; verify headroom before use. IDAC and burn-out currents OFF. Pairs are multiplexed.
3 | 24-BIT DIFFERENTIAL ADC - I2C 0x40
5 | SETUP AND CABLE RULES
Passive galvanic cells in a vented chamber - short cables <=30 cm - review draft
C407: AVDD/AVSS; C408: DVDD/DGND. Place at their supply pins.
J402 is the owned SMB Male PCB connector. Verify its land pattern and mating sensor plug before manufacture. A disconnected/shorted cell can resemble 0% O2; calibration and plausibility checks are required.
OXYGEN | TWO INDEPENDENT MILLIVOLT INPUTS
1.65 V nominal He ADC AIN3 monitors this bias.

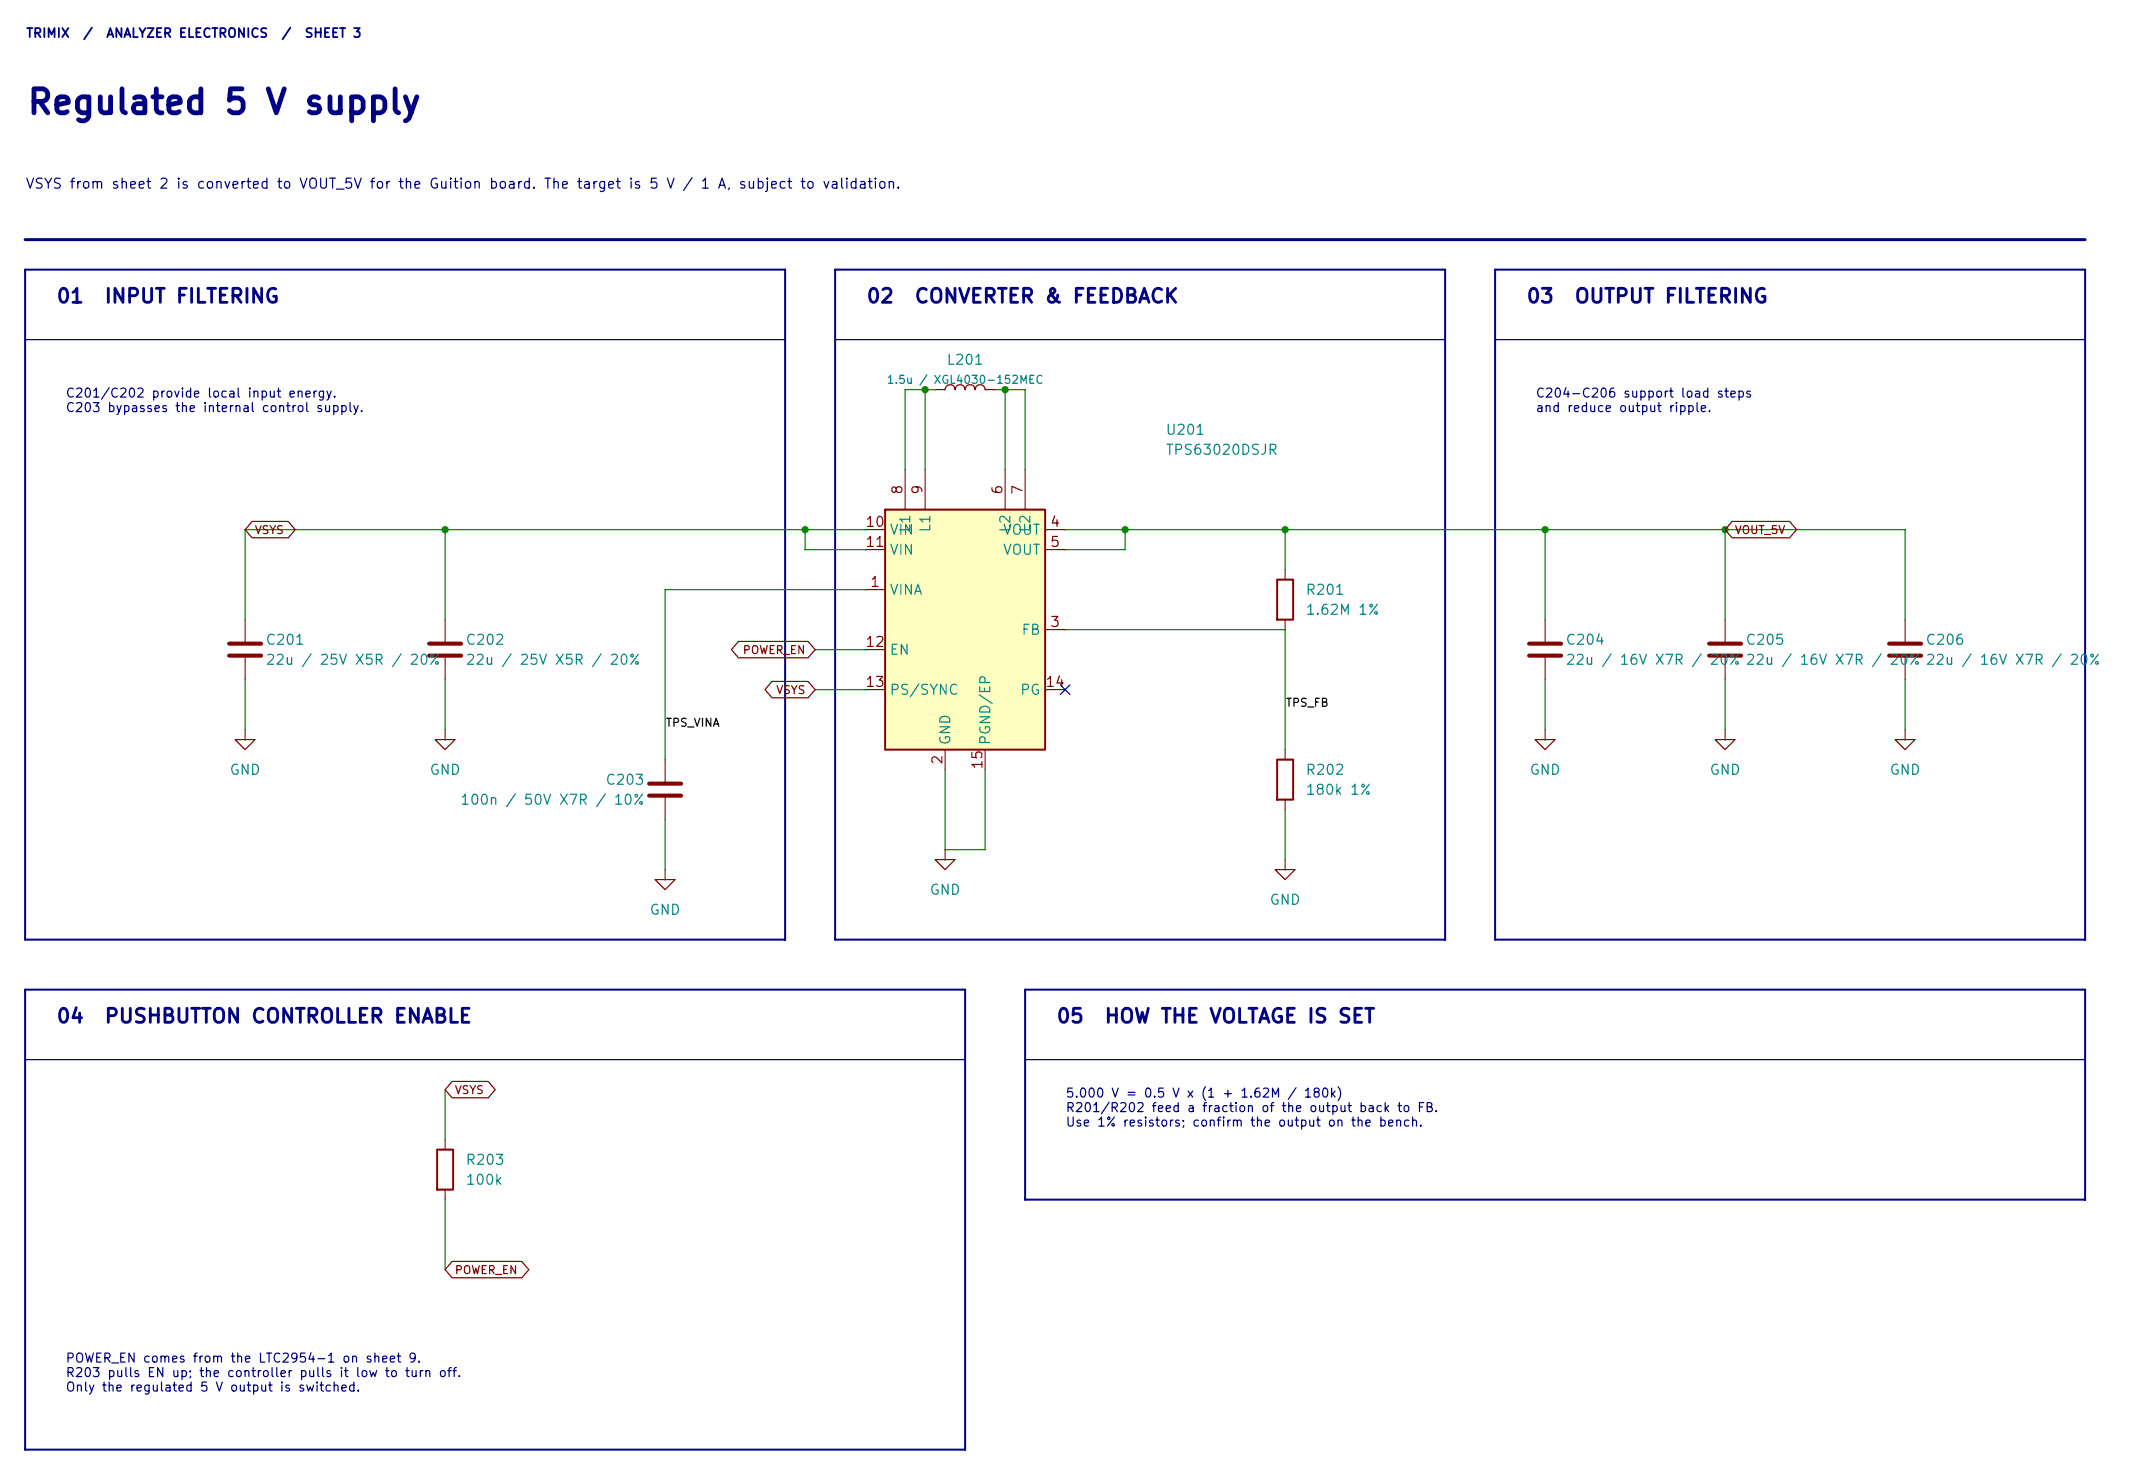
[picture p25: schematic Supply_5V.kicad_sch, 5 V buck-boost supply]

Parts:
C201, C202: 22u / 25V X5R / 20%; C_1206_3216Metric; MPN C3216X5R1E226M160AB
C203: 100n / 50V X7R / 10%; C_0603_1608Metric; MPN C1608X7R1H104K080AA
C204, C205, C206: 22u / 16V X7R / 20%; C_1210_3225Metric; MPN C3225X7R1C226M250AC
L201: 1.5u / XGL4030-152MEC; L_Coilcraft_XGL4030; MPN XGL4030-152MEC
R201: 1.62M 1%; R_0603_1608Metric; MPN RC0603FR-071M62L
R202: 180k 1%; R_0603_1608Metric; MPN RC0603FR-07180KL
R203: 100k; R_0603_1608Metric; MPN RC0603FR-07100KL
U201: TPS63020DSJR; TI_DSJ_14; MPN TPS63020DSJR

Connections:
/02 SWITCHED 5 V/TPS_FB: R201.2, R202.1, U201.3 (FB)
/02 SWITCHED 5 V/TPS_VINA: C203.1, U201.1 (VINA)
GND: C201.2, C202.2, C203.2, C204.2, C205.2, C206.2, R202.2, U201.2 (GND), U201.15 (PGND/EP); also elsewhere on the board
unnamed: L201.1, U201.8 (L1), U201.9 (L1)
unnamed: L201.2, U201.6 (L2), U201.7 (L2)
POWER_EN: R203.2, U201.12 (EN); also elsewhere on the board
VOUT_5V: C204.1, C205.1, C206.1, R201.1, U201.4 (VOUT), U201.5 (VOUT); also elsewhere on the board
VSYS: C201.1, C202.1, R203.1, U201.10 (VIN), U201.11 (VIN), U201.13 (PS/SYNC); also elsewhere on the board

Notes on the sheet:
02 CONVERTER & FEEDBACK
C204-C206 support load steps and reduce output ripple.
5.000 V = 0.5 V x (1 + 1.62M / 180k) R201/R202 feed a fraction of the output back to FB. Use 1% resistors; confirm the output on the bench.
VSYS from sheet 2 is converted to VOUT_5V for the Guition board. The target is 5 V / 1 A, subject to validation.
TRIMIX / ANALYZER ELECTRONICS / SHEET 3
05 HOW THE VOLTAGE IS SET
01 INPUT FILTERING
04 PUSHBUTTON CONTROLLER ENABLE
Regulated 5 V supply
C201/C202 provide local input energy. C203 bypasses the internal control supply.
03 OUTPUT FILTERING
POWER_EN comes from the LTC2954-1 on sheet 9. R203 pulls EN up; the controller pulls it low to turn off. Only the regulated 5 V output is switched.

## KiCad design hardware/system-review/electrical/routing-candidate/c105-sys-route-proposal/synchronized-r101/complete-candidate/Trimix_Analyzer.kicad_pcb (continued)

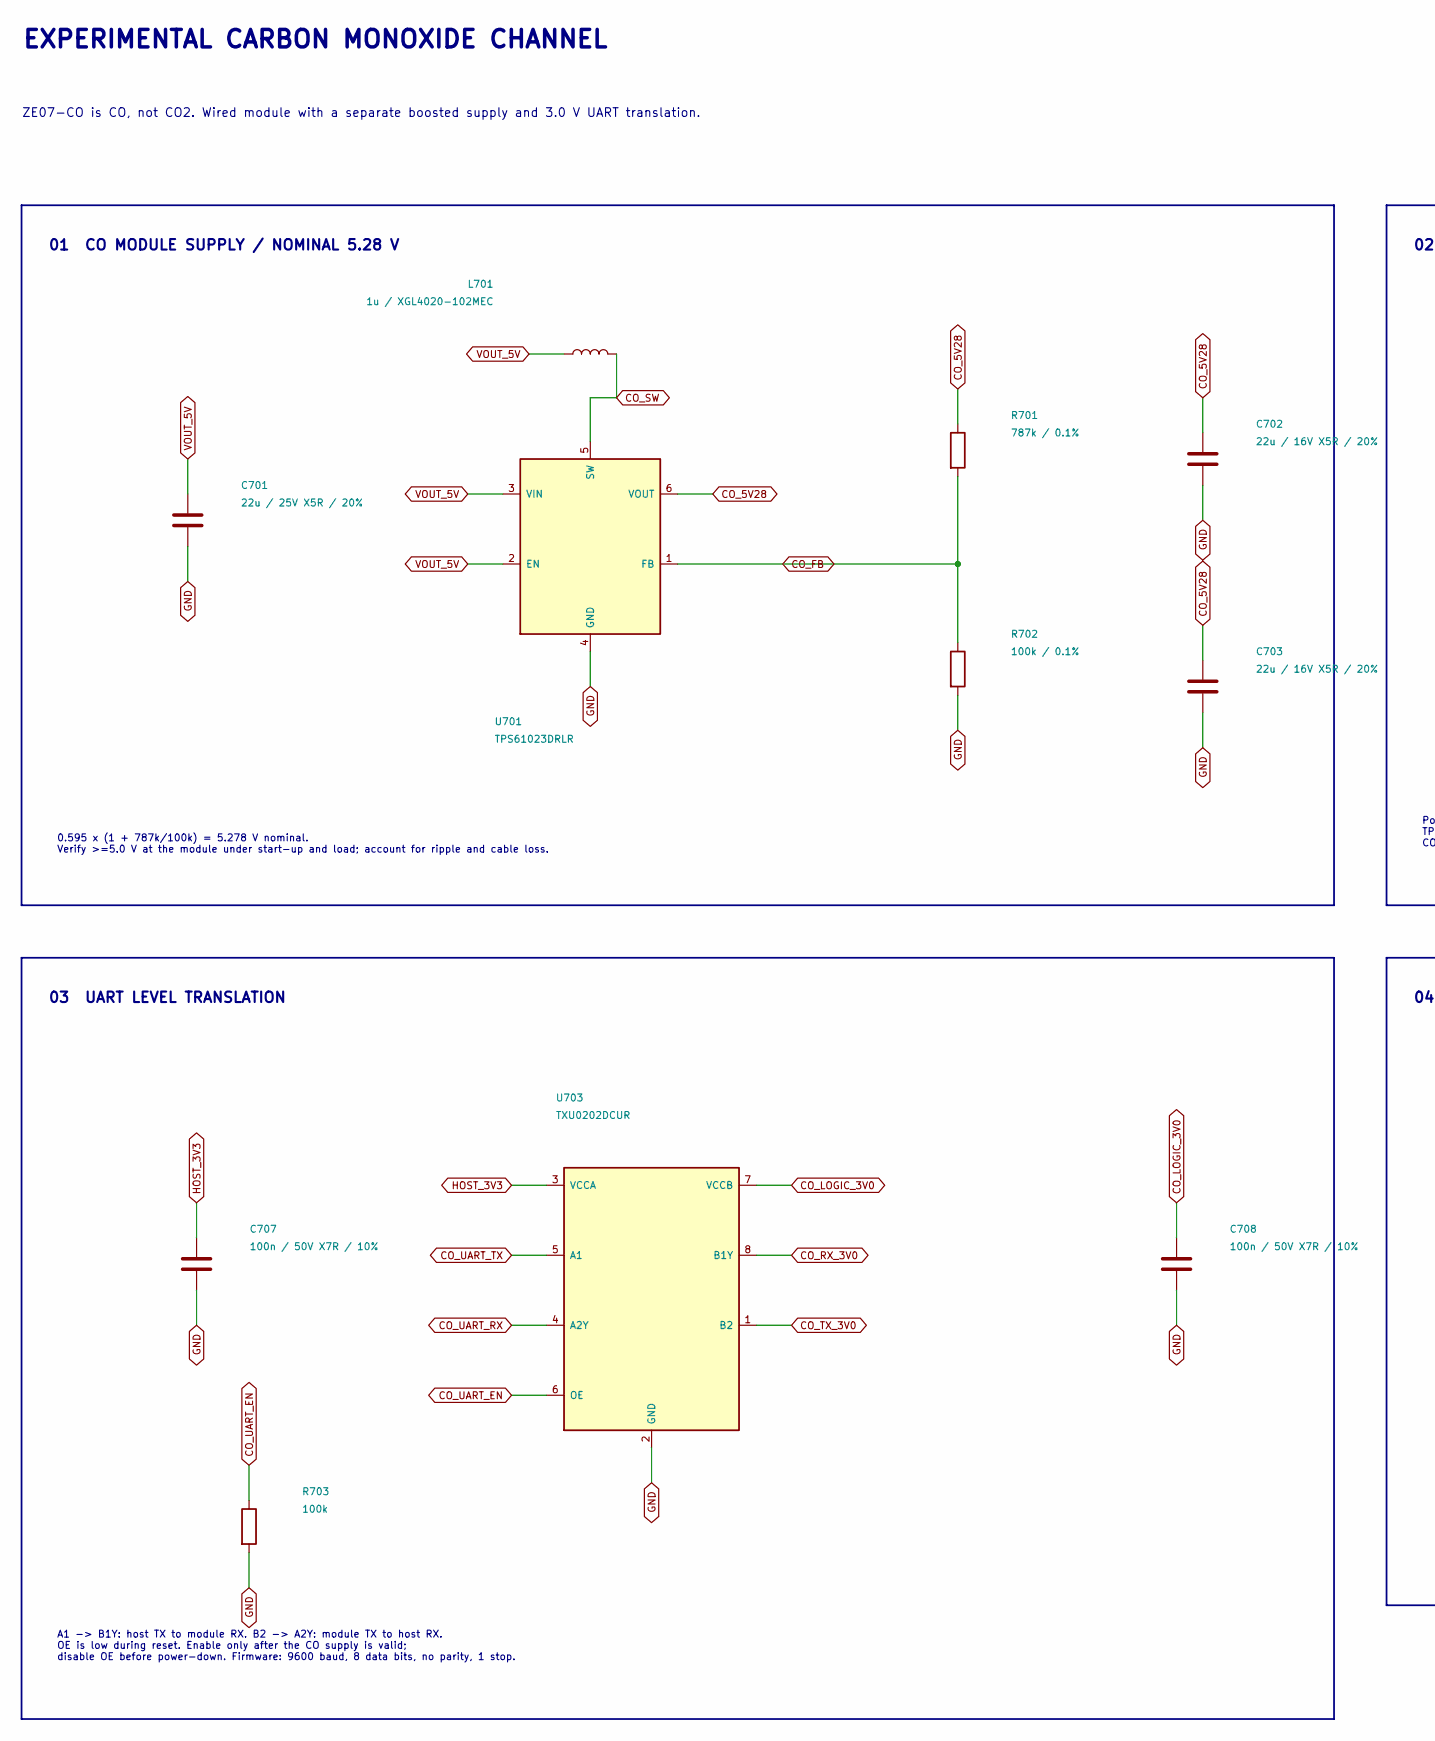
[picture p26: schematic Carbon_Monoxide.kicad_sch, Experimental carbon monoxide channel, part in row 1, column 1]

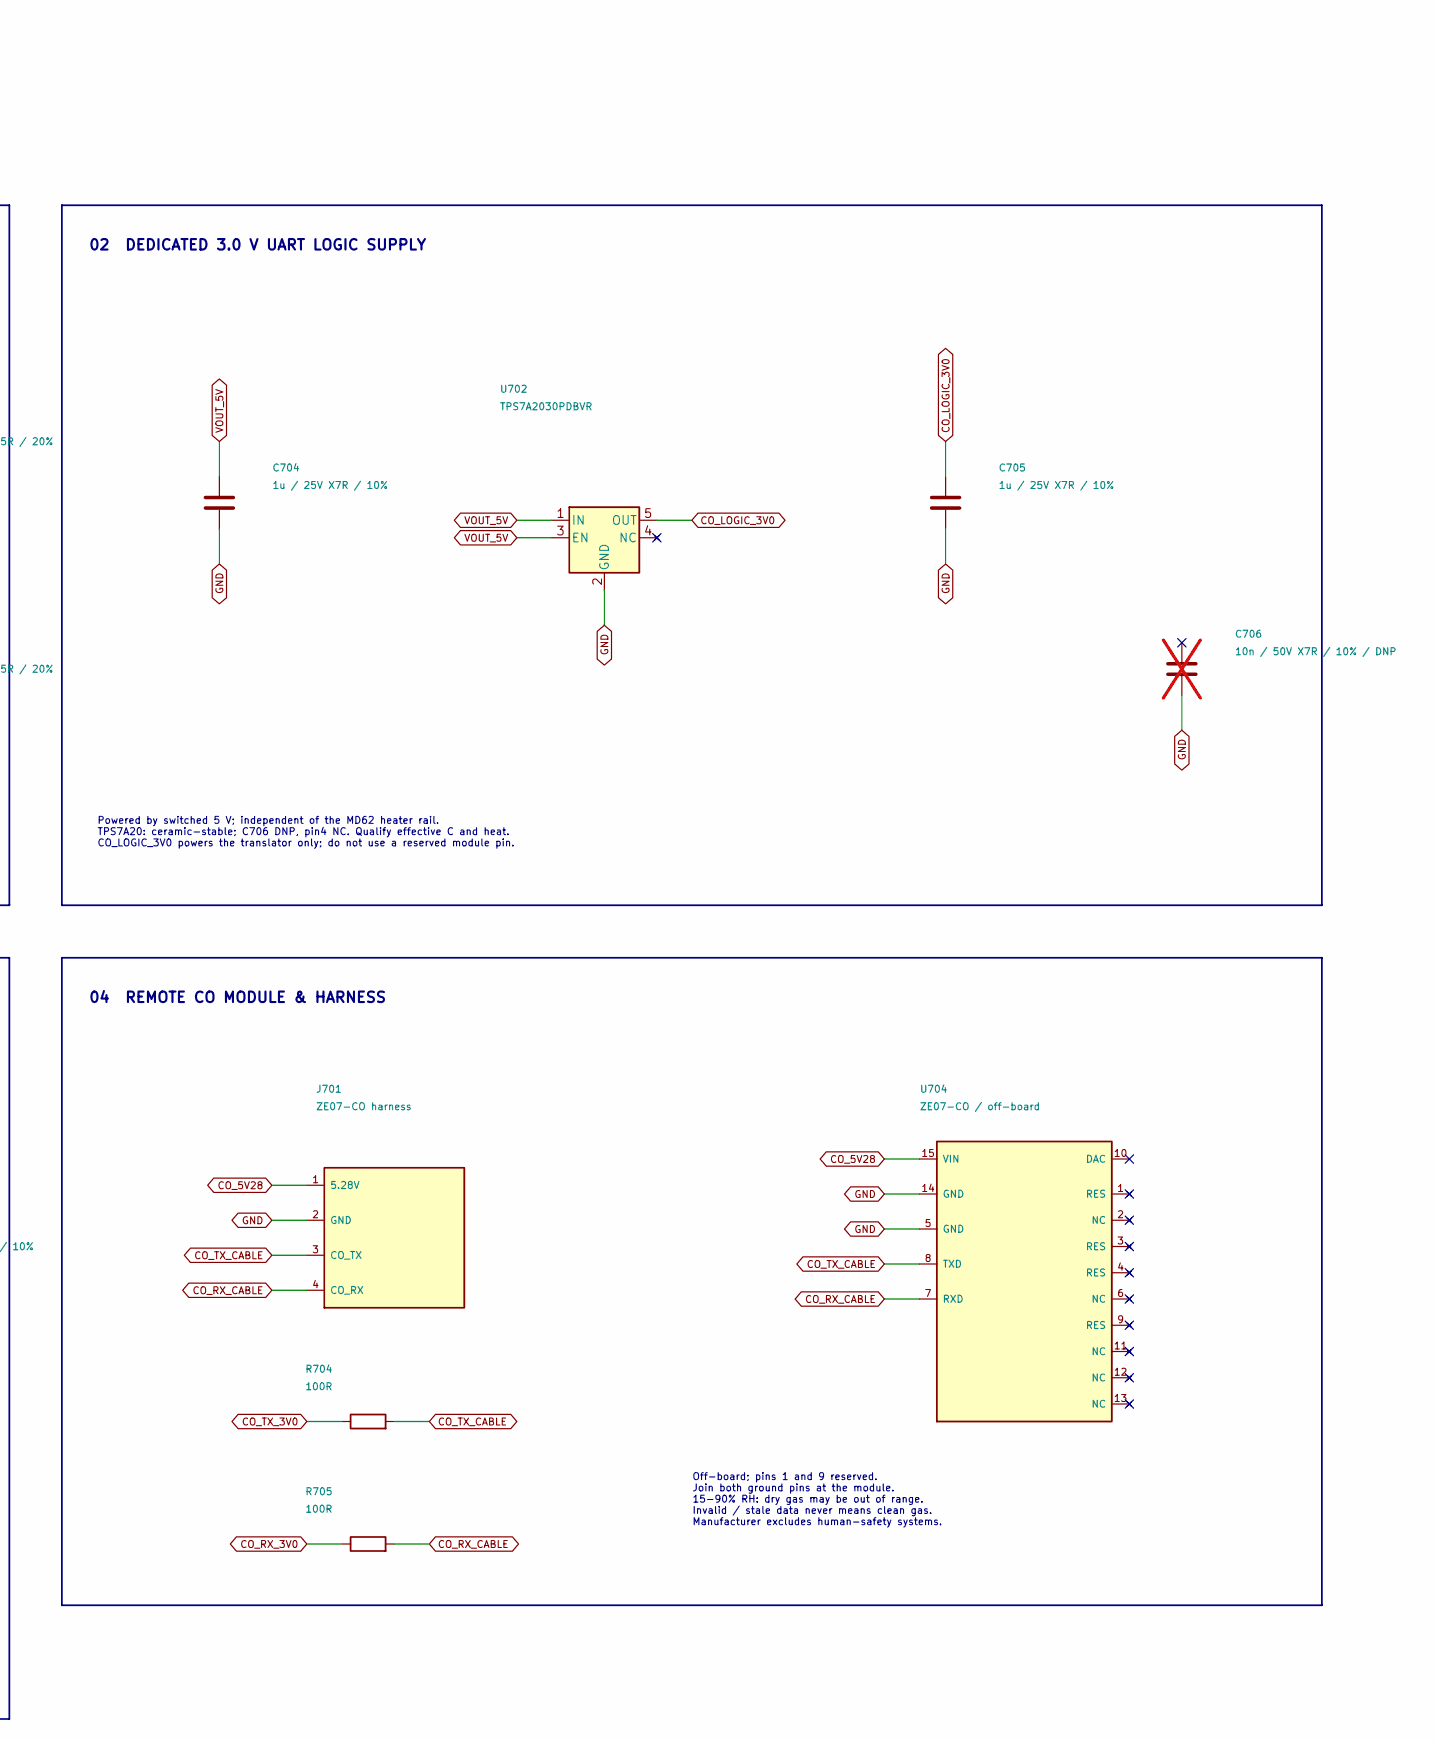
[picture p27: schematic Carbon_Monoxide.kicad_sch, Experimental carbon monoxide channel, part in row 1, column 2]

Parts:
C701: 22u / 25V X5R / 20%; C_1206_3216Metric; MPN C3216X5R1E226M160AB
C702, C703: 22u / 16V X5R / 20%; C_0805_2012Metric; MPN C2012X5R1C226M125AC
C704, C705: 1u / 25V X7R / 10%; C_0805_2012Metric; MPN C2012X7R1E105K125AB
C706: 10n / 50V X7R / 10% / DNP; C_0805_2012Metric; MPN C0805C103K5RACTU; not fitted
C707, C708: 100n / 50V X7R / 10%; C_0805_2012Metric; MPN C0805C104K5RACTU
J701: ZE07-CO harness; JST_XH_B4B-XH-A_1x04_P2.50mm_Vertical; MPN B4B-XH-A(LF)(SN)
L701: 1u / XGL4020-102MEC; L_Coilcraft_XGL4020; MPN XGL4020-102MEC
R701: 787k / 0.1%; R_0603_1608Metric; MPN RT0603BRD07787KL
R702: 100k / 0.1%; R_0603_1608Metric; MPN RT0603BRD07100KL
R703: 100k; R_0603_1608Metric; MPN RC0603FR-07100KL
R704, R705: 100R; R_0603_1608Metric; MPN RC0603FR-07100RL
U701: TPS61023DRLR; SOT-563; MPN TPS61023DRLR
U702: TPS7A2030PDBVR; SOT-23-5; MPN TPS7A2030PDBVR
U703: TXU0202DCUR; TI_DCU8_CompactSilk; MPN TXU0202DCUR
U704: ZE07-CO / off-board

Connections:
CO_5V28: C702.1, C703.1, J701.1 (5.28V), R701.1, U701.6 (VOUT), U704.15 (VIN)
CO_FB: R701.2, R702.1, U701.1 (FB)
CO_LOGIC_3V0: C705.1, C708.1, U702.5 (OUT), U703.7 (VCCB)
CO_RX_3V0: R705.1, U703.8 (B1Y)
CO_RX_CABLE: J701.4 (CO_RX), R705.2, U704.7 (RXD)
CO_SW: L701.2, U701.5 (SW)
CO_TX_3V0: R704.1, U703.1 (B2)
CO_TX_CABLE: J701.3 (CO_TX), R704.2, U704.8 (TXD)
CO_UART_EN: R703.1, U703.6 (OE); also elsewhere on the board
CO_UART_RX: U703.4 (A2Y); also elsewhere on the board
CO_UART_TX: U703.5 (A1); also elsewhere on the board
GND: C701.2, C702.2, C703.2, C704.2, C705.2, C706.2, C707.2, C708.2, J701.2 (GND), R702.2, R703.2, U701.4 (GND), U702.2 (GND), U703.2 (GND), U704.5 (GND), U704.14 (GND); also elsewhere on the board
HOST_3V3: C707.1, U703.3 (VCCA); also elsewhere on the board
VOUT_5V: C701.1, C704.1, L701.1, U701.2 (EN), U701.3 (VIN), U702.1 (IN), U702.3 (EN); also elsewhere on the board

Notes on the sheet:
ZE07-CO is CO, not CO2. Wired module with a separate boosted supply and 3.0 V UART translation.
Powered by switched 5 V; independent of the MD62 heater rail. TPS7A20: ceramic-stable; C706 DNP, pin4 NC. Qualify effective C and heat. CO_LOGIC_3V0 powers the translator only; do not use a reserved module pin.
EXPERIMENTAL CARBON MONOXIDE CHANNEL
A1 -> B1Y: host TX to module RX. B2 -> A2Y: module TX to host RX. OE is low during reset. Enable only after the CO supply is valid; disable OE before power-down. Firmware: 9600 baud, 8 data bits, no parity, 1 stop.
0.595 x (1 + 787k/100k) = 5.278 V nominal. Verify >=5.0 V at the module under start-up and load; account for ripple and cable loss.
04 REMOTE CO MODULE & HARNESS
03 UART LEVEL TRANSLATION
Off-board; pins 1 and 9 reserved. Join both ground pins at the module. 15-90% RH: dry gas may be out of range. Invalid / stale data never means clean gas. Manufacturer excludes human-safety systems.
01 CO MODULE SUPPLY / NOMINAL 5.28 V
02 DEDICATED 3.0 V UART LOGIC SUPPLY

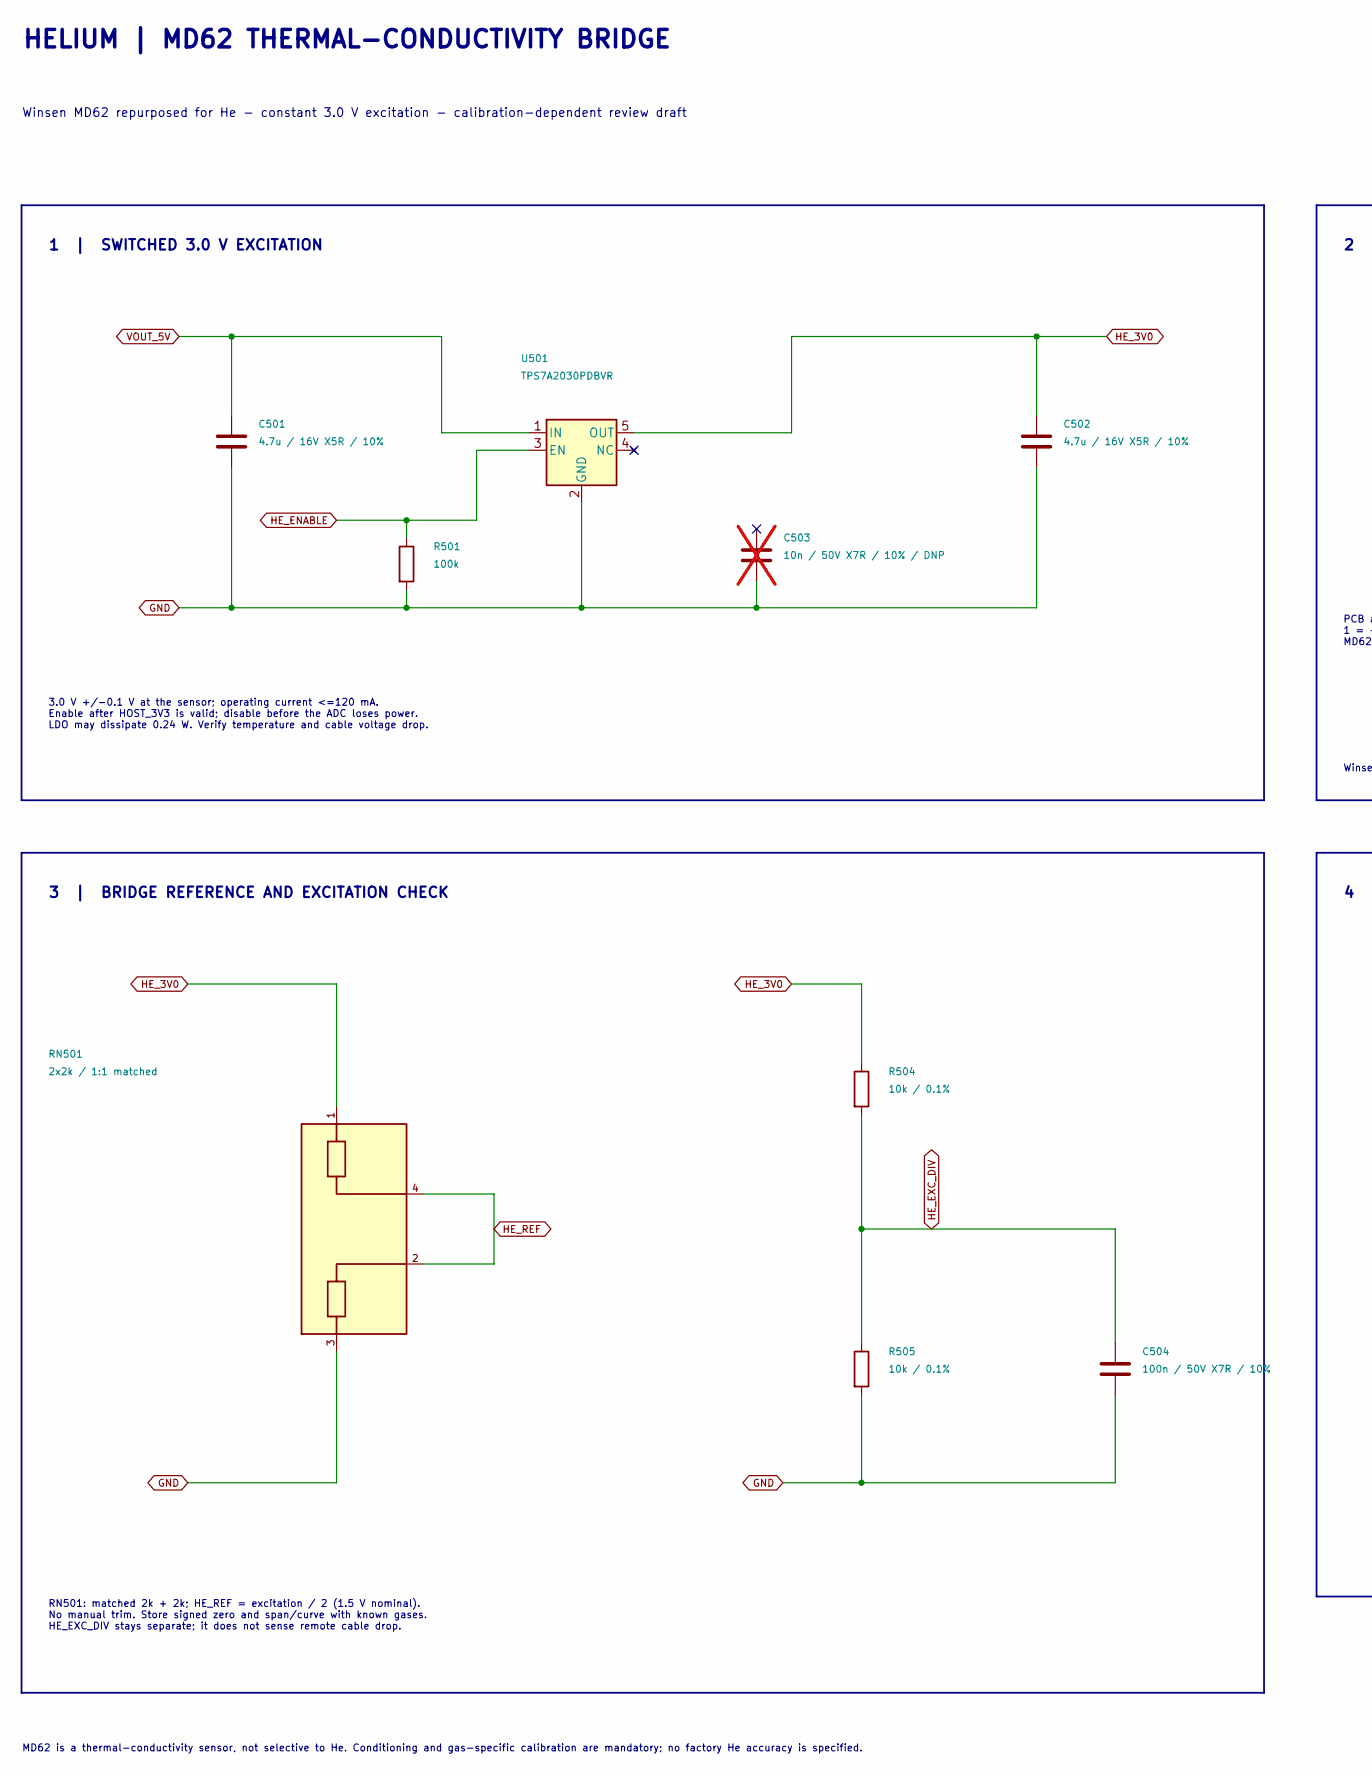
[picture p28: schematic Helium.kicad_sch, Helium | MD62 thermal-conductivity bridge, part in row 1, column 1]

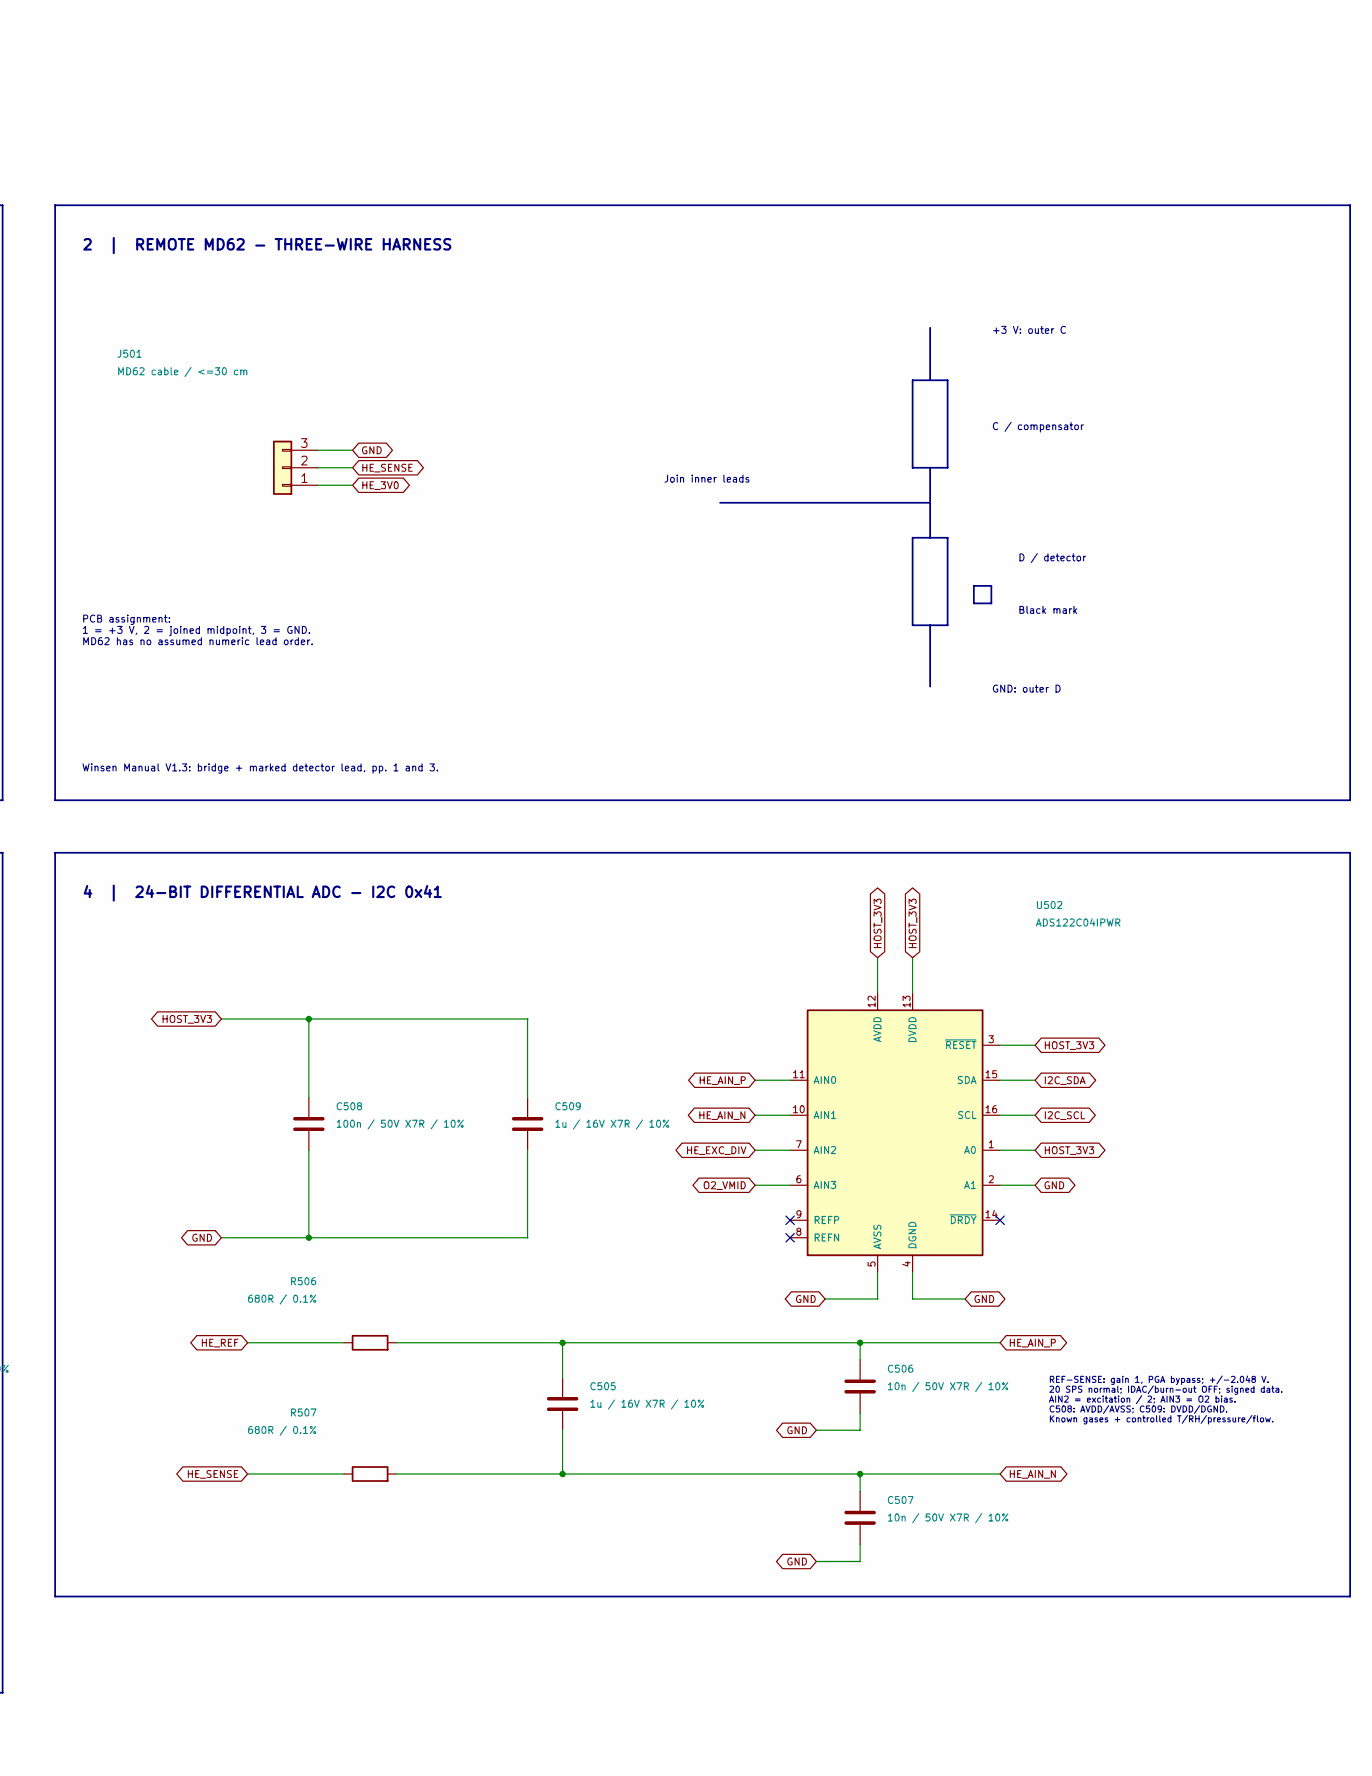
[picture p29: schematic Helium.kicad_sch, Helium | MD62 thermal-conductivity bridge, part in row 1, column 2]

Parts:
C501, C502: 4.7u / 16V X5R / 10%; C_0603_1608Metric; MPN C1608X5R1C475K080AC
C503: 10n / 50V X7R / 10% / DNP; C_0603_1608Metric; MPN C1608X7R1H103K080AA; not fitted
C504, C508: 100n / 50V X7R / 10%; C_0603_1608Metric; MPN C1608X7R1H104K080AA
C505, C509: 1u / 16V X7R / 10%; C_0603_1608Metric; MPN C0603C105K4RACTU
C506, C507: 10n / 50V X7R / 10%; C_0603_1608Metric; MPN C1608X7R1H103K080AA
J501: MD62 cable / <=30 cm; PinHeader_1x03_P2.54mm_Vertical; MPN M20-9990346
R501: 100k; R_0603_1608Metric; MPN RC0603FR-07100KL
R504, R505: 10k / 0.1%; R_0603_1608Metric; MPN RT0603BRD0710KL
R506, R507: 680R / 0.1%; R_0603_1608Metric; MPN RT0603BRD07680RL
RN501: 2x2k / 1:1 matched; Vishay_ACAS0606_AT_IEC; MPN ACASN2001U2001P1AT
U501: TPS7A2030PDBVR; SOT-23-5; MPN TPS7A2030PDBVR
U502: ADS122C04IPWR; TSSOP-16_4.4x5mm_P0.65mm; MPN ADS122C04IPWR

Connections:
GND: C501.2, C502.2, C503.2, C504.2, C506.2, C507.2, C508.2, C509.2, J501.3, R501.2, R505.2, RN501.3 (R2.2), U501.2 (GND), U502.2 (A1), U502.4 (DGND), U502.5 (AVSS); also elsewhere on the board
HE_3V0: C502.1, J501.1, R504.1, RN501.1 (R1.1), U501.5 (OUT); also elsewhere on the board
HE_AIN_N: C505.2, C507.1, R507.2, U502.10 (AIN1)
HE_AIN_P: C505.1, C506.1, R506.2, U502.11 (AIN0)
HE_ENABLE: R501.1, U501.3 (EN); also elsewhere on the board
HE_EXC_DIV: C504.1, R504.2, R505.1, U502.7 (AIN2)
HE_REF: R506.1, RN501.2 (R2.1), RN501.4 (R1.2)
HE_SENSE: J501.2, R507.1; also elsewhere on the board
HOST_3V3: C508.1, C509.1, U502.1 (A0), U502.3 (~RESET), U502.12 (AVDD), U502.13 (DVDD); also elsewhere on the board
I2C_SCL: U502.16 (SCL); also elsewhere on the board
I2C_SDA: U502.15 (SDA); also elsewhere on the board
O2_VMID: U502.6 (AIN3); also elsewhere on the board
VOUT_5V: C501.1, U501.1 (IN); also elsewhere on the board

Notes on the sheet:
3.0 V +/-0.1 V at the sensor; operating current <=120 mA. Enable after HOST_3V3 is valid; disable before the ADC loses power. LDO may dissipate 0.24 W. Verify temperature and cable voltage drop.
D / detector
Black mark
REF-SENSE: gain 1, PGA bypass; +/-2.048 V. 20 SPS normal; IDAC/burn-out OFF; signed data. AIN2 = excitation / 2; AIN3 = O2 bias. C508: AVDD/AVSS; C509: DVDD/DGND. Known gases + controlled T/RH/pressure/flow.
RN501: matched 2k + 2k; HE_REF = excitation / 2 (1.5 V nominal). No manual trim. Store signed zero and span/curve with known gases. HE_EXC_DIV stays separate; it does not sense remote cable drop.
Winsen MD62 repurposed for He - constant 3.0 V excitation - calibration-dependent review draft
Join inner leads
C / compensator
2 | REMOTE MD62 - THREE-WIRE HARNESS
4 | 24-BIT DIFFERENTIAL ADC - I2C 0x41
MD62 is a thermal-conductivity sensor, not selective to He. Conditioning and gas-specific calibration are mandatory; no factory He accuracy is specified.
+3 V: outer C
PCB assignment: 1 = +3 V, 2 = joined midpoint, 3 = GND. MD62 has no assumed numeric lead order.
HELIUM | MD62 THERMAL-CONDUCTIVITY BRIDGE
GND: outer D
1 | SWITCHED 3.0 V EXCITATION
Winsen Manual V1.3: bridge + marked detector lead, pp. 1 and 3.
3 | BRIDGE REFERENCE AND EXCITATION CHECK

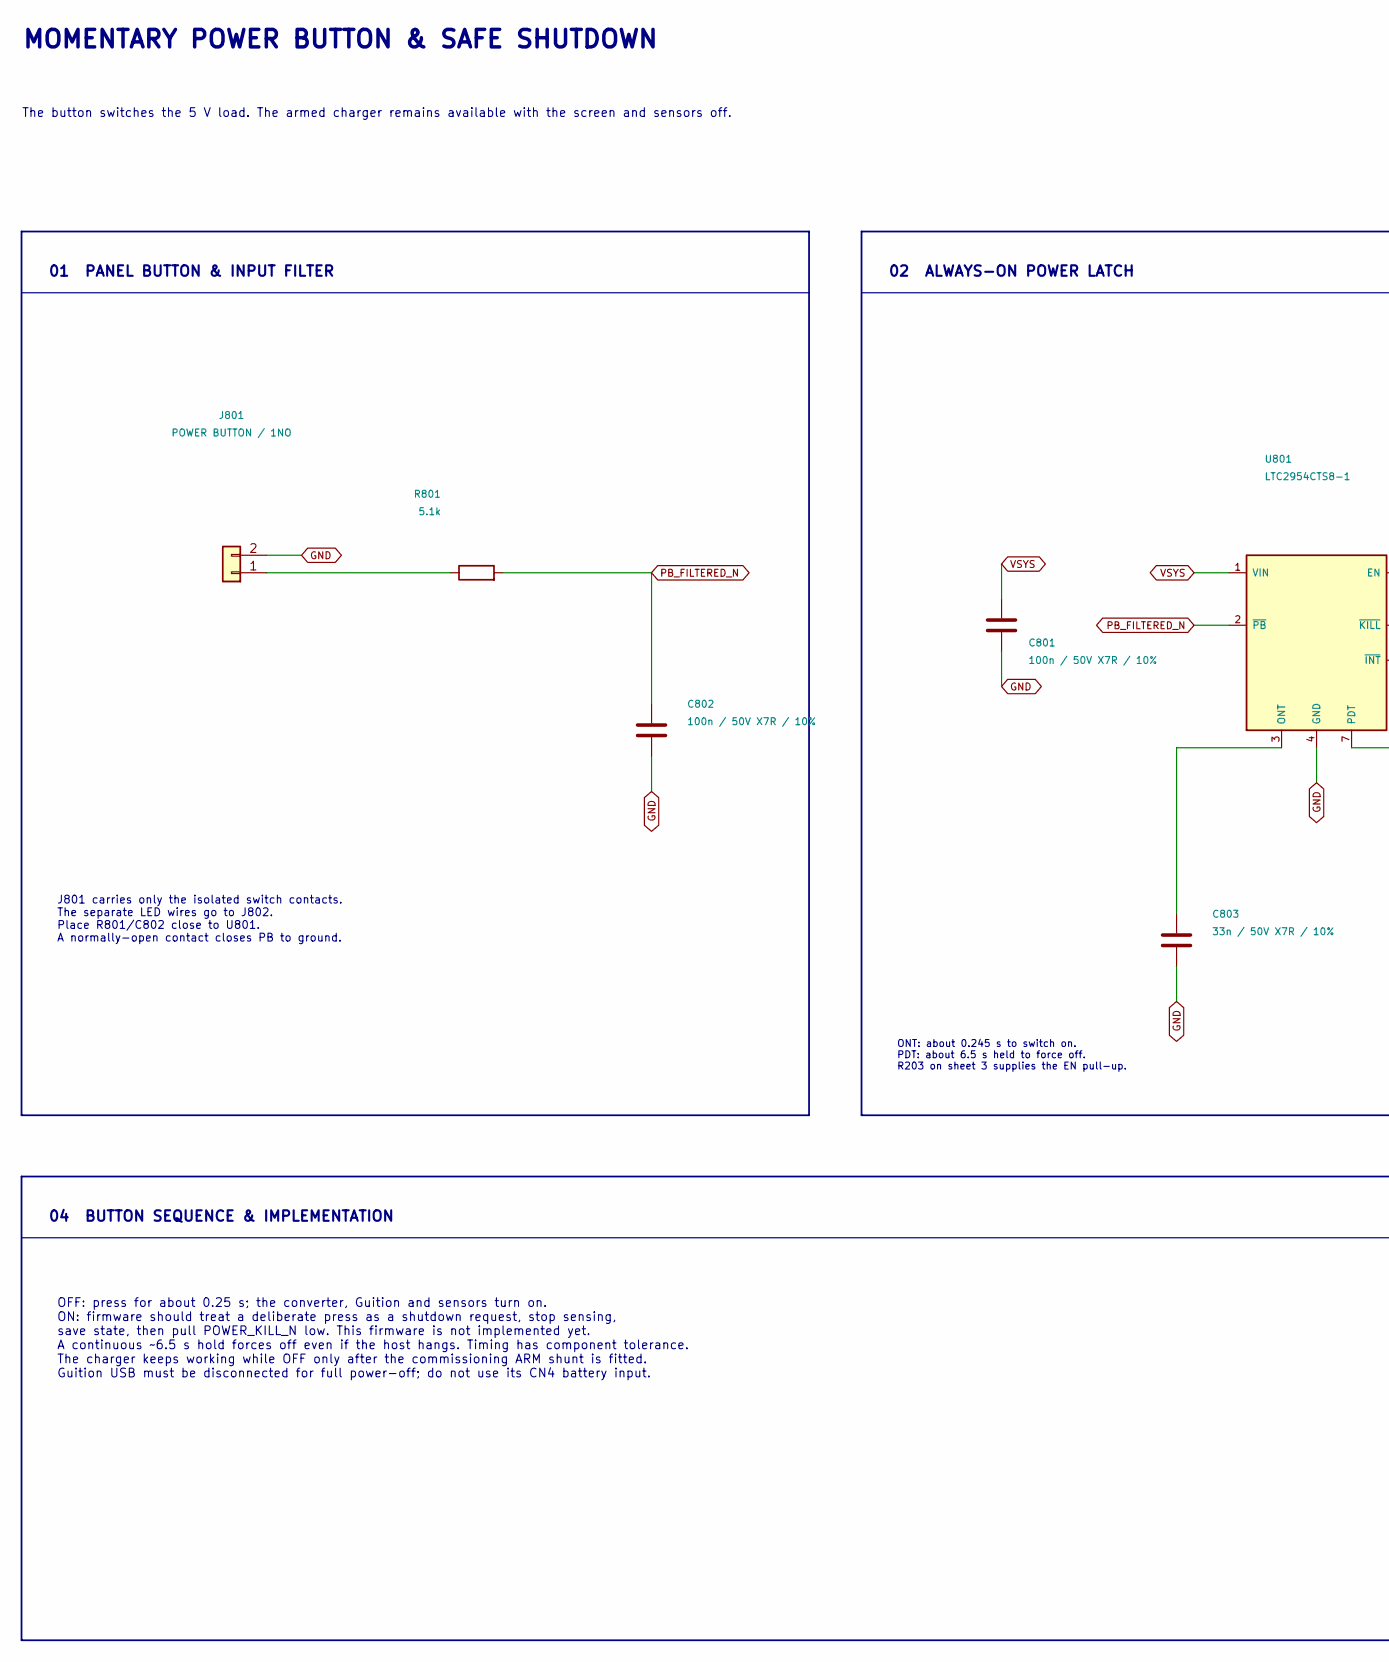
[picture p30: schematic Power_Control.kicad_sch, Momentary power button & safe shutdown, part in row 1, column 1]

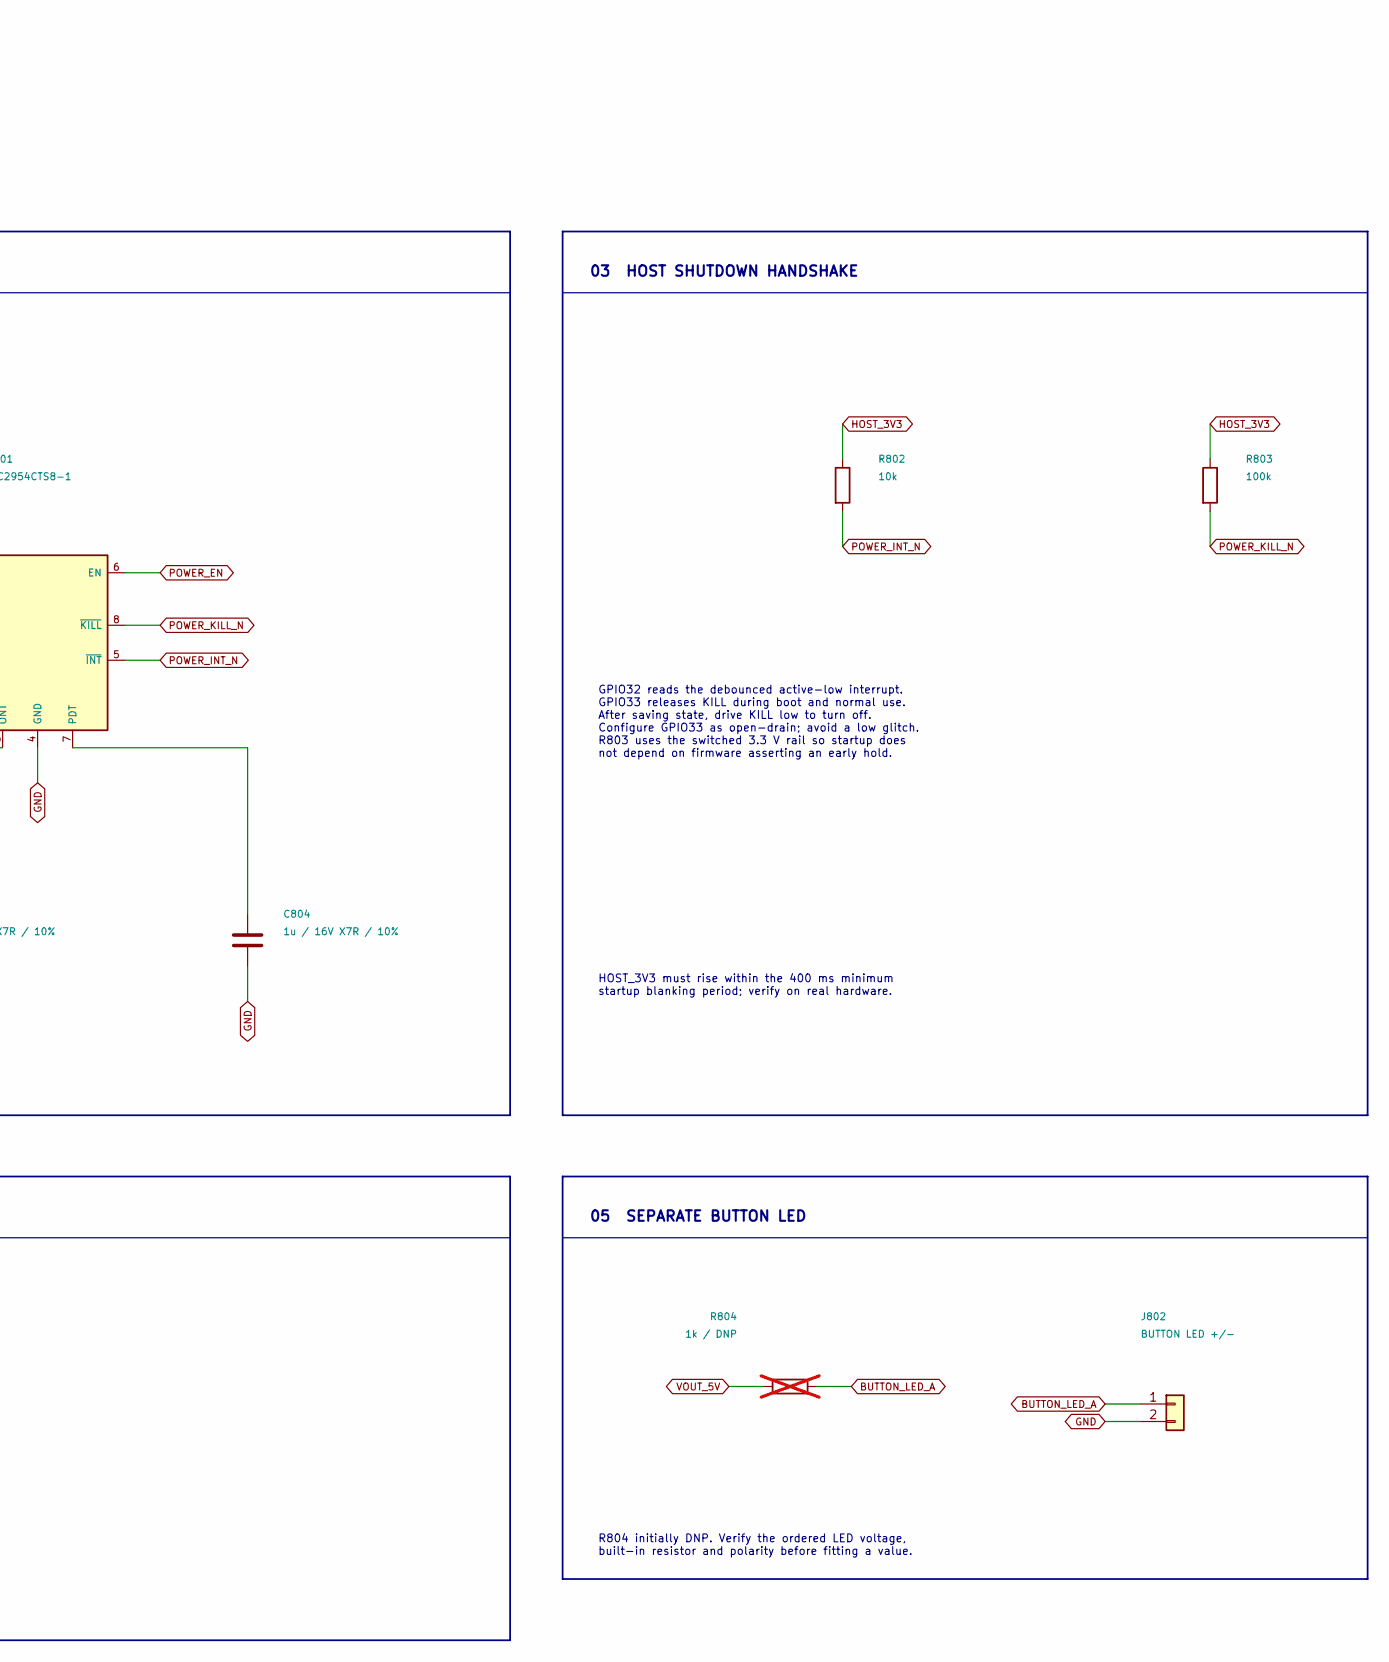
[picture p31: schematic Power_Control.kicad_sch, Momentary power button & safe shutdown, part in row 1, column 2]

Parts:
C801, C802: 100n / 50V X7R / 10%; C_0603_1608Metric; MPN C1608X7R1H104K080AA
C803: 33n / 50V X7R / 10%; C_0805_2012Metric; MPN C0805C333K5RACTU
C804: 1u / 16V X7R / 10%; C_0603_1608Metric; MPN C0603C105K4RACTU
J801: POWER BUTTON / 1NO; PinHeader_1x02_P2.54mm_Vertical; MPN M20-9990246
J802: BUTTON LED +/-; PinHeader_1x02_P2.54mm_Vertical; MPN M20-9990246
R801: 5.1k; R_0603_1608Metric; MPN RC0603FR-075K1L
R802: 10k; R_0603_1608Metric; MPN RC0603FR-0710KL
R803: 100k; R_0603_1608Metric; MPN RC0603FR-07100KL
R804: 1k / DNP; R_0603_1608Metric; MPN RC0603FR-071KL; not fitted
U801: LTC2954CTS8-1; TSOT-23-8; MPN LTC2954CTS8-1#TRMPBF

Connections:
BUTTON_LED_A: J802.1, R804.2
GND: C801.2, C802.2, C803.2, C804.2, J801.2, J802.2, U801.4 (GND); also elsewhere on the board
HOST_3V3: R802.1, R803.1; also elsewhere on the board
unnamed: J801.1, R801.1
unnamed: C803.1, U801.3 (ONT)
unnamed: C804.1, U801.7 (PDT)
PB_FILTERED_N: C802.1, R801.2, U801.2 (~PB)
POWER_EN: U801.6 (EN); also elsewhere on the board
POWER_INT_N: R802.2, U801.5 (~INT); also elsewhere on the board
POWER_KILL_N: R803.2, U801.8 (~KILL); also elsewhere on the board
VOUT_5V: R804.1; also elsewhere on the board
VSYS: C801.1, U801.1 (VIN); also elsewhere on the board

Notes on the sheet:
02 ALWAYS-ON POWER LATCH
01 PANEL BUTTON & INPUT FILTER
The button switches the 5 V load. The armed charger remains available with the screen and sensors off.
04 BUTTON SEQUENCE & IMPLEMENTATION
J801 carries only the isolated switch contacts. The separate LED wires go to J802. Place R801/C802 close to U801. A normally-open contact closes PB to ground.
05 SEPARATE BUTTON LED
MOMENTARY POWER BUTTON & SAFE SHUTDOWN
GPIO32 reads the debounced active-low interrupt. GPIO33 releases KILL during boot and normal use. After saving state, drive KILL low to turn off. Configure GPIO33 as open-drain; avoid a low glitch. R803 uses the switched 3.3 V rail so startup does not depend on firmware asserting an early hold.
HOST_3V3 must rise within the 400 ms minimum startup blanking period; verify on real hardware.
03 HOST SHUTDOWN HANDSHAKE
OFF: press for about 0.25 s; the converter, Guition and sensors turn on. ON: firmware should treat a deliberate press as a shutdown request, stop sensing, save state, then pull POWER_KILL_N low. This firmware is not implemented yet. A continuous ~6.5 s hold forces off even if the host hangs. Timing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
R804 initially DNP. Verify the ordered LED voltage, built-in resistor and polarity before fitting a value.
ONT: about 0.245 s to switch on. PDT: about 6.5 s held to force off. R203 on sheet 3 supplies the EN pull-up.

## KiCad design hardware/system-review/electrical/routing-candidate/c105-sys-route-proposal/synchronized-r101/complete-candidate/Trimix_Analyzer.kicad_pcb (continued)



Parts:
C601: 1u / 25V X7R / 10%; C_0805_2012Metric; MPN C2012X7R1E105K125AB
J601: BME280 harness; JST_XH_B4B-XH-A_1x04_P2.50mm_Vertical; MPN B4B-XH-A(LF)(SN)
Q601, Q602: BSS138; SOT-23; MPN BSS138-7-F
R601: 0R / fit: 3.3 V; R_0603_1608Metric; MPN RC0603JR-070RL
R602: 0R / DNP: 5 V option; R_0603_1608Metric; MPN RC0603JR-070RL; not fitted
R603, R604: 4.7k / DNP; R_0603_1608Metric; MPN RC0603FR-074K7L; not fitted
U601: GYBMEP / BME280-5V

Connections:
BME_SCL: J601.3 (SCL), Q601.3 (D), R603.2, U601.3 (SCL)
BME_SDA: J601.4 (SDA), Q602.3 (D), R604.2, U601.4 (SDA)
BME_VIN: C601.1, J601.1 (VIN), R601.2, R602.2, R603.1, R604.1, U601.1 (VIN)
GND: C601.2, J601.2 (GND), U601.2 (GND); also elsewhere on the board
HOST_3V3: Q601.1 (G), Q602.1 (G), R601.1; also elsewhere on the board
I2C_SCL: Q601.2 (S); also elsewhere on the board
I2C_SDA: Q602.2 (S); also elsewhere on the board
VOUT_5V: R602.1; also elsewhere on the board

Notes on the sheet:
02 I2C LEVEL INTERFACE
GYBMEP module in the vented gas chamber. Four-wire harness, maximum 30 cm; dedicated sensor I2C at 100 kHz.
03 PCB HARNESS CONNECTION
05 REMOTE MODULE IN THE CHAMBER
Main PCB: JST-XH, 2.50 mm, 4 positions. Wire to the module labels, not its board colour. VIN / GND / SCL / SDA, as photographed. Use strain relief at both cable ends.
Fit only R601 initially. Never fit both links. R602 requires a verified 5 V VIN module. Check the module regulator output and pull-ups before choosing an alternate supply.
U601 is off-board; only J601 is mounted on the main PCB. Keep the sensor away from the MD62 heater and regulator. Use a regulated, vented chamber near atmospheric pressure. Allow gas contact with the sensor opening; prevent condensation. This chamber sensor does not replace the battery thermistor.
1. Read chip ID register 0xD0: BME280 must return 0x60. BMP280 does not measure humidity. Probe 0x76 and 0x77. 2. Verify the actual module VDD / VDDIO and pull-up rail. Chip limits: VDD 1.71-3.6 V; VDDIO 1.2-3.6 V. The product photograph does not prove the fitted regulator. 3. R603/R604 are unpopul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
WIRED HUMIDITY, TEMPERATURE & PRESSURE
04 COMMISSIONING & SIGNAL INTEGRITY
01 MODULE POWER SELECTION

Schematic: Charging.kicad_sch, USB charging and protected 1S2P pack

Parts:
C101: 1u / 16V X7R / 10%; C_0603_1608Metric; MPN C0603C105K4RACTU
C102, C104, C105: 22u / 16V X7R / 20%; C_1210_3225Metric; MPN C3225X7R1C226M250AC
C103: 47n / 50V X7R / 10%; C_0805_2012Metric; MPN C0805C473K5RACTU
C106, C107: 22u / 25V X5R / 20%; C_1206_3216Metric; MPN C3216X5R1E226M160AB
C108: 4.7u / 16V X5R / 10%; C_0603_1608Metric; MPN C1608X5R1C475K080AC
J101: USB HARNESS: 5V/GND/CC1/CC2/D+/D-; USB_Harness_6P_P1.8mm
J102: PACK PIGTAIL; Battery_Pigtail_2x22AWG_P4.2_D1.00_Pad1.85
J103: PACK NTC: 103AT-2; PinHeader_1x02_P2.54mm_Vertical; MPN M20-9990246
J104: ARM: OPEN; PinHeader_1x02_P2.54mm_Vertical; MPN M20-9990246
L101: 1u / 74437349010; L_Wurth_74437349010_7050; MPN 74437349010
Q101: 2N7002; SOT-23; MPN 2N7002-7-F
R101: 5.23k 1%; R_0603_1608Metric; MPN RC0603FR-075K23L
R102: 30.1k 1%; R_0603_1608Metric; MPN RC0603FR-0730K1L
R103: 300R / 1% / supported ILIM range; R_0603_1608Metric; MPN RC0603FR-07300RL
R104, R105: 100k; R_0603_1608Metric; MPN RC0603FR-07100KL
R107: 10k; R_0603_1608Metric; MPN RC0603FR-0710KL
TP1013: CHG_STAT_N; TestPoint_Pad_D0.8mm
TP1014: QON SERVICE; TestPoint_Pad_D0.8mm
U101: BQ25895RTWR; TI_RTW24_4x4_ThermalVias_ServicePad; MPN BQ25895RTWR

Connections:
/01 CHARGING + BATTERY/BQ_BTST: C103.2, U101.21 (BTST)
/01 CHARGING + BATTERY/BQ_PMID: C102.1, U101.23 (PMID)
/01 CHARGING + BATTERY/BQ_QON_N: TP1014.1, U101.12 (~QON)
/01 CHARGING + BATTERY/BQ_REGN: C107.1, R101.1, U101.22 (REGN)
/01 CHARGING + BATTERY/BQ_SW: C103.1, L101.1, U101.19 (SW), U101.20 (SW)
/01 CHARGING + BATTERY/CHG_CE_N: Q101.3 (D), R104.2, U101.9 (~CE)
/01 CHARGING + BATTERY/CHG_STAT_N: TP1013.1, U101.4 (STAT)
/01 CHARGING + BATTERY/PACK_TS: J103.1, R101.2, R102.1, U101.11 (TS)
BQ_ILIM: R103.1, U101.10 (ILIM)
CHARGE_ARM: J104.2 (B), Q101.1 (G), R105.1
CHG_INT_N: R107.2, U101.7 (~INT); also elsewhere on the board
GND: C101.2, C102.2, C104.2, C105.2, C106.2, C107.2, C108.2, J101.2, J102.2, J103.2, Q101.2 (S), R102.2, R103.2, R105.2, U101.8 (OTG), U101.17 (PGND), U101.18 (PGND), U101.25 (PGND); also elsewhere on the board
HOST_3V3: R107.1; also elsewhere on the board
I2C_SCL: U101.5 (SCL); also elsewhere on the board
I2C_SDA: U101.6 (SDA); also elsewhere on the board
PACK_P: C106.1, J102.1, U101.13 (BAT), U101.14 (BAT); also elsewhere on the board
USB_5V: J101.1; also elsewhere on the board
USB_CC1: J101.3; also elsewhere on the board
USB_CC2: J101.4; also elsewhere on the board
USB_CHG_5V: C101.1, U101.1 (VBUS); also elsewhere on the board
USB_D_M: J101.6; also elsewhere on the board
USB_D_P: J101.5; also elsewhere on the board
VSYS: C104.1, C105.1, C108.1, J104.1 (A), L101.2, R104.1, U101.15 (SYS), U101.16 (SYS); also elsewhere on the board

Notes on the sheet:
05 COMMISSIONING ARM & SERVICE WAKE
C108 supplements the retained C104/C105 SYS bulk. TP1013 exposes charger STAT on the board rear. R107 pulls charger/permission feedback up to 3.3 V.
Follow the top row from USB input to charger and battery. The lower row controls and monitors charging.
02 CHARGER & POWER PATH
Charging & protected battery
01 USB INPUT
03 PROTECTED BATTERY
TRIMIX / ANALYZER ELECTRONICS / SHEET 2
Matching labels connect electrically. VSYS also supplies the always-on pushbutton controller. BQ25895 I2C address = 0x6A. If firmware writes settings, disable its watchdog before host shutdown. Default settings return after complete charger power loss. Keep J104 OPEN until those settings are qualif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
R101/R102 and the external 10k NTC sense temperature. Attach the NTC to the cells; connect it at J103. An open sensor inhibits charging.
J104 OPEN = charging disabled; R105 holds Q101 off. Fit the shunt only after cell/USB/NTC validation. Armed = autonomous charging with the host ON or OFF. TP1014 = local QON service access; use TP1001 GND.
04 PACK TEMPERATURE
J101 receives 5 V from the GCT USB daughterboard. J902 -> two-wire harness -> J101 (same pin numbers). See USB_Input, sheet 10; qualify before charging.
Autonomous defaults: 4.208 V, 2.048 A charge setting. Floating D+/D- selects 500 mA input; actual charge current falls to match input power. ILIM: 300R (~0.57 A). No charger firmware is implemented; defaults need review.
06 STATUS INDICATORS
J102 = PCB pigtail to the RCY/BEC cable mate. Red = protected P+; black = protected P-. FMA holder: 2 x 3400 mAh in parallel, 6800 mAh total. Verify polarity; no PCB-mounted RCY footprint is implied.
READING THIS SHEET

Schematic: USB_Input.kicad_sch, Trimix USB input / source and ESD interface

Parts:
D901: TPD1E10B06DYAR; TI_DYA0002A; MPN TPD1E10B06DYAR
J901: USB4720-03-A; USB4720_RevB; MPN USB4720-03-A
J902: TO MAIN J101 | SAME PIN NUMBERS; USB_Harness_6P_P1.8mm
U901: TPD4E05U06DQAR; TI_DQA0010B; MPN TPD4E05U06DQAR

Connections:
unnamed: D901.1 (VBUS), J901.A4 (VBUS), J901.A9 (VBUS), J901.B4 (VBUS), J901.B9 (VBUS), J902.1
unnamed: D901.2 (GND), J901.A1 (GND), J901.A12 (GND), J901.B1 (GND), J901.B12 (GND), J901.SH (SHIELD), J902.2, U901.3 (GND), U901.8 (GND)
unnamed: J901.A5 (CC1), J902.3, U901.1 (CC1), U901.10 (NC / PCB link)
unnamed: J901.A6 (D+), J901.B6 (D+), J902.5, U901.4 (D+), U901.7 (NC / PCB link)
unnamed: J901.A7 (D-), J901.B7 (D-), J902.6, U901.5 (D-), U901.6 (NC / PCB link)
unnamed: J901.B5 (CC2), J902.4, U901.2 (CC2), U901.9 (NC / PCB link)

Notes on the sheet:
TRIMIX USB INPUT | GCT + ESD + SIX-WIRE HARNESS
Dedicated 0.60 +/-0.10 mm board. Nominal 5 V input; USB-C attachment and BC1.2 detection are on the main PCB.
01 SEALED USB-C RECEPTACLE
02 FOUR-LINE + VBUS ESD PROTECTION
03 SIX-WIRE OUTPUT
04 ASSEMBLY AND QUALIFICATION
Shield and all ground contacts join GND. A6/B6 join D+; A7/B7 join D-. SBU is NC. No local Rd: TUSB320LAI on main PCB supplies Rd.
No internal links on pins6/7/9/10. PCB copper joins 1-10(CC1),2-9(CC2),4-7(D+),5-6(D-). D901 surge clamp exceeds 6 V: upstream transient coordination remains a main-system requirement.
1 = USB_5V 2 = GND 3 = CC1 4 = CC2 5 = D+ 6 = D- Do not swap CC/data wires or populate old Rd.
GCT Rev B cutout and fixed connector pose retained. No copper-edge exception rule;0.10mm GCT edge margin needs closure. Factory stencil/reflow for U901; support the port internally. Measure harness/solder height inside the 5.7 mm gap. No 9/12/20 V request; tests required for both cable orientations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

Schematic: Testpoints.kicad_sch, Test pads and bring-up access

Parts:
TP1001: GND; TestPoint_Pad_D1.0mm
TP1002: USB_5V; TestPoint_Pad_D1.0mm
TP1003: PACK_P; TestPoint_Pad_D1.0mm
TP1004: VSYS; TestPoint_Pad_D1.0mm
TP1005: VOUT_5V; TestPoint_Pad_D1.0mm
TP1006: HOST_3V3; TestPoint_Pad_D1.0mm
TP1007: POWER_EN; TestPoint_Pad_D1.0mm
TP1008: I2C_SCL; TestPoint_Pad_D1.0mm
TP1009: I2C_SDA; TestPoint_Pad_D1.0mm
TP1010: HE_3V0; TestPoint_Pad_D1.0mm
TP1011: HE_SENSE; TestPoint_Pad_D1.0mm
TP1012: O2_VMID; TestPoint_Pad_D1.0mm

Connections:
GND: TP1001.1 (1_1); also elsewhere on the board
HE_3V0: TP1010.1 (1_1); also elsewhere on the board
HE_SENSE: TP1011.1 (1_1); also elsewhere on the board
HOST_3V3: TP1006.1 (1_1); also elsewhere on the board
I2C_SCL: TP1008.1 (1_1); also elsewhere on the board
I2C_SDA: TP1009.1 (1_1); also elsewhere on the board
O2_VMID: TP1012.1 (1_1); also elsewhere on the board
PACK_P: TP1003.1 (1_1); also elsewhere on the board
POWER_EN: TP1007.1 (1_1); also elsewhere on the board
USB_5V: TP1002.1 (1_1); also elsewhere on the board
VOUT_5V: TP1005.1 (1_1); also elsewhere on the board
VSYS: TP1004.1 (1_1); also elsewhere on the board

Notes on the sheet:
TRIMIX / TEST PADS AND BRING-UP ACCESS
Twelve bare 1.0 mm copper pads. Matching global labels connect to the existing circuit pages.
01 BATTERY AND USB
02 HOST POWER AND CONTROL
03 BUS AND SENSOR SIGNALS
PROBE ACCESS
Place pads where a probe can reach them after opening the rear cover. Label each pad on silkscreen.
Use TP1001 as the circuit ground reference. HE_SENSE and O2_VMID require a high-impedance probe.
Do not bridge adjacent pads. Keep the charge-arm shunt open during initial power checks.
Verify pad locations, clearances and physical test access on the PCB; this page adds no circuit bias or switches.

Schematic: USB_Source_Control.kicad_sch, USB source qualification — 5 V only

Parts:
C110, C111, C112, C113: 100n / 50V X7R / 10%; C_0603_1608Metric; MPN C1608X7R1H104K080AA
Q110, Q111: DMN2056U-7; SOT-23; MPN DMN2056U-7
R110: 887k / 1%; R_0603_1608Metric; MPN RC0603FR-07887KL
R111: 33k / 1%; R_0603_1608Metric; MPN RC0603FR-0733KL
R112, R115: 10k / 1%; R_0603_1608Metric; MPN RC0603FR-0710KL
R113: 97.6k / 0.1%; R_0603_1608Metric; MPN RT0603BRD0797K6L
R114: 10k / 0.1%; R_0603_1608Metric; MPN RT0603BRD0710KL
R116: 1k / 0.1%; R_0603_1608Metric; MPN RT0603BRD071KL
R117, R118: 100k / 1%; R_0603_1608Metric; MPN RC0603FR-07100KL
U110: TUSB320LAIRWBR; Texas_X2QFN-12_1.6x1.6mm_P0.4mm; MPN TUSB320LAIRWBR
U111: PI3USB9201ZTAEX; PI3USB9201_UQFN2020_12_TypeC; MPN PI3USB9201ZTAEX
U112: SN74AUP1G74DCUR; VSSOP-8_2.3x2mm_P0.5mm; MPN SN74AUP1G74DCUR
U113: TPS3808G01DBVR; SOT-23-6; MPN TPS3808G01DBVR

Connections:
GND: C110.2, C111.2, C112.2, C113.2, Q111.2 (S), R114.2, R117.2, R118.2, U110.3 (PORT), U110.5 (ADDR), U110.10 (GND), U110.11 (EN_N), U111.9 (GND), U111.10 (ADDR), U111.11 (ENB), U112.4 (GND), U113.2 (GND); also elsewhere on the board
HOST_3V3: C110.1, C111.1, C112.1, C113.1, R111.1, R112.1, R115.1, U110.12 (VDD), U111.12 (VDD), U112.2 (D), U112.7 (PRE_N), U112.8 (VCC), U113.6 (VDD); also elsewhere on the board
I2C_SCL: U110.8 (SCL), U111.3 (SCL); also elsewhere on the board
I2C_SDA: U110.7 (SDA), U111.4 (SDA); also elsewhere on the board
USB_5V: R110.1; also elsewhere on the board
USB_BC_INT_N: R112.2, U111.5 (INTB)
USB_CC1: U110.1 (CC1); also elsewhere on the board
USB_CC2: U110.2 (CC2); also elsewhere on the board
USB_CC_INT_N: R111.2, U110.6 (INT_N), U113.3 (MR); also elsewhere on the board
USB_D_M: U111.7 (D-); also elsewhere on the board
USB_D_P: U111.8 (D+); also elsewhere on the board
USB_ILIM_AUTH: Q111.1 (G), R117.1, U112.1 (CLK); also elsewhere on the board
USB_ILIM_BRANCH: Q110.3 (D), R116.2
USB_ILIM_SERIES: Q110.2 (S), Q111.3 (D)
USB_LIMIT_SET: R116.1; also elsewhere on the board
USB_OVP_5V: R113.1; also elsewhere on the board
USB_PERMISSION_CLR_N: R115.2, U112.6 (CLR_N), U113.1 (RESET)
USB_PERMISSION_Q: Q110.1 (G), R118.1, U112.5 (Q)
USB_PERMISSION_Q_N: U112.3 (Q_N); also elsewhere on the board
USB_VBUS_DET: R110.2, U110.4 (VBUS_DET)
USB_VBUS_SENSE: R113.2, R114.1, U113.5 (SENSE)

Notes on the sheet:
USB SOURCE QUALIFICATION — 5 V ONLY
100 mA hardware default. Higher input permission requires a qualified source and a fresh host authorization edge.
01 USB-C SINK / INTERNAL Rd / I2C 0x47
R901/R902 on the USB board are DNP: U110 supplies both Rd terminations. Unpowered CC pins retain dead-battery Rd. PORT/ADDR/EN_N are hard-grounded.
02 USB-A / BC1.2 DETECTOR / I2C 0x5F
Client mode only. D+/D- never connect to the BQ25895. No PD or HVDCP. Read-and-clear BC status only while host permission is LOW. No USB data path.
03 INDEPENDENT VBUS LOSS + CC RESET + STARTUP
TPS3808 is powered by HOST_3V3, separately senses USB VBUS. Nominal falling threshold 4.358 V; corner threshold calculation in review. CT open: release delay 12–28 ms. Wait at least 30 ms after CC IRQ clear. Loss/CC change forces Q low even if the host GPIO remains stuck high. Power-up RESET is ass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
04 FRESH AUTHORIZATION EDGE / HARDWARE CURRENT CEILING
GPIO50 / J301.11: LOW selects nominal50mA; a qualified rising edge authorizes. U114 on sheet13 provides the input limit. R116 switches its parallel1k branch. Both FETs must be ON. A CC/VBUS reset requires a new host LOW→HIGH. BQ current register must still match the valid source budget. CHARGE ARM 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

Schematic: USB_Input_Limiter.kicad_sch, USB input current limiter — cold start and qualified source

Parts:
C114: 4.7u / 25V X7R / 10%; C_1206_3216Metric; MPN C3216X7R1E475K160AC
R119: 19.2k / 0.1%; R_0603_1608Metric; MPN RT0603BRD0719K2L
R120: 10k / 1%; R_0603_1608Metric; MPN RC0603FR-0710KL
U114: TPS22950CQDDCRQ1; TI_DDC0006A; MPN TPS22950CQDDCRQ1

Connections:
GND: C114.2, R119.2, U114.3 (GND); also elsewhere on the board
HOST_3V3: R120.1; also elsewhere on the board
USB_CHG_5V: U114.5 (VOUT); also elsewhere on the board
USB_LIMIT_FAULT_N: R120.2, U114.6 (FLT)
USB_LIMIT_SET: R119.1, U114.4 (ILIM); also elsewhere on the board
USB_OVP_5V: C114.1, U114.1 (ON), U114.2 (VIN); also elsewhere on the board

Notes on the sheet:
USB INPUT CURRENT LIMITER — COLD START AND QUALIFIED SOURCE
Engineering draft: default50mA nominal; dynamic overshoot, startup and combined corners require bench verification.
01 ALWAYS-AVAILABLE LOW-CURRENT INPUT
R119 stays fitted. R116/Q110/Q111 on sheet12 add a parallel1k branch only after qualification. BQ25895 input capacitor C101 is downstream. BQ ILIM R103 is fixed300R; D+/D- stay NC. TPS22950CQDDCRQ1 is the qualified50mA leaded Q1 variant. Industrial C/L are NOT substitutes.
02 DEFAULT INPUT AND RECOVERY SEQUENCE
Default:34/50/66mA at19.2k in TI table. 0.1% resistor adds finite tolerance. No formula for guaranteed extrema is supplied. The sizeable100mA margin is an engineering assessment; verify complete-board input draw. Once cells and NTC are qualified, device OFF allows slow depleted-pack recovery before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
03 ASSEMBLY / SOURCE / TRANSIENT QUALIFICATION
U114:TI DDC0006A leaded6-pin package,0.95mm pitch,3.05mm maximum terminal span,1.1mm maximum height. Use TI DDC0006A lands. Only the exact Q1 part retains the50mA range; do not substitute industrial TPS22950C. Input C114 is4.7uF25V close to VIN; its effective capacitance and raw-input inrush are re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

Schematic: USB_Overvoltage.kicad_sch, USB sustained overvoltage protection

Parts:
C115: 100n / 50V X7R; C_0603_1608Metric; MPN C1608X7R1H104K080AA
C116: 3.3n / 50V C0G / 5%; C_0603_1608Metric; MPN C1608C0G1H332J080AA
Q112: DMN2056U-7; SOT-23; MPN DMN2056U-7
R121: 34k / 0.1% / 10ppm; R_0603_1608Metric; MPN TNPW060334K0BYEA
R122: 649R / 0.1% / 10ppm; R_0603_1608Metric; MPN TNPW0603649RBYEA
R123: 10k / 0.1% / 10ppm; R_0603_1608Metric; MPN TNPW060310K0BYEA
R124: 21.5k / 0.1% / 25ppm; R_0603_1608Metric; MPN TNPW060321K5BEEA
R125: 10k / 0.1% / 25ppm; R_0603_1608Metric; MPN TNPW060310K0BEEA
R126: 1.65k / 0.1%; R_0603_1608Metric; MPN TNPW06031K65BEEA
R127: 10k / 1%; R_0603_1608Metric; MPN RC0603FR-0710KL
R128: 100k / 1%; R_0603_1608Metric; MPN RC0603FR-07100KL
U115: TPS259470ARPWR; TI_RPW0010A; MPN TPS259470ARPWR

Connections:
CHG_INT_N: Q112.3 (D); also elsewhere on the board
GND: C115.2, C116.2, Q112.2 (S), R123.2, R125.2, R126.2, R127.2, R128.2, U115.8 (GND); also elsewhere on the board
USB_5V: C115.1, R121.1, R124.1, U115.5 (IN); also elsewhere on the board
USB_CC_INT_N: U115.3 (AUXOFF); also elsewhere on the board
USB_OVP_5V: R127.1, U115.6 (OUT); also elsewhere on the board
USB_OVP_DVDT: C116.1, U115.7 (DVDT)
USB_OVP_ILM: R126.1, U115.9 (ILM)
USB_OVP_SET: R122.2, R123.1, U115.2 (OVLO)
USB_OVP_UPPER: R121.2, R122.1
USB_OVP_UVLO: R124.2, R125.1, U115.1 (EN/UVLO)
USB_PERMISSION_Q_N: Q112.1 (G), R128.1; also elsewhere on the board

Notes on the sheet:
USB SUSTAINED OVERVOLTAGE PROTECTION
Engineering prototype: DC cutoff corners checked; cable/ESD/fast surge survival is not established digitally.
01 RAW USB TO PROTECTED INTERSTAGE RAIL
02 FIXED THRESHOLDS / NO FIRMWARE BOOT DEPENDENCY
R121+R122 / R123:5.254–5.490V rising including defined tolerance/TCR/aging. Hysteresis may require unplug/replug. R127 discharges the protected node. AUXOFF clears permission on OVLO. FLT does NOT indicate OVLO.
03 QUALIFICATION / ASSEMBLY
C114 on sheet13 is the shared protected-node4.7uF25V1206 capacitor. U114 VIN/ON and U113 SENSE divider now use USB_OVP_5V. No duplicate interstage bulk: count all raw/interstage caps in USB inrush. AUXOFF shares CC interrupt/MR; R11133k limits pull-up load. This stage prevents sustained excessive v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
ACTUAL LATCH FEEDBACK: Q=0 forces GPIO49 LOW. Shared BQ interrupt; poll/deglitch before requalification.



Board: 4 copper layers, 30.0 x 99.0 mm, 169 parts (15 on the bottom side), 86 nets.

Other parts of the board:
H1, H2: M2 NPTH 2.30; Mechanical_M2_NPTH_2.30mm

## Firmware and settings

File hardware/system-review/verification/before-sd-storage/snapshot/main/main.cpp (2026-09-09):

#include <esp_err.h>
#include <esp_log.h>
#include <esp_ota_ops.h>
#include <esp_timer.h>
#include <stdint.h>
#include <atomic>
#include <freertos/FreeRTOS.h>
#include <freertos/task.h>
#include "services/storage_service.h"
#include "services/system_power.h"
#include "services/ota_core.h"
#include "sensors/sensor_hardware.h"

#include "ui/lvgl/lvgl_port.h"
#include "ui/screens/screen_manager.h"
#include "services/settings_service.h"
#include "services/wifi_service.h"
#include "services/c6_update_service.h"
#include "services/battery_service.h"
#include "services/analysis_history.h"
#include "services/cylinder_profiles.h"

namespace {
std::atomic<unsigned> ui_heartbeats{0};
ota::BootProbation boot_probation;
void heartbeat(lv_timer_t *) { ui_heartbeats.fetch_add(1); }
uint32_t now_ms() { return static_cast<uint32_t>(esp_timer_get_time() / 1000); }
void rollback_if_available(const char *reason) {
    ESP_LOGE("MAIN", "%s; existing storage preserved", reason);
    if (esp_ota_check_rollback_is_possible()) {
        const esp_err_t result = esp_ota_mark_app_invalid_rollback_and_reboot();
        ESP_LOGE("MAIN", "Rollback returned: %s", esp_err_to_name(result));
    } else {
        ESP_LOGE("MAIN", "No previous bootable image; retain available recovery UI and wired recovery");
    }
}
void startup_supervisor(void *) {
    while (boot_probation.pending()) {
        if (boot_probation.expire(now_ms())) {
            rollback_if_available("Update exceeded its 60-second essential startup deadline");
            break;
        }
        vTaskDelay(pdMS_TO_TICKS(250));
    }
    vTaskDelete(nullptr);
}
#if CONFIG_TRIMIX_ENABLE_WIFI
void optional_wifi_worker(void *) {
    // Hosted C6 initialization may block or fail. It must not gate local startup
    // or the OTA probation deadline. These service calls publish plain state.
    wifi_service_init();
    if (wifi_service_is_ready()) wifi_service_auto_connect();
    vTaskDelete(nullptr);
}
#endif
}
extern "C" void app_main(void) {
    const esp_partition_t *running_partition = esp_ota_get_running_partition();
    esp_ota_img_states_t ota_state;
    const bool pending = running_partition && esp_ota_get_state_partition(running_partition, &ota_state) == ESP_OK &&
                         ota_state == ESP_OTA_IMG_PENDING_VERIFY;
    boot_probation.begin(now_ms(), pending);
    if (pending && xTaskCreate(startup_supervisor, "boot_probation", 4096, nullptr, 5, nullptr) != pdPASS) {
        rollback_if_available("Could not create update startup supervisor");
        // If rollback cannot run, keep persistence read only while recovering.
        boot_probation.expire(now_ms() + ota::BootProbation::kDeadlineMs);
    }
    // One initializer owns NVS. Errors enter recovery without erasing user calibration.
    storage_init();
    // Initialize persistent, non-UI state before creating screens.
    settings_init();
    analysis_history_init();
    cylinder_profiles_init();

    // esp_lvgl_adapter owns the LVGL tick and worker task. Screen creation is
    // the only application-side LVGL work performed outside its callbacks.
    ESP_ERROR_CHECK(lvgl_port_init());
    ESP_ERROR_CHECK(lvgl_port_lock(UINT32_MAX));
    screens_init();
    lv_timer_t *health_timer = lv_timer_create(heartbeat, 250, nullptr);
    lvgl_port_unlock();
    const bool power_started = system_power_start();

    // Start asynchronous services only after the UI exists. Their callbacks
    // publish plain state; they never call LVGL directly.
#if CONFIG_TRIMIX_ENABLE_WIFI
    if (xTaskCreate(optional_wifi_worker, "wifi_start", 8192, nullptr, 3, nullptr) != pdPASS)
        ESP_LOGE("MAIN", "Wi-Fi startup task unavailable; local analyzer remains available");
#elif CONFIG_TRIMIX_UPDATE_C6_ON_BOOT
    c6_update_service_run();
#endif
    battery_service_init();
    battery_start_monitoring();
#if !CONFIG_TRIMIX_ENABLE_WIFI
    ESP_LOGW("MAIN", "Wi-Fi is disabled in this recovery build");
#endif

    // Require observed UI progress and a responsive worker, not connected optional
    // sensors, Wi-Fi association, or completed thermal warm-up. This is bounded.
    bool healthy = false;
    for (unsigned attempt = 0; attempt < 80; ++attempt) {
        healthy = ota::boot_healthy(ui_heartbeats.load(), power_started && system_power_ready() && sensor_hardware_service_healthy(), storage_ready());
        if (healthy) break;
        vTaskDelay(pdMS_TO_TICKS(250));
    }
    if (lvgl_port_lock(1000) == ESP_OK) {
        if (health_timer) lv_timer_delete(health_timer);
        lvgl_port_unlock();
    }
    // The supervisor and this path arbitrate completion atomically. A startup
    // which finished after its deadline must never accept itself later.
    const auto completion = boot_probation.complete(now_ms());
    const bool completed_in_time = completion == ota::BootProbation::Completion::Timely;
    healthy = healthy && completed_in_time;
    if (completion == ota::BootProbation::Completion::Timeout)
        rollback_if_available("Update completed after its essential startup deadline");
    if (pending && healthy) {
        if (esp_ota_mark_app_valid_cancel_rollback() == ESP_OK) {
            storage_accept_boot();
            if(storage_ready())system_power_accept_startup();
        }
    } else if (pending) {
        if (completed_in_time) rollback_if_available("Update failed bounded UI/worker/storage health check");
        // With no bootable previous image, keep this recovery UI rather than a reboot loop.
    } else if (healthy) {
        storage_accept_boot();
        if(storage_ready())system_power_accept_startup();
    }
    if (!storage_ready()) ESP_LOGE("MAIN", "%s", storage_status_message());
}

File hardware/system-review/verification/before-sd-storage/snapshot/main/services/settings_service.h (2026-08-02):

#pragma once

#include <cstdint>

#ifdef __cplusplus
extern "C" {
#endif

// Settings version - increment when adding/changing settings
#define SETTINGS_VERSION 2

// =============================================================================
// Setting Categories
// =============================================================================
typedef enum {
    SETTINGS_CAT_DEVICE,       // Device settings (display, sound, units)
    SETTINGS_CAT_SAFETY,       // Safety limits and warnings (future)
    SETTINGS_CAT_CALIBRATION,  // Sensor calibration values (future)
    SETTINGS_CAT_COUNT
} settings_category_t;

// =============================================================================
// Setting Keys
// =============================================================================
typedef enum {
    // Device settings
    SETTING_BRIGHTNESS,           // 0-100%
    SETTING_SCREEN_TIMEOUT,       // 0=never, 1=1min, 2=3min, 3=5min
    SETTING_SOUND_ENABLED,        // 0=off, 1=on
    SETTING_UNITS_DEPTH,          // 0=meters, 1=feet
    SETTING_UNITS_TEMP,           // 0=celsius, 1=fahrenheit
    SETTING_UNITS_PRESSURE,       // 0=bar, 1=psi
    SETTING_PPO2_WORKING_X100,    // e.g. 140 = 1.40 bar
    SETTING_PPO2_SECONDARY_X100,  // e.g. 160 = 1.60 bar
    SETTING_DENSITY_ADVISORY_X10, // e.g. 52 = 5.2 g/L
    SETTING_DENSITY_ALARM_X10,    // e.g. 63 = 6.3 g/L
    SETTING_CO2_ADVISORY_PPM,     // e.g. 500 ppm
    
    SETTING_COUNT
} setting_key_t;

// =============================================================================
// Unit enums for readability
// =============================================================================
typedef enum {
    UNITS_DEPTH_METERS = 0,
    UNITS_DEPTH_FEET = 1
} units_depth_t;

typedef enum {
    UNITS_TEMP_CELSIUS = 0,
    UNITS_TEMP_FAHRENHEIT = 1
} units_temp_t;

typedef enum {
    UNITS_PRESSURE_BAR = 0,
    UNITS_PRESSURE_PSI = 1
} units_pressure_t;

// =============================================================================
// Setting metadata
// =============================================================================
typedef struct {
    setting_key_t key;
    settings_category_t category;
    const char* name;           // Human-readable name
    const char* nvs_key;        // NVS storage key (max 15 chars)
    int32_t default_value;      // Default value
    int32_t min_value;          // Minimum allowed value
    int32_t max_value;          // Maximum allowed value
} setting_def_t;

// =============================================================================
// API Functions
// =============================================================================

/**
 * Initialize the settings service
 * Loads saved settings from NVS, applies defaults for missing values
 */
void settings_init(void);

/**
 * Get a setting value
 * @param key Setting key
 * @return Current value (or default if not set)
 */
int32_t settings_get(setting_key_t key);

/**
 * Set a setting value
 * @param key Setting key
 * @param value New value (will be clamped to valid range)
 * @return true if value changed, false if same or invalid
 */
bool settings_set(setting_key_t key, int32_t value);

/**
 * Reset a single setting to its default value
 * @param key Setting key
 */
void settings_reset(setting_key_t key);

/**
 * Reset all settings in a category to defaults
 * @param category Category to reset
 */
void settings_reset_category(settings_category_t category);

/**
 * Reset ALL settings to factory defaults
 */
void settings_factory_reset(void);

/**
 * Get the default value for a setting
 * @param key Setting key
 * @return Default value
 */
int32_t settings_get_default(setting_key_t key);

/**
 * Check if a setting has been modified from default
 * @param key Setting key
 * @return true if different from default
 */
bool settings_is_modified(setting_key_t key);

/**
 * Get setting definition (metadata)
 * @param key Setting key
 * @return Pointer to setting definition, or nullptr if invalid
 */
const setting_def_t* settings_get_def(setting_key_t key);

/**
 * Get category name
 * @param category Category enum
 * @return Human-readable category name
 */
const char* settings_get_category_name(settings_category_t category);

#ifdef __cplusplus
}
#endif

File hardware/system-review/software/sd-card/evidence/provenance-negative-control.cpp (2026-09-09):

#include "sensor_hardware.h"
#include "acquisition_engine.h"
#include "system_i2c.h"
#include "hardware_contract.h"
#include "co_qualification.h"
#include "services/gas_calibration_internal.h"
#include "services/oxygen_selection_service.h"
#include "services/system_power.h"
#include "services/maintenance_service.h"
#include "services/sd_log_service.h"
#include <cmath>
#include <mutex>

#if defined(ESP_PLATFORM) && !defined(TRIMIX_SIMULATOR)
#include <driver/gpio.h>
#include <driver/uart.h>
#include <esp_log.h>
#include <esp_timer.h>
#include <freertos/FreeRTOS.h>
#include <freertos/task.h>
#include <atomic>
namespace {
constexpr gpio_num_t heater_pin=static_cast<gpio_num_t>(hardware_contract::kHeliumEnable.gpio),co_enable_pin=static_cast<gpio_num_t>(hardware_contract::kCoEnable.gpio);
constexpr uart_port_t co_uart=UART_NUM_1;
std::mutex state_lock;
sensor_readings_t cache{};
std::atomic<bool> running{false},stopping{false},heartbeat_valid{false},excitation_latched{false};
std::atomic<uint32_t> heartbeat{0};
uint32_t now_ms() { return static_cast<uint32_t>(esp_timer_get_time()/1000); }
sensor_readings_t empty() {
    sensor_readings_t r{}; r.source=SENSOR_SOURCE_HARDWARE; r.status=SENSOR_STATUS_WARMING;
    r.oxygen_percent=r.oxygen_jj_percent=r.helium_percent=r.co_ppm=r.co2_ppm=NAN;
    r.temperature_c=r.humidity_pct=r.pressure_bar=NAN;
    r.calibration_unvalidated=true; r.oxygen_configuration_required=true;
    return r;
}
class Transport : public ads122::Transport {
public:
    bool write(uint8_t addr,const uint8_t *data,size_t size) override { return system_i2c::shared().write(addr,data,size); }
    bool read(uint8_t addr,uint8_t *data,size_t size) override { return system_i2c::shared().read(addr,data,size); }
    void delay_ms(uint32_t ms) override { system_i2c::shared().delay_ms(ms); }
    uint32_t now_ms() override { return ::now_ms(); }
};
class Outputs : public gas_acquisition::Outputs {
public:
    void heater(bool enabled) override {
        std::lock_guard<std::mutex> guard(state_lock);
        gpio_set_level(heater_pin,enabled && !::stopping.load());
    }
    bool stopping() const override { return ::stopping.load(); }
};
void characterize(gas_cal_channel_t channel,const gas_raw_sample_t &r,const oxygen_selection_status_t &selection) {
    gas_cal_record_t record{}; const bool saved=gas_calibration_get_record(channel,&record);
    sd_log_raw(channel,r,selection,saved ? record.revision:0,gas_acquisition::revision_for(channel));
    // Serial capture keeps raw evidence available before any gas-fit validation.
    // Payload starts CSV1; scripts/extract_characterization.py strips the log prefix.
    ESP_LOGI("GAS_RAW","CSV1,%lu,%d,%d,%lu,%lu,%ld,%.9f,%u,%.6f,%.6f,%.4f,%.4f,%.6f,%u,%lu,%lu,%u,%u",
        static_cast<unsigned long>(r.timestamp_ms),int(channel),int(selection.choice),
        static_cast<unsigned long>(r.sequence),static_cast<unsigned long>(selection.generation),
        static_cast<long>(r.adc_code),r.voltage_v,unsigned(r.gain),r.excitation_v,r.bias_v,
        r.temperature_c,r.humidity_pct,r.pressure_bar,unsigned(r.environment_valid),
        static_cast<unsigned long>(saved ? record.revision:0),static_cast<unsigned long>(r.faults),
        unsigned(r.warmed),unsigned(gas_acquisition::revision_for(channel)));
}
void publish(const gas_acquisition::Frame &frame,const oxygen_selection_status_t &selection,
             const co_qualification::Result &co,const environment_monitor::Sample &env) {
    auto out=empty(); out.timestamp_ms=now_ms(); out.sequence=frame.sequence;
    out.oxygen_selection=selection.choice; out.oxygen_selection_generation=selection.generation;
    out.oxygen_configuration_required=!selection.configured;
    out.oxygen_calibration_required=selection.calibration_required;
    out.co_valid=co.valid; out.co_ppm=co.valid ? co.ppm:NAN;
    out.environment_valid=env.valid;
    if (env.valid) { out.temperature_c=env.temperature_c; out.humidity_pct=env.humidity_percent; out.pressure_bar=env.pressure_bar; }
    out.status=selection.configured ? SENSOR_STATUS_STABLE:SENSOR_STATUS_FAULT;
    gas_cal_channel_t selected=GAS_CAL_AO2;
    const bool configured=oxygen_selection_selected_channel(&selected);
    for (int i=0;i<GAS_CAL_CHANNEL_COUNT;++i) {
        auto channel=static_cast<gas_cal_channel_t>(i);
        if (channel!=GAS_CAL_HELIUM && (!configured || channel!=selected)) continue;
        gas_raw_sample_t r{};
        if (!sensor_get_raw(channel,&r) || r.faults) { out.status=SENSOR_STATUS_FAULT; continue; }
        if (!r.warmed) { if(out.status!=SENSOR_STATUS_FAULT)out.status=SENSOR_STATUS_WARMING; continue; }
        if (!r.stable) { if(out.status==SENSOR_STATUS_STABLE)out.status=SENSOR_STATUS_STABILIZING; continue; }
        double percent=NAN; uint32_t applied_revision=0;
        if (!gas_calibration_convert_snapshot(channel,r.mean_voltage_v,percent,applied_revision) || !std::isfinite(percent) || percent<0 || percent>100) {
            out.status=SENSOR_STATUS_FAULT; continue;
        }
        if (channel==GAS_CAL_HELIUM) { out.helium_percent=percent; out.helium_calibrated=true; out.helium_calibration_revision=applied_revision; }
        else {
            out.oxygen_percent=percent; out.oxygen_calibrated=true;
            gas_cal_record_t later{}; gas_calibration_get_record(channel,&later); out.oxygen_calibration_revision=later.revision;
            if (channel==GAS_CAL_JJCCR) { out.oxygen_jj_percent=percent; out.oxygen_jj_valid=true; }
        }
    }
    if (out.oxygen_calibrated && out.helium_calibrated && out.oxygen_percent+out.helium_percent>100) {
        out.status=SENSOR_STATUS_FAULT; out.oxygen_calibrated=out.helium_calibrated=false;
        out.oxygen_percent=out.helium_percent=NAN;
    }
    std::lock_guard<std::mutex> guard(state_lock); cache=out;
}
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

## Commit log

2025-07-05 o2 calibration
2025-07-05 sensor settings
2025-07-06 cleaning 🧼
2025-07-06 feat: implement Docker-based firmware updates
    - Add GitHub Actions workflow for automated releases
    - Build multi-architecture Docker images (ARM64, ARMv7)
    - Enhance UpdateManager with Docker update support
    - Add manual update script for easy updates
    - Update docker-compose.yml for better update management
    - Add update progress tracking and UI improvements
    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
2025-09-04 Convert Trimix Analyzer from Python/Kivy to ESP32/LVGL with ESP-IDF support (#20)
    * Initial plan
    * Complete ESP32 conversion with LVGL GUI and sensor interface
    * Convert ESP32 display from landscape to portrait orientation (480x800)
    * Remove all old Python project files, keep only ESP32 implementation
    * Set up PlatformIO configuration for ESP32 project
    * Remove PlatformIO configuration and restore or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
2025-09-06 settings buttons
2025-12-24 wifi and OTA
    [partitions.csv]
2025-12-29 fix: scrolling issue etc
    [main.cpp]
2025-12-29 Dev (#21)
    * cleanup
    * feat: wifi fix
    * screen bug fixed
    * number keypad
    * fix: scrolling issue etc
    [main.cpp, settings_service.h]
2026-08-02 Dev (#22)
    * feat: OTA update
    * Refactor Trimix analysis workflows
    ---------
    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
    [main.cpp, settings_service.h]
2026-08-02 Avoid redundant UI updates and reset screen timers
2026-08-20 Refine Trimix analysis workflows and interface
    [partitions.csv, partitions.esp32p4.pre3.csv]
2026-09-07 updated pcb footprint and pcb in 3d model
    [C01_gas_inlet.stl, C01_gas_inlet_no_support_baseline_petg.3mf, C01_gas_inlet_no_support_baseline_pla.3mf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]
2026-09-09 Update application implementation
    [0402-initial.kicad_pcb, 0402-raw.kicad_pcb, Amphenol_RF_142138_Drawing_Reconstruction.f3d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]
